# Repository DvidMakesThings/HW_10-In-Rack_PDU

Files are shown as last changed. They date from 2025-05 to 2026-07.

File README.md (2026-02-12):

# ENERGIS - The Managed PDU Project for 10-Inch Rack

## Overview


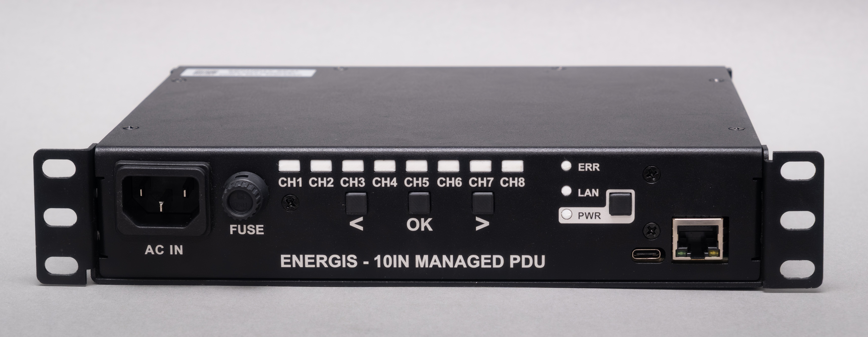
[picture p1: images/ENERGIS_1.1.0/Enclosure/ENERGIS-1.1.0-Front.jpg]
PDU 3D View


The **10-Inch Rack PDU (Power Distribution Unit)** is a modular power management system designed for efficient control and monitoring of power in a
rack-mounted environment. The project includes a Main Board and a display board to handle switching and power management.

Update 05.2025: Since lot of people said, it would be nice to have a Non-230V-Version, I started to develop
the USB-C version of ENERGIS with USB PD Source functionality: [PDNode-600 Pro](https://github.com/DvidMakesThings/HW_PDNode-600-Pro)

## ENERGIS Video Series

A new ENERGIS video series is rolling out. Part 1 is live below; Parts 2–4 will follow soon.

| Part | Title | Video |
| --- | --- | :---: |
| 1 | Overview | <a href="https://youtu.be/2Wui68LSHR0">Watch Part 1</a> |
| 2 | Hardware deep dive - The Schematics | <a href="https://youtu.be/pdoe9AGhswE">Watch Part 1</a> |
| 3 | Hardware deep dive - PCB design and Assembly | Coming soon |
| 4 | Embedded development - firmware and interfaces | Coming soon |
| 5 | Testing and validation | Coming soon |

## Progress and news

### Latest Features

| Feature | Description | Status | Note |
| --- | --- | --- | --- |
| Renamebable Channels | Channels are marked as 1–8; add label functionality |  | See: [Control page](#control-page) |
| Preset features | ENERGIS now offers 5 programmable presets to apply on output |  | See: [Settings page](#settings-page) |
| Apply-On-Startup feature  | A saved preset can be set to be auto-applied on device startup |  | See: [Settings page](#settings-page) |
| Offset Calibration | Implement off-state auto-zero for 0.75–0.77V and 0.02–0.05A offsets |  | - |
| Safety features | Software based current limit and restricion policy implemented |  | - |
| Sheet metal enclosure | Manufacturing and assembly ready. No future revision for enclosure |  | - |

### Currently working on

| Improvement | Description | Status |
| --- | --- | --- |
| Production optimization | Finalize assembly workflow and cost reduction |  |
| Extended testing | Expand automated test coverage (I²C, SPI, long-term soak tests) |  |
| Community feedback | Incorporate suggestions and adapt design for wider use cases |  |
| And even more debugging | It survived the 24h test, but you can never test enough |  |

### Development Phases (Hardware + Firmware)

| Hardware Phase | Status | Firmware Phase | Status |
| --- | --- | --- | --- |
| PCB Design for Rev1.0 | ✅ Completed | CONFIG file for HW description | ✅ Completed |
| Enclosure Design | ✅ Completed | ILI4988 TFT LCD Driver | ✅ Completed |
| Order PCB | ✅ Completed | MCP23017 Display-Board Driver | ✅ Completed |
| Prototyping and Hardware Testing | ✅ Completed | MCP23017 Relay-Board Driver | ✅ Completed |
| Implementing Rev2.0 | ✅ Completed | W5500 Ethernet Driver | ✅ Completed |
| Implementing Relay Board Rev2.1 | ✅ Completed | CAT24C512 512K EEPROM Driver | ✅ Completed |
| Initial Firmware Development | ✅ Completed | Version Control and EEPROM Data | ✅ Completed |
| Final PCB Revision | ✅ Completed | Display Functions | ✅ Completed |
| Enclosure Testing & Ventilation | ✅ Completed | System Startup Script | ✅ Completed |
| Power Monitoring | ✅ Completed | Multicore processing and RTOS | ✅ Completed |
| Production Optimization | 🔵 Planned | Pushbutton control | ✅ Completed |
| - | - | HLW8032 Power Monitor Dirver | ✅ Completed |
| - | - | Make Everything work together | ✅ Completed |
| - | - | HTML Server Implementation | ✅ Completed |
| - | - | Software debugging | ✅ Completed |
| - | - | Ethernet based firmware update | ❌ Not Possible |

---

## Specifications (EU, IEC/ENEC)

### Electrical Characteristics

* **Input:** 230 V AC, **10 A max**
* **Output Voltage:** 230 V AC
* **Total Output Current (all channels combined):** **10 A max**
* **Per-Channel Output Current:** **10 A max per active channel**, with **total combined output limited to 10 A**
* **Internal Power Supply:** 12 V, 1.5 A SMPS
* **Derived Internal Voltages:** 5 V and 3.3 V regulated from 12 V

### Relay Output Ratings

* **Common AC Trace Handling:** 16A max
* **Per-Relay Trace Rating:** 16A max
* **Relay Contact Rating:** 16A max

### Control and Driving Circuit

* **Relay Driver:** ULN2803 Darlington Array
* **Driving Current:** 33 mA per relay

## Specifications (US/Canada, UL/CSA)

### Electrical Characteristics

* **Input:** 250 V AC, **15 A max**
* **Output Voltage:** 250 V AC
* **Total Output Current (all channels combined):** **15 A max**
* **Per-Channel Output Current:** **15 A max per active channel**, with **total combined output limited to 15 A**
* **Internal Power Supply:** 12 V, 1.5 A SMPS
* **Derived Internal Voltages:** 5 V and 3.3 V regulated from 12 V

### Relay Output Ratings

* **Common AC Trace Handling:** 16 A max
* **Per-Relay Trace Rating:** 16 A max
* **Relay Contact Rating:** 16 A max

### Control and Driving Circuit

* **Relay Driver:** ULN2803 Darlington Array
* **Driving Current:** 33 mA per relay

---

## Features

- **Main Board:** Handles Ethernet communication, power conversion, and system logic. Manages AC switching with 8x 230V relays and safety
  isolation.
- **Display Board:** Headless mode, possible manual control with push buttons and real-time LED feedback
- **Ethernet Connectivity:** Uses the W5500 SPI-based Ethernet chip for remote
  control and monitoring via SNMPv1 and/or Web-UI
- **Power Measurement:** AC voltage and current sensing for monitoring.
- **Sheetmetal Enclosure:** Designed for 10-inch rack mounting with front and rear access.

--- 

## Schematics

The full schematics for each board are available:

- **[Main Board Schematics](src/PDF/ENERGIS-1.1.0_mainBoard_schematics.pdf)**
- **[Display Board Schematics](src/PDF/ENERGIS-1.1.0_displayBoard_schematics.pdf)**

---

## Hardware Stackup

<table>
  <tr>
    <td align="center">
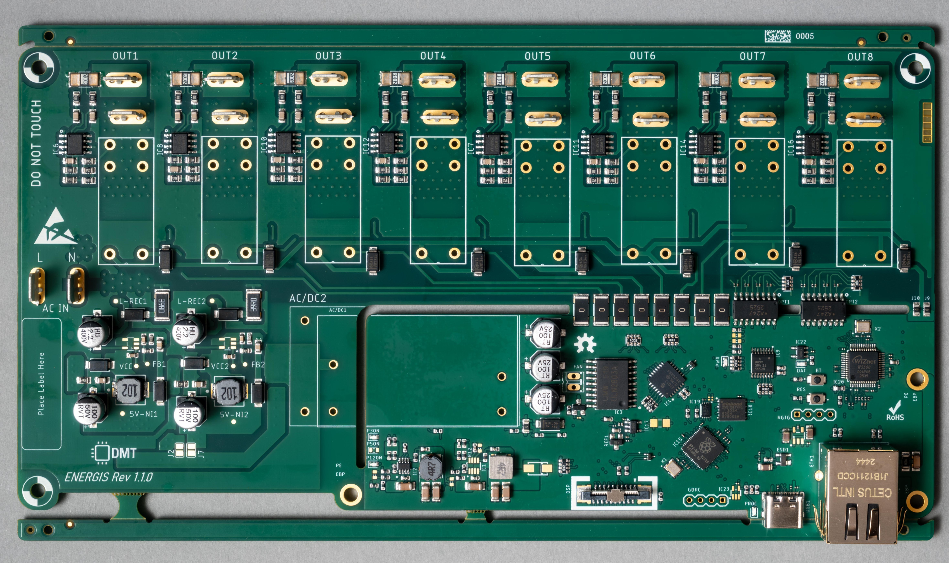
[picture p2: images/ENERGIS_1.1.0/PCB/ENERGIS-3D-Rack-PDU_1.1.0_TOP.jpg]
Main Board 3D Top View
      
      <br><b>Main Board Top</b>
    </td>
    <td align="center">
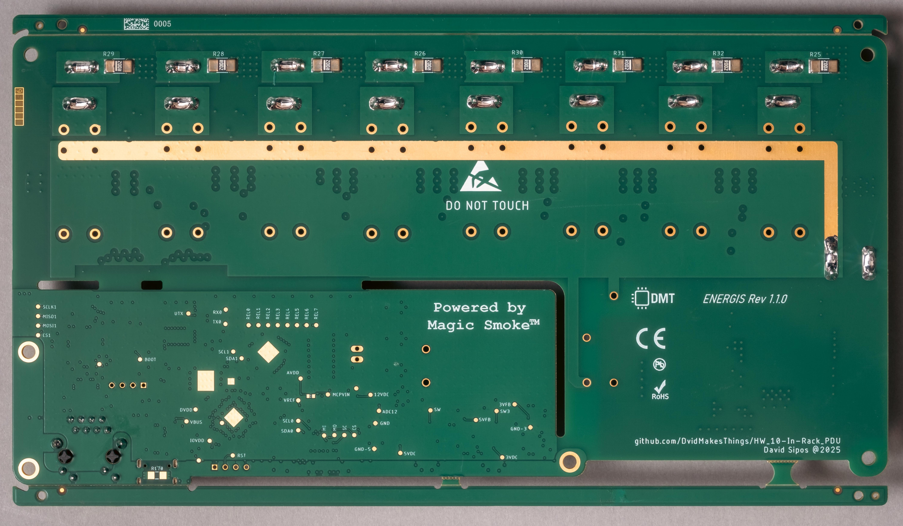
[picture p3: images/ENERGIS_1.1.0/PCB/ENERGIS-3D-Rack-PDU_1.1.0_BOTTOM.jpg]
Main Board 3D Bottom View
      
      <br><b>Main Board Bottom</b>
    </td>
  </tr>
  <tr>
    <td align="center">
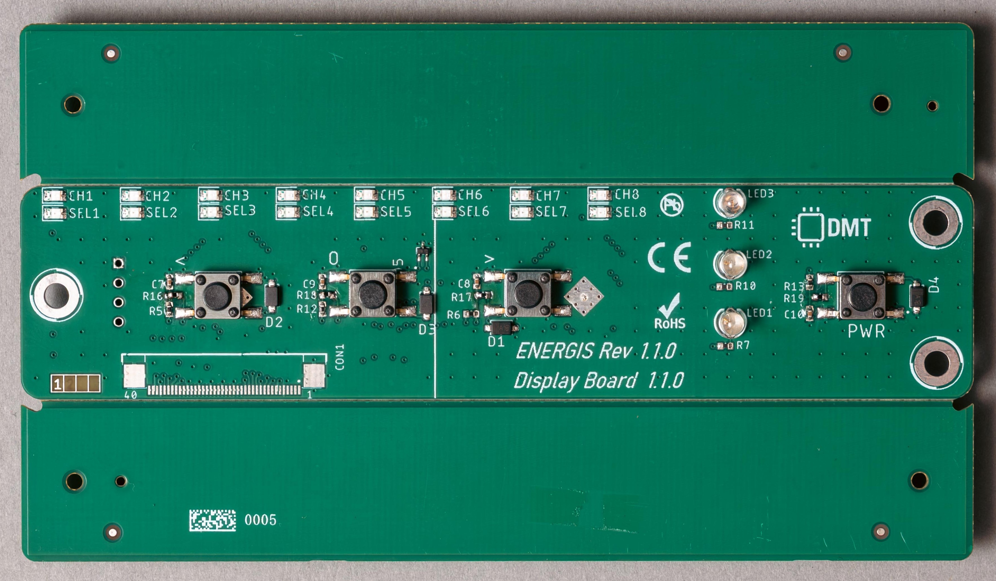
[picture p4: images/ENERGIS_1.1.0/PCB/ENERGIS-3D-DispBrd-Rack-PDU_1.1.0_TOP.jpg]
Display Board 3D Top View
      
      <br><b>Display Board Top</b>
    </td>
    <td align="center">
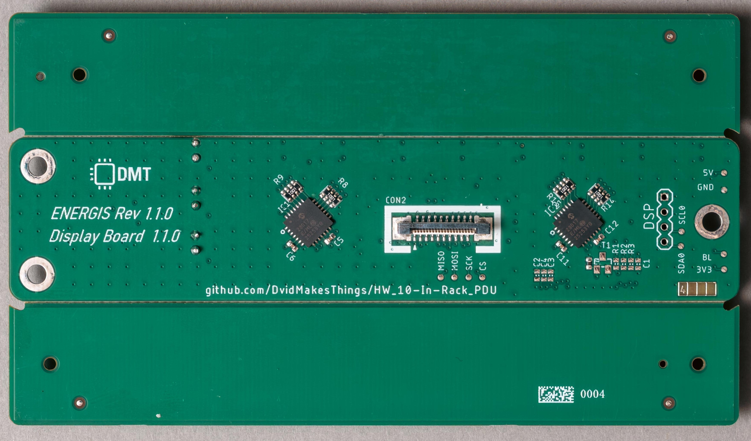
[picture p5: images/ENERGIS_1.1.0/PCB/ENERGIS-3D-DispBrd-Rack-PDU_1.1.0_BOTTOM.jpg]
Display Board 3D Bottom View
      
      <br><b>Display Board Bottom</b>
    </td>
  </tr>
  <tr>
    <td align="center">
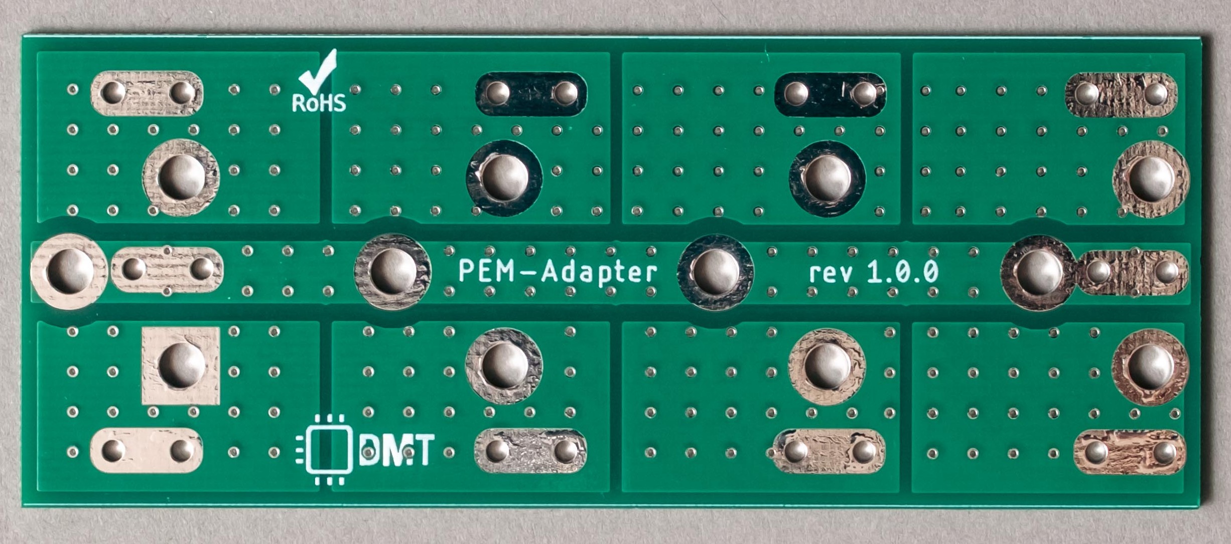
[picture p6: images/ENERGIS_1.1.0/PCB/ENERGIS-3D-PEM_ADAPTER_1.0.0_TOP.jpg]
PEM-Adapter 3D Top View
      
      <br><b>PEM Adapter</b>
    </td>
    <td align="center">
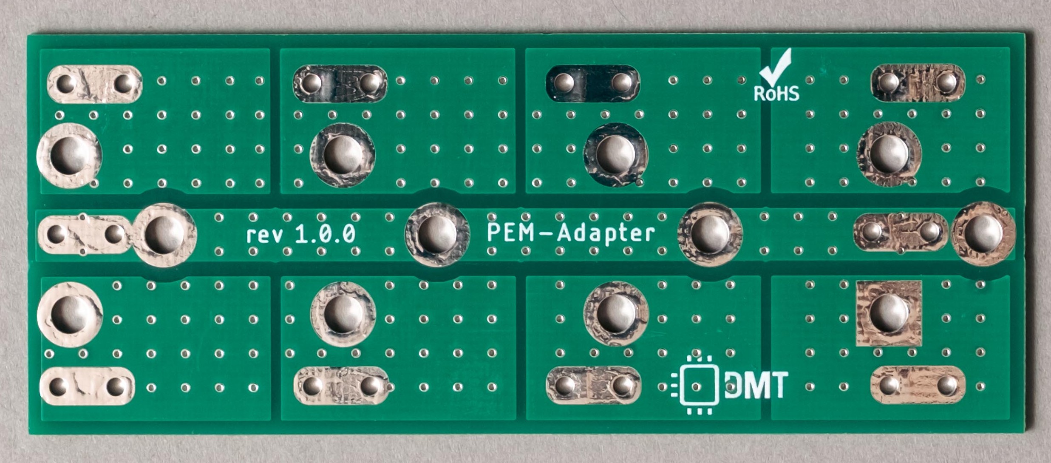
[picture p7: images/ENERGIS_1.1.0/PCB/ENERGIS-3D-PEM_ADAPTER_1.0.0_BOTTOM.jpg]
PEM-Adapter 3D Bottom View
      
      <br><b>PEM Adapter</b>
    </td>
  </tr>
</table>

## Enclosure

The **Energis** PDU enclosure is built from **Aluminum 5052 sheet metal** with a thickness of **1.5 mm**, ensuring both durability and lightweight construction. It follows a **10-inch rack form factor (1U height)** with custom mounting brackets and integrated cutouts for AC input, Ethernet, USB-C, status LEDs, and IEC outlets.

Key specifications:
* **Material:** Aluminum 5052, 1.5 mm
* **Finish:** Powder coat (matte black, process black)
* **Threads & tapped holes:** Yes (no inserts, no welding)
* **Marking:** Laser engraved front and back panel labeling
* **Design:** Precision CNC cut and bent sheet metal, matte black powder-coated for protection and aesthetics

<br></br>
<div style="display: flex; gap: 24px; justify-content: center; align-items: flex-start; margin-bottom: 24px;">
  PDU 3D View 1
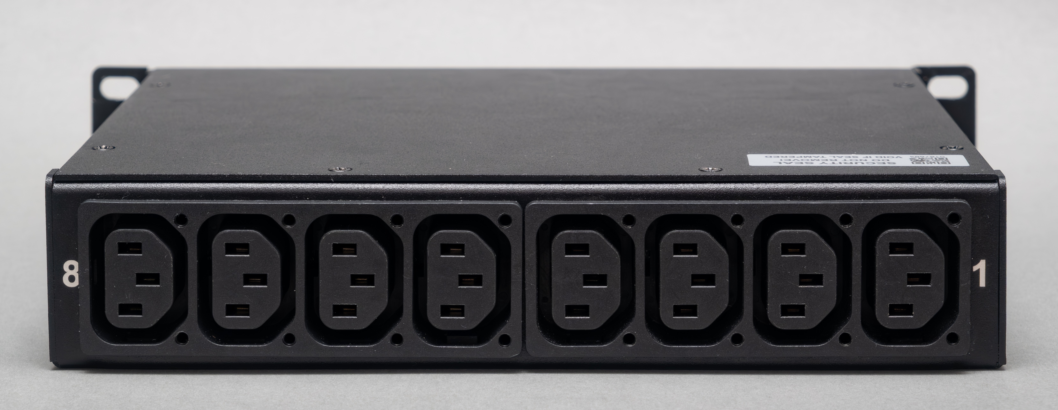
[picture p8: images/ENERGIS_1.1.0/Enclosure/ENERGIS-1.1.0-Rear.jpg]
PDU 3D View 2
  
</div>

<br></br>
Mounting options:
* **Desktop use** without brackets  
* **10-inch rack mounting** 

---

## Web UI

The ENERGIS now includes a lightweight embedded Web-UI for configuration and control.

## Control page
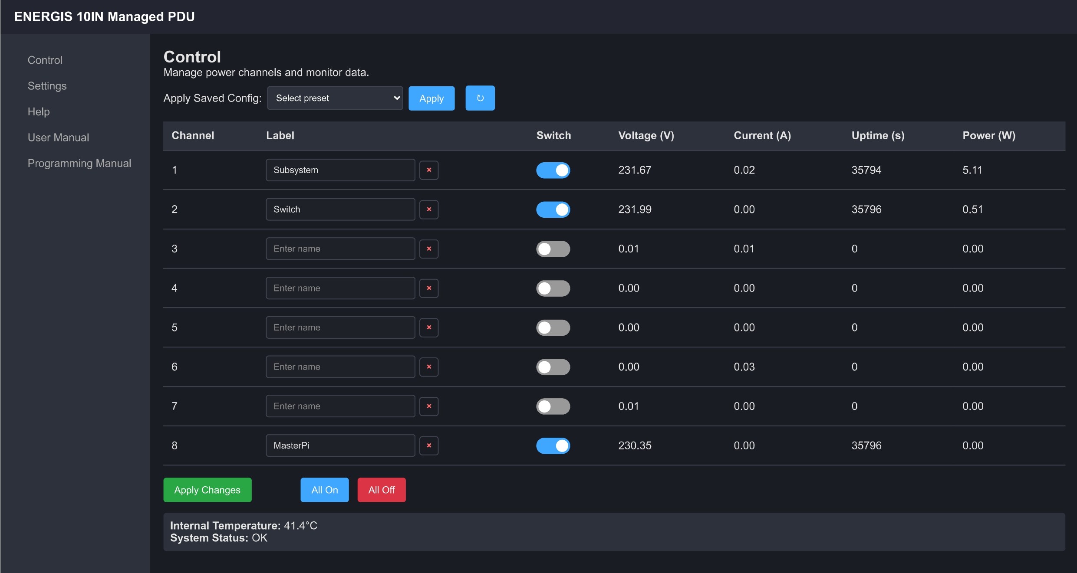
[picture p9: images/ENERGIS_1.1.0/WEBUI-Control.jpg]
Web-UI


## Settings page
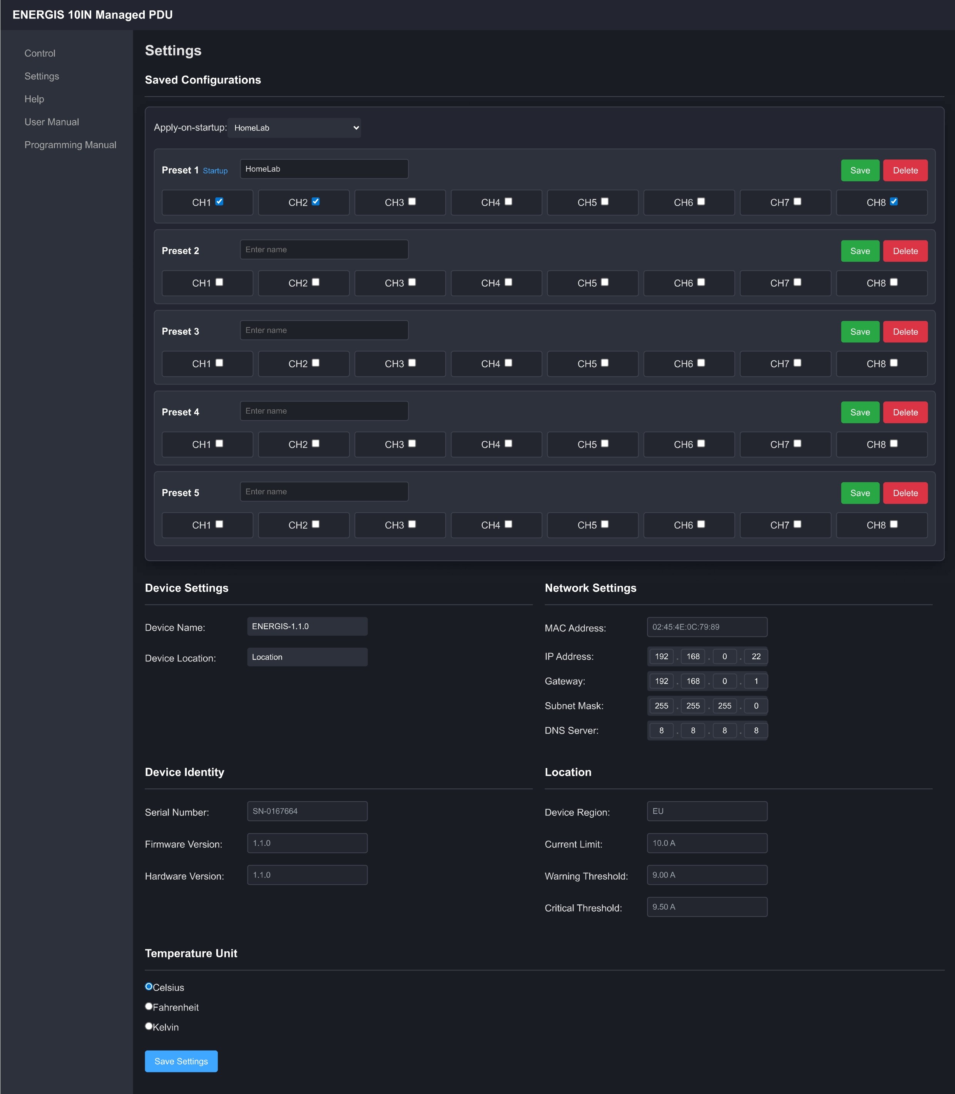
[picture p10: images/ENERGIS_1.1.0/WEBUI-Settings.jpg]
Web-UI Settings


---

## Tests

Automated hardware and firmware validation is now integrated into **ENERGIS**.  
Test reports are published through **GitHub Pages** for transparent, reproducible verification.

All tests are executed using my **Universal Test Framework (UTFW)**, a custom Python-based automation framework, developed for hardware and firmware validation.  
UTFW provides deterministic test sequencing, automated setup and teardown, structured logging, analysis, and unified HTML/XML reporting.  
The nightly regression runs every individual test together to verify overall system stability and catch integration issues early.

---

### Nightly Regression Suite
Comprehensive end-to-end system test covering:
- UART communication  
- SNMP protocol  
- Web interface (PCAP)  
- EEPROM persistence  
- Power monitoring (HLW8032)  
- ADC/thermal sanity checks  
- Relay stress switching  

**[Latest Regression Report](https://dvidmakesthings.github.io/HW_10-In-Rack_PDU/Tests/Nightly_regression/test_suite_Nightly_Tests_20251005_232014.html)**

---

### Individual Test Reports
- [Serial Communication Test Report (HTML)](https://dvidmakesthings.github.io/HW_10-In-Rack_PDU/Tests/report_tc_serial_utfw/tc_serial_utfw_report.html)
- [Network SNMP Test Report (HTML)](https://dvidmakesthings.github.io/HW_10-In-Rack_PDU/Tests/report_tc_network_snmp/tc_network_snmp_report.html)
- [Network PCAP Analysis Report (HTML)](https://dvidmakesthings.github.io/HW_10-In-Rack_PDU/Tests/report_tc_network_pcap/tc_network_pcap_report.html)
- [PCAP Capture Test Report (HTML)](https://dvidmakesthings.github.io/HW_10-In-Rack_PDU/Tests/report_tc_pcap_capture/tc_pcap_capture_report.html)
- [Power Monitoring Test Report (HLW8032) (HTML)](https://dvidmakesthings.github.io/HW_10-In-Rack_PDU/Tests/report_tc_power_hlw8032/tc_power_hlw8032_report.html)
- [EEPROM Persistence Test Report (HTML)](https://dvidmakesthings.github.io/HW_10-In-Rack_PDU/Tests/report_tc_eeprom_persistence/tc_eeprom_persistence_report.html)
- [Sanity Check Test Report (HTML)](https://dvidmakesthings.github.io/HW_10-In-Rack_PDU/Tests/report_tc_sanity_check/tc_sanity_check_report.html)
- [Relay Stress Switching Test Report (HTML)](https://dvidmakesthings.github.io/HW_10-In-Rack_PDU/Tests/report_tc_stress_switching/tc_stress_switching_report.html)

---

### Changelog:
#### Rev0.1.0:
- Initial desing

#### Rev0.2.0:
- Correct all hardware related bugs
- Display-Board Rev0.2.0: 
    - Buttons too close to each-other. Manual control is uncomfortable 
    - MCP23S17 seems like unreachable, invertory shortage everywhere. Change to MCP23017
- Controller-Board Rev0.2.0: 
    - W5500 crystal wiring bug. 
    - v1.0 connectors replaced to smaller FFC ones
- Relay-Board Rev0.2.0: 
    - Add HLW8032 for power monitoring
    - Replace Flyback converter to a cheaper - ready made AC-DC converter unit

#### Rev0.2.1:
- Relay-Board Rev0.2.1: 
    - Capacitive dropper does not have enough power to supply 8xHLW8032 - Non-Isolated  buck converter implemented
- Display-Board Rev0.2.1:
    - Planned revision without the LCD. This is the main size issue, going to do a version where the setup fits in 1U size. 
    Currently for debug purposes 1.5U is perfectly fine

#### ENERGIS 1.0.0 
- Relay-Board and Controller Board is now combined: Main Board
- Added enable functionality to the PSU
- Added high precision LDO to supply the MCU
- Additional fan is possible, but the temperature doesn't go above 36°C

#### ENERGIS 1.1.0
- Cleaned up routing both for Display- and Main board
- NEW: PEM-Adapter: Unfortunately the commercially available Power Entry Modules are using bussed topology, seems like it's
impossible to buy snap-in modules with individual L/N control. The only possibility I've found is the 3-104-370 from Schurter, but
it's a PCB-mountable version. Using a small adapter board to hook the solder joints to faston connectors seems to be the only possibility

## License
### Software Components
This project's software is licensed under the **GNU Affero General Public License v3.0 (AGPL-3.0)**.
See the [Software License](LICENSE-AGPL) file for details.

#### What AGPL-3.0 means:

- ✅ **You can** freely use, modify, and distribute this software
- ✅ **You can** use this project for personal, educational, or internal purposes
- ✅ **You can** contribute improvements back to this project

- ⚠️ **You must** share any modifications you make if you distribute the software
- ⚠️ **You must** release the source code if you run a modified version on a server that others interact with
- ⚠️ **You must** keep all copyright notices intact

- ❌ **You cannot** incorporate this code into proprietary software without sharing your source code
- ❌ **You cannot** use this project in a commercial product without either complying with AGPL or obtaining a different license

### Hardware Components
Hardware designs, schematics, and related documentation are licensed under the **Creative Commons Attribution-NonCommercial-ShareAlike 4.0 International License (CC BY-NC-SA 4.0)**. See the [Hardware License](LICENSE-CC-BY-NC-SA) file for details.

#### What CC BY-NC-SA 4.0 means:

- ✅ **You can** study, modify, and distribute the hardware designs
- ✅ **You can** create derivative works for personal, educational, or non-commercial use
- ✅ **You can** build this project for your own personal use

- ⚠️ **You must** give appropriate credit and indicate if changes were made
- ⚠️ **You must** share any modifications under the same license terms
- ⚠️ **You must** include the original license and copyright notices

- ❌ **You cannot** use the designs for commercial purposes without explicit permission
- ❌ **You cannot** manufacture and sell products based on these designs without a commercial license
- ❌ **You cannot** create closed-source derivatives for commercial purposes
- ❌ **You cannot** use the designer's trademarks without permission

### Commercial & Enterprise Use

Commercial use of this project is prohibited without obtaining a separate commercial license. If you are interested in:

- Manufacturing and selling products based on these designs
- Incorporating these designs into commercial products
- Any other commercial applications

Please contact me through any of the channels listed in the [Contact](#contact) section to discuss commercial licensing arrangements. Commercial licenses are available with reasonable terms to support ongoing development.

## Contact

For questions or feedback:
- **Email:** [dvidmakesthings@gmail.com](mailto:dvidmakesthings@gmail.com)
- **GitHub:** [DvidMakesThings](https://github.com/DvidMakesThings)

## Contributing

Contributions are welcome! As this is an early-stage project, please reach out before 
making substantial changes:

1. Fork the repository
2. Create a feature branch (`git checkout -b feature/concept`)
3. Commit your changes (`git commit -m 'Add concept'`)
4. Push to the branch (`git push origin feature/concept`)
5. Open a Pull Request with a detailed description

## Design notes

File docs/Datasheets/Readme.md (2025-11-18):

# ENERGIS - The Managed PDU Project for 10-Inch Rack - Datasheets

## Contents
This folder contains datasheets for components used in the **ENERGIS PDU** project.
Each subfolder is named after the corresponding board (Controller, Display, Relay) to maintain organization.
Datasheets are useful for verifying component specifications and understanding performance parameters.

## License
This project is licensed under the GPL-3.0 License. See the [LICENSE](LICENSE) file for details.

## Contact
For questions or feedback:
- Email: [dvidmakesthings@gmail.com](mailto:dvidmakesthings@gmail.com)
- GitHub: [DvidMakesThings](https://github.com/DvidMakesThings)

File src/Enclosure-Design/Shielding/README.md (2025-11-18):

# Shielding Design – ENERGIS

This folder contains the **mechanical shielding parts** for the ENERGIS system.  
The shields are designed in Fusion 360 (sheet-metal workflow) and exported as **DXF flat patterns** for cutting from 0.5 mm brass sheet.  

Brass was chosen over aluminum because it can be **soldered directly to PCB GND pads**, ensuring reliable low-impedance bonding.

---

## Purpose

During early testing, two main issues appeared:

1. **EMI coupling** from the 230 V relay/AC section into the digital side.  
   - Without shielding, the FPC cable and control logic were acting as antennas.  
   - Noise could be observed on I2C and button reads.

2. **ESD vulnerability** on the display board.  
   - Button presses and connector touches occasionally caused resets.  

To mitigate these issues, I've implemented **mechanical brass shields** tied to PCB GND at multiple points.
Brass is easy to solder and bending a 0.5mm thick sheet doesn't require that much force

---

## Main Board Shield

- Covers the entire digital interface, leaving only the connectors exposed
- L-shaped fence along the isolation slot between HV and digital domains.  
- Tabs solder into test pads + screw hole for both mechanical strength and ground bonding.  
- The FPC cable runs **under the shield**; only a few cm exposed.  

Main Board Shield

DXF: [MainBoard_Shielding.dxf](MainBoard_Shielding.dxf)  
PDF: [MainBoard_Shielding.pdf](MainBoard_Shielding.pdf)

---

## Display Board Shield

- Full brass cap covering the back side of the display board.  
- Exposed only where connectors and buttons are located.  

Front view:  
Display Board Shield – Front

Back view:  
Display Board Shield

DXF: [DisplayBoard_Shielding.dxf](DisplayBoard_Shielding.dxf)  
PDF: [DisplayBoard_Shielding.pdf](DisplayBoard_Shielding.pdf)

---

## Notes

- Shields are designed for **0.5 mm brass**.  
- After cutting, edges must be deburred and tabs cleaned before soldering.  
- Painting is optional for corrosion resistance — but **mask the solder tabs** to keep them conductive.  

---

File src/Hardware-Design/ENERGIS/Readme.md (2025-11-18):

# HLW8032 Upper-Bank Routing Issue — Fixed in HW 1.0.1

## Summary
On **hardware rev 1.0.0**, the measurement path for channels **5–8** is cross-routed at the optocouplers, mirroring the upper nibble. Relays/buttons are unaffected; only measurement presentation would be wrong without compensation.

## Symptom (on HW 1.0.0)
- Turning **CH5–CH8** on shows their voltage/current under the wrong rows in the UI.

| Logical Channel | Routed To (HW 1.0.0) |
|---:|:---|
| 5 | 8 |
| 6 | 7 |
| 7 | 6 |
| 8 | 5 |

## Root Cause
- PCB routing in the optocoupler stage crosses TX lines for channels 5–8.

## Software Handling
- The firmware checks board revision **at compile time** (`SW_REV == 100`) and applies a **MUX-select compensation** only for HW 1.0.0 (invert A/B when the C bit is set).
- Cache indices and UI mapping remain **identity**.
- **Result:** No user-visible issue on any build.

## Hardware Status
- **HW 1.0.1:** Routing corrected (1:1). The firmware automatically **disables** compensation on ≥1.0.1.
- **HW 1.0.0:** Fully functional due to firmware compensation.

## Verification
1. Switch on CH5…CH8 individually.  
2. Confirm the UI shows the correct channel voltage/current on both HW 1.0.0 (with compensation) and HW 1.0.1 (native).

---
**Status:** Fixed in hardware (rev 1.0.1). Software safeguard ensures no impact on users.

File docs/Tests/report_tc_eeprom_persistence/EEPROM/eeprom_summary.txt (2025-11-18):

EEPROM Parse Summary – Analyze EEPROM dump after all tests
Source lines parsed: 4096
Address span: 0x0000 – 0xFFFF (65536 bytes)
Dump (raw)   : eeprom_dump_raw.log
Dump (ascii) : eeprom_dump_ascii.log
Checks file  : eeprom_checks.json

-- Findings --
[OK] Device Serial @ 0x0000 len=15
    ASCII: SN-369366060325
[OK] FW Version @ 0x0010 len=5
    ASCII: 1.0.0
[OK] Relay Defaults (8x bytes) @ 0x0200 len=8
    HEX  : 00 00 00 00 00 00 00 00
[OK] Network Info (first 4 bytes) @ 0x0300 len=4
    HEX  : C0 A8 00 0B
[OK] Device Name @ 0x2000 len=13
    ASCII: ENERGIS-1.0.0
[OK] Device Location @ 0x2020 len=8
    ASCII: Location
[OK] Magic A55A Present @ 0xFFF0 len=16
    HEX  : FF FF FF FF FF FF FF FF FF FF FF FF FF FF 5A A5

-- Extracted --
Serial  : SN-369366060325
Firmware: 1.0.0
Name    : ENERGIS-1.0.0
Location: Location

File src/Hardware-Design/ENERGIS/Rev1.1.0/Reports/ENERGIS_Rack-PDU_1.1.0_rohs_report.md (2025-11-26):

# ROHS Compliance Certificate

## Evaluated design

**Design File**: `ENERGIS_Rack-PDU_1.1.0.brd`

**Evaluation Date**: 2025-11-26 8:04 PM

**Total Components (placed)**: 455

**Evaluated (excluding Not mounted)**: 370

**Compliant Components**: 370

---

## Evaluation Criteria

<p align="justify">
Each populated component is checked for the <code>ROHS</code> attribute. Accepted value is <code>YES</code>. Any component with a missing <code>ROHS</code> attribute or a value other than <code>YES</code> is considered non-compliant for this report. Components marked as <code>DNI</code> are excluded and listed as Not mounted.
</p>

---

## Final Statement

Based on the attributes present in the EAGLE board file at the time of export, this design is considered:

<div align="center"><h1>RoHS COMPLIANT</h1></div>

This certificate reflects only metadata embedded in the project and does not replace manufacturer documentation.
| Ref | MPN | Manufacturer | ROHS Compliant | Result |
|-----|-----|---|---|---|
| 3V3A | - | - | - | Not mounted |
| 3VDC | - | - | - | Not mounted |
| 3VFB | - | - | - | Not mounted |
| 5V-NI1 | - | - | - | Not mounted |
| 5V-NI2 | - | - | - | Not mounted |
| 5VDC | - | - | - | Not mounted |
| 5VFB | - | - | - | Not mounted |
| 12VDC | - | - | - | Not mounted |
| AC/DC1 | IRM-10-12  | MW | YES | PASS |
| AC/DC2 | - | - | YES | PASS |
| AC_L | 1217861-1 | TE CONNECTIVITY | YES | PASS |
| AC_N | 1217861-1 | TE CONNECTIVITY | YES | PASS |
| ADC12 | - | - | - | Not mounted |
| ADCUSB | - | - | - | Not mounted |
| ADC_TEMP | - | - | - | Not mounted |
| AVDD | - | - | - | Not mounted |
| BOOT | - | - | - | Not mounted |
| BT | B3U-1000P | Omron | YES | PASS |
| C1 | 1206X226K250NT | FH | YES | PASS |
| C2 | 1206X226K250NT | FH | YES | PASS |
| C3 | 0402X104K250CT | Walsin | YES | PASS |
| C4 | 0402X104K250CT | Walsin | YES | PASS |
| C5 | CEU3E2X7R2A102KT0Y0S | TDK | YES | PASS |
| C6 | 0402X104K250CT | Walsin | YES | PASS |
| C7 | 0402X104K250CT | Walsin | YES | PASS |
| C8 | 0402X104K250CT | Walsin | YES | PASS |
| C9 | 0402X104K250CT | Walsin | YES | PASS |
| C10 | RVT1E101M0607 | HONOR | YES | PASS |
| C11 | FN15N330J500PNG | PSA | YES | PASS |
| C12 | FN15N330J500PNG | PSA | YES | PASS |
| C13 | RVT1E101M0607 | HONOR | YES | PASS |
| C14 | 1206X226K250NT | FH | YES | PASS |
| C15 | 1206X226K250NT | FH | YES | PASS |
| C16 | RVT1E101M0607 | HONOR | YES | PASS |
| C17 | 1206X226K250NT | FH | YES | PASS |
| C18 | 1206X226K250NT | FH | YES | PASS |
| C19 | 0402X104K250CT | Walsin | YES | PASS |
| C20 | 0402X104K250CT | Walsin | YES | PASS |
| C21 | 0603X225K160NT | FH | YES | PASS |
| C22 | 0805B224K500NT | FH | YES | PASS |
| C23 | RVT1H101M0607 | ROQANG | YES | PASS |
| C24 | 0805B333K500NT | FH | YES | PASS |
| C25 | 0805B333K500NT | FH | YES | PASS |
| C26 | 0805B333K500NT | FH | YES | PASS |
| C27 | 0805B333K500NT | FH | YES | PASS |
| C28 | 0805B333K500NT | FH | YES | PASS |
| C29 | 0805B333K500NT | FH | YES | PASS |
| C30 | 0805B333K500NT | FH | YES | PASS |
| C31 | 0805B333K500NT | FH | YES | PASS |
| C32 | 0805B333K500NT | FH | YES | PASS |
| C33 | 0402X104K250CT | Walsin | YES | PASS |
| C34 | 0402X104K250CT | Walsin | YES | PASS |
| C35 | - | - | YES | PASS |
| C36 | 0805B333K500NT | FH | YES | PASS |
| C37 | 0805B333K500NT | FH | YES | PASS |
| C38 | 0805B333K500NT | FH | YES | PASS |
| C39 | 0805B333K500NT | FH | YES | PASS |
| C40 | 0805B333K500NT | FH | YES | PASS |
| C41 | 0805B333K500NT | FH | YES | PASS |
| C42 | 0805B333K500NT | FH | YES | PASS |
| C43 | 0805B333K500NT | FH | YES | PASS |
| C44 | 0805B333K500NT | FH | YES | PASS |
| C45 | C2012X7R1H105KT000N | TDK | YES | PASS |
| C46 | 0603X225K160NT | FH | YES | PASS |
| C47 | - | - | YES | PASS |
| C48 | 0805B333K500NT | FH | YES | PASS |
| C49 | 0805B333K500NT | FH | YES | PASS |
| C50 | 0805B333K500NT | FH | YES | PASS |
| C51 | CEU3E2X7R2A102KT0Y0S | TDK | YES | PASS |
| C52 | 0805B224K500NT | FH | YES | PASS |
| C53 | RVT1H101M0607 | ROQANG | YES | PASS |
| C54 | 0805B333K500NT | FH | YES | PASS |
| C55 | 0805B333K500NT | FH | YES | PASS |
| C56 | 0805B333K500NT | FH | YES | PASS |
| C57 | C2012X7R1H105KT000N | TDK | YES | PASS |
| C58 | CC0201JRNPO9BN150 | Yageo | YES | PASS |
| C59 | CC0201JRNPO9BN150 | Yageo | YES | PASS |
| C60 | C1005X5R1E105KT000E | TDK | YES | PASS |
| C61 | CL03A104MP3NNNC | Samsung | YES | PASS |
| C62 | CL03A104MP3NNNC | Samsung | YES | PASS |
| C63 | CL03A104MP3NNNC | Samsung | YES | PASS |
| C64 | CL03A104MP3NNNC | Samsung | YES | PASS |
| C65 | - | - | YES | PASS |
| C66 | 0402X104K250CT | Walsin | YES | PASS |
| C67 | CL03A104MP3NNNC | Samsung | YES | PASS |
| C68 | CL03A104MP3NNNC | Samsung | YES | PASS |
| C69 | CL03A104MP3NNNC | Samsung | YES | PASS |
| C70 | CL03A104MP3NNNC | Samsung | YES | PASS |
| C71 | CL03A104MP3NNNC | Samsung | YES | PASS |
| C72 | CL03A104MP3NNNC | Samsung | YES | PASS |
| C73 | CL03A104MP3NNNC | Samsung | YES | PASS |
| C74 | CL03A104MP3NNNC | Samsung | YES | PASS |
| C75 | CL03A104MP3NNNC | Samsung | YES | PASS |
| C76 | CL03A104MP3NNNC | Samsung | YES | PASS |
| C77 | CL03A104MP3NNNC | Samsung | YES | PASS |
| C78 | 0402B472K500CT | Walsin | YES | PASS |
| C79 | 0402X104K250CT | Walsin | YES | PASS |
| C80 | CL05B223KB5NNNC | Samsung | YES | PASS |
| C81 | 0201B682K500NT | FH | YES | PASS |
| C82 | 0201B682K500NT | FH | YES | PASS |
| C83 | C1206C102KGRACTU | KEMET | YES | PASS |
| C84 | CL03A104MP3NNNC | Samsung | YES | PASS |
| C85 | GRM155R61E475ME15D | Murata | YES | PASS |
| C86 | CC0201GRNPO9BN180  | Yageo | YES | PASS |
| C87 | CC0201GRNPO9BN180  | Yageo | YES | PASS |
| C88 | CL03A104MP3NNNC | Samsung | YES | PASS |
| C89 | CL03A104MP3NNNC | Samsung | YES | PASS |
| C90 | CL03A104MP3NNNC | Samsung | YES | PASS |
| C91 | CL03A104MP3NNNC | Samsung | YES | PASS |
| C92 | CL03A104MP3NNNC | Samsung | YES | PASS |
| C93 | CL03A104MP3NNNC | Samsung | YES | PASS |
| C94 | CL03A104MP3NNNC | Samsung | YES | PASS |
| C95 | CL03A104MP3NNNC | Samsung | YES | PASS |
| C96 | CL03A104MP3NNNC | Samsung | YES | PASS |
| C97 | - | - | YES | PASS |
| C98 | CL03A104MP3NNNC | Samsung | YES | PASS |
| C99 | - | - | YES | PASS |
| C100 | CL03A104MP3NNNC | Samsung | YES | PASS |
| C101 | CL03A104MP3NNNC | Samsung | YES | PASS |
| C102 | 0402X105K160CT | WALSIN | YES | PASS |
| C103 | CL03A104MP3NNNC | Samsung | YES | PASS |
| C104 | C1005X5R1E105KT000E | TDK | YES | PASS |
| C105 | CL03A104MP3NNNC | Samsung | YES | PASS |
| C106 | CL03B102KA3NNNC | Samsung | YES | PASS |
| C107 | CL03B102KA3NNNC | Samsung | YES | PASS |
| C108 | CL03B102KA3NNNC | Samsung | YES | PASS |
| C109 | CL03B102KA3NNNC | Samsung | YES | PASS |
| C110 | CL03B102KA3NNNC | Samsung | YES | PASS |
| C111 | CL03B102KA3NNNC | Samsung | YES | PASS |
| C112 | CL03B102KA3NNNC | Samsung | YES | PASS |
| C113 | CL03B102KA3NNNC | Samsung | YES | PASS |
| CS | - | - | - | Not mounted |
| CS1 | - | - | - | Not mounted |
| D1 | MBRA340T3G | ON | YES | PASS |
| D2 | MBRA340T3G | ON | YES | PASS |
| D3 | MBRA340T3G | ON | YES | PASS |
| D4 | MBRA340T3G | ON | YES | PASS |
| D5 | MBRA340T3G | ON | YES | PASS |
| D6 | MBRA340T3G | ON | YES | PASS |
| D7 | MBRA340T3G | ON | YES | PASS |
| D8 | MBRA340T3G | ON | YES | PASS |
| D9 | 1N4007G | SK | YES | PASS |
| D10 | 1N4007G | SK | YES | PASS |
| D11 | US1J-E3/61T | Vishay | YES | PASS |
| D12 | 1N4007G | SK | YES | PASS |
| D13 | 1N4007G | SK | YES | PASS |
| D14 | US1J-E3/61T | Vishay | YES | PASS |
| D15 | SS12 | MDD | - | Not mounted |
| D16 | SMAJ15A | TWGMC | YES | PASS |
| D17 | RCLAMP0582BQTCT | SEMTECH | YES | PASS |
| D18 | RCLAMP0582BQTCT | SEMTECH | YES | PASS |
| DAT | FC-1608BK-465G5  | NATIONSTAR | YES | PASS |
| DNI | RC0402JR-130RL | YAGEO | YES | PASS |
| DSP | AFC11-S20ICA-00 | JS | YES | PASS |
| DVDD | - | - | - | Not mounted |
| ESD1 | SP0503BAHTG | Littelfuse | YES | PASS |
| ETH1 | J1B1211CCD | WIZnet | YES | PASS |
| FAN | - | - | - | Not mounted |
| FB1 | - | - | - | Not mounted |
| FB2 | - | - | - | Not mounted |
| FCTL | - | - | - | Not mounted |
| GDRC | - | - | - | Not mounted |
| GND | - | - | - | Not mounted |
| GND-3 | - | - | - | Not mounted |
| GND-5 | - | - | - | Not mounted |
| IC1 | MP2315GJ-Z | MPS | YES | PASS |
| IC2 | MP2315GJ-Z | MPS | YES | PASS |
| IC3 | ULN2803A | UMW | YES | PASS |
| IC4 | MCP23017-E/ML | MICROCHIP | YES | PASS |
| IC5 | MP150GJ-Z | MONOLITHIC POWER SYSTEMS  | YES | PASS |
| IC6 | HLW8032 | Hiliwei Tech | YES | PASS |
| IC7 | HLW8032 | Hiliwei Tech | YES | PASS |
| IC8 | HLW8032 | Hiliwei Tech | YES | PASS |
| IC9 | 74HC151PW-Q100,118  | Nexperia | YES | PASS |
| IC10 | HLW8032 | Hiliwei Tech | YES | PASS |
| IC11 | HLW8032 | Hiliwei Tech | YES | PASS |
| IC12 | HLW8032 | Hiliwei Tech | YES | PASS |
| IC13 | MP150GJ-Z | MONOLITHIC POWER SYSTEMS  | YES | PASS |
| IC14 | HLW8032 | Hiliwei Tech | YES | PASS |
| IC15 | RP2040 | Raspberry Pi  | YES | PASS |
| IC16 | HLW8032 | Hiliwei Tech | YES | PASS |
| IC17 | MCP6001RT-I/OT  | MICROCHIP | YES | PASS |
| IC18 | W25Q128JVPIQ | Winbond | YES | PASS |
| IC19 | CAT24C256HU4IGT3 | ON | YES | PASS |
| IC20 | W5500 | WIZNET | YES | PASS |
| IC21 | MIC5504-3.3YM5-TR  | Microchip | - | Not mounted |
| IC22 | MCP6001RT-I/OT  | MICROCHIP | YES | PASS |
| IC23 | - | Microchip  | - | Not mounted |
| IOVDD | - | - | - | Not mounted |
| J2 | - | - | - | Not mounted |
| J7 | - | - | - | Not mounted |
| J8 | CRCW08050000Z0EA | Vishay | YES | PASS |
| J9 | CRCW08050000Z0EA | Vishay | YES | PASS |
| J10 | CRCW08050000Z0EA | Vishay | YES | PASS |
| K1 | G2RL-1A-E DC12 | Omron | YES | PASS |
| K2 | G2RL-1A-E DC12 | Omron | YES | PASS |
| K3 | G2RL-1A-E DC12 | Omron | YES | PASS |
| K4 | G2RL-1A-E DC12 | Omron | YES | PASS |
| K5 | G2RL-1A-E DC12 | Omron | YES | PASS |
| K6 | G2RL-1A-E DC12 | Omron | YES | PASS |
| K7 | G2RL-1A-E DC12 | Omron | YES | PASS |
| K8 | G2RL-1A-E DC12 | Omron | YES | PASS |
| L-REC1 | - | - | - | Not mounted |
| L-REC2 | - | - | - | Not mounted |
| L1 | YP0503-4R7M | YJYCOIN | - | Not mounted |
| L2 | YP0503-4R7M | YJYCOIN | YES | PASS |
| L3 | SMNR6045-102MT | SXN | YES | PASS |
| L4 | BLM18EG221TN1D | Murata | YES | PASS |
| L5 | SMNR6045-102MT | SXN | YES | PASS |
| L_OUT1 | 1217861-1 | TE CONNECTIVITY | YES | PASS |
| L_OUT2 | 1217861-1 | TE CONNECTIVITY | YES | PASS |
| L_OUT3 | 1217861-1 | TE CONNECTIVITY | YES | PASS |
| L_OUT4 | 1217861-1 | TE CONNECTIVITY | YES | PASS |
| L_OUT5 | 1217861-1 | TE CONNECTIVITY | YES | PASS |
| L_OUT6 | 1217861-1 | TE CONNECTIVITY | YES | PASS |
| L_OUT7 | 1217861-1 | TE CONNECTIVITY | YES | PASS |
| L_OUT8 | 1217861-1 | TE CONNECTIVITY | YES | PASS |
| MCPVIN | - | - | - | Not mounted |
| MI | - | - | - | Not mounted |
| MISO1 | - | - | - | Not mounted |
| MO | - | - | - | Not mounted |
| MOSI1 | - | - | - | Not mounted |
| N_OUT1 | 1217861-1 | TE CONNECTIVITY | YES | PASS |
| N_OUT2 | 1217861-1 | TE CONNECTIVITY | YES | PASS |
| N_OUT3 | 1217861-1 | TE CONNECTIVITY | YES | PASS |
| N_OUT4 | 1217861-1 | TE CONNECTIVITY | YES | PASS |
| N_OUT5 | 1217861-1 | TE CONNECTIVITY | YES | PASS |
| N_OUT6 | 1217861-1 | TE CONNECTIVITY | YES | PASS |
| N_OUT7 | 1217861-1 | TE CONNECTIVITY | YES | PASS |
| N_OUT8 | 1217861-1 | TE CONNECTIVITY | YES | PASS |
| OPT1 | ACPL-247-500E | Broadcom | YES | PASS |
| OPT2 | ACPL-247-500E | Broadcom | YES | PASS |
| P3ON | 150060GS75000 | Wurth | YES | PASS |
| P5ON | 150060GS75000 | Wurth | - | Not mounted |
| P12ON | 150060GS75000 | Wurth | YES | PASS |
| PROC | 150060GS75000 | Wurth | YES | PASS |
| PWR | 150060GS75000 | Wurth | YES | PASS |
| R1 | - | - | - | Not mounted |
| R2 | MCR01MZPF1002 | ROHM | YES | PASS |
| R3 | RC-02W1003FT | FH | YES | PASS |
| R4 | AC0402FR-079K09L | Yageo | YES | PASS |
| R5 | RC-02W1003FT | FH | YES | PASS |
| R6 | 0402WGF7501TCE | Uniohm | YES | PASS |
| R7 | 0402WGF100JTCE | Uniohm | YES | PASS |
| R8 | RC-02W2002FT | FH | YES | PASS |
| R9 | 0402WGF100JTCE | Uniohm | YES | PASS |
| R10 | RTT023302FTH | RALEC | YES | PASS |
| R11 | AC0402FR-0740K2L  | Yageo | YES | PASS |
| R12 | 0402WGF7501TCE | Uniohm | YES | PASS |
| R13 | AC0402FR-0740K2L  | Yageo | YES | PASS |
| R14 | AC0402FR-0712K7L | Yageo | YES | PASS |
| R15 | RC-01W27R0FT  | FH | YES | PASS |
| R16 | RC0201FR-071KL  | Yageo | YES | PASS |
| R17 | RK73ZW3ATTE | KOA | YES | PASS |
| R18 | RK73ZW3ATTE | KOA | YES | PASS |
| R19 | RK73ZW3ATTE | KOA | YES | PASS |
| R20 | RK73ZW3ATTE | KOA | YES | PASS |
| R21 | RK73ZW3ATTE | KOA | YES | PASS |
| R22 | RK73ZW3ATTE | KOA | YES | PASS |
| R23 | RK73ZW3ATTE | KOA | YES | PASS |
| R24 | RK73ZW3ATTE | KOA | YES | PASS |
| R25 | LR12FTDSR002 | Viking | YES | PASS |
| R26 | LR12FTDSR002 | Viking | YES | PASS |
| R27 | LR12FTDSR002 | Viking | YES | PASS |
| R28 | LR12FTDSR002 | Viking | YES | PASS |
| R29 | LR12FTDSR002 | Viking | YES | PASS |
| R30 | LR12FTDSR002 | Viking | YES | PASS |
| R31 | LR12FTDSR002 | Viking | YES | PASS |
| R32 | LR12FTDSR002 | Viking | YES | PASS |
| R33 | RS-05K1001FT | FH | YES | PASS |
| R34 | RS-05K1001FT | FH | YES | PASS |
| R35 | LR12FTDSR002 | Viking | YES | PASS |
| R36 | ERJ6ENF4703V | Panasonic | YES | PASS |
| R37 | ERJ6ENF4703V | Panasonic | YES | PASS |
| R38 | ERJ6ENF4703V | Panasonic | YES | PASS |
| R39 | ERJ6ENF4703V | Panasonic | YES | PASS |
| R40 | RS-05K1001FT | FH | YES | PASS |
| R41 | RS-05K1001FT | FH | YES | PASS |
| R42 | RS-05K1001FT | FH | YES | PASS |
| R43 | LR12FTDSR002 | Viking | YES | PASS |
| R44 | ERJ6ENF4703V | Panasonic | YES | PASS |
| R45 | ERJ6ENF4703V | Panasonic | YES | PASS |
| R46 | ERJ6ENF4703V | Panasonic | YES | PASS |
| R47 | ERJ6ENF4703V | Panasonic | YES | PASS |
| R48 | RS-05K1001FT | FH | YES | PASS |
| R49 | RS-05K1001FT | FH | YES | PASS |
| R50 | RS-05K1001FT | FH | YES | PASS |
| R51 | LR12FTDSR002 | Viking | YES | PASS |
| R52 | ERJ6ENF4703V | Panasonic | YES | PASS |
| R53 | ERJ6ENF4703V | Panasonic | YES | PASS |
| R54 | ERJ6ENF4703V | Panasonic | YES | PASS |
| R55 | ERJ6ENF4703V | Panasonic | YES | PASS |
| R56 | RS-05K1001FT | FH | YES | PASS |
| R57 | RC0402JR-130RL | YAGEO | YES | PASS |
| R58 | - | - | - | Not mounted |
| R59 | RC0201FR-071KL  | Yageo | YES | PASS |
| R60 | AC0603FR-074K99L | Yageo | YES | PASS |
| R61 | AC0603FR-074K99L | Yageo | YES | PASS |
| R62 | RC2512FK-0739RL | Yageo | YES | PASS |
| R63 | YC164-JR-071KL  | Yageo | YES | PASS |
| R64 | YC164-JR-071KL  | Yageo | YES | PASS |
| R65 | RS-05K1001FT | FH | YES | PASS |
| R66 | RS-05K1001FT | FH | YES | PASS |
| R67 | LR12FTDSR002 | Viking | YES | PASS |
| R68 | ERJ6ENF4703V | Panasonic | YES | PASS |
| R69 | ERJ6ENF4703V | Panasonic | YES | PASS |
| R70 | ERJ6ENF4703V | Panasonic | YES | PASS |
| R71 | ERJ6ENF4703V | Panasonic | YES | PASS |
| R72 | RS-05K1001FT | FH | YES | PASS |
| R73 | RS-05K1001FT | FH | YES | PASS |
| R74 | RS-05K1001FT | FH | YES | PASS |
| R75 | LR12FTDSR002 | Viking | YES | PASS |
| R76 | ERJ6ENF4703V | Panasonic | YES | PASS |
| R77 | ERJ6ENF4703V | Panasonic | YES | PASS |
| R78 | ERJ6ENF4703V | Panasonic | YES | PASS |
| R79 | ERJ6ENF4703V | Panasonic | YES | PASS |
| R80 | RS-05K1001FT | FH | YES | PASS |
| R81 | RS-05K1001FT | FH | YES | PASS |
| R82 | RS-05K1001FT | FH | YES | PASS |
| R83 | LR12FTDSR002 | Viking | YES | PASS |
| R84 | ERJ6ENF4703V | Panasonic | YES | PASS |
| R85 | ERJ6ENF4703V | Panasonic | YES | PASS |
| R86 | ERJ6ENF4703V | Panasonic | YES | PASS |
| R87 | ERJ6ENF4703V | Panasonic | YES | PASS |
| R88 | RS-05K1001FT | FH | YES | PASS |
| R89 | YC164-FR-0710KL  | Yageo | YES | PASS |
| R90 | YC164-FR-0710KL  | Yageo | YES | PASS |
| R91 | RC0402JR-130RL | YAGEO | YES | PASS |
| R92 | - | - | - | Not mounted |
| R93 | YC164-FR-0710KL  | Yageo | YES | PASS |
| R94 | RC-02W1003FT | FH | YES | PASS |
| R95 | MCR01MZPF1002 | ROHM | YES | PASS |
| R96 | RTT051002FTP | RALEC | YES | PASS |
| R97 | RS-05K1001FT | FH | YES | PASS |
| R98 | RS-05K1001FT | FH | YES | PASS |
| R99 | LR12FTDSR002 | Viking | YES | PASS |
| R100 | ERJ6ENF4703V | Panasonic | YES | PASS |
| R101 | ERJ6ENF4703V | Panasonic | YES | PASS |
| R102 | ERJ6ENF4703V | Panasonic | YES | PASS |
| R103 | ERJ6ENF4703V | Panasonic | YES | PASS |
| R104 | RS-05K1001FT | FH | YES | PASS |
| R105 | AC0603FR-074K99L | Yageo | YES | PASS |
| R106 | RC2512FK-0739RL | Yageo | YES | PASS |
| R107 | AC0603FR-074K99L | Yageo | YES | PASS |
| R108 | RTT051002FTP | RALEC | YES | PASS |
| R109 | RTT014701FTH | RALEC | YES | PASS |
| R110 | 1206W4F1004T5E | Uniohm | YES | PASS |
| R111 | - | - | - | Not mounted |
| R112 | RC-02K1001FT | FH | YES | PASS |
| R113 | RS-05K1001FT | FH | YES | PASS |
| R114 | RS-05K1001FT | FH | YES | PASS |
| R115 | LR12FTDSR002 | Viking | YES | PASS |
| R116 | ERJ6ENF4703V | Panasonic | YES | PASS |
| R117 | ERJ6ENF4703V | Panasonic | YES | PASS |
| R118 | ERJ6ENF4703V | Panasonic | YES | PASS |
| R119 | ERJ6ENF4703V | Panasonic | YES | PASS |
| R120 | RS-05K1001FT | FH | YES | PASS |
| R121 | RC-01W2201FT | FH | YES | PASS |
| R122 | RC-02K1001FT | FH | YES | PASS |
| R123 | RC-02K1001FT | FH | YES | PASS |
| R124 | RC0201FR-075K1L | Yageo | YES | PASS |
| R125 | RC0201FR-075K1L | Yageo | YES | PASS |
| R126 | RC-01W1002FT | FH | YES | PASS |
| R127 | RC-01W1002FT | FH | YES | PASS |
| R128 | - | - | - | Not mounted |
| R129 | RTT014701FTH | RALEC | YES | PASS |
| R130 | 0402WGF3301TCE | Uniohm | YES | PASS |
| R131 | MCS04020C1004FE000 | Vishay | YES | PASS |
| R132 | MCR01MZPF1002 | ROHM | YES | PASS |
| R133 | 0201WMF330KTEE | Uniohm | YES | PASS |
| R134 | 0201WMF330KTEE | Uniohm | YES | PASS |
| R135 | 0201WMF330KTEE | Uniohm | YES | PASS |
| R136 | 0201WMF330KTEE | Uniohm | YES | PASS |
| R137 | RC-01W49R9FTE | FH | YES | PASS |
| R138 | RC-01W49R9FTE | FH | YES | PASS |
| R139 | RC-01W49R9FTE | FH | YES | PASS |
| R140 | RC-01W49R9FTE | FH | YES | PASS |
| R141 | ERJ2RKF4700X | Panasonic | YES | PASS |
| R142 | ERJ2RKF4700X | Panasonic | YES | PASS |
| R143 | RC0201FR-0712K4L | Yageo | YES | PASS |
| R144 | AC0201FR-071ML  | Yageo | YES | PASS |
| R145 | RTT014701FTH | RALEC | YES | PASS |
| R146 | ERJ2RKF4700X | Panasonic | YES | PASS |
| R147 | MCR01MZPF1002 | ROHM | YES | PASS |
| R148 | CR0402FF2401G | LIZ | YES | PASS |
| R149 | TC164-FR-073K3L | Yageo | YES | PASS |
| R150 | RC-02W8201FT | FH | YES | PASS |
| R151 | RC-02K1001FT | FH | YES | PASS |
| R152 | AF0201FR-0710RL  | Yageo | YES | PASS |
| R153 | RC0201FR-071KL  | Yageo | YES | PASS |
| R154 | RC0201FR-071KL  | Yageo | YES | PASS |
| R155 | RC0201FR-071KL  | Yageo | YES | PASS |
| R156 | RC0201FR-071KL  | Yageo | YES | PASS |
| R157 | RC0201FR-071KL  | Yageo | YES | PASS |
| R158 | RC0201FR-071KL  | Yageo | YES | PASS |
| R159 | RC0201FR-071KL  | Yageo | YES | PASS |
| R160 | RC-01W27R0FT  | FH | YES | PASS |
| R161 | - | - | - | Not mounted |
| R162 | MCR01MZPF1002 | ROHM | YES | PASS |
| R163 | RC-02K1001FT | FH | YES | PASS |
| R164 | MCR01MZPF1002 | ROHM | YES | PASS |
| R165 | - | - | - | Not mounted |
| R166 | 0402WGF3301TCE | Uniohm | YES | PASS |
| R167 | 0402WGF3301TCE | Uniohm | YES | PASS |
| R168 | 0402WGF3301TCE | Uniohm | YES | PASS |
| R169 | RTT06000JTP | RALEC | YES | PASS |
| R170 | RTT06000JTP | RALEC | YES | PASS |
| R171 | MCR01MZPF1002 | ROHM | YES | PASS |
| R172 | - | - | - | Not mounted |
| REF1 | LM4040C30FTA  | DIODES | YES | PASS |
| REL0 | - | - | - | Not mounted |
| REL1 | - | - | - | Not mounted |
| REL2 | - | - | - | Not mounted |
| REL3 | - | - | - | Not mounted |
| REL4 | - | - | - | Not mounted |
| REL5 | - | - | - | Not mounted |
| REL6 | - | - | - | Not mounted |
| REL7 | - | - | - | Not mounted |
| RES | B3U-1000P | Omron | YES | PASS |
| RGTG | - | - | - | Not mounted |
| RN1 | YC164-FR-07100KL  | Yageo | YES | PASS |
| RN2 | YC164-FR-07100KL  | Yageo | YES | PASS |
| RST | - | - | - | Not mounted |
| RX0 | - | - | - | Not mounted |
| SC | - | - | - | Not mounted |
| SCL0 | - | - | - | Not mounted |
| SCL1 | - | - | - | Not mounted |
| SCLK1 | - | - | - | Not mounted |
| SDA0 | - | - | - | Not mounted |
| SDA1 | - | - | - | Not mounted |
| SW | - | - | - | Not mounted |
| SW3 | - | - | - | Not mounted |
| T1 | BSS138 | HUASHUO | YES | PASS |
| TX0 | - | - | - | Not mounted |
| U$1 | - | - | - | Not mounted |
| U$2 | - | - | - | Not mounted |
| U$3 | - | - | - | Not mounted |
| U$4 | - | - | - | Not mounted |
| U$5 | - | - | - | Not mounted |
| U$6 | - | - | - | Not mounted |
| U$7 | - | - | - | Not mounted |
| U$10 | - | - | - | Not mounted |
| U$11 | - | - | - | Not mounted |
| U$12 | - | - | - | Not mounted |
| U$13 | - | - | - | Not mounted |
| U$14 | - | - | - | Not mounted |
| U$15 | - | - | - | Not mounted |
| USB1 | USB-TYPE-C-018  | DEALON | YES | PASS |
| UTX | - | - | - | Not mounted |
| VBUS | - | - | - | Not mounted |
| VCC | - | - | - | Not mounted |
| VCC2 | - | - | - | Not mounted |
| VREF | - | - | - | Not mounted |
| X1 | SX32Y012000B91T | TKD | YES | PASS |
| X2 | X1E000021013900 | Epson | YES | PASS |

---

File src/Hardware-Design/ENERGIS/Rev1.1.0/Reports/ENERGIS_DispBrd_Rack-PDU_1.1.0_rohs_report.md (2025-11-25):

# ROHS Compliance Certificate

## Evaluated design

**Design File**: `ENERGIS_DispBrd_Rack-PDU_1.1.0.brd`

**Evaluation Date**: 2025-11-25 9:02 PM

**Total Components (placed)**: 83

**Evaluated (excluding Not mounted)**: 55

**Compliant Components**: 55

---

## Evaluation Criteria

<p align="justify">
Each populated component is checked for the <code>ROHS</code> attribute. Accepted value is <code>YES</code>. Any component with a missing <code>ROHS</code> attribute or a value other than <code>YES</code> is considered non-compliant for this report. Components marked as <code>DNI</code> are excluded and listed as Not mounted.
</p>

---

## Final Statement

Based on the attributes present in the EAGLE board file at the time of export, this design is considered:

<div align="center"><h1>RoHS COMPLIANT</h1></div>

This certificate reflects only metadata embedded in the project and does not replace manufacturer documentation.
| Ref | MPN | Manufacturer | ROHS Compliant | Result |
|-----|-----|---|---|---|
| 3V3 | - | - | - | Not mounted |
| 5V | - | - | - | Not mounted |
| < | UK-B0228G43-SP25  | USAKRO | YES | PASS |
| > | UK-B0228G43-SP25  | USAKRO | YES | PASS |
| BL | - | - | - | Not mounted |
| C1 | - | - | - | Not mounted |
| C2 | - | - | - | Not mounted |
| C3 | - | - | - | Not mounted |
| C4 | - | - | - | Not mounted |
| C5 | 0402X104K250CT | Walsin | YES | PASS |
| C6 | 0402X104K250CT | Walsin | YES | PASS |
| C7 | 0402X104K250CT | Walsin | YES | PASS |
| C8 | 0402X104K250CT | Walsin | YES | PASS |
| C9 | 0402X104K250CT | Walsin | YES | PASS |
| C10 | 0402X104K250CT | Walsin | YES | PASS |
| C11 | 0402X104K250CT | Walsin | YES | PASS |
| C12 | 0402X104K250CT | Walsin | YES | PASS |
| CH1 | MHT170UGCT | MEIHUA | YES | PASS |
| CH2 | MHT170UGCT | MEIHUA | YES | PASS |
| CH3 | MHT170UGCT | MEIHUA | YES | PASS |
| CH4 | MHT170UGCT | MEIHUA | YES | PASS |
| CH5 | MHT170UGCT | MEIHUA | YES | PASS |
| CH6 | MHT170UGCT | MEIHUA | YES | PASS |
| CH7 | MHT170UGCT | MEIHUA | YES | PASS |
| CH8 | MHT170UGCT | MEIHUA | YES | PASS |
| CON1 | - | - | - | Not mounted |
| CON2 | AFC11-S20ICA-00 | JS | YES | PASS |
| CS | - | - | - | Not mounted |
| D1 | PTVS3V3S1UR,115  | Nexperia | YES | PASS |
| D2 | PTVS3V3S1UR,115  | Nexperia | YES | PASS |
| D3 | PTVS3V3S1UR,115  | Nexperia | YES | PASS |
| D4 | PTVS3V3S1UR,115  | Nexperia | YES | PASS |
| D5 | RCLAMP0582BQTCT | SEMTECH | YES | PASS |
| DSP | - | - | - | Not mounted |
| GND | - | - | - | Not mounted |
| H1 | - | - | - | Not mounted |
| H2 | - | - | - | Not mounted |
| H3 | - | - | - | Not mounted |
| IC1 | MCP23017-E/ML | MICROCHIP | YES | PASS |
| IC2 | MCP23017-E/ML | MICROCHIP | YES | PASS |
| LED1 | MHL3014UGTD | MEIHUA | YES | PASS |
| LED2 | MHL3014UBTD | MEIHUA | YES | PASS |
| LED3 | MHL3014SRTS | MEIHUA | YES | PASS |
| MISO | - | - | - | Not mounted |
| MOSI | - | - | - | Not mounted |
| O | UK-B0228G43-SP25  | USAKRO | YES | PASS |
| PWR | UK-B0228G43-SP25  | USAKRO | YES | PASS |
| R1 | - | - | - | Not mounted |
| R2 | - | - | - | Not mounted |
| R3 | - | - | - | Not mounted |
| R4 | MCR01MZPF1002 | ROHM | YES | PASS |
| R5 | MCR01MZPF1002 | ROHM | YES | PASS |
| R6 | MCR01MZPF1002 | ROHM | YES | PASS |
| R7 | RC-02K1001FT | FH | YES | PASS |
| R8 | YC164-JR-071KL  | Yageo | YES | PASS |
| R9 | YC164-JR-071KL  | Yageo | YES | PASS |
| R10 | RC-02K1001FT | FH | YES | PASS |
| R11 | RC-02K1001FT | FH | YES | PASS |
| R12 | MCR01MZPF1002 | ROHM | YES | PASS |
| R13 | MCR01MZPF1002 | ROHM | YES | PASS |
| R14 | YC164-JR-071KL  | Yageo | YES | PASS |
| R15 | YC164-JR-071KL  | Yageo | YES | PASS |
| R16 | RC0402JR-130RL | YAGEO | YES | PASS |
| R17 | RC0402JR-130RL | YAGEO | YES | PASS |
| R18 | RC0402JR-130RL | YAGEO | YES | PASS |
| R19 | RC0402JR-130RL | YAGEO | YES | PASS |
| SCK | - | - | - | Not mounted |
| SCL0 | - | - | - | Not mounted |
| SDA0 | - | - | - | Not mounted |
| SEL1 | FC-2012YOXK(5)-600H08 | NATIONSTAR | YES | PASS |
| SEL2 | FC-2012YOXK(5)-600H08 | NATIONSTAR | YES | PASS |
| SEL3 | FC-2012YOXK(5)-600H08 | NATIONSTAR | YES | PASS |
| SEL4 | FC-2012YOXK(5)-600H08 | NATIONSTAR | YES | PASS |
| SEL5 | FC-2012YOXK(5)-600H08 | NATIONSTAR | YES | PASS |
| SEL6 | FC-2012YOXK(5)-600H08 | NATIONSTAR | YES | PASS |
| SEL7 | FC-2012YOXK(5)-600H08 | NATIONSTAR | YES | PASS |
| SEL8 | FC-2012YOXK(5)-600H08 | NATIONSTAR | YES | PASS |
| T1 | BSS138 | HUASHUO | - | Not mounted |
| U$1 | - | - | - | Not mounted |
| U$5 | - | - | - | Not mounted |
| U$8 | - | - | - | Not mounted |
| U$9 | - | - | - | Not mounted |
| U$10 | - | - | - | Not mounted |

---

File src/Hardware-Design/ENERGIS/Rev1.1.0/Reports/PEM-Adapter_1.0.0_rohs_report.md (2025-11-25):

# ROHS Compliance Certificate

## Evaluated design

**Design File**: `PEM-Adapter_1.0.0.brd`

**Evaluation Date**: 2025-11-25 9:20 PM

**Total Components (placed)**: 15

**Evaluated (excluding Not mounted)**: 11

**Compliant Components**: 11

---

## Evaluation Criteria

<p align="justify">
Each populated component is checked for the <code>ROHS</code> attribute. Accepted value is <code>YES</code>. Any component with a missing <code>ROHS</code> attribute or a value other than <code>YES</code> is considered non-compliant for this report. Components marked as <code>DNI</code> are excluded and listed as Not mounted.
</p>

---

## Final Statement

Based on the attributes present in the EAGLE board file at the time of export, this design is considered:

<div align="center"><h1>RoHS COMPLIANT</h1></div>

This certificate reflects only metadata embedded in the project and does not replace manufacturer documentation.
| Ref | MPN | Manufacturer | ROHS Compliant | Result |
|-----|-----|---|---|---|
| L1 | 1217861-1 | TE CONNECTIVITY | YES | PASS |
| L2 | 1217861-1 | TE CONNECTIVITY | YES | PASS |
| L3 | 1217861-1 | TE CONNECTIVITY | YES | PASS |
| L4 | 1217861-1 | TE CONNECTIVITY | YES | PASS |
| N1 | 1217861-1 | TE CONNECTIVITY | YES | PASS |
| N2 | 1217861-1 | TE CONNECTIVITY | YES | PASS |
| N3 | 1217861-1 | TE CONNECTIVITY | YES | PASS |
| N4 | 1217861-1 | TE CONNECTIVITY | YES | PASS |
| PE1 | 1217861-1 | TE CONNECTIVITY | YES | PASS |
| PE2 | 1217861-1 | TE CONNECTIVITY | YES | PASS |
| PEM1 | 3-104-370 | SCHURTER Inc. | YES | PASS |
| U$1 | - | - | - | Not mounted |
| U$2 | - | - | - | Not mounted |
| U$3 | - | - | - | Not mounted |
| U$4 | - | - | - | Not mounted |

---

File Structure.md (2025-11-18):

# ENERGIS Project - Folder Structure Documentation

This repository contains all relevant files and documentation for the **ENERGIS 10-Inch Rack PDU** project. Below is an overview of the structure and associated README files in different folders.

---

## 📂 `docs/`
### 📁 **Datasheets**
- Contains datasheets for components, organized in folders corresponding to the board they are used on.

### 📁 **Manuals**
- Contains reference designs for relevant components.

---

## 📂 `images/`
### 📁 **Controller Board, Display Board, Relay Board**
- Contains **3D renders and blank PCB images** for each respective board.

### 📁 **Assembly**
- Contains **assembled 3D renders** showing the PDU in its enclosure.

---

## 📂 `misc/`
- Contains **BOM (Bill of Materials) files** for ordering missing components, which are not available at the PCB factory.

---

## 📂 `src/`
### 📁 **HardwareDesign**
- Contains **schematic and gerber files** for PCB manufacturing.

### 📁 **Libraries**
- Contains all **custom libraries** used in the hardware design.

### 📁 **PDF**
- Contains **PDF exports** of the schematics.

### 📁 **Software**
- Currently **empty** (to be populated with firmware/software later).

---

## 📂 `tests/`
- Currently **empty**, intended for hardware and firmware testing.

---

### ✅ **Next Steps:**
- Populate the **Software** and **Tests** folders when development progresses.
- Maintain **updated BOMs** in the `misc/` folder for easy component sourcing.

For further details, refer to the **main project README**.

---

**Maintained by:** [DvidMakesThings](https://github.com/DvidMakesThings)

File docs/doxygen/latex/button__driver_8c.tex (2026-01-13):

\doxysection{src/\+Software/\+ENERGIS\+\_\+\+RTOS/src/drivers/button\+\_\+driver.c File Reference}
\hypertarget{button__driver_8c}{}\label{button__driver_8c}\index{src/Software/ENERGIS\_RTOS/src/drivers/button\_driver.c@{src/Software/ENERGIS\_RTOS/src/drivers/button\_driver.c}}
{\ttfamily \#include "{}../\+CONFIG.\+h"{}}\newline
Include dependency graph for button\+\_\+driver.\+c\+:\nopagebreak
\begin{figure}[H]
\begin{center}
\leavevmode
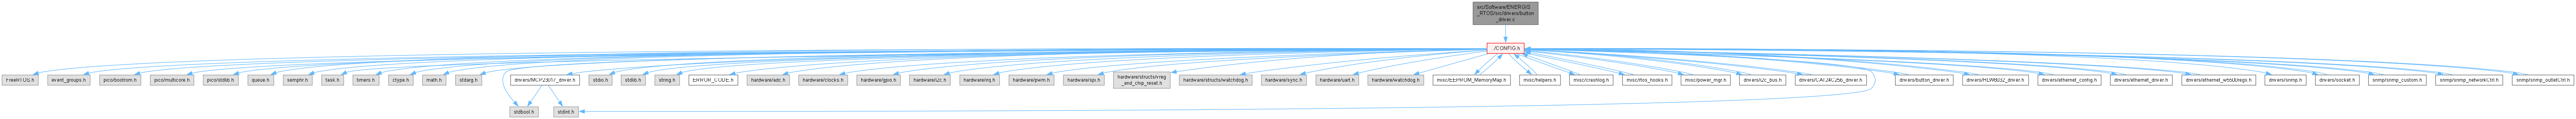
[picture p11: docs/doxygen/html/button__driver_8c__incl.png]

\end{center}
\end{figure}
\doxysubsubsection*{Macros}
\begin{DoxyCompactItemize}
\item 
\#define \mbox{\hyperlink{button__driver_8c_a1b5c45676754dcb9e6d3c2e59c301486}{BTNDRV\+\_\+\+TAG}}~"{}\mbox{[}BTNDRV\mbox{]}"{}
\end{DoxyCompactItemize}
\doxysubsubsection*{Functions}
\begin{DoxyCompactItemize}
\item 
static void \mbox{\hyperlink{button__driver_8c_a1e1377700e59631bf0d33be94ab08f5b}{drv\+\_\+sel\+\_\+all\+\_\+off}} (void)
\begin{DoxyCompactList}\small\item\em Turn off all selection LEDs via Switch\+Task. \end{DoxyCompactList}\item 
void \mbox{\hyperlink{group__driver01_gac22126e540828f671a4440c6649bdf55}{Button\+Drv\+\_\+\+Init\+GPIO}} (void)
\begin{DoxyCompactList}\small\item\em Initialize button GPIO pins and selection LED hardware. \end{DoxyCompactList}\item 
bool \mbox{\hyperlink{group__driver01_ga15286889045dee940269b565c973b98a}{Button\+Drv\+\_\+\+Read\+Plus}} (void)
\begin{DoxyCompactList}\small\item\em Read current state of PLUS button. \end{DoxyCompactList}\item 
bool \mbox{\hyperlink{group__driver01_ga731ea4ee98db605d8215ab3eb88d4633}{Button\+Drv\+\_\+\+Read\+Minus}} (void)
\begin{DoxyCompactList}\small\item\em Read current state of MINUS button. \end{DoxyCompactList}\item 
bool \mbox{\hyperlink{group__driver01_gaa50982e8ab931b8383da90535715fbb2}{Button\+Drv\+\_\+\+Read\+Set}} (void)
\begin{DoxyCompactList}\small\item\em Read current state of SET button. \end{DoxyCompactList}\item 
void \mbox{\hyperlink{group__driver01_gac5901ff1bb130ab17484230d894cc54e}{Button\+Drv\+\_\+\+Select\+All\+Off}} (void)
\begin{DoxyCompactList}\small\item\em Turn off all eight channel selection LEDs. \end{DoxyCompactList}\item 
void \mbox{\hyperlink{group__driver01_gabe577d3f3ce0d1daffbfc739aaaba34a}{Button\+Drv\+\_\+\+Select\+Show}} (uint8\+\_\+t index, bool on)
\begin{DoxyCompactList}\small\item\em Control visibility of a single channel selection LED. \end{DoxyCompactList}\item 
void \mbox{\hyperlink{group__driver01_gaabe879a90d89fae52e5a45c07ce6134a}{Button\+Drv\+\_\+\+Select\+Left}} (uint8\+\_\+t \texorpdfstring{$\ast$}{*}io\+\_\+index, bool led\+\_\+on)
\begin{DoxyCompactList}\small\item\em Move selection indicator one position left with wraparound. \end{DoxyCompactList}\item 
void \mbox{\hyperlink{group__driver01_ga900a33314d24546a18ef5db5a3db8a40}{Button\+Drv\+\_\+\+Select\+Right}} (uint8\+\_\+t \texorpdfstring{$\ast$}{*}io\+\_\+index, bool led\+\_\+on)
\begin{DoxyCompactList}\small\item\em Move selection indicator one position right with wraparound. \end{DoxyCompactList}\item 
void \mbox{\hyperlink{group__driver01_gafe1594ae8ba586d579964b90a2ddd5ff}{Button\+Drv\+\_\+\+Do\+Set\+Short}} (uint8\+\_\+t index)
\begin{DoxyCompactList}\small\item\em Execute short-\/press action for SET button on specified channel. \end{DoxyCompactList}\item 
void \mbox{\hyperlink{group__driver01_ga487df05238dab6da8ad4ab2d1d8e3a4d}{Button\+Drv\+\_\+\+Do\+Set\+Long}} (void)
\begin{DoxyCompactList}\small\item\em Execute long-\/press action for SET button. \end{DoxyCompactList}\item 
uint32\+\_\+t \mbox{\hyperlink{group__driver01_ga038e6418532b3e07206ada073cf02f22}{Button\+Drv\+\_\+\+Now\+Ms}} (void)
\begin{DoxyCompactList}\small\item\em Get monotonic millisecond timestamp since boot. \end{DoxyCompactList}\end{DoxyCompactItemize}

\doxysubsection{Detailed Description}
\begin{DoxyAuthor}{Author}
Dvid\+Makes\+Things -\/ David Sipos
\end{DoxyAuthor}
\begin{DoxyVersion}{Version}
1.\+1.\+1 
\end{DoxyVersion}
\begin{DoxyDate}{Date}
2025-\/12-\/10
\end{DoxyDate}
Implements hardware abstraction for front-\/panel buttons and selection LEDs. Delegates all I2C operations to Switch\+Task to prevent bus contention and ensure thread-\/safe access to MCP23017 GPIO expanders.

Key Design Principles\+:
\begin{DoxyItemize}
\item Direct GPIO reads for buttons (no I2C, very fast)
\item All LED operations queued to Switch\+Task (non-\/blocking)
\item No local state except channel index modifications
\item Error logging for invalid parameters and queue failures
\end{DoxyItemize}

@project ENERGIS -\/ The Managed PDU Project for 10-\/Inch Rack @github \href{https://github.com/DvidMakesThings/HW_10-In-Rack_PDU}{\texttt{https\+://github.\+com/\+Dvid\+Makes\+Things/\+HW\+\_\+10-\/\+In-\/\+Rack\+\_\+\+PDU}} 

\label{doc-define-members}
\Hypertarget{button__driver_8c_doc-define-members}
\doxysubsection{Macro Definition Documentation}
\Hypertarget{button__driver_8c_a1b5c45676754dcb9e6d3c2e59c301486}\index{button\_driver.c@{button\_driver.c}!BTNDRV\_TAG@{BTNDRV\_TAG}}
\index{BTNDRV\_TAG@{BTNDRV\_TAG}!button\_driver.c@{button\_driver.c}}
\doxysubsubsection{\texorpdfstring{BTNDRV\_TAG}{BTNDRV\_TAG}}
{\footnotesize\ttfamily \label{button__driver_8c_a1b5c45676754dcb9e6d3c2e59c301486} 
\#define BTNDRV\+\_\+\+TAG~"{}\mbox{[}BTNDRV\mbox{]}"{}}

\label{doc-func-members}
\Hypertarget{button__driver_8c_doc-func-members}
\doxysubsection{Function Documentation}
\Hypertarget{button__driver_8c_a1e1377700e59631bf0d33be94ab08f5b}\index{button\_driver.c@{button\_driver.c}!drv\_sel\_all\_off@{drv\_sel\_all\_off}}
\index{drv\_sel\_all\_off@{drv\_sel\_all\_off}!button\_driver.c@{button\_driver.c}}
\doxysubsubsection{\texorpdfstring{drv\_sel\_all\_off()}{drv\_sel\_all\_off()}}
{\footnotesize\ttfamily \label{button__driver_8c_a1e1377700e59631bf0d33be94ab08f5b} 
void drv\+\_\+sel\+\_\+all\+\_\+off (\begin{DoxyParamCaption}\item[{void}]{}{}\end{DoxyParamCaption})\hspace{0.3cm}{\ttfamily [inline]}, {\ttfamily [static]}}

Turn off all selection LEDs via Switch\+Task. 

Internal helper that delegates to Switch\+Task. If Switch\+Task is not ready (early boot), LEDs are left unchanged to prevent I2C access before bus initialization.

\begin{DoxyParams}{Parameters}
{\em None} & \\
\hline
\end{DoxyParams}
\begin{DoxyReturn}{Returns}
None 
\end{DoxyReturn}
Here is the call graph for this function\+:\nopagebreak
\begin{figure}[H]
\begin{center}
\leavevmode

\end{center}
\end{figure}
Here is the caller graph for this function\+:\nopagebreak
\begin{figure}[H]
\begin{center}
\leavevmode

\end{center}
\end{figure}

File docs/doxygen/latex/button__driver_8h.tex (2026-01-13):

\doxysection{src/\+Software/\+ENERGIS\+\_\+\+RTOS/src/drivers/button\+\_\+driver.h File Reference}
\hypertarget{button__driver_8h}{}\label{button__driver_8h}\index{src/Software/ENERGIS\_RTOS/src/drivers/button\_driver.h@{src/Software/ENERGIS\_RTOS/src/drivers/button\_driver.h}}
{\ttfamily \#include "{}../\+CONFIG.\+h"{}}\newline
Include dependency graph for button\+\_\+driver.\+h\+:\nopagebreak
\begin{figure}[H]
\begin{center}
\leavevmode
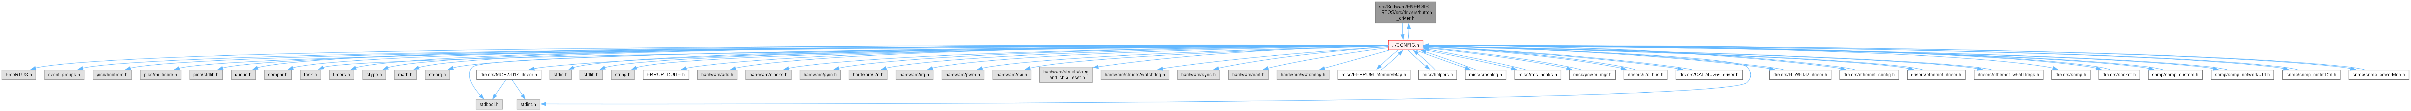
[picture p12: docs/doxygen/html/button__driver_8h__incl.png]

\end{center}
\end{figure}
This graph shows which files directly or indirectly include this file\+:\nopagebreak
\begin{figure}[H]
\begin{center}
\leavevmode
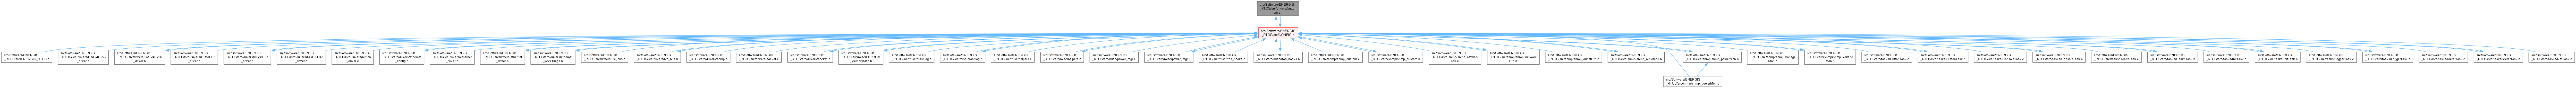
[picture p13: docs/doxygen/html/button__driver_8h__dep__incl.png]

\end{center}
\end{figure}
\doxysubsubsection*{Functions}
\begin{Indent}\textbf{ Public API}\par
\begin{DoxyCompactItemize}
\item 
void \mbox{\hyperlink{group__driver01_gac22126e540828f671a4440c6649bdf55}{Button\+Drv\+\_\+\+Init\+GPIO}} (void)
\begin{DoxyCompactList}\small\item\em Initialize button GPIO pins and selection LED hardware. \end{DoxyCompactList}\item 
bool \mbox{\hyperlink{group__driver01_ga15286889045dee940269b565c973b98a}{Button\+Drv\+\_\+\+Read\+Plus}} (void)
\begin{DoxyCompactList}\small\item\em Read current state of PLUS button. \end{DoxyCompactList}\item 
bool \mbox{\hyperlink{group__driver01_ga731ea4ee98db605d8215ab3eb88d4633}{Button\+Drv\+\_\+\+Read\+Minus}} (void)
\begin{DoxyCompactList}\small\item\em Read current state of MINUS button. \end{DoxyCompactList}\item 
bool \mbox{\hyperlink{group__driver01_gaa50982e8ab931b8383da90535715fbb2}{Button\+Drv\+\_\+\+Read\+Set}} (void)
\begin{DoxyCompactList}\small\item\em Read current state of SET button. \end{DoxyCompactList}\item 
void \mbox{\hyperlink{group__driver01_gac5901ff1bb130ab17484230d894cc54e}{Button\+Drv\+\_\+\+Select\+All\+Off}} (void)
\begin{DoxyCompactList}\small\item\em Turn off all eight channel selection LEDs. \end{DoxyCompactList}\item 
void \mbox{\hyperlink{group__driver01_gabe577d3f3ce0d1daffbfc739aaaba34a}{Button\+Drv\+\_\+\+Select\+Show}} (uint8\+\_\+t index, bool on)
\begin{DoxyCompactList}\small\item\em Control visibility of a single channel selection LED. \end{DoxyCompactList}\item 
void \mbox{\hyperlink{group__driver01_gaabe879a90d89fae52e5a45c07ce6134a}{Button\+Drv\+\_\+\+Select\+Left}} (uint8\+\_\+t \texorpdfstring{$\ast$}{*}io\+\_\+index, bool led\+\_\+on)
\begin{DoxyCompactList}\small\item\em Move selection indicator one position left with wraparound. \end{DoxyCompactList}\item 
void \mbox{\hyperlink{group__driver01_ga900a33314d24546a18ef5db5a3db8a40}{Button\+Drv\+\_\+\+Select\+Right}} (uint8\+\_\+t \texorpdfstring{$\ast$}{*}io\+\_\+index, bool led\+\_\+on)
\begin{DoxyCompactList}\small\item\em Move selection indicator one position right with wraparound. \end{DoxyCompactList}\item 
void \mbox{\hyperlink{group__driver01_gafe1594ae8ba586d579964b90a2ddd5ff}{Button\+Drv\+\_\+\+Do\+Set\+Short}} (uint8\+\_\+t index)
\begin{DoxyCompactList}\small\item\em Execute short-\/press action for SET button on specified channel. \end{DoxyCompactList}\item 
void \mbox{\hyperlink{group__driver01_ga487df05238dab6da8ad4ab2d1d8e3a4d}{Button\+Drv\+\_\+\+Do\+Set\+Long}} (void)
\begin{DoxyCompactList}\small\item\em Execute long-\/press action for SET button. \end{DoxyCompactList}\item 
uint32\+\_\+t \mbox{\hyperlink{group__driver01_ga038e6418532b3e07206ada073cf02f22}{Button\+Drv\+\_\+\+Now\+Ms}} (void)
\begin{DoxyCompactList}\small\item\em Get monotonic millisecond timestamp since boot. \end{DoxyCompactList}\end{DoxyCompactItemize}
\end{Indent}

\doxysubsection{Detailed Description}
\begin{DoxyAuthor}{Author}
Dvid\+Makes\+Things -\/ David Sipos 
\end{DoxyAuthor}

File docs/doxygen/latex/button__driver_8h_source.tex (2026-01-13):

\doxysection{button\+\_\+driver.\+h}
\hypertarget{button__driver_8h_source}{}\label{button__driver_8h_source}\index{src/Software/ENERGIS\_RTOS/src/drivers/button\_driver.h@{src/Software/ENERGIS\_RTOS/src/drivers/button\_driver.h}}
\mbox{\hyperlink{button__driver_8h}{Go to the documentation of this file.}}
\begin{DoxyCode}{0}
\DoxyCodeLine{00001\ }
\DoxyCodeLine{00034\ }
\DoxyCodeLine{00035\ \textcolor{preprocessor}{\#ifndef\ ENERGIS\_BUTTON\_DRIVER\_H}}
\DoxyCodeLine{00036\ \textcolor{preprocessor}{\#define\ ENERGIS\_BUTTON\_DRIVER\_H}}
\DoxyCodeLine{00037\ }
\DoxyCodeLine{00038\ \textcolor{preprocessor}{\#include\ "{}\mbox{\hyperlink{_c_o_n_f_i_g_8h}{../CONFIG.h}}"{}}}
\DoxyCodeLine{00039\ }
\DoxyCodeLine{00061\ \textcolor{keywordtype}{void}\ \mbox{\hyperlink{group__driver01_gac22126e540828f671a4440c6649bdf55}{ButtonDrv\_InitGPIO}}(\textcolor{keywordtype}{void});}
\DoxyCodeLine{00062\ }
\DoxyCodeLine{00073\ \textcolor{keywordtype}{bool}\ \mbox{\hyperlink{group__driver01_ga15286889045dee940269b565c973b98a}{ButtonDrv\_ReadPlus}}(\textcolor{keywordtype}{void});}
\DoxyCodeLine{00074\ }
\DoxyCodeLine{00085\ \textcolor{keywordtype}{bool}\ \mbox{\hyperlink{group__driver01_ga731ea4ee98db605d8215ab3eb88d4633}{ButtonDrv\_ReadMinus}}(\textcolor{keywordtype}{void});}
\DoxyCodeLine{00086\ }
\DoxyCodeLine{00097\ \textcolor{keywordtype}{bool}\ \mbox{\hyperlink{group__driver01_gaa50982e8ab931b8383da90535715fbb2}{ButtonDrv\_ReadSet}}(\textcolor{keywordtype}{void});}
\DoxyCodeLine{00098\ }
\DoxyCodeLine{00111\ \textcolor{keywordtype}{void}\ \mbox{\hyperlink{group__driver01_gac5901ff1bb130ab17484230d894cc54e}{ButtonDrv\_SelectAllOff}}(\textcolor{keywordtype}{void});}
\DoxyCodeLine{00112\ }
\DoxyCodeLine{00129\ \textcolor{keywordtype}{void}\ \mbox{\hyperlink{group__driver01_gabe577d3f3ce0d1daffbfc739aaaba34a}{ButtonDrv\_SelectShow}}(uint8\_t\ index,\ \textcolor{keywordtype}{bool}\ on);}
\DoxyCodeLine{00130\ }
\DoxyCodeLine{00146\ \textcolor{keywordtype}{void}\ \mbox{\hyperlink{group__driver01_gaabe879a90d89fae52e5a45c07ce6134a}{ButtonDrv\_SelectLeft}}(uint8\_t\ *io\_index,\ \textcolor{keywordtype}{bool}\ led\_on);}
\DoxyCodeLine{00147\ }
\DoxyCodeLine{00163\ \textcolor{keywordtype}{void}\ \mbox{\hyperlink{group__driver01_ga900a33314d24546a18ef5db5a3db8a40}{ButtonDrv\_SelectRight}}(uint8\_t\ *io\_index,\ \textcolor{keywordtype}{bool}\ led\_on);}
\DoxyCodeLine{00164\ }
\DoxyCodeLine{00179\ \textcolor{keywordtype}{void}\ \mbox{\hyperlink{group__driver01_gafe1594ae8ba586d579964b90a2ddd5ff}{ButtonDrv\_DoSetShort}}(uint8\_t\ index);}
\DoxyCodeLine{00180\ }
\DoxyCodeLine{00194\ \textcolor{keywordtype}{void}\ \mbox{\hyperlink{group__driver01_ga487df05238dab6da8ad4ab2d1d8e3a4d}{ButtonDrv\_DoSetLong}}(\textcolor{keywordtype}{void});}
\DoxyCodeLine{00195\ }
\DoxyCodeLine{00209\ uint32\_t\ \mbox{\hyperlink{group__driver01_ga038e6418532b3e07206ada073cf02f22}{ButtonDrv\_NowMs}}(\textcolor{keywordtype}{void});}
\DoxyCodeLine{00211\ }
\DoxyCodeLine{00212\ \textcolor{preprocessor}{\#endif\ }\textcolor{comment}{/*\ ENERGIS\_BUTTON\_DRIVER\_H\ */}\textcolor{preprocessor}{}}
\DoxyCodeLine{00213\ }

\end{DoxyCode}

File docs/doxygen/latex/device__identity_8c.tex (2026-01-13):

\doxysection{src/\+Software/\+ENERGIS\+\_\+\+RTOS/src/tasks/storage\+\_\+submodule/device\+\_\+identity.c File Reference}
\hypertarget{device__identity_8c}{}\label{device__identity_8c}\index{src/Software/ENERGIS\_RTOS/src/tasks/storage\_submodule/device\_identity.c@{src/Software/ENERGIS\_RTOS/src/tasks/storage\_submodule/device\_identity.c}}
{\ttfamily \#include "{}../../\+CONFIG.\+h"{}}\newline
Include dependency graph for device\+\_\+identity.\+c\+:\nopagebreak
\begin{figure}[H]
\begin{center}
\leavevmode
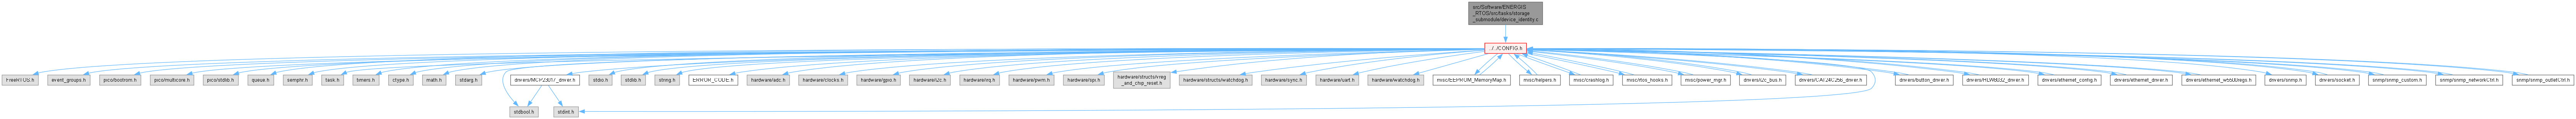
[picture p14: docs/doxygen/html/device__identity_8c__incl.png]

\end{center}
\end{figure}
\doxysubsubsection*{Macros}
\begin{DoxyCompactItemize}
\item 
\#define \mbox{\hyperlink{device__identity_8c_a693d7c6a2e50da7b41c0b3ce4a15a34c}{DEVICE\+\_\+\+IDENTITY\+\_\+\+TAG}}~"{}\mbox{[}DEV-\/ID\mbox{]}"{}
\item 
\#define \mbox{\hyperlink{device__identity_8c_abbaae20f896b1491508dc17ab1e3b6c4}{EEPROM\+\_\+\+DEVICE\+\_\+\+IDENTITY\+\_\+\+ADDR}}~\mbox{\hyperlink{group__config06_ga0b0b03d61ed2b7c416e0e8665598eb3f}{EEPROM\+\_\+\+DEVICE\+\_\+\+IDENTITY\+\_\+\+START}}
\begin{DoxyCompactList}\small\item\em EEPROM address for device identity record. \end{DoxyCompactList}\item 
\#define \mbox{\hyperlink{device__identity_8c_a66bed1308b249cda5e4afd5fc5852c21}{EEPROM\+\_\+\+DEVICE\+\_\+\+IDENTITY\+\_\+\+TOTAL\+\_\+\+SIZE}}~\mbox{\hyperlink{group__config06_ga226676d435b8ea7dc26213a892abc464}{EEPROM\+\_\+\+DEVICE\+\_\+\+IDENTITY\+\_\+\+SIZE}}
\begin{DoxyCompactList}\small\item\em Total size of device identity EEPROM block. \end{DoxyCompactList}\item 
\#define \mbox{\hyperlink{device__identity_8c_a48f56dfea37a13b773d43067947bf70d}{EEPROM\+\_\+\+DEVICE\+\_\+\+IDENTITY\+\_\+\+REGION\+\_\+\+OFFSET}}~0x10u
\begin{DoxyCompactList}\small\item\em Offset of region within identity EEPROM block. \end{DoxyCompactList}\item 
\#define \mbox{\hyperlink{device__identity_8c_a1618e0e52c6c528ccfe2fae354844f88}{EEPROM\+\_\+\+DEVICE\+\_\+\+IDENTITY\+\_\+\+CRC\+\_\+\+OFFSET}}~0x11u
\begin{DoxyCompactList}\small\item\em Offset of CRC within identity EEPROM block. \end{DoxyCompactList}\item 
\#define \mbox{\hyperlink{device__identity_8c_af08ec717a68641f395791d8b7f41474b}{EEPROM\+\_\+\+DEVICE\+\_\+\+IDENTITY\+\_\+\+PAD\+\_\+\+OFFSET}}~0x12u
\begin{DoxyCompactList}\small\item\em Offset of reserved pad within identity EEPROM block. \end{DoxyCompactList}\item 
\#define \mbox{\hyperlink{device__identity_8c_a0acf2e274a352da43a527642ce8562fd}{EEPROM\+\_\+\+DEVICE\+\_\+\+IDENTITY\+\_\+\+CRC\+\_\+\+LEN}}~0x11u /\texorpdfstring{$\ast$}{*} 0x00..\+0x10 inclusive =$>$ 17 bytes \texorpdfstring{$\ast$}{*}/
\begin{DoxyCompactList}\small\item\em Number of bytes covered by CRC calculation (serial + region). \end{DoxyCompactList}\item 
\#define \mbox{\hyperlink{device__identity_8c_a16e574655217d65f33296fd5c9d6cb3f}{CURRENT\+\_\+\+LIMIT\+\_\+\+EU\+\_\+A}}~10.\+0f
\begin{DoxyCompactList}\small\item\em EU region current limit in amperes. \end{DoxyCompactList}\item 
\#define \mbox{\hyperlink{device__identity_8c_a5469cfad3f338029a3a1c9be8e5b1c32}{CURRENT\+\_\+\+LIMIT\+\_\+\+US\+\_\+A}}~15.\+0f
\begin{DoxyCompactList}\small\item\em US region current limit in amperes. \end{DoxyCompactList}\item 
\#define \mbox{\hyperlink{device__identity_8c_ac9c2918346c8c3193e85d3c54c72e073}{CURRENT\+\_\+\+LIMIT\+\_\+\+DEFAULT\+\_\+A}}~10.\+0f
\begin{DoxyCompactList}\small\item\em Default (safe) current limit for unknown region. \end{DoxyCompactList}\end{DoxyCompactItemize}
\doxysubsubsection*{Functions}
\begin{DoxyCompactItemize}
\item 
uint8\+\_\+t \mbox{\hyperlink{device__identity_8c_aae57a92db26b8a63b7584fd2f3407077}{calculate\+\_\+crc8}} (const uint8\+\_\+t \texorpdfstring{$\ast$}{*}data, size\+\_\+t len)
\begin{DoxyCompactList}\small\item\em Calculate CRC-\/8 checksum for data integrity verification. \end{DoxyCompactList}\item 
static uint8\+\_\+t \mbox{\hyperlink{device__identity_8c_a4306a3b02b924b2b64398df823662801}{calc\+\_\+identity\+\_\+crc\+\_\+raw}} (const uint8\+\_\+t \texorpdfstring{$\ast$}{*}raw)
\begin{DoxyCompactList}\small\item\em Calculate CRC-\/8 for device identity EEPROM block image. \end{DoxyCompactList}\item 
static bool \mbox{\hyperlink{device__identity_8c_a3739393f286b8d8676728762e42d9209}{is\+\_\+unlock\+\_\+window\+\_\+open}} (void)
\begin{DoxyCompactList}\small\item\em Check if the provisioning window is still open. \end{DoxyCompactList}\item 
static int \mbox{\hyperlink{device__identity_8c_a2d5fd96a7f281483c7a5623cf99d12a4}{read\+\_\+identity\+\_\+from\+\_\+eeprom}} (\mbox{\hyperlink{group__storage03_ga3d4f201eb84e7a480bb2455f5181bca0}{device\+\_\+identity\+\_\+eeprom\+\_\+t}} \texorpdfstring{$\ast$}{*}rec)
\begin{DoxyCompactList}\small\item\em Read device identity from EEPROM and validate CRC. \end{DoxyCompactList}\item 
static int \mbox{\hyperlink{device__identity_8c_aa849e09774fe6a45bb4479d2ee49c402}{write\+\_\+identity\+\_\+to\+\_\+eeprom}} (\mbox{\hyperlink{group__storage03_ga3d4f201eb84e7a480bb2455f5181bca0}{device\+\_\+identity\+\_\+eeprom\+\_\+t}} \texorpdfstring{$\ast$}{*}rec)
\begin{DoxyCompactList}\small\item\em Write device identity to EEPROM using the defined block image. \end{DoxyCompactList}\item 
static void \mbox{\hyperlink{device__identity_8c_a5b9e55cb62f389b33b1ba95030158cea}{update\+\_\+cache\+\_\+from\+\_\+record}} (const \mbox{\hyperlink{group__storage03_ga3d4f201eb84e7a480bb2455f5181bca0}{device\+\_\+identity\+\_\+eeprom\+\_\+t}} \texorpdfstring{$\ast$}{*}rec)
\begin{DoxyCompactList}\small\item\em Update RAM cache from EEPROM record. \end{DoxyCompactList}\item 
static bool \mbox{\hyperlink{device__identity_8c_a875fc468168b0fba722b907febc90ab1}{validate\+\_\+serial\+\_\+number}} (const char \texorpdfstring{$\ast$}{*}sn)
\begin{DoxyCompactList}\small\item\em Validate serial number string. \end{DoxyCompactList}\item 
static bool \mbox{\hyperlink{device__identity_8c_a9ae2b99dfda6e002ea479fac618edccf}{validate\+\_\+region}} (\mbox{\hyperlink{group__storage03_ga509a8b0630b9c754a52a817ba37e032b}{device\+\_\+region\+\_\+t}} region)
\begin{DoxyCompactList}\small\item\em Validate region code. \end{DoxyCompactList}\item 
void \mbox{\hyperlink{group__storage03_ga8a44399536e0b86e0b543df9f1962c17}{Device\+Identity\+\_\+\+Init}} (void)
\begin{DoxyCompactList}\small\item\em Initialize the device identity module. \end{DoxyCompactList}\item 
const \mbox{\hyperlink{structdevice__identity__t}{device\+\_\+identity\+\_\+t}} \texorpdfstring{$\ast$}{*} \mbox{\hyperlink{group__storage03_gad79ee3ecce363eec976ed7616906c27d}{Device\+Identity\+\_\+\+Get}} (void)
\begin{DoxyCompactList}\small\item\em Get pointer to the device identity RAM cache. \end{DoxyCompactList}\item 
const char \texorpdfstring{$\ast$}{*} \mbox{\hyperlink{group__storage03_gab09c3d3cce44235c32034cb03d64fbe4}{Device\+Identity\+\_\+\+Get\+Serial\+Number}} (void)
\begin{DoxyCompactList}\small\item\em Get the cached serial number string. \end{DoxyCompactList}\item 
\mbox{\hyperlink{group__storage03_ga509a8b0630b9c754a52a817ba37e032b}{device\+\_\+region\+\_\+t}} \mbox{\hyperlink{group__storage03_ga8159c9128e13ce5870ad6d282094ed83}{Device\+Identity\+\_\+\+Get\+Region}} (void)
\begin{DoxyCompactList}\small\item\em Get the cached device region. \end{DoxyCompactList}\item 
float \mbox{\hyperlink{group__storage03_ga5b4f82b48868c1a68c60a9fc9a7f3e37}{Device\+Identity\+\_\+\+Get\+Current\+LimitA}} (void)
\begin{DoxyCompactList}\small\item\em Get the current limit in amperes based on cached region. \end{DoxyCompactList}\item 
bool \mbox{\hyperlink{group__storage03_ga6a8334a56f37167d1e857260bb262902}{Device\+Identity\+\_\+\+Is\+Valid}} (void)
\begin{DoxyCompactList}\small\item\em Check if device identity is valid (provisioned). \end{DoxyCompactList}\item 
bool \mbox{\hyperlink{group__storage03_ga41878c484b104d5237c63deef71f450b}{Device\+Identity\+\_\+\+Unlock}} (const char \texorpdfstring{$\ast$}{*}token)
\begin{DoxyCompactList}\small\item\em Attempt to unlock provisioning with the given token. \end{DoxyCompactList}\item 
void \mbox{\hyperlink{group__storage03_ga2bf21d733d9d7a0292429bb3f6f144c3}{Device\+Identity\+\_\+\+Lock}} (void)
\begin{DoxyCompactList}\small\item\em Lock provisioning (close write window). \end{DoxyCompactList}\item 
bool \mbox{\hyperlink{group__storage03_ga11fd0a0d9d1c447246dc161cfa77f5aa}{Device\+Identity\+\_\+\+Is\+Unlocked}} (void)
\begin{DoxyCompactList}\small\item\em Check if provisioning is currently unlocked. \end{DoxyCompactList}\item 
int \mbox{\hyperlink{group__storage03_ga3ac2980af26af34986f7360246deefa5}{Device\+Identity\+\_\+\+Set\+Serial\+Number}} (const char \texorpdfstring{$\ast$}{*}serial\+\_\+number)
\begin{DoxyCompactList}\small\item\em Set the device serial number (requires unlock). \end{DoxyCompactList}\item 
int \mbox{\hyperlink{group__storage03_ga9f2f68ea0ff2c13d4fe5d52dc3a99e4f}{Device\+Identity\+\_\+\+Set\+Region}} (\mbox{\hyperlink{group__storage03_ga509a8b0630b9c754a52a817ba37e032b}{device\+\_\+region\+\_\+t}} region)
\begin{DoxyCompactList}\small\item\em Set the device region (requires unlock). \end{DoxyCompactList}\item 
void \mbox{\hyperlink{group__storage03_ga461c49efb137c6fcc9871867b974c326}{Device\+Identity\+\_\+\+Fill\+Mac}} (uint8\+\_\+t mac\mbox{[}6\mbox{]})
\begin{DoxyCompactList}\small\item\em Derive MAC address from the cached serial number. \end{DoxyCompactList}\end{DoxyCompactItemize}
\doxysubsubsection*{Variables}
\begin{DoxyCompactItemize}
\item 
static \mbox{\hyperlink{structdevice__identity__t}{device\+\_\+identity\+\_\+t}} \mbox{\hyperlink{device__identity_8c_a26fdc5b14d534266eedadfd06d55efe2}{s\+\_\+cache}}
\begin{DoxyCompactList}\small\item\em RAM cache for device identity. \end{DoxyCompactList}\item 
static volatile uint32\+\_\+t \mbox{\hyperlink{device__identity_8c_a3c1500b139d0b2aab909471e4090838c}{s\+\_\+unlock\+\_\+timestamp\+\_\+ms}} = 0
\begin{DoxyCompactList}\small\item\em Provisioning unlock timestamp (ms since boot). \end{DoxyCompactList}\item 
static volatile bool \mbox{\hyperlink{device__identity_8c_a12b03d71705ed949d1afdec2dcbf04b8}{s\+\_\+initialized}} = false
\begin{DoxyCompactList}\small\item\em Module initialized flag. \end{DoxyCompactList}\item 
Semaphore\+Handle\+\_\+t \mbox{\hyperlink{group__tasks10_gaf015228821869529545d62856625c224}{eeprom\+Mtx}}
\end{DoxyCompactItemize}

\doxysubsection{Detailed Description}
\begin{DoxyAuthor}{Author}
Dvid\+Makes\+Things -\/ David Sipos
\end{DoxyAuthor}
\begin{DoxyVersion}{Version}
1.\+0.\+1 
\end{DoxyVersion}
\begin{DoxyDate}{Date}
2025-\/12-\/14
\end{DoxyDate}
Implementation of device identity management module. Provides centralized storage and access for serial number and region settings with EEPROM persistence and RAM caching.

Thread Safety\+:
\begin{DoxyItemize}
\item Read operations are lock-\/free (atomic cache access)
\item Write operations acquire eeprom\+Mtx for EEPROM access
\item Unlock state uses atomic timestamp comparison
\end{DoxyItemize}

EEPROM Block Contract\+:
\begin{DoxyItemize}
\item EEPROM\+\_\+\+DEVICE\+\_\+\+IDENTITY\+\_\+\+START / EEPROM\+\_\+\+DEVICE\+\_\+\+IDENTITY\+\_\+\+SIZE define the stored block
\item Region is stored at offset 0x10, CRC at 0x11, pad at 0x12
\item CRC is calculated over bytes 0x00..0x10 (serial + region)
\item Pad byte is written deterministically as 0x00 for a stable block image
\end{DoxyItemize}

@project ENERGIS -\/ The Managed PDU Project for 10-\/Inch Rack @github \href{https://github.com/DvidMakesThings/HW_10-In-Rack_PDU}{\texttt{https\+://github.\+com/\+Dvid\+Makes\+Things/\+HW\+\_\+10-\/\+In-\/\+Rack\+\_\+\+PDU}} 

\label{doc-define-members}
\Hypertarget{device__identity_8c_doc-define-members}
\doxysubsection{Macro Definition Documentation}
\Hypertarget{device__identity_8c_ac9c2918346c8c3193e85d3c54c72e073}\index{device\_identity.c@{device\_identity.c}!CURRENT\_LIMIT\_DEFAULT\_A@{CURRENT\_LIMIT\_DEFAULT\_A}}
\index{CURRENT\_LIMIT\_DEFAULT\_A@{CURRENT\_LIMIT\_DEFAULT\_A}!device\_identity.c@{device\_identity.c}}
\doxysubsubsection{\texorpdfstring{CURRENT\_LIMIT\_DEFAULT\_A}{CURRENT\_LIMIT\_DEFAULT\_A}}
{\footnotesize\ttfamily \label{device__identity_8c_ac9c2918346c8c3193e85d3c54c72e073} 
\#define CURRENT\+\_\+\+LIMIT\+\_\+\+DEFAULT\+\_\+A~10.\+0f}

Default (safe) current limit for unknown region. 

\Hypertarget{device__identity_8c_a16e574655217d65f33296fd5c9d6cb3f}\index{device\_identity.c@{device\_identity.c}!CURRENT\_LIMIT\_EU\_A@{CURRENT\_LIMIT\_EU\_A}}
\index{CURRENT\_LIMIT\_EU\_A@{CURRENT\_LIMIT\_EU\_A}!device\_identity.c@{device\_identity.c}}
\doxysubsubsection{\texorpdfstring{CURRENT\_LIMIT\_EU\_A}{CURRENT\_LIMIT\_EU\_A}}
{\footnotesize\ttfamily \label{device__identity_8c_a16e574655217d65f33296fd5c9d6cb3f} 
\#define CURRENT\+\_\+\+LIMIT\+\_\+\+EU\+\_\+A~10.\+0f}

EU region current limit in amperes. 

\Hypertarget{device__identity_8c_a5469cfad3f338029a3a1c9be8e5b1c32}\index{device\_identity.c@{device\_identity.c}!CURRENT\_LIMIT\_US\_A@{CURRENT\_LIMIT\_US\_A}}
\index{CURRENT\_LIMIT\_US\_A@{CURRENT\_LIMIT\_US\_A}!device\_identity.c@{device\_identity.c}}
\doxysubsubsection{\texorpdfstring{CURRENT\_LIMIT\_US\_A}{CURRENT\_LIMIT\_US\_A}}
{\footnotesize\ttfamily \label{device__identity_8c_a5469cfad3f338029a3a1c9be8e5b1c32} 
\#define CURRENT\+\_\+\+LIMIT\+\_\+\+US\+\_\+A~15.\+0f}

US region current limit in amperes. 

\Hypertarget{device__identity_8c_a693d7c6a2e50da7b41c0b3ce4a15a34c}\index{device\_identity.c@{device\_identity.c}!DEVICE\_IDENTITY\_TAG@{DEVICE\_IDENTITY\_TAG}}
\index{DEVICE\_IDENTITY\_TAG@{DEVICE\_IDENTITY\_TAG}!device\_identity.c@{device\_identity.c}}
\doxysubsubsection{\texorpdfstring{DEVICE\_IDENTITY\_TAG}{DEVICE\_IDENTITY\_TAG}}
{\footnotesize\ttfamily \label{device__identity_8c_a693d7c6a2e50da7b41c0b3ce4a15a34c} 
\#define DEVICE\+\_\+\+IDENTITY\+\_\+\+TAG~"{}\mbox{[}DEV-\/ID\mbox{]}"{}}

\Hypertarget{device__identity_8c_abbaae20f896b1491508dc17ab1e3b6c4}\index{device\_identity.c@{device\_identity.c}!EEPROM\_DEVICE\_IDENTITY\_ADDR@{EEPROM\_DEVICE\_IDENTITY\_ADDR}}
\index{EEPROM\_DEVICE\_IDENTITY\_ADDR@{EEPROM\_DEVICE\_IDENTITY\_ADDR}!device\_identity.c@{device\_identity.c}}
\doxysubsubsection{\texorpdfstring{EEPROM\_DEVICE\_IDENTITY\_ADDR}{EEPROM\_DEVICE\_IDENTITY\_ADDR}}
{\footnotesize\ttfamily \label{device__identity_8c_abbaae20f896b1491508dc17ab1e3b6c4} 
\#define EEPROM\+\_\+\+DEVICE\+\_\+\+IDENTITY\+\_\+\+ADDR~\mbox{\hyperlink{group__config06_ga0b0b03d61ed2b7c416e0e8665598eb3f}{EEPROM\+\_\+\+DEVICE\+\_\+\+IDENTITY\+\_\+\+START}}}

EEPROM address for device identity record. 

Uses EEPROM layout defined in \doxylink{_e_e_p_r_o_m___memory_map_8h}{EEPROM\+\_\+\+Memory\+Map.\+h}. \Hypertarget{device__identity_8c_a0acf2e274a352da43a527642ce8562fd}\index{device\_identity.c@{device\_identity.c}!EEPROM\_DEVICE\_IDENTITY\_CRC\_LEN@{EEPROM\_DEVICE\_IDENTITY\_CRC\_LEN}}
\index{EEPROM\_DEVICE\_IDENTITY\_CRC\_LEN@{EEPROM\_DEVICE\_IDENTITY\_CRC\_LEN}!device\_identity.c@{device\_identity.c}}
\doxysubsubsection{\texorpdfstring{EEPROM\_DEVICE\_IDENTITY\_CRC\_LEN}{EEPROM\_DEVICE\_IDENTITY\_CRC\_LEN}}
{\footnotesize\ttfamily \label{device__identity_8c_a0acf2e274a352da43a527642ce8562fd} 
\#define EEPROM\+\_\+\+DEVICE\+\_\+\+IDENTITY\+\_\+\+CRC\+\_\+\+LEN~0x11u /\texorpdfstring{$\ast$}{*} 0x00..\+0x10 inclusive =$>$ 17 bytes \texorpdfstring{$\ast$}{*}/}

Number of bytes covered by CRC calculation (serial + region). 

\Hypertarget{device__identity_8c_a1618e0e52c6c528ccfe2fae354844f88}\index{device\_identity.c@{device\_identity.c}!EEPROM\_DEVICE\_IDENTITY\_CRC\_OFFSET@{EEPROM\_DEVICE\_IDENTITY\_CRC\_OFFSET}}
\index{EEPROM\_DEVICE\_IDENTITY\_CRC\_OFFSET@{EEPROM\_DEVICE\_IDENTITY\_CRC\_OFFSET}!device\_identity.c@{device\_identity.c}}
\doxysubsubsection{\texorpdfstring{EEPROM\_DEVICE\_IDENTITY\_CRC\_OFFSET}{EEPROM\_DEVICE\_IDENTITY\_CRC\_OFFSET}}
{\footnotesize\ttfamily \label{device__identity_8c_a1618e0e52c6c528ccfe2fae354844f88} 
\#define EEPROM\+\_\+\+DEVICE\+\_\+\+IDENTITY\+\_\+\+CRC\+\_\+\+OFFSET~0x11u}

Offset of CRC within identity EEPROM block. 

\Hypertarget{device__identity_8c_af08ec717a68641f395791d8b7f41474b}\index{device\_identity.c@{device\_identity.c}!EEPROM\_DEVICE\_IDENTITY\_PAD\_OFFSET@{EEPROM\_DEVICE\_IDENTITY\_PAD\_OFFSET}}
\index{EEPROM\_DEVICE\_IDENTITY\_PAD\_OFFSET@{EEPROM\_DEVICE\_IDENTITY\_PAD\_OFFSET}!device\_identity.c@{device\_identity.c}}
\doxysubsubsection{\texorpdfstring{EEPROM\_DEVICE\_IDENTITY\_PAD\_OFFSET}{EEPROM\_DEVICE\_IDENTITY\_PAD\_OFFSET}}
{\footnotesize\ttfamily \label{device__identity_8c_af08ec717a68641f395791d8b7f41474b} 
\#define EEPROM\+\_\+\+DEVICE\+\_\+\+IDENTITY\+\_\+\+PAD\+\_\+\+OFFSET~0x12u}

Offset of reserved pad within identity EEPROM block. 

\Hypertarget{device__identity_8c_a48f56dfea37a13b773d43067947bf70d}\index{device\_identity.c@{device\_identity.c}!EEPROM\_DEVICE\_IDENTITY\_REGION\_OFFSET@{EEPROM\_DEVICE\_IDENTITY\_REGION\_OFFSET}}
\index{EEPROM\_DEVICE\_IDENTITY\_REGION\_OFFSET@{EEPROM\_DEVICE\_IDENTITY\_REGION\_OFFSET}!device\_identity.c@{device\_identity.c}}
\doxysubsubsection{\texorpdfstring{EEPROM\_DEVICE\_IDENTITY\_REGION\_OFFSET}{EEPROM\_DEVICE\_IDENTITY\_REGION\_OFFSET}}
{\footnotesize\ttfamily \label{device__identity_8c_a48f56dfea37a13b773d43067947bf70d} 
\#define EEPROM\+\_\+\+DEVICE\+\_\+\+IDENTITY\+\_\+\+REGION\+\_\+\+OFFSET~0x10u}

Offset of region within identity EEPROM block. 

\Hypertarget{device__identity_8c_a66bed1308b249cda5e4afd5fc5852c21}\index{device\_identity.c@{device\_identity.c}!EEPROM\_DEVICE\_IDENTITY\_TOTAL\_SIZE@{EEPROM\_DEVICE\_IDENTITY\_TOTAL\_SIZE}}
\index{EEPROM\_DEVICE\_IDENTITY\_TOTAL\_SIZE@{EEPROM\_DEVICE\_IDENTITY\_TOTAL\_SIZE}!device\_identity.c@{device\_identity.c}}
\doxysubsubsection{\texorpdfstring{EEPROM\_DEVICE\_IDENTITY\_TOTAL\_SIZE}{EEPROM\_DEVICE\_IDENTITY\_TOTAL\_SIZE}}
{\footnotesize\ttfamily \label{device__identity_8c_a66bed1308b249cda5e4afd5fc5852c21} 
\#define EEPROM\+\_\+\+DEVICE\+\_\+\+IDENTITY\+\_\+\+TOTAL\+\_\+\+SIZE~\mbox{\hyperlink{group__config06_ga226676d435b8ea7dc26213a892abc464}{EEPROM\+\_\+\+DEVICE\+\_\+\+IDENTITY\+\_\+\+SIZE}}}

Total size of device identity EEPROM block. 

Uses EEPROM layout defined in \doxylink{_e_e_p_r_o_m___memory_map_8h}{EEPROM\+\_\+\+Memory\+Map.\+h} (includes pad byte). 

\label{doc-func-members}
\Hypertarget{device__identity_8c_doc-func-members}
\doxysubsection{Function Documentation}
\Hypertarget{device__identity_8c_a4306a3b02b924b2b64398df823662801}\index{device\_identity.c@{device\_identity.c}!calc\_identity\_crc\_raw@{calc\_identity\_crc\_raw}}
\index{calc\_identity\_crc\_raw@{calc\_identity\_crc\_raw}!device\_identity.c@{device\_identity.c}}
\doxysubsubsection{\texorpdfstring{calc\_identity\_crc\_raw()}{calc\_identity\_crc\_raw()}}
{\footnotesize\ttfamily \label{device__identity_8c_a4306a3b02b924b2b64398df823662801} 
uint8\+\_\+t calc\+\_\+identity\+\_\+crc\+\_\+raw (\begin{DoxyParamCaption}\item[{const uint8\+\_\+t \texorpdfstring{$\ast$}{*}}]{raw}{}\end{DoxyParamCaption})\hspace{0.3cm}{\ttfamily [static]}}

Calculate CRC-\/8 for device identity EEPROM block image. 

CRC is calculated over bytes 0x00..0x10 (serial + region), and stored at offset 0x11.

\begin{DoxyParams}{Parameters}
{\em raw} & Pointer to raw EEPROM block image. \\
\hline
\end{DoxyParams}
\begin{DoxyReturn}{Returns}
Calculated CRC-\/8 value. 
\end{DoxyReturn}
Here is the call graph for this function\+:\nopagebreak
\begin{figure}[H]
\begin{center}
\leavevmode

\end{center}
\end{figure}
Here is the caller graph for this function\+:\nopagebreak
\begin{figure}[H]
\begin{center}
\leavevmode

\end{center}
\end{figure}
\Hypertarget{device__identity_8c_aae57a92db26b8a63b7584fd2f3407077}\index{device\_identity.c@{device\_identity.c}!calculate\_crc8@{calculate\_crc8}}
\index{calculate\_crc8@{calculate\_crc8}!device\_identity.c@{device\_identity.c}}
\doxysubsubsection{\texorpdfstring{calculate\_crc8()}{calculate\_crc8()}}
{\footnotesize\ttfamily \label{device__identity_8c_aae57a92db26b8a63b7584fd2f3407077} 
uint8\+\_\+t calculate\+\_\+crc8 (\begin{DoxyParamCaption}\item[{const uint8\+\_\+t \texorpdfstring{$\ast$}{*}}]{data}{, }\item[{size\+\_\+t}]{len}{}\end{DoxyParamCaption})\hspace{0.3cm}{\ttfamily [extern]}}

Calculate CRC-\/8 checksum for data integrity verification. 

See \doxylink{storage__common_8h}{storage\+\_\+common.\+h} for full API documentation. Here is the caller graph for this function\+:\nopagebreak
\begin{figure}[H]
\begin{center}
\leavevmode
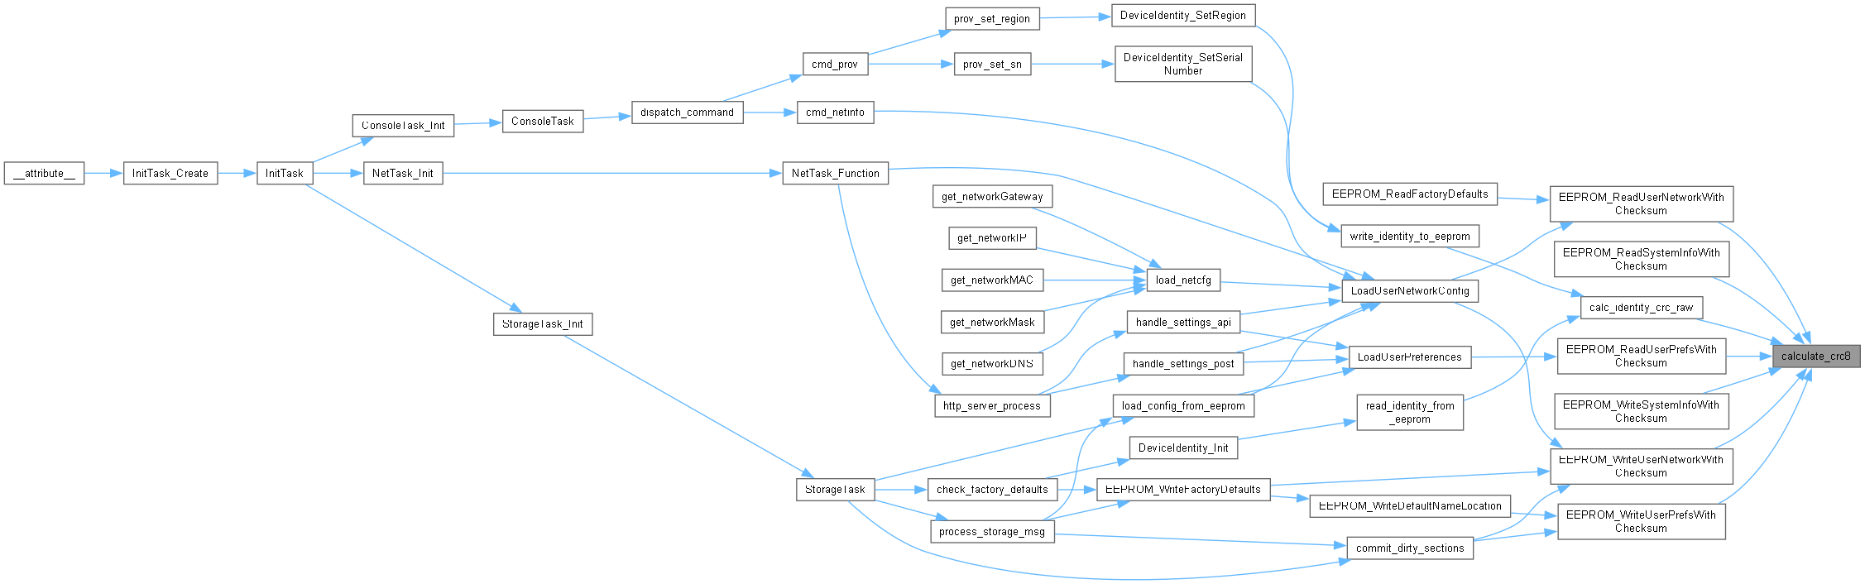
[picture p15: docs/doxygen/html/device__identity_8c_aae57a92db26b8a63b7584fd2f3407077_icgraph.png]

\end{center}
\end{figure}
\Hypertarget{device__identity_8c_a3739393f286b8d8676728762e42d9209}\index{device\_identity.c@{device\_identity.c}!is\_unlock\_window\_open@{is\_unlock\_window\_open}}
\index{is\_unlock\_window\_open@{is\_unlock\_window\_open}!device\_identity.c@{device\_identity.c}}
\doxysubsubsection{\texorpdfstring{is\_unlock\_window\_open()}{is\_unlock\_window\_open()}}
{\footnotesize\ttfamily \label{device__identity_8c_a3739393f286b8d8676728762e42d9209} 
bool is\+\_\+unlock\+\_\+window\+\_\+open (\begin{DoxyParamCaption}\item[{void}]{}{}\end{DoxyParamCaption})\hspace{0.3cm}{\ttfamily [static]}}

Check if the provisioning window is still open. 

\begin{DoxyReturn}{Returns}
true if unlocked and within timeout window. 
\end{DoxyReturn}
Here is the call graph for this function\+:\nopagebreak
\begin{figure}[H]
\begin{center}
\leavevmode

\end{center}
\end{figure}
Here is the caller graph for this function\+:\nopagebreak
\begin{figure}[H]
\begin{center}
\leavevmode

\end{center}
\end{figure}
\Hypertarget{device__identity_8c_a2d5fd96a7f281483c7a5623cf99d12a4}\index{device\_identity.c@{device\_identity.c}!read\_identity\_from\_eeprom@{read\_identity\_from\_eeprom}}
\index{read\_identity\_from\_eeprom@{read\_identity\_from\_eeprom}!device\_identity.c@{device\_identity.c}}
\doxysubsubsection{\texorpdfstring{read\_identity\_from\_eeprom()}{read\_identity\_from\_eeprom()}}
{\footnotesize\ttfamily \label{device__identity_8c_a2d5fd96a7f281483c7a5623cf99d12a4} 
int read\+\_\+identity\+\_\+from\+\_\+eeprom (\begin{DoxyParamCaption}\item[{\mbox{\hyperlink{group__storage03_ga3d4f201eb84e7a480bb2455f5181bca0}{device\+\_\+identity\+\_\+eeprom\+\_\+t}} \texorpdfstring{$\ast$}{*}}]{rec}{}\end{DoxyParamCaption})\hspace{0.3cm}{\ttfamily [static]}}

Read device identity from EEPROM and validate CRC. 

\begin{DoxyParams}{Parameters}
{\em rec} & Destination buffer for parsed EEPROM fields. \\
\hline
\end{DoxyParams}
\begin{DoxyReturn}{Returns}
0 on success with valid CRC, -\/1 on CRC mismatch or read error.
\end{DoxyReturn}
\begin{DoxyNote}{Note}
Must be called with eeprom\+Mtx held. 
\end{DoxyNote}
Here is the call graph for this function\+:\nopagebreak
\begin{figure}[H]
\begin{center}
\leavevmode

\end{center}
\end{figure}
Here is the caller graph for this function\+:\nopagebreak
\begin{figure}[H]
\begin{center}
\leavevmode

\end{center}
\end{figure}
\Hypertarget{device__identity_8c_a5b9e55cb62f389b33b1ba95030158cea}\index{device\_identity.c@{device\_identity.c}!update\_cache\_from\_record@{update\_cache\_from\_record}}
\index{update\_cache\_from\_record@{update\_cache\_from\_record}!device\_identity.c@{device\_identity.c}}
\doxysubsubsection{\texorpdfstring{update\_cache\_from\_record()}{update\_cache\_from\_record()}}
{\footnotesize\ttfamily \label{device__identity_8c_a5b9e55cb62f389b33b1ba95030158cea} 
void update\+\_\+cache\+\_\+from\+\_\+record (\begin{DoxyParamCaption}\item[{const \mbox{\hyperlink{group__storage03_ga3d4f201eb84e7a480bb2455f5181bca0}{device\+\_\+identity\+\_\+eeprom\+\_\+t}} \texorpdfstring{$\ast$}{*}}]{rec}{}\end{DoxyParamCaption})\hspace{0.3cm}{\ttfamily [static]}}

Update RAM cache from EEPROM record. 

\begin{DoxyParams}{Parameters}
{\em rec} & Validated EEPROM record. \\
\hline
\end{DoxyParams}
Here is the caller graph for this function\+:\nopagebreak
\begin{figure}[H]
\begin{center}
\leavevmode

\end{center}
\end{figure}
\Hypertarget{device__identity_8c_a9ae2b99dfda6e002ea479fac618edccf}\index{device\_identity.c@{device\_identity.c}!validate\_region@{validate\_region}}
\index{validate\_region@{validate\_region}!device\_identity.c@{device\_identity.c}}
\doxysubsubsection{\texorpdfstring{validate\_region()}{validate\_region()}}
{\footnotesize\ttfamily \label{device__identity_8c_a9ae2b99dfda6e002ea479fac618edccf} 
bool validate\+\_\+region (\begin{DoxyParamCaption}\item[{\mbox{\hyperlink{group__storage03_ga509a8b0630b9c754a52a817ba37e032b}{device\+\_\+region\+\_\+t}}}]{region}{}\end{DoxyParamCaption})\hspace{0.3cm}{\ttfamily [static]}}

Validate region code. 

\begin{DoxyParams}{Parameters}
{\em region} & Region code to validate. \\
\hline
\end{DoxyParams}
\begin{DoxyReturn}{Returns}
true if valid, false otherwise. 
\end{DoxyReturn}
Here is the caller graph for this function\+:\nopagebreak
\begin{figure}[H]
\begin{center}
\leavevmode

\end{center}
\end{figure}
\Hypertarget{device__identity_8c_a875fc468168b0fba722b907febc90ab1}\index{device\_identity.c@{device\_identity.c}!validate\_serial\_number@{validate\_serial\_number}}
\index{validate\_serial\_number@{validate\_serial\_number}!device\_identity.c@{device\_identity.c}}
\doxysubsubsection{\texorpdfstring{validate\_serial\_number()}{validate\_serial\_number()}}
{\footnotesize\ttfamily \label{device__identity_8c_a875fc468168b0fba722b907febc90ab1} 
bool validate\+\_\+serial\+\_\+number (\begin{DoxyParamCaption}\item[{const char \texorpdfstring{$\ast$}{*}}]{sn}{}\end{DoxyParamCaption})\hspace{0.3cm}{\ttfamily [static]}}

Validate serial number string. 

\begin{DoxyParams}{Parameters}
{\em sn} & Serial number string to validate. \\
\hline
\end{DoxyParams}
\begin{DoxyReturn}{Returns}
true if valid, false otherwise. 
\end{DoxyReturn}
Here is the caller graph for this function\+:\nopagebreak
\begin{figure}[H]
\begin{center}
\leavevmode

\end{center}
\end{figure}
\Hypertarget{device__identity_8c_aa849e09774fe6a45bb4479d2ee49c402}\index{device\_identity.c@{device\_identity.c}!write\_identity\_to\_eeprom@{write\_identity\_to\_eeprom}}
\index{write\_identity\_to\_eeprom@{write\_identity\_to\_eeprom}!device\_identity.c@{device\_identity.c}}
\doxysubsubsection{\texorpdfstring{write\_identity\_to\_eeprom()}{write\_identity\_to\_eeprom()}}
{\footnotesize\ttfamily \label{device__identity_8c_aa849e09774fe6a45bb4479d2ee49c402} 
int write\+\_\+identity\+\_\+to\+\_\+eeprom (\begin{DoxyParamCaption}\item[{\mbox{\hyperlink{group__storage03_ga3d4f201eb84e7a480bb2455f5181bca0}{device\+\_\+identity\+\_\+eeprom\+\_\+t}} \texorpdfstring{$\ast$}{*}}]{rec}{}\end{DoxyParamCaption})\hspace{0.3cm}{\ttfamily [static]}}

Write device identity to EEPROM using the defined block image. 

\begin{DoxyParams}{Parameters}
{\em rec} & Source record to write (CRC will be calculated and set). \\
\hline
\end{DoxyParams}
\begin{DoxyReturn}{Returns}
0 on success, -\/1 on write error.
\end{DoxyReturn}
\begin{DoxyNote}{Note}
Must be called with eeprom\+Mtx held. 
\end{DoxyNote}
Here is the call graph for this function\+:\nopagebreak
\begin{figure}[H]
\begin{center}
\leavevmode

\end{center}
\end{figure}
Here is the caller graph for this function\+:\nopagebreak
\begin{figure}[H]
\begin{center}
\leavevmode

\end{center}
\end{figure}

\label{doc-var-members}
\Hypertarget{device__identity_8c_doc-var-members}
\doxysubsection{Variable Documentation}
\Hypertarget{device__identity_8c_a26fdc5b14d534266eedadfd06d55efe2}\index{device\_identity.c@{device\_identity.c}!s\_cache@{s\_cache}}
\index{s\_cache@{s\_cache}!device\_identity.c@{device\_identity.c}}
\doxysubsubsection{\texorpdfstring{s\_cache}{s\_cache}}
{\footnotesize\ttfamily \label{device__identity_8c_a26fdc5b14d534266eedadfd06d55efe2} 
\mbox{\hyperlink{structdevice__identity__t}{device\+\_\+identity\+\_\+t}} s\+\_\+cache\hspace{0.3cm}{\ttfamily [static]}}

{\bfseries Initial value\+:}
\begin{DoxyCode}{0}
\DoxyCodeLine{=\ \{}
\DoxyCodeLine{\ \ \ \ .serial\_number\ =\ \textcolor{stringliteral}{"{}UNPROVISIONED"{}},\ .region\ =\ \mbox{\hyperlink{group__storage03_gga509a8b0630b9c754a52a817ba37e032ba07eea1ebaa36d551f30f56c30b308d57}{DEVICE\_REGION\_UNKNOWN}},\ .valid\ =\ \textcolor{keyword}{false}\}}

\end{DoxyCode}

RAM cache for device identity. 

Populated at init, updated by provisioning writes. \Hypertarget{device__identity_8c_a12b03d71705ed949d1afdec2dcbf04b8}\index{device\_identity.c@{device\_identity.c}!s\_initialized@{s\_initialized}}
\index{s\_initialized@{s\_initialized}!device\_identity.c@{device\_identity.c}}
\doxysubsubsection{\texorpdfstring{s\_initialized}{s\_initialized}}
{\footnotesize\ttfamily \label{device__identity_8c_a12b03d71705ed949d1afdec2dcbf04b8} 
volatile bool s\+\_\+initialized = false\hspace{0.3cm}{\ttfamily [static]}}

Module initialized flag. 

\Hypertarget{device__identity_8c_a3c1500b139d0b2aab909471e4090838c}\index{device\_identity.c@{device\_identity.c}!s\_unlock\_timestamp\_ms@{s\_unlock\_timestamp\_ms}}
\index{s\_unlock\_timestamp\_ms@{s\_unlock\_timestamp\_ms}!device\_identity.c@{device\_identity.c}}
\doxysubsubsection{\texorpdfstring{s\_unlock\_timestamp\_ms}{s\_unlock\_timestamp\_ms}}
{\footnotesize\ttfamily \label{device__identity_8c_a3c1500b139d0b2aab909471e4090838c} 
volatile uint32\+\_\+t s\+\_\+unlock\+\_\+timestamp\+\_\+ms = 0\hspace{0.3cm}{\ttfamily [static]}}

Provisioning unlock timestamp (ms since boot). 

Set when unlock succeeds. 0 means locked.

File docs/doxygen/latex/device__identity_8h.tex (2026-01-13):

\doxysection{src/\+Software/\+ENERGIS\+\_\+\+RTOS/src/tasks/storage\+\_\+submodule/device\+\_\+identity.h File Reference}
\hypertarget{device__identity_8h}{}\label{device__identity_8h}\index{src/Software/ENERGIS\_RTOS/src/tasks/storage\_submodule/device\_identity.h@{src/Software/ENERGIS\_RTOS/src/tasks/storage\_submodule/device\_identity.h}}
{\ttfamily \#include $<$stdbool.\+h$>$}\newline
{\ttfamily \#include $<$stdint.\+h$>$}\newline
Include dependency graph for device\+\_\+identity.\+h\+:\nopagebreak
\begin{figure}[H]
\begin{center}
\leavevmode
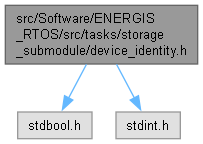
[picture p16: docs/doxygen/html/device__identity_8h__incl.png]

\end{center}
\end{figure}
This graph shows which files directly or indirectly include this file\+:\nopagebreak
\begin{figure}[H]
\begin{center}
\leavevmode
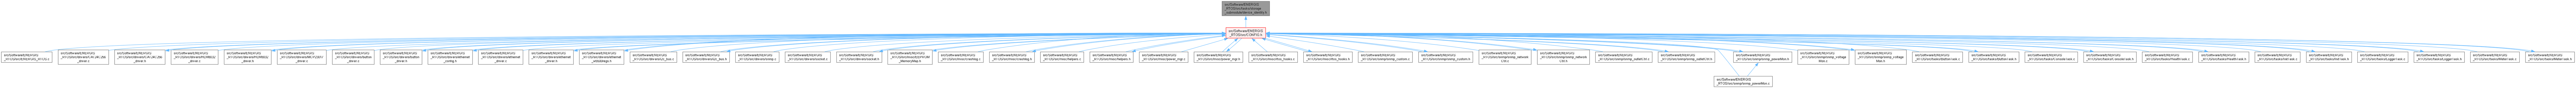
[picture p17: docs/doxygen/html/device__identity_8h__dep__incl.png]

\end{center}
\end{figure}
\doxysubsubsection*{Classes}
\begin{DoxyCompactItemize}
\item 
struct \mbox{\hyperlink{structdevice__identity__t}{device\+\_\+identity\+\_\+t}}
\begin{DoxyCompactList}\small\item\em Device identity RAM cache structure. \end{DoxyCompactList}\end{DoxyCompactItemize}
\doxysubsubsection*{Macros}
\begin{DoxyCompactItemize}
\item 
\#define \mbox{\hyperlink{group__storage03_ga873a1b4db5414ab4ac986547e952f2fe}{DEVICE\+\_\+\+SN\+\_\+\+MAX\+\_\+\+LEN}}~15
\begin{DoxyCompactList}\small\item\em Maximum length of serial number string (excluding null terminator). \end{DoxyCompactList}\item 
\#define \mbox{\hyperlink{group__storage03_gae4d74f9ef4f807b438ff2aee66b55350}{PROV\+\_\+\+UNLOCK\+\_\+\+TOKEN}}~"{}6D61676963"{}
\begin{DoxyCompactList}\small\item\em Provisioning unlock token (hex string). \end{DoxyCompactList}\item 
\#define \mbox{\hyperlink{group__storage03_gaf11aaae114cd0c1c20eb730929d2fbc8}{PROV\+\_\+\+UNLOCK\+\_\+\+TIMEOUT\+\_\+\+MS}}~60000
\begin{DoxyCompactList}\small\item\em Provisioning unlock timeout in milliseconds. \end{DoxyCompactList}\end{DoxyCompactItemize}
\doxysubsubsection*{Enumerations}
\begin{DoxyCompactItemize}
\item 
enum \mbox{\hyperlink{group__storage03_ga509a8b0630b9c754a52a817ba37e032b}{device\+\_\+region\+\_\+t}} \{ \mbox{\hyperlink{group__storage03_gga509a8b0630b9c754a52a817ba37e032ba07eea1ebaa36d551f30f56c30b308d57}{DEVICE\+\_\+\+REGION\+\_\+\+UNKNOWN}} = 0x00
, \mbox{\hyperlink{group__storage03_gga509a8b0630b9c754a52a817ba37e032ba0b78a74641c8e6c2b2754eef80ab4aeb}{DEVICE\+\_\+\+REGION\+\_\+\+EU}} = 0x45
, \mbox{\hyperlink{group__storage03_gga509a8b0630b9c754a52a817ba37e032bac833b1f9e2f5832aef5b89fe71fa8abe}{DEVICE\+\_\+\+REGION\+\_\+\+US}} = 0x55
 \}
\begin{DoxyCompactList}\small\item\em Device region enumeration. \end{DoxyCompactList}\end{DoxyCompactItemize}
\doxysubsubsection*{Functions}
\begin{DoxyCompactItemize}
\item 
struct \mbox{\hyperlink{group__storage03_gab898071398b359603a35c202e9c65f3b}{\+\_\+\+\_\+attribute\+\_\+\+\_\+}} ((packed))
\begin{DoxyCompactList}\small\item\em Device identity EEPROM payload fields (without reserved pad). \end{DoxyCompactList}\item 
void \mbox{\hyperlink{group__storage03_ga8a44399536e0b86e0b543df9f1962c17}{Device\+Identity\+\_\+\+Init}} (void)
\begin{DoxyCompactList}\small\item\em Initialize the device identity module. \end{DoxyCompactList}\item 
const \mbox{\hyperlink{structdevice__identity__t}{device\+\_\+identity\+\_\+t}} \texorpdfstring{$\ast$}{*} \mbox{\hyperlink{group__storage03_gad79ee3ecce363eec976ed7616906c27d}{Device\+Identity\+\_\+\+Get}} (void)
\begin{DoxyCompactList}\small\item\em Get pointer to the device identity RAM cache. \end{DoxyCompactList}\item 
const char \texorpdfstring{$\ast$}{*} \mbox{\hyperlink{group__storage03_gab09c3d3cce44235c32034cb03d64fbe4}{Device\+Identity\+\_\+\+Get\+Serial\+Number}} (void)
\begin{DoxyCompactList}\small\item\em Get the cached serial number string. \end{DoxyCompactList}\item 
\mbox{\hyperlink{group__storage03_ga509a8b0630b9c754a52a817ba37e032b}{device\+\_\+region\+\_\+t}} \mbox{\hyperlink{group__storage03_ga8159c9128e13ce5870ad6d282094ed83}{Device\+Identity\+\_\+\+Get\+Region}} (void)
\begin{DoxyCompactList}\small\item\em Get the cached device region. \end{DoxyCompactList}\item 
float \mbox{\hyperlink{group__storage03_ga5b4f82b48868c1a68c60a9fc9a7f3e37}{Device\+Identity\+\_\+\+Get\+Current\+LimitA}} (void)
\begin{DoxyCompactList}\small\item\em Get the current limit in amperes based on cached region. \end{DoxyCompactList}\item 
bool \mbox{\hyperlink{group__storage03_ga6a8334a56f37167d1e857260bb262902}{Device\+Identity\+\_\+\+Is\+Valid}} (void)
\begin{DoxyCompactList}\small\item\em Check if device identity is valid (provisioned). \end{DoxyCompactList}\item 
bool \mbox{\hyperlink{group__storage03_ga41878c484b104d5237c63deef71f450b}{Device\+Identity\+\_\+\+Unlock}} (const char \texorpdfstring{$\ast$}{*}token)
\begin{DoxyCompactList}\small\item\em Attempt to unlock provisioning with the given token. \end{DoxyCompactList}\item 
void \mbox{\hyperlink{group__storage03_ga2bf21d733d9d7a0292429bb3f6f144c3}{Device\+Identity\+\_\+\+Lock}} (void)
\begin{DoxyCompactList}\small\item\em Lock provisioning (close write window). \end{DoxyCompactList}\item 
bool \mbox{\hyperlink{group__storage03_ga11fd0a0d9d1c447246dc161cfa77f5aa}{Device\+Identity\+\_\+\+Is\+Unlocked}} (void)
\begin{DoxyCompactList}\small\item\em Check if provisioning is currently unlocked. \end{DoxyCompactList}\item 
int \mbox{\hyperlink{group__storage03_ga3ac2980af26af34986f7360246deefa5}{Device\+Identity\+\_\+\+Set\+Serial\+Number}} (const char \texorpdfstring{$\ast$}{*}serial\+\_\+number)
\begin{DoxyCompactList}\small\item\em Set the device serial number (requires unlock). \end{DoxyCompactList}\item 
int \mbox{\hyperlink{group__storage03_ga9f2f68ea0ff2c13d4fe5d52dc3a99e4f}{Device\+Identity\+\_\+\+Set\+Region}} (\mbox{\hyperlink{group__storage03_ga509a8b0630b9c754a52a817ba37e032b}{device\+\_\+region\+\_\+t}} region)
\begin{DoxyCompactList}\small\item\em Set the device region (requires unlock). \end{DoxyCompactList}\item 
void \mbox{\hyperlink{group__storage03_ga461c49efb137c6fcc9871867b974c326}{Device\+Identity\+\_\+\+Fill\+Mac}} (uint8\+\_\+t mac\mbox{[}6\mbox{]})
\begin{DoxyCompactList}\small\item\em Derive MAC address from the cached serial number. \end{DoxyCompactList}\end{DoxyCompactItemize}
\doxysubsubsection*{Variables}
\begin{DoxyCompactItemize}
\item 
\mbox{\hyperlink{group__storage03_ga3d4f201eb84e7a480bb2455f5181bca0}{device\+\_\+identity\+\_\+eeprom\+\_\+t}}
\end{DoxyCompactItemize}

\doxysubsection{Detailed Description}
\begin{DoxyAuthor}{Author}
Dvid\+Makes\+Things -\/ David Sipos 
\end{DoxyAuthor}

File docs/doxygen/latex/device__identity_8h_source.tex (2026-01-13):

\doxysection{device\+\_\+identity.\+h}
\hypertarget{device__identity_8h_source}{}\label{device__identity_8h_source}\index{src/Software/ENERGIS\_RTOS/src/tasks/storage\_submodule/device\_identity.h@{src/Software/ENERGIS\_RTOS/src/tasks/storage\_submodule/device\_identity.h}}
\mbox{\hyperlink{device__identity_8h}{Go to the documentation of this file.}}
\begin{DoxyCode}{0}
\DoxyCodeLine{00001\ }
\DoxyCodeLine{00036\ }
\DoxyCodeLine{00037\ \textcolor{preprocessor}{\#ifndef\ DEVICE\_IDENTITY\_H}}
\DoxyCodeLine{00038\ \textcolor{preprocessor}{\#define\ DEVICE\_IDENTITY\_H}}
\DoxyCodeLine{00039\ }
\DoxyCodeLine{00040\ \textcolor{preprocessor}{\#include\ <stdbool.h>}}
\DoxyCodeLine{00041\ \textcolor{preprocessor}{\#include\ <stdint.h>}}
\DoxyCodeLine{00042\ }
\DoxyCodeLine{00043\ \textcolor{comment}{/*\ ====================\ Configuration\ Constants\ ====================\ */}}
\DoxyCodeLine{00044\ }
\DoxyCodeLine{00048\ \textcolor{preprocessor}{\#define\ DEVICE\_SN\_MAX\_LEN\ 15}}
\DoxyCodeLine{00049\ }
\DoxyCodeLine{00054\ \textcolor{preprocessor}{\#define\ PROV\_UNLOCK\_TOKEN\ "{}6D61676963"{}}}
\DoxyCodeLine{00055\ }
\DoxyCodeLine{00060\ \textcolor{preprocessor}{\#define\ PROV\_UNLOCK\_TIMEOUT\_MS\ 60000}}
\DoxyCodeLine{00061\ }
\DoxyCodeLine{00062\ \textcolor{comment}{/*\ ====================\ Type\ Definitions\ ====================\ */}}
\DoxyCodeLine{00063\ }
\DoxyCodeLine{00070\ \textcolor{keyword}{typedef}\ \textcolor{keyword}{enum}\ \{}
\DoxyCodeLine{00071\ \ \ \ \ \mbox{\hyperlink{group__storage03_gga509a8b0630b9c754a52a817ba37e032ba07eea1ebaa36d551f30f56c30b308d57}{DEVICE\_REGION\_UNKNOWN}}\ =\ 0x00,\ }
\DoxyCodeLine{00072\ \ \ \ \ \mbox{\hyperlink{group__storage03_gga509a8b0630b9c754a52a817ba37e032ba0b78a74641c8e6c2b2754eef80ab4aeb}{DEVICE\_REGION\_EU}}\ =\ 0x45,\ \ \ \ \ \ }
\DoxyCodeLine{00073\ \ \ \ \ \mbox{\hyperlink{group__storage03_gga509a8b0630b9c754a52a817ba37e032bac833b1f9e2f5832aef5b89fe71fa8abe}{DEVICE\_REGION\_US}}\ =\ 0x55\ \ \ \ \ \ \ }
\DoxyCodeLine{00074\ \}\ \mbox{\hyperlink{group__storage03_ga509a8b0630b9c754a52a817ba37e032b}{device\_region\_t}};}
\DoxyCodeLine{00075\ }
\DoxyCodeLine{00081\ \textcolor{keyword}{typedef}\ \textcolor{keyword}{struct\ }\{}
\DoxyCodeLine{00082\ \ \ \ \ \textcolor{keywordtype}{char}\ \mbox{\hyperlink{structdevice__identity__t_a445c8cbdfe1742a5b1bb7f140b461e44}{serial\_number}}[\mbox{\hyperlink{group__storage03_ga873a1b4db5414ab4ac986547e952f2fe}{DEVICE\_SN\_MAX\_LEN}}\ +\ 1];\ }
\DoxyCodeLine{00083\ \ \ \ \ \mbox{\hyperlink{group__storage03_ga509a8b0630b9c754a52a817ba37e032b}{device\_region\_t}}\ \mbox{\hyperlink{structdevice__identity__t_a4cbac26f3bb492b953eab3a01d9153de}{region}};\ \ \ \ \ \ \ \ \ \ \ \ \ \ \ \ \ \ \ \ }
\DoxyCodeLine{00084\ \ \ \ \ \textcolor{keywordtype}{bool}\ \mbox{\hyperlink{structdevice__identity__t_aaaf972ee283f2cf88a6f57a20bec03d8}{valid}};\ \ \ \ \ \ \ \ \ \ \ \ \ \ \ \ \ \ \ \ \ \ \ \ \ \ \ \ \ \ \ \ }
\DoxyCodeLine{00085\ \}\ \mbox{\hyperlink{structdevice__identity__t}{device\_identity\_t}};}
\DoxyCodeLine{00086\ }
\DoxyCodeLine{00097\ \textcolor{keyword}{typedef}\ \textcolor{keyword}{struct\ }\mbox{\hyperlink{group__main01_gae3fa85d0ce445e937670de85f9af490a}{\_\_attribute\_\_}}((packed))\ \{}
\DoxyCodeLine{00098\ \ \ \ \ \textcolor{keywordtype}{char}\ serial\_number[\mbox{\hyperlink{group__storage03_ga873a1b4db5414ab4ac986547e952f2fe}{DEVICE\_SN\_MAX\_LEN}}\ +\ 1];\ }
\DoxyCodeLine{00099\ \ \ \ \ uint8\_t\ region;\ \ \ \ \ \ \ \ \ \ \ \ \ \ \ \ \ \ \ \ \ \ \ \ \ \ \ \ }
\DoxyCodeLine{00100\ \ \ \ \ uint8\_t\ crc;\ \ \ \ \ \ \ \ \ \ \ \ \ \ \ \ \ \ \ \ \ \ \ \ \ \ \ \ \ \ \ }
\DoxyCodeLine{00101\ \}\ \mbox{\hyperlink{group__storage03_ga3d4f201eb84e7a480bb2455f5181bca0}{device\_identity\_eeprom\_t}};}
\DoxyCodeLine{00102\ }
\DoxyCodeLine{00103\ \textcolor{comment}{/*\ ====================\ Public\ API\ -\/\ Initialization\ ====================\ */}}
\DoxyCodeLine{00104\ }
\DoxyCodeLine{00118\ \textcolor{keywordtype}{void}\ \mbox{\hyperlink{group__storage03_ga8a44399536e0b86e0b543df9f1962c17}{DeviceIdentity\_Init}}(\textcolor{keywordtype}{void});}
\DoxyCodeLine{00119\ }
\DoxyCodeLine{00120\ \textcolor{comment}{/*\ ====================\ Public\ API\ -\/\ Read\ Access\ ====================\ */}}
\DoxyCodeLine{00121\ }
\DoxyCodeLine{00127\ \textcolor{keyword}{const}\ \mbox{\hyperlink{structdevice__identity__t}{device\_identity\_t}}\ *\mbox{\hyperlink{group__storage03_gad79ee3ecce363eec976ed7616906c27d}{DeviceIdentity\_Get}}(\textcolor{keywordtype}{void});}
\DoxyCodeLine{00128\ }
\DoxyCodeLine{00134\ \textcolor{keyword}{const}\ \textcolor{keywordtype}{char}\ *\mbox{\hyperlink{group__storage03_gab09c3d3cce44235c32034cb03d64fbe4}{DeviceIdentity\_GetSerialNumber}}(\textcolor{keywordtype}{void});}
\DoxyCodeLine{00135\ }
\DoxyCodeLine{00141\ \mbox{\hyperlink{group__storage03_ga509a8b0630b9c754a52a817ba37e032b}{device\_region\_t}}\ \mbox{\hyperlink{group__storage03_ga8159c9128e13ce5870ad6d282094ed83}{DeviceIdentity\_GetRegion}}(\textcolor{keywordtype}{void});}
\DoxyCodeLine{00142\ }
\DoxyCodeLine{00148\ \textcolor{keywordtype}{float}\ \mbox{\hyperlink{group__storage03_ga5b4f82b48868c1a68c60a9fc9a7f3e37}{DeviceIdentity\_GetCurrentLimitA}}(\textcolor{keywordtype}{void});}
\DoxyCodeLine{00149\ }
\DoxyCodeLine{00155\ \textcolor{keywordtype}{bool}\ \mbox{\hyperlink{group__storage03_ga6a8334a56f37167d1e857260bb262902}{DeviceIdentity\_IsValid}}(\textcolor{keywordtype}{void});}
\DoxyCodeLine{00156\ }
\DoxyCodeLine{00157\ \textcolor{comment}{/*\ ====================\ Public\ API\ -\/\ Provisioning\ ====================\ */}}
\DoxyCodeLine{00158\ }
\DoxyCodeLine{00165\ \textcolor{keywordtype}{bool}\ \mbox{\hyperlink{group__storage03_ga41878c484b104d5237c63deef71f450b}{DeviceIdentity\_Unlock}}(\textcolor{keyword}{const}\ \textcolor{keywordtype}{char}\ *token);}
\DoxyCodeLine{00166\ }
\DoxyCodeLine{00170\ \textcolor{keywordtype}{void}\ \mbox{\hyperlink{group__storage03_ga2bf21d733d9d7a0292429bb3f6f144c3}{DeviceIdentity\_Lock}}(\textcolor{keywordtype}{void});}
\DoxyCodeLine{00171\ }
\DoxyCodeLine{00177\ \textcolor{keywordtype}{bool}\ \mbox{\hyperlink{group__storage03_ga11fd0a0d9d1c447246dc161cfa77f5aa}{DeviceIdentity\_IsUnlocked}}(\textcolor{keywordtype}{void});}
\DoxyCodeLine{00178\ }
\DoxyCodeLine{00185\ \textcolor{keywordtype}{int}\ \mbox{\hyperlink{group__storage03_ga3ac2980af26af34986f7360246deefa5}{DeviceIdentity\_SetSerialNumber}}(\textcolor{keyword}{const}\ \textcolor{keywordtype}{char}\ *serial\_number);}
\DoxyCodeLine{00186\ }
\DoxyCodeLine{00193\ \textcolor{keywordtype}{int}\ \mbox{\hyperlink{group__storage03_ga9f2f68ea0ff2c13d4fe5d52dc3a99e4f}{DeviceIdentity\_SetRegion}}(\mbox{\hyperlink{group__storage03_ga509a8b0630b9c754a52a817ba37e032b}{device\_region\_t}}\ region);}
\DoxyCodeLine{00194\ }
\DoxyCodeLine{00195\ \textcolor{comment}{/*\ ====================\ Public\ API\ -\/\ MAC\ Address\ ====================\ */}}
\DoxyCodeLine{00196\ }
\DoxyCodeLine{00202\ \textcolor{keywordtype}{void}\ \mbox{\hyperlink{group__storage03_ga461c49efb137c6fcc9871867b974c326}{DeviceIdentity\_FillMac}}(uint8\_t\ mac[6]);}
\DoxyCodeLine{00203\ }
\DoxyCodeLine{00204\ \textcolor{preprocessor}{\#endif\ }\textcolor{comment}{/*\ DEVICE\_IDENTITY\_H\ */}\textcolor{preprocessor}{}}
\DoxyCodeLine{00205\ }

\end{DoxyCode}

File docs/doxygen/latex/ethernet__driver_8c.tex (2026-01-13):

\doxysection{src/\+Software/\+ENERGIS\+\_\+\+RTOS/src/drivers/ethernet\+\_\+driver.c File Reference}
\hypertarget{ethernet__driver_8c}{}\label{ethernet__driver_8c}\index{src/Software/ENERGIS\_RTOS/src/drivers/ethernet\_driver.c@{src/Software/ENERGIS\_RTOS/src/drivers/ethernet\_driver.c}}
{\ttfamily \#include "{}../\+CONFIG.\+h"{}}\newline
Include dependency graph for ethernet\+\_\+driver.\+c\+:\nopagebreak
\begin{figure}[H]
\begin{center}
\leavevmode
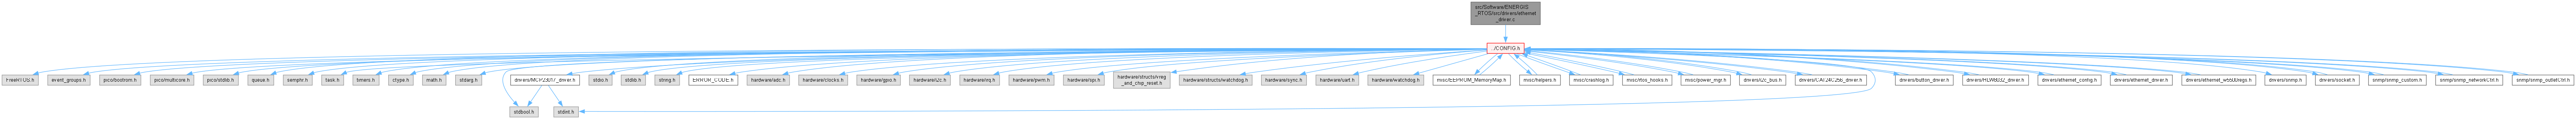
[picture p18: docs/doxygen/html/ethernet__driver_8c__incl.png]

\end{center}
\end{figure}
\doxysubsubsection*{Macros}
\begin{DoxyCompactItemize}
\item 
\#define \mbox{\hyperlink{ethernet__driver_8c_a275e389067225f4321af3e6e79432dea}{ETH\+\_\+\+TASK\+\_\+\+TAG}}~"{}\mbox{[}W5500\mbox{]}"{}
\item 
\#define \mbox{\hyperlink{ethernet__driver_8c_a940a414666b61a6c292ad7f107ca28e3}{W5500\+\_\+\+SPI\+\_\+\+READ}}~0x00
\item 
\#define \mbox{\hyperlink{ethernet__driver_8c_ad295df72ce1f30ef81594797e7bbc37f}{W5500\+\_\+\+SPI\+\_\+\+WRITE}}~0x04
\item 
\#define \mbox{\hyperlink{ethernet__driver_8c_a5605f9f977d34c80cb4283433fc6101b}{W5500\+\_\+\+SPI\+\_\+\+VDM\+\_\+\+OP}}~0x00
\item 
\#define \mbox{\hyperlink{ethernet__driver_8c_a3e33ce815a2540d38288a5aebbd5d6ba}{MAX\+\_\+\+FSR\+\_\+\+RSR\+\_\+\+RETRIES}}~10
\end{DoxyCompactItemize}
\doxysubsubsection*{Functions}
\begin{DoxyCompactItemize}
\item 
static void \mbox{\hyperlink{ethernet__driver_8c_ab42948f652d714f130eebcb5e05a832b}{\+\_\+w5500\+\_\+cs\+\_\+select}} (void)
\begin{DoxyCompactList}\small\item\em CS select (pull CS low) \end{DoxyCompactList}\item 
static void \mbox{\hyperlink{ethernet__driver_8c_aae72fb2b203b11e6ea9270c6330328b4}{\+\_\+w5500\+\_\+cs\+\_\+deselect}} (void)
\begin{DoxyCompactList}\small\item\em CS deselect (pull CS high) \end{DoxyCompactList}\item 
static uint8\+\_\+t \mbox{\hyperlink{ethernet__driver_8c_a40b7eeef5902a429763d4c7f03730854}{\+\_\+w5500\+\_\+spi\+\_\+read}} (void)
\begin{DoxyCompactList}\small\item\em SPI read single byte. \end{DoxyCompactList}\item 
static void \mbox{\hyperlink{ethernet__driver_8c_a91d8245b26a8e36d6635f72d4115d17f}{\+\_\+w5500\+\_\+spi\+\_\+write}} (uint8\+\_\+t tx\+\_\+data)
\begin{DoxyCompactList}\small\item\em SPI write single byte. \end{DoxyCompactList}\item 
static void \mbox{\hyperlink{ethernet__driver_8c_a4b86c813b7a496740ce778899eab89f8}{\+\_\+w5500\+\_\+cris\+\_\+enter}} (void)
\begin{DoxyCompactList}\small\item\em Critical section enter (acquire mutex) \end{DoxyCompactList}\item 
static void \mbox{\hyperlink{ethernet__driver_8c_a55dd06c3dcd66f4304561203faf465bb}{\+\_\+w5500\+\_\+cris\+\_\+exit}} (void)
\begin{DoxyCompactList}\small\item\em Critical section exit (release mutex) \end{DoxyCompactList}\item 
uint8\+\_\+t \mbox{\hyperlink{group__drivers03_ga0cfc16a607bf2406462a16e0b098badb}{w5500\+\_\+read\+\_\+reg}} (uint32\+\_\+t addr\+\_\+sel)
\begin{DoxyCompactList}\small\item\em Read single byte from W5500 register (optimized bulk SPI) \end{DoxyCompactList}\item 
static uint16\+\_\+t \mbox{\hyperlink{ethernet__driver_8c_a4b0b3b259cf8981cc3fe59199ffd8f70}{w5500\+\_\+read\+\_\+reg16}} (uint32\+\_\+t addr\+\_\+sel)
\begin{DoxyCompactList}\small\item\em Read 16-\/bit value from W5500 register (optimized for FSR/\+RSR) \end{DoxyCompactList}\item 
void \mbox{\hyperlink{group__drivers03_ga9bd16b5a58852d08dd22d052bfaf1d05}{w5500\+\_\+write\+\_\+reg}} (uint32\+\_\+t addr\+\_\+sel, uint8\+\_\+t wb)
\begin{DoxyCompactList}\small\item\em Write single byte to W5500 register (optimized bulk SPI) \end{DoxyCompactList}\item 
void \mbox{\hyperlink{group__drivers03_ga720712f243385daced1e173642f23f3f}{w5500\+\_\+read\+\_\+buf}} (uint32\+\_\+t addr\+\_\+sel, uint8\+\_\+t \texorpdfstring{$\ast$}{*}p\+Buf, uint16\+\_\+t len)
\begin{DoxyCompactList}\small\item\em Read multiple bytes from W5500 (optimized bulk transfer) \end{DoxyCompactList}\item 
void \mbox{\hyperlink{group__drivers03_ga8e525d27915365abbe8086dc3363055f}{w5500\+\_\+write\+\_\+buf}} (uint32\+\_\+t addr\+\_\+sel, uint8\+\_\+t \texorpdfstring{$\ast$}{*}p\+Buf, uint16\+\_\+t len)
\begin{DoxyCompactList}\small\item\em Write multiple bytes to W5500 (optimized bulk transfer) \end{DoxyCompactList}\item 
void \mbox{\hyperlink{group__drivers03_ga35f04740974b2f6a16c4744f1641fd47}{set\+Sn\+\_\+\+TX\+\_\+\+WR}} (uint8\+\_\+t sn, uint16\+\_\+t ptr)
\begin{DoxyCompactList}\small\item\em Set socket TX write pointer (Sn\+\_\+\+TX\+\_\+\+WR) in big-\/endian. \end{DoxyCompactList}\item 
void \mbox{\hyperlink{group__drivers03_ga63c2ca3d8006105cbac360261ec27404}{set\+Sn\+\_\+\+RX\+\_\+\+RD}} (uint8\+\_\+t sn, uint16\+\_\+t ptr)
\begin{DoxyCompactList}\small\item\em Set socket RX read pointer (Sn\+\_\+\+RX\+\_\+\+RD) in big-\/endian. \end{DoxyCompactList}\item 
void \mbox{\hyperlink{group__drivers03_gab5067ea57282ddde48ecb150943ece32}{set\+Sn\+\_\+\+PORT}} (uint8\+\_\+t sn, uint16\+\_\+t port)
\begin{DoxyCompactList}\small\item\em Set the local TCP/\+UDP port (big-\/endian) \end{DoxyCompactList}\item 
uint16\+\_\+t \mbox{\hyperlink{group__drivers03_ga27629270cacc8f11b4931aeb9c779ca2}{get\+Sn\+\_\+\+PORT}} (uint8\+\_\+t sn)
\begin{DoxyCompactList}\small\item\em Get the local TCP/\+UDP port (big-\/endian) \end{DoxyCompactList}\item 
void \mbox{\hyperlink{group__drivers03_ga2266fd45d5dc208a9ac11f084d476188}{set\+Sn\+\_\+\+DPORT}} (uint8\+\_\+t sn, uint16\+\_\+t dport)
\begin{DoxyCompactList}\small\item\em Set the destination TCP/\+UDP port (big-\/endian) \end{DoxyCompactList}\item 
uint16\+\_\+t \mbox{\hyperlink{group__drivers03_ga63cf3a1380ecdfc60d1a0e2ac5478bb7}{get\+Sn\+\_\+\+DPORT}} (uint8\+\_\+t sn)
\begin{DoxyCompactList}\small\item\em Get the destination TCP/\+UDP port (big-\/endian) \end{DoxyCompactList}\item 
uint16\+\_\+t \mbox{\hyperlink{group__drivers03_gaddeb179a48abf7a94ba651742d77c24d}{w5500\+\_\+get\+\_\+tx\+\_\+fsr}} (uint8\+\_\+t sn)
\begin{DoxyCompactList}\small\item\em Get socket TX free size register (with timeout protection) \end{DoxyCompactList}\item 
uint16\+\_\+t \mbox{\hyperlink{group__drivers03_gad4b8fcc33da68070ad8208da41838d4c}{w5500\+\_\+get\+\_\+rx\+\_\+rsr}} (uint8\+\_\+t sn)
\begin{DoxyCompactList}\small\item\em Get socket RX received size register (with timeout protection) \end{DoxyCompactList}\item 
void \mbox{\hyperlink{group__drivers03_gaeaef8ee772ea9b4a5c6ba7702a1c9b52}{eth\+\_\+send\+\_\+data}} (uint8\+\_\+t sn, uint8\+\_\+t \texorpdfstring{$\ast$}{*}wizdata, uint16\+\_\+t len)
\begin{DoxyCompactList}\small\item\em Send data to socket TX buffer. \end{DoxyCompactList}\item 
void \mbox{\hyperlink{group__drivers03_ga4a5d2efe0640661e215b4e1f3d918dbd}{eth\+\_\+recv\+\_\+data}} (uint8\+\_\+t sn, uint8\+\_\+t \texorpdfstring{$\ast$}{*}wizdata, uint16\+\_\+t len)
\begin{DoxyCompactList}\small\item\em Receive data from socket RX buffer. \end{DoxyCompactList}\item 
void \mbox{\hyperlink{group__drivers03_ga5944e5f356542e598f515b7f0196d1a3}{eth\+\_\+recv\+\_\+ignore}} (uint8\+\_\+t sn, uint16\+\_\+t len)
\begin{DoxyCompactList}\small\item\em Ignore (discard) received data. \end{DoxyCompactList}\item 
bool \mbox{\hyperlink{group__drivers03_ga1528dc514cbd1c3cc346f1593554a042}{w5500\+\_\+hw\+\_\+init}} (void)
\begin{DoxyCompactList}\small\item\em Initialize W5500 hardware (SPI, GPIOs, chip reset) \end{DoxyCompactList}\item 
bool \mbox{\hyperlink{group__drivers03_ga4c79e652fe1be0ffee1445f8411cce51}{w5500\+\_\+chip\+\_\+init}} (\mbox{\hyperlink{structw5500___net_config}{w5500\+\_\+\+Net\+Config}} \texorpdfstring{$\ast$}{*}net\+\_\+info)
\begin{DoxyCompactList}\small\item\em Initialize the W5500 chip and bring link up. \end{DoxyCompactList}\item 
bool \mbox{\hyperlink{group__drivers03_ga90f24fc38c9785dbc5ebe18417733a7b}{w5500\+\_\+check\+\_\+version}} (void)
\begin{DoxyCompactList}\small\item\em Check W5500 version register (diagnostic) \end{DoxyCompactList}\item 
void \mbox{\hyperlink{group__drivers03_ga8aef3e5f959b806f9890722dee066782}{w5500\+\_\+set\+\_\+network}} (\mbox{\hyperlink{structw5500___net_config}{w5500\+\_\+\+Net\+Config}} \texorpdfstring{$\ast$}{*}net\+\_\+info)
\begin{DoxyCompactList}\small\item\em Set network configuration (MAC, IP, subnet, gateway) \end{DoxyCompactList}\item 
void \mbox{\hyperlink{group__drivers03_ga51cb463647ad0291c4b7a69d2c4c9a04}{w5500\+\_\+get\+\_\+network}} (\mbox{\hyperlink{structw5500___net_config}{w5500\+\_\+\+Net\+Config}} \texorpdfstring{$\ast$}{*}net\+\_\+info)
\begin{DoxyCompactList}\small\item\em Get current network configuration. \end{DoxyCompactList}\item 
void \mbox{\hyperlink{group__drivers03_gabe918beda4e8c4b4a42c7e96f471ff1c}{w5500\+\_\+print\+\_\+network}} (\mbox{\hyperlink{structw5500___net_config}{w5500\+\_\+\+Net\+Config}} \texorpdfstring{$\ast$}{*}net\+\_\+info)
\begin{DoxyCompactList}\small\item\em Print network configuration to logger. \end{DoxyCompactList}\item 
\mbox{\hyperlink{group__drivers03_gacef8050f9ef67107f3847653577da34f}{w5500\+\_\+\+Phy\+Link}} \mbox{\hyperlink{group__drivers03_gafc4a24de4907644bb37647d9afa7f69d}{w5500\+\_\+get\+\_\+link\+\_\+status}} (void)
\begin{DoxyCompactList}\small\item\em Get PHY link status. \end{DoxyCompactList}\item 
int8\+\_\+t \mbox{\hyperlink{group__drivers03_ga9ed1fde0b5018519ab23e299d9a2fc13}{w5500\+\_\+set\+\_\+phy\+\_\+conf}} (\mbox{\hyperlink{structw5500___phy_config}{w5500\+\_\+\+Phy\+Config}} \texorpdfstring{$\ast$}{*}phyconf)
\begin{DoxyCompactList}\small\item\em Configure PHY mode (auto-\/negotiation, speed, duplex) \end{DoxyCompactList}\item 
void \mbox{\hyperlink{group__drivers03_ga581d6d6cf877331ce49b5bcf11fe13bc}{w5500\+\_\+get\+\_\+phy\+\_\+conf}} (\mbox{\hyperlink{structw5500___phy_config}{w5500\+\_\+\+Phy\+Config}} \texorpdfstring{$\ast$}{*}phyconf)
\begin{DoxyCompactList}\small\item\em Get current PHY configuration. \end{DoxyCompactList}\item 
void \mbox{\hyperlink{group__drivers03_ga4d82ae9c8c6c8da0c1d25b1c8e9755d8}{w5500\+\_\+set\+\_\+phy\+\_\+power}} (\mbox{\hyperlink{group__drivers03_ga7ad32e7472dce94b87b4e5bf53a9d5c0}{w5500\+\_\+\+Phy\+Power}} mode)
\begin{DoxyCompactList}\small\item\em Set PHY power mode. \end{DoxyCompactList}\item 
void \mbox{\hyperlink{group__drivers03_gac147c27b83f9f642f636d5e67254d7e8}{w5500\+\_\+sw\+\_\+reset}} (void)
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

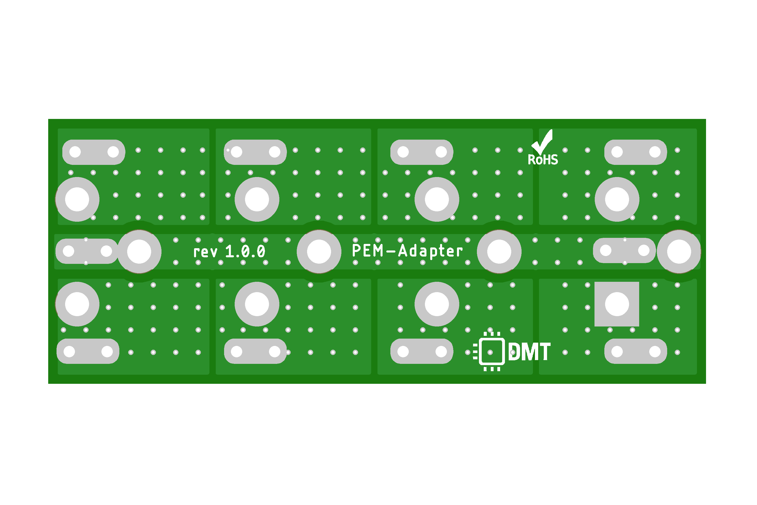
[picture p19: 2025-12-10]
src/Hardware-Design/ENERGIS/Rev1.1.0/Images/BOTTOM-PEM-Adapter_1.0.0.png

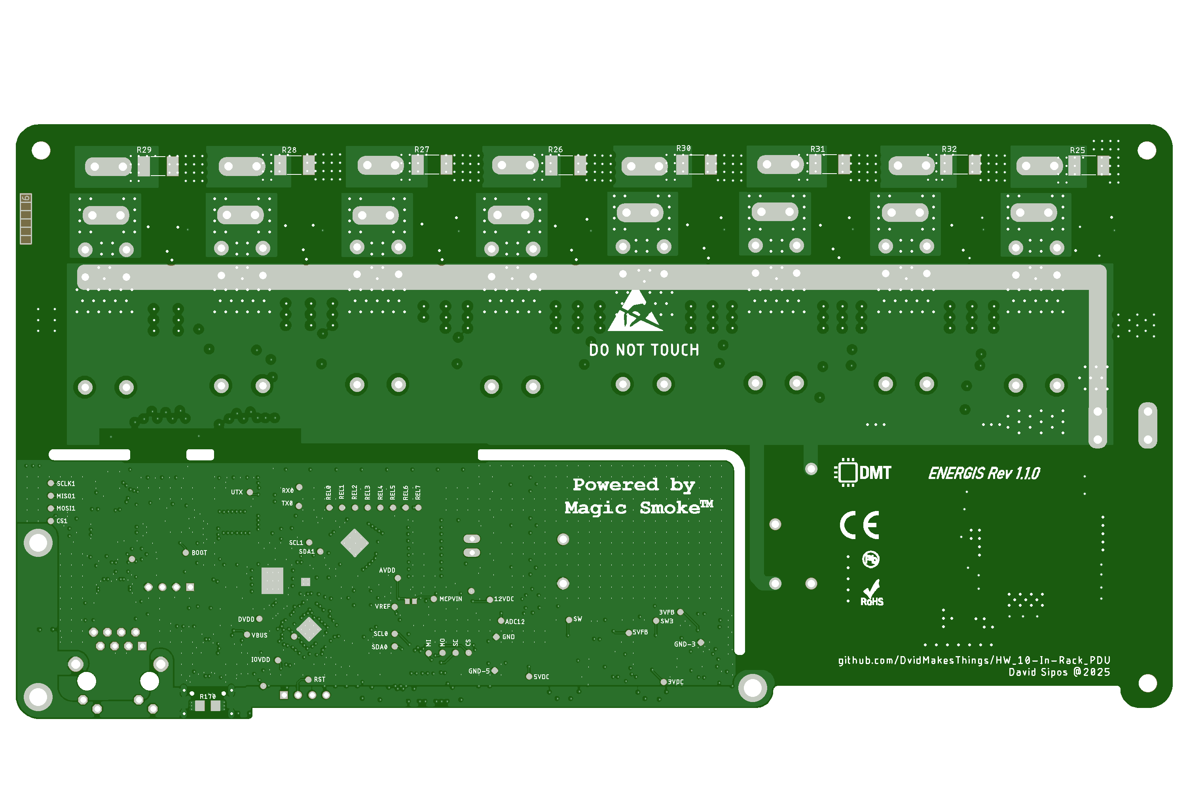
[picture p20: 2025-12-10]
src/Hardware-Design/ENERGIS/Rev1.1.0/Images/BOTTOM-ENERGIS_Rack-PDU_1.1.0.png

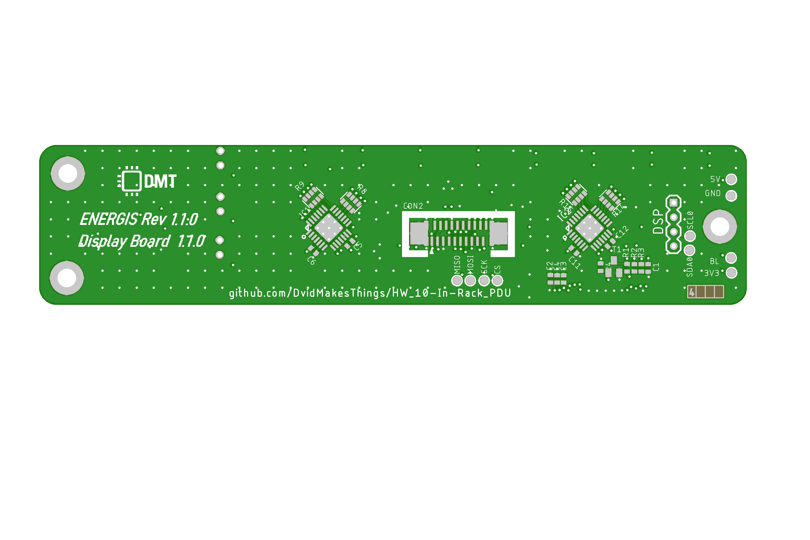
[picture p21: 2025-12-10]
src/Hardware-Design/ENERGIS/Rev1.1.0/Images/BOTTOM-ENERGIS_DispBrd_Rack-PDU_1.1.0.png

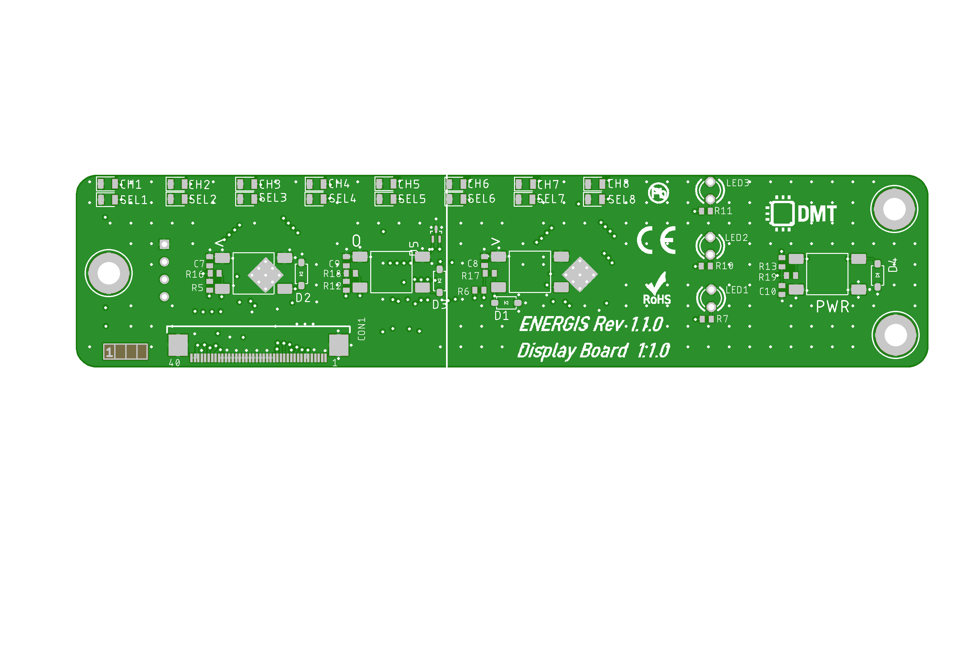
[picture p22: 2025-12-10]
src/Hardware-Design/ENERGIS/Rev1.1.0/Images/TOP-ENERGIS_DispBrd_Rack-PDU_1.1.0.png

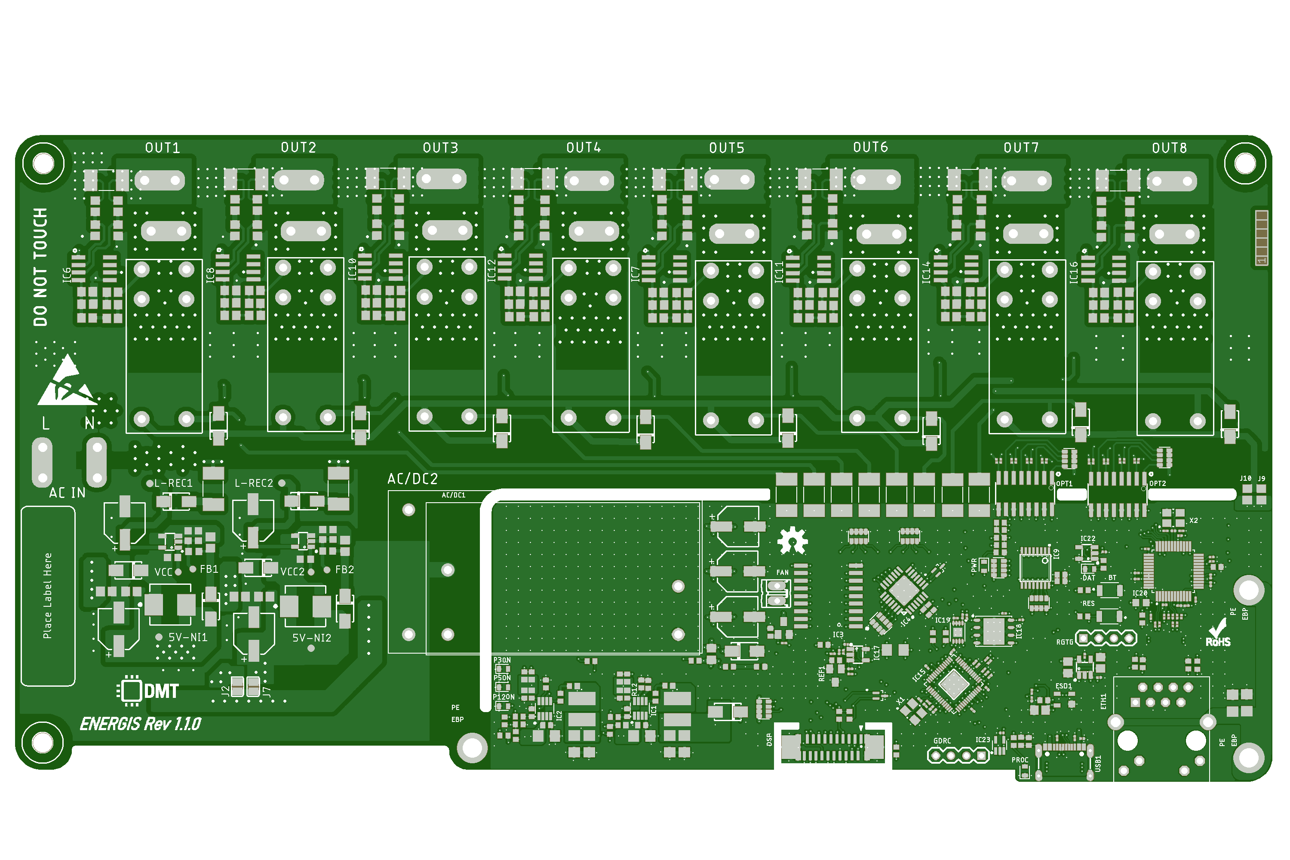
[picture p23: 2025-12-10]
src/Hardware-Design/ENERGIS/Rev1.1.0/Images/TOP-ENERGIS_Rack-PDU_1.1.0.png

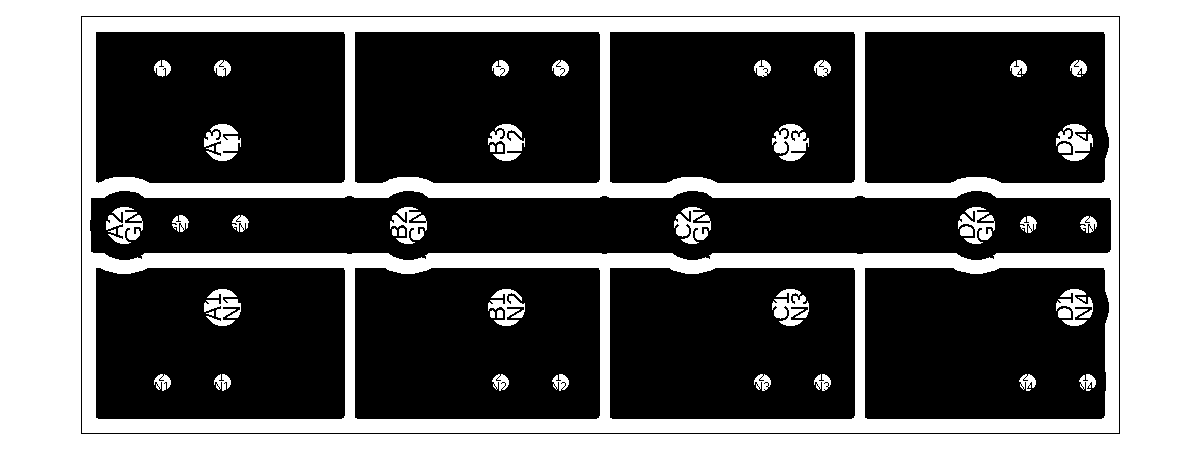
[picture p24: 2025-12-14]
src/Hardware-Design/ENERGIS/Rev1.1.0/Gerber/PEM-Adapter/GERBER-PEM-Adapter_1.0.0/L2.png

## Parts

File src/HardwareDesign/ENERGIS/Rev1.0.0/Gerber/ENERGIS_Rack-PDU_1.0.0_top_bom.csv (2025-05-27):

Comment | Designator | Footprint | LCSC Part #
0.002R 1% | R35 R43 R51 R67 R75 R83 R99 R115 | 2512
0R | J8 J9 J10 | 0805
0R | R57 R91 | 0402
1K | R16 R59 | R0201
1K | R112 R122 R123 R151 | 0402
1K | R153 R154 R155 R156 R157 R158 R159 | R0201
1K 1% | R33 R34 R40 R41 R42 R48 R49 R50 R56 R65 R66 R72 R73 R74 R80 R81 R82 R88 R97 R98 R104 R113 R114 R120 | 0805
1M | R131 | 0402
1M | R144 | R0201
1N4007 | D9 D10 D12 D13 | SMA
1nF | C106 C107 C108 C109 C110 C111 C112 C113 | 0201
1nF 50V | C5 C51 | C0603
1uF | C60 | C0402
1uF 50V | C45 C57 | C0805
2.2K 1% | R121 | R0201
2.2uF 10V | C21 C46 | C0603
2.2uF 400V | C35 C47 | WCAP-HSAH_D6.3H7.7P2.2
2.4 K | R148 | 0402
3.3R | R133 R134 R135 R136 | R0201
4.2uH | L2 | SRR5228A
4.7K | R109 R129 R145 | R0201
4.7nF | C78 | 0402
4.7uF | C85 | C0402
4.9uH | L1 | SRR5228A
4.99K | R60 R61 R105 R107 | 0603
4.99M | R110 | 1206
4D03WGJ0332T5E | R130 R149 | 742C083103JP
4x1K 1206 | R63 R64 R89 R90 | 742C083103JP
4x10K 1206 | R93 | 742C083103JP
5.1K | R124 R125 | R0201
6.8nF | C81 C82 | 0201
7.5K | R6 R12 | 0402
8.2K | R150 | 0402
9.09K | R4 | 0402
10K | R1 R2 R95 | 0402
10K | R96 R108 | 0805
10K | R126 R127 | R0201
10K | R132 R147 | 0402
10R | R7 R9 | 0402
10uF | C65 C97 C99 | 0805
12.4K 1% | R143 | R0201
12.7K | R14 | 0402
12MHz | X1 | WE-XTAL_CFPX-180
15pF | C58 C59 | 0201
18pF | C86 C87 | 0201
20K | R8 | 0402
22nF | C80 | C0402
22uF - 10V | C14 C15 C17 C18 | C1206
22uF 25V | C1 C2 | C1206
25MHz | X2 | WE-XTAL_CFPX-180
27R | R15 R160 | R0201
33K | R10 | 0402
33nF | C24 C25 C26 C27 C28 C29 C30 C31 C32 C36 C37 C38 C39 C40 C41 C42 C43 C44 C48 C49 C50 C54 C55 C56 | C0805
33pF | C11 C12 | 0402
39R 2W | R62 R106 | 2512
40.2K | R11 R13 | 0402
49.9R | R137 R138 R139 R140 | R0201
100K | R3 R5 R94 | 0402
100nF | C3 C4 C6 C7 C8 C9 | 0402
100nF | C19 C20 C33 C34 | C0402
100nF | C61 C62 C63 C64 | 0201
100nF | C66 | 0402
100nF | C67 C68 C69 C70 C71 C72 C73 C74 C75 C76 C77 | 0201
100nF | C79 | C0402
100nF | C84 C88 C89 C90 C91 C92 C93 C94 C95 C96 C98 C100 C101 C103 | 0201
100uF | C10 C13 C16 | 100UF-16V
100uF 16V | C23 C53 | WCAP-PSHP_6.3X5.8(DXL)
220nF 16V | C22 C52 | C0805
330R 1W | R17 R18 R19 R20 R21 R22 R23 R24 | 2512
470K | R36 R37 R38 R39 R44 R45 R46 R47 R52 R53 R54 R55 R68 R69 R70 R71 R76 R77 R78 R79 R84 R85 R86 R87 R100 R101 R102 R103 R116 R117 R118 R119 | 0805
470R | R141 R142 R146 | 0402
ACPL-247 | OPT1 OPT2 | SO16
AFC11-S20ICC-00 | DSP | FPC20
BLM18EG221TN1D | L4 | 0603
C1206C102KGRACTM | C83 | C1206
CAT24C512HU5IGT3 | IC19 | SON50P300X200X50-9T130X140N
DNI | R58 R92 | 0402
DNI | R111 | R0201
FNR6028S102MT 1mH | L3 L5 | WE-HEPA_6030
HLW8032 | IC6 IC7 IC8 IC10 IC11 IC12 IC14 IC16 | SO8
JP | J2 J7 | SJ
LEDC1608X35N_FLAT-B | DAT | LEDC1608X35N_FLAT-B
LEDC1608X35N_FLAT-G | P3ON P5ON P12ON PWR | LEDC1608X35N_FLAT-G
LM4040BXX | REF1 | SOT23
MBRA340T3 | D2 D3 D4 D5 D6 D7 D8 | SMA
MBRA340T3G | D1 | SMA
MCP6001R | IC17 IC22 | SOT23-5
MCP23017-E/ML | IC4 | QFN28[6X6]ML
MIC5504-3.3YM5-TR | IC21 | SOT23-5
MP150GJ | IC5 IC13 | SOT23-5
MP2315GJ-Z | IC1 | SOT65P280X110-8N
MP2315S | IC2 | SOT65P280X110-8N
NC | R128 | R0201
RP2040 | IC15 | QFN40P700X700X100-57T510
RS032G05A3SM | BOOT RESET | TACTILE-SWITCH-1101NE
SMAJ15A | Z1 | SUPRESSOR_SMAJ
SN74HC151PWR | IC9 | TSSOP16
SP0503BAHTG-ES | ESD1 | SOT143
SS12 | D15 | SMA
TP | 3VDC 3VFB 5V-NI1 5V-NI2 5VDC 5VFB 12VDC AVDD DVDD FB-NI1 FB-NI2 GND GND-3 GND-5 IOVDD L-REC1 L-REC2 SW SW3 VBUS VNI1 VNI2 VREF | TP
ULN2803A | IC3 | SO18
US1J | D11 D14 | SMA
USB-TYPE-C-018 | USBC | 629722000214
W25Q128JVPIQ | IC18 | SON127P600X500X75-8N
W5500 | IC20 | LQFP48

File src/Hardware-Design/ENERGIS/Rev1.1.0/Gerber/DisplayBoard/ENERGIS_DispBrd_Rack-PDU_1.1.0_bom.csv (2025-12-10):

Comment | Designator | Footprint | LCSC Part #
0R 1% | R16 R17 R18 R19 | 0402 | C17168
1K 1% | R7 | 0402 | C11702
1K 1% | R8 R9 | _0603X4-1206 | C110021
1K 1% | R10 R11 | 0402 | C11702
1K 1% | R14 R15 | _0603X4-1206 | C110021
10K 1% | R5 R6 R12 R13 | 0402 | C25744
100nF 25V | C5 C6 C7 C8 C9 C10 C11 C12 | 0402 | C56392
AFC11-S20ICC-00 | CON2 | FPC20 | C11073
BLUE | LED2 | LED3MM | C86881
DNI | 3V3 5V BL | TP-ROUND
DNI | C1 C2 C3 C4 | C0402
DNI | CON1 | FPC40_3.5TFT
DNI | CS | TP-ROUND
DNI | DSP | 1X4
DNI | GND | TP-ROUND
DNI | H1 | 3 2-PAD
DNI | H2 | 3 2-PAD
DNI | H3 | 3 2-PAD
DNI | MISO MOSI | TP-ROUND
DNI | R1 R2 R3 | 0402
DNI | R4 | 0402 | C25744
DNI | SCK SCL0 SDA0 | TP-ROUND
DNI | T1 | SOT23
DNI | U$1 U$5 | DMT
DNI | U$8 | CE-4MM
DNI | U$9 | ROHS_LOGO_0.18_IN
DNI | U$10 | NO_PB_LOGO_0.120
GREEN | LED1 | LED3MM | C414645
Green | CH1 CH2 CH3 CH4 CH5 CH6 CH7 CH8 | LED-0805 | C2297
MCP23017T-E/ML | IC1 IC2 | QFN28[6X6]ML | C629439
Orange | SEL1 SEL2 SEL3 SEL4 SEL5 SEL6 SEL7 SEL8 | LED-0805 | C434437
PTVS3V3S1UR 115 | D1 | SOD-123 | C183521
PTVS3V3S1UR 115 | D2 | SOD-123 | C183521
PTVS3V3S1UR 115 | D3 | SOD-123 | C183521
PTVS3V3S1UR 115 | D4 | SOD-123 | C183521
RCLAMP0582BQTCT | D5 | SC75 | C841193
RED | LED3 | LED3MM | C330752
TS-1002S-04326C | < > O PWR | PUSHBUTTON-6X6 | C455108

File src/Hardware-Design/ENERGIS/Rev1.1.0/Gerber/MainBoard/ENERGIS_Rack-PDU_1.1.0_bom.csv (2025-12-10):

Comment | Designator | Footprint | LCSC Part #
0.002R 1% | R25 R26 R27 R28 R29 R30 R31 R32 R35 R43 R51 R67 R75 R83 R99 R115 | 2512 | C728320
0R 1% | DNI | 0402 | C17168
0R 1% | J8 J9 J10 | 0805 | C17477
0R 1% | R17 R18 R19 R20 R21 R22 R23 R24 | 2512 | C25469
0R 1% | R57 R91 | 0402 | C17168
0R 1% | R169 | 1206 | C205296
1K 1% | R16 | 0201 | C270365
1K 1% | R33 R34 R40 R41 R42 R48 R49 R50 R56 | 0805 | C17513
1K 1% | R59 | 0201 | C270365
1K 1% | R63 R64 | _0603X4-1206 | C110021
1K 1% | R65 R66 R72 R73 R74 R80 R81 R82 R88 R97 R98 R104 | 0805 | C17513
1K 1% | R112 | 0402 | C11702
1K 1% | R113 R114 R120 | 0805 | C17513
1K 1% | R122 R123 R151 | 0402 | C11702
1K 1% | R153 R154 R155 R156 R157 R158 R159 | 0201 | C270365
1K 1% | R163 | 0402 | C11702
1M 1% | R110 | 1206 | C17927
1M 1% | R131 | 0402 | C26083
1M 1% | R144 | 0201 | C295786
1N4007 | D9 D10 D12 D13 | SMA/DO-214AC | C727081
1mH | L3 L5 | L-6.6X6.6 | C168049
1nF 2kV | C83 | 1206 | C173242
1nF 25V | C106 C107 C108 C109 C110 C111 C112 C113 | 0201 | C7694325V
1nF 50V | C5 C51 | 0603 | C1588
1uF 16V | C102 | 0201 | C307385
1uF 25V | C60 C104 | 0402 | C52923
1uF 50V | C45 C57 | 0805 | C28323
2.2K 1% | R121 | 0201 | C473508
2.2uF 50V | C21 C46 | 0603 | C913904
2.2uF 400V | C35 C47 | 6.3X7.7(DXL) | C3345109
2.4K 1% | R148 | 0402 | C25882
3.3K 1% | R130 | 0402 | C25890
3.3K 1% | R149 | _0603X4-1206 | C1734380
3.3K 1% | R166 R167 R168 | 0402 | C25890
3.3R 1% | R133 R134 R135 R136 | 0201 | C158547
4.7K 1% | R109 R129 R145 | 0201 | C270346
4.7nF 50V | C78 | 0402 | C1538
4.7uF 25V | C85 | 0402 | C22367824
4.7uH 3.5A | L2 | SRR5228A | C14258
4.99K 1% | R60 R61 R105 R107 | 0603 | C23046
5.1K 1% | R124 R125 | 0201 | C274341
6.8nF 50V | C81 C82 | 0201 | C285015
7.5K 1% | R6 R12 | 0402 | C25918
8.2K 1% | R150 | 0402 | C25924
9.09K 1% | R4 | 0402 | C11549
10K 1% | R2 | 0402 | C25744
10K 1% | R89 R90 R93 | _0603X4-1206 | C110924
10K 1% | R95 | 0402 | C25744
10K 1% | R96 R108 | 0805 | C17414
10K 1% | R126 R127 | 0201 | C473048
10K 1% | R132 R147 R162 R164 R171 | 0402 | C25744
10R 1% | R7 R9 | 0402 | C25077
10R 1% | R152 | 0201 | C270817
10uF 50V | C65 C97 C99 | 0805 | C440198
12.4K 1% | R143 | 0201 | C423760
12.7K 1% | R14 | 0402 | C25853
12MHz | X1 | WE-XTAL_CFPX-180 | C20625731
15pF 50V | C58 C59 | 0201 | C22374851
18pF 50V | C86 C87 | 0201 | C62164
20K 1% | R8 | 0402 | C25765
22nF 50V | C80 | 0402 | C1532
22uF 25V | C1 C2 C14 C15 C17 C18 | 1206 | C12891
25MHz | X2 | WE-XTAL_CFPX-180 | C13740
27R 1% | R15 R160 | 0201 | C473051
33K 1% | R10 | 0402 | C25779
33nF 50V | C24 C25 C26 C27 C28 C29 C30 C31 C32 C36 C37 C38 C39 C40 C41 C42 C43 C44 C48 C49 C50 C54 C55 C56 | 0805 | C107150
33pF 50V | C11 C12 | 0402 | C107005
39R 1% 2W | R62 R106 | 2512 | C175263
40.2K 1% | R11 R13 | 0402 | C25893
49.9R 1% | R137 R138 R139 R140 | 0201 | C155744
100K 1% | R3 R5 R94 | 0402 | C25741
100K 1% | RN1 RN2 | _0603X4-1206 | C110374
100nF 25V | C3 C4 C6 C7 C8 C9 C19 C20 C33 C34 | 0402 | C56392
100nF 25V | C61 C62 C63 C64 | 0201 | C76939
100nF 25V | C66 | 0402 | C56392
100nF 25V | C67 C68 C69 C70 C71 C72 C73 C74 C75 C76 C77 | 0201 | C76939
100nF 25V | C79 | 0402 | C56392
100nF 25V | C84 C88 C89 C90 C91 C92 C93 C94 C95 C96 C98 C100 C101 C103 C105 | 0201 | C76939
100uF 25V | C10 C13 C16 | 6.3X7.7(DXL) | C267469
100uF 50V | C23 C53 | 6.3X7.7(DXL) | C3151829
220nF 50V | C22 C52 | 0805 | C5378
470K 1% | R36 R37 R38 R39 R44 R45 R46 R47 R52 R53 R54 R55 R68 R69 R70 R71 R76 R77 R78 R79 R84 R85 R86 R87 R100 R101 R102 R103 R116 R117 R118 R119 | 0805 | C17709
470R 1% | R141 R142 R146 | 0402 | C25117
ACPL-247-500E | OPT1 OPT2 | SO16 | C188681
AFC11-S20ICC-00 | DSP | FPC20 | C466537
B3U-1000P | BT RES | B3U-1000P | C231329
BLM18EG221TN1D | L4 | 0603 | C113025
BSS138 | T1 | SOT23
Blue | DAT | LED-0603 | C965807
CAT24C256HU4IGT3 | IC19 | SON50P300X200X50-9T130X140N | C233771
DNI | 3V3A 3VDC 3VFB 5V-NI1 5V-NI2 5VDC 5VFB 12VDC ADC12 ADCUSB ADC_TEMP AVDD BOOT CS CS1 | TP-ROUND
DNI | D15 | SMA/DO-214AC | C727049
DNI | DVDD | TP-ROUND
DNI | FAN | 02P
DNI | FB1 FB2 FCTL | TP-ROUND
DNI | GDRC | 1X4
DNI | GND GND-3 GND-5 | TP-ROUND
DNI | IC1 | SOT65P280X110-8N | C45889
DNI | IOVDD | TP-ROUND
DNI | J2 J7 | SJ
DNI | L-REC1 L-REC2 | TP-ROUND
DNI | L1 | SRR5228A | C325964
DNI | MCPVIN MI MISO1 MO MOSI1 | TP-ROUND
DNI | P5ON | LED-0603 | C965804
DNI | R1 R58 R92 | 0402
DNI | R111 R128 | R0201
DNI | R161 | 0402
DNI | R165 | R0201
DNI | R170 | 1206 | C205296
DNI | R172 | 0402
DNI | REL0 REL1 REL2 REL3 REL4 REL5 REL6 REL7 | TP-ROUND
DNI | RGTG | 1X4
DNI | RST RX0 SC SCL0 SCL1 SCLK1 SDA0 SDA1 SW SW3 TX0 | TP-ROUND
DNI | U$1 U$2 | ESD_10.00
DNI | U$3 | 3 2
DNI | U$4 | 3 2
DNI | U$5 | DMT
DNI | U$6 | 3 2
DNI | U$7 | DMT
DNI | U$10 | OSHW-LOGO-M
DNI | U$11 | ROHS_LOGO_0.18_IN
DNI | U$12 | CE_5MM
DNI | U$13 | NO_PB_LOGO_0.120
DNI | U$14 | ROHS_LOGO_0.18_IN
DNI | U$15 | SMOKE
DNI | UTX VBUS VCC VCC2 VREF | TP-ROUND
FASTON-1217861-1 | AC_L AC_N L_OUT1 L_OUT2 L_OUT3 L_OUT4 L_OUT5 L_OUT6 L_OUT7 L_OUT8 N_OUT1 N_OUT2 N_OUT3 N_OUT4 N_OUT5 N_OUT6 N_OUT7 N_OUT8 | 1217861-1 | C428480
G2RL-1A-E DC12 | K1 K2 K3 K4 K5 K6 K7 K8 | RELAY_G2RL-1A-E_DC5_OMR | C1564126
Green | P3ON P12ON PROC PWR | LED-0603 | C965804
HLW8032 | IC6 IC7 IC8 IC10 IC11 IC12 IC14 IC16 | SO8 | C128023
IRM-10-15 | AC/DC2 | IRM_15_12 | C5439799
IRM_10_12 | AC/DC1 | IRM_10_12 | C42418573
J1B1211CCD | ETH1 | J1B1211CCD | C910371
LM4040x30 | REF1 | SOT23 | C460604
MBRA340T3G | D1 D2 D3 D4 D5 D6 D7 D8 | SMA/DO-214AC | C26178
MCP6001RT-I/OT | IC17 IC22 | SOT23-5 | C154973
MCP9700AT-E/LT | IC23 | SC70-5 | C97546
MCP23017T-E/ML | IC4 | QFN28[6X6]ML | C629439
MIC5504-3.3YM5 | IC21 | SOT23-5 | C41348078
MP150GJ | IC5 IC13 | SOT23-5
MP2315GJ-Z | IC2 | SOT65P280X110-8N | C45889
RCLAMP0582BQTCT | D17 D18 | SC75 | C841193
RP2040 | IC15 | QFN56 | C2040
SMAJ15A | D16 | SMA/DO-214AC | C23424
SN74HC151PWR | IC9 | TSSOP16 | C2653837
SP0503BAHTG | ESD1 | SOT143 | C3040626
ULN2803AFWG | IC3 | SO18 | C845537
US1J-E3/61T | D11 D14 | SMA/DO-214AC | C44763
USB-TYPE-C-018 | USB1 | USB-C | C2927038
W25Q128JVPIQ | IC18 | SON127P600X500X75-8N | C190862
W5500 | IC20 | LQFP48 | C32843

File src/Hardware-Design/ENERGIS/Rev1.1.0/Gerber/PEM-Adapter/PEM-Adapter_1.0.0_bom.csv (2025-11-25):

Comment | Designator | Footprint | LCSC Part #
3-104-370 | PEM1 | 3-104-370
FASTON-1217861-1 | L1 L2 L3 L4 N1 N2 N3 N4 PE1 PE2 | 1217861-1 | C428480

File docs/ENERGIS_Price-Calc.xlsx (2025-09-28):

QTY | Manufacturer | Item | Price | Price/pc | Manufacturing Time (days) | Shipping Time (days) | Total Time (days) | ETA (days)
5 | NextPCB | PCB: MainBoard | 112.76 | 22.552 | 11 | 5 | 16 | 33
5 | NextPCB | Components: MainBoard | 296.82 | 59.364 | 28 | 5 | 33
5 | NextPCB | Assebly: MainBoard | 444.15 | 88.83 | 5 | 5 | 10
5 | NextPCB | PCB: DisplayBoard | 48.04 | 9.608 | 3 | 5 | 8
5 | NextPCB | Components: DisplayBoard | 43.65 | 8.73 | 10 | 5 | 15
5 | NextPCB | Assebly: DisplayBoard | 78.96 | 15.792 | 5 | 5 | 10
1 | NextPCB | PCB Shipping | 30.71 | 30.71 | 0 | 0 | 0
5 | PCBWay | Sheetmetal Enclosure Top | 295.95 | 59.19 | 16 | 14 | 30 | 30
5 | PCBWay | Sheetmetal Enclosure Bottom | 320.95 | 64.19 | 16 | 14 | 30
5 | PCBWay | Sheetmetal Enclosure Shipping | 114.3 | 22.86 | 16 | 14 | 30
10 | Farnell | PX0714/4/15/28 IEC C13 Outlet (https://at.farnell.com/en-AT/bulgin/px0714-4-15-28/outlet-iec-quad/dp/865310?MER=BR-MER-PDP-RECO-STM72194) | 176.904 | 17.6904 | 0 | 2 | 2 | 2
5 | Farnell | B84771A3015A000 Filtered IEC Power Entry Module (https://at.farnell.com/en-AT/epcos/b84771a3015a000/iec-inlet-filter-1-phase-250v/dp/3381588) | 53.703 | 10.7406 | 0 | 2 | 2
5 | Farnell | PP001207 Wire, Tri Rated, Brown, 16 AWG (https://at.farnell.com/en-AT/multicomp-pro/pp001207/tri-rated-wire-1-5mm2-brown-1m/dp/2528105) | 5.9085 | 1.1817 | 0 | 2 | 2
5 | Farnell | PP001207 Wire, Tri Rated, Blue, 16 AWG (https://at.farnell.com/en-AT/multicomp-pro/pp001198/tri-rated-wire-1-5mm2-blue-1m/dp/2528095) | 5.9085 | 1.1817 | 0 | 2 | 2
5 | Farnell | PP001207 Wire, Tri Rated, Green, Yellow, 16 AWG (https://at.farnell.com/en-AT/multicomp-pro/pp001241/tri-rated-wire-1-5mm2-grn-yellow/dp/2528143) | 5.9085 | 1.1817 | 0 | 2 | 2
5 | Farnell | Screws, glue, wire crimp terminals, PCB terminals | 23.4 | 4.68 | 0 | 2 | 2
5 | 3D Print | Buttons | 1 | 0.2 |  |  | 0
5 | 3D Print | LED Diffusor | 1 | 0.2 |  |  | 0
1 |  |  | 0 | 0 |  |  | 0
1 |  |  | 0 | 0 |  |  | 0
 |  |  | $2060.02 |  | Total for 5 pcs
 |  |  |  | $418.88 | Total per piece
 |  |  |  | EUR 356.05

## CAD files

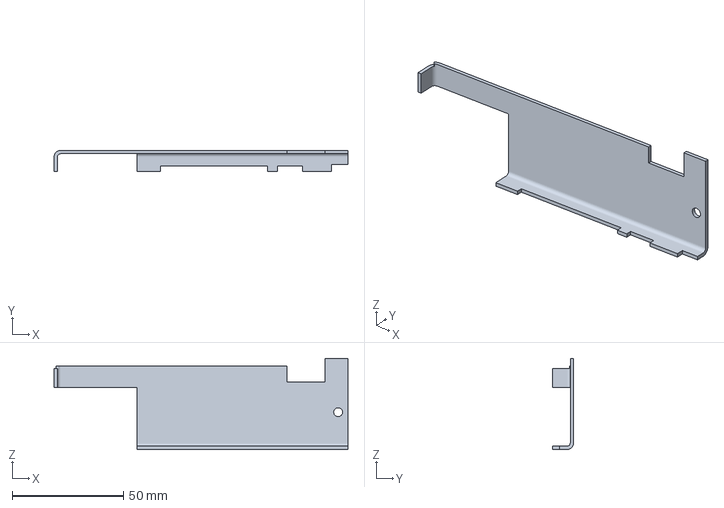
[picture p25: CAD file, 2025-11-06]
src/Enclosure-Design/Shielding/MainBoard_Shielding.3mf
132.3 x 9.56 x 41.0 mm

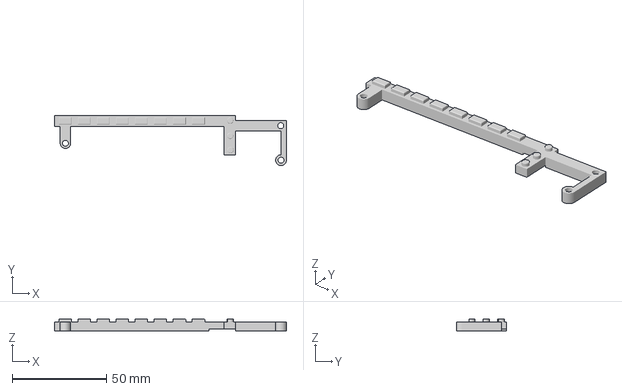
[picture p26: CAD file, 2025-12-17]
src/Enclosure-Design/3D Print/LED-Diffusor.3mf
123.1 x 26.7 x 6.54 mm

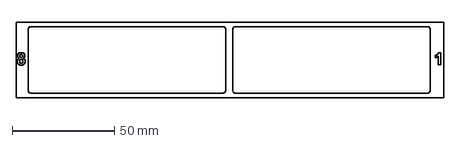
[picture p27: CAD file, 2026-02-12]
src/Enclosure-Design/SheetMetal/Bottom_Enclosure/Bottom_Engrave.dxf
209.2 x 36.8 mm

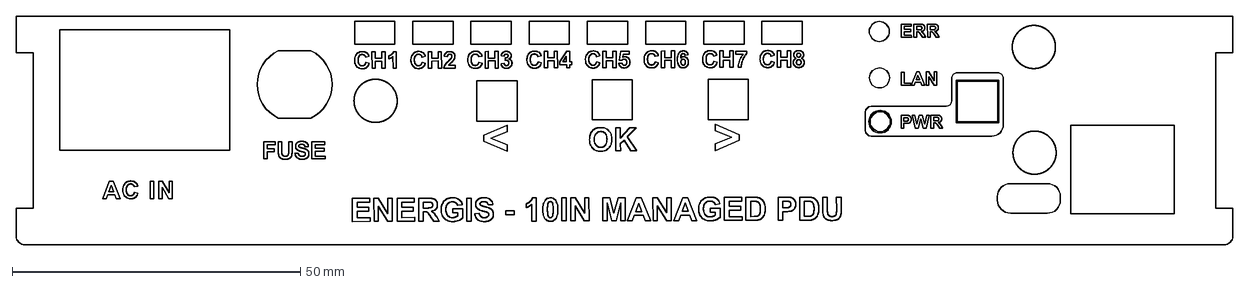
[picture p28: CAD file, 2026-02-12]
src/Enclosure-Design/SheetMetal/Top_Enclosure/Top_Engrave.dxf
211.2 x 39.7 mm

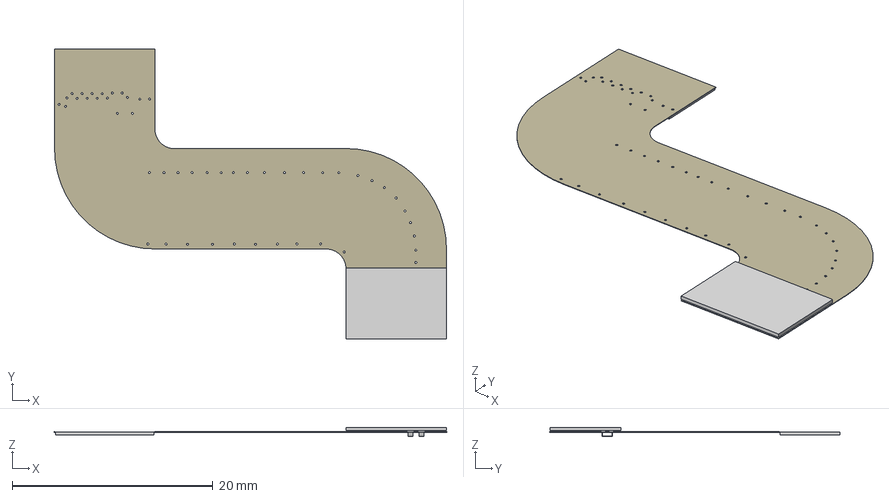
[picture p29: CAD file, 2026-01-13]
src/Hardware-Design/ENERGIS/Rev1.1.0/ENERGIS_FPC-1.0.0.step
39.0 x 28.9 x 0.849 mm
Board
05-20-D-0076-A-4-06-4-T x 2
solidBody x 2
solidLead x 2
solidTop x 2

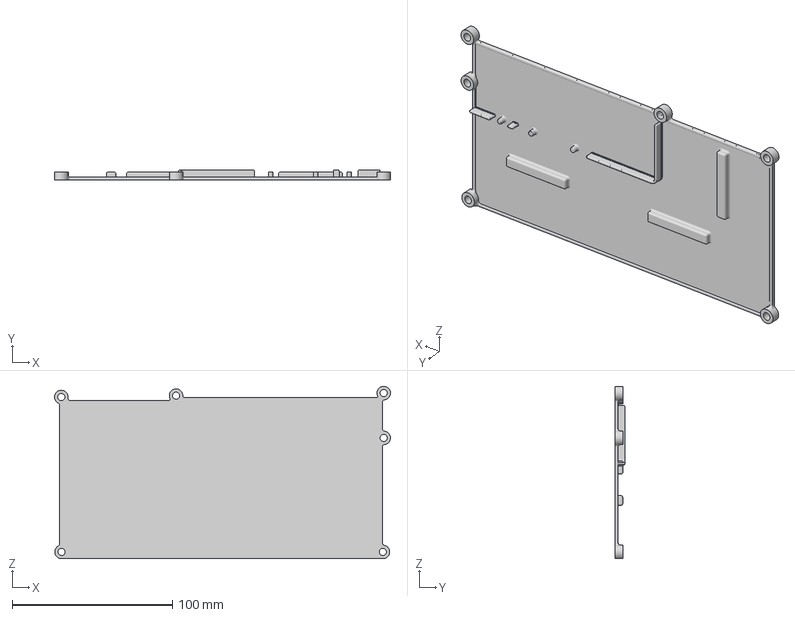
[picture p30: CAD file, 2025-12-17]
src/Enclosure-Design/3D Print/Insulator.3mf
209.9 x 6.25 x 107.7 mm

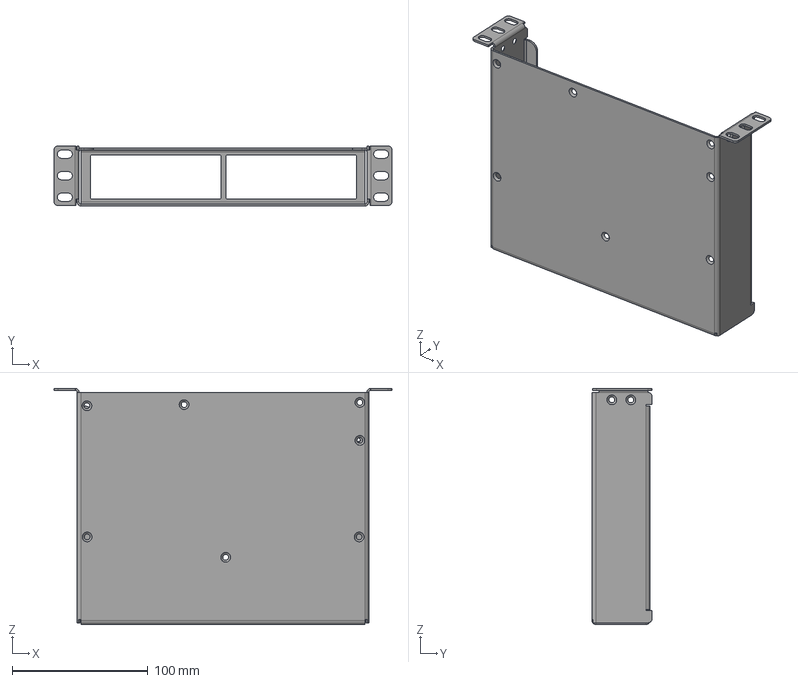
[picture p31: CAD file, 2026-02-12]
src/Enclosure-Design/SheetMetal/Bottom_Enclosure/ENERGIS - Bottom Sheetmetal Enclosure.step
249.4 x 44.4 x 174.3 mm

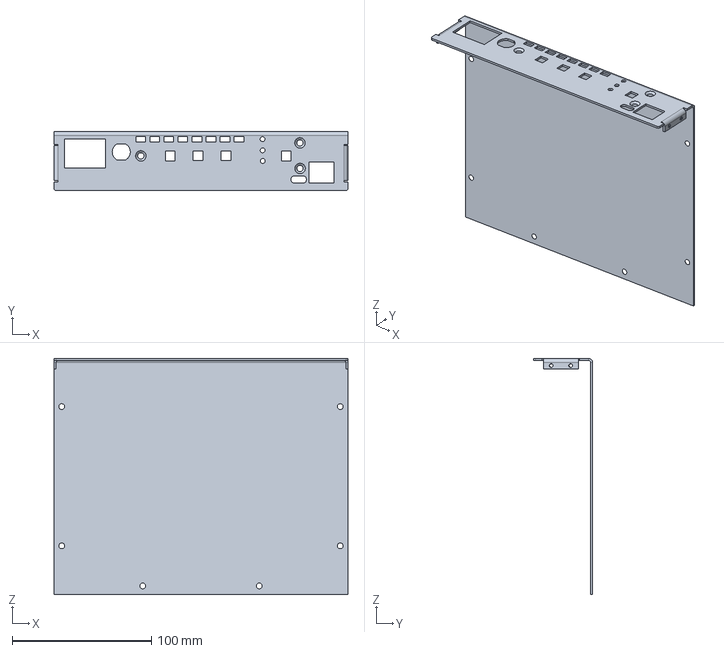
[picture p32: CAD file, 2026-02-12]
src/Enclosure-Design/SheetMetal/Top_Enclosure/ENERGIS - Top Sheetmetal Enclosure.step
211.2 x 42.7 x 169.6 mm

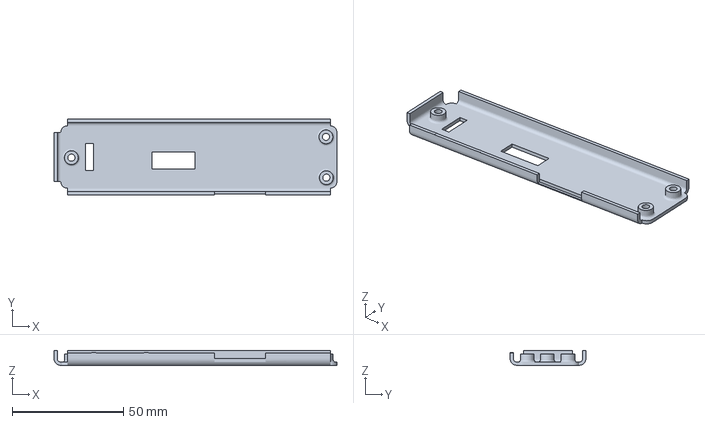
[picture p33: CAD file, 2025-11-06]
src/Enclosure-Design/Shielding/DisplayBoard_Shielding.3mf
127.0 x 34.0 x 6.61 mm

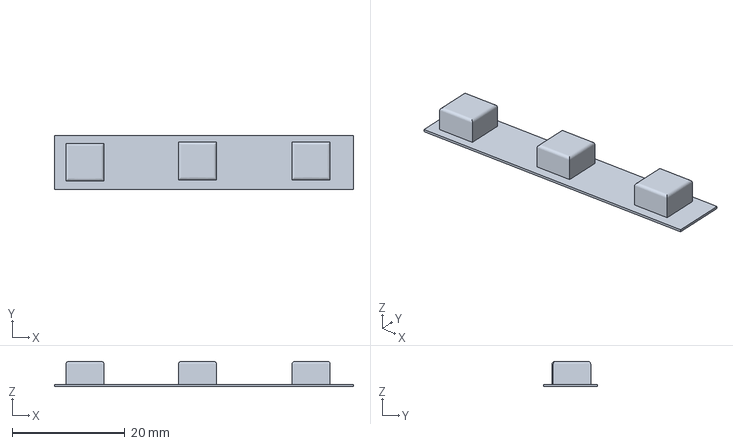
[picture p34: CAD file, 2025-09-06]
src/Enclosure-Design/3D Print/Buttons.3mf
53.1 x 9.65 x 4.50 mm

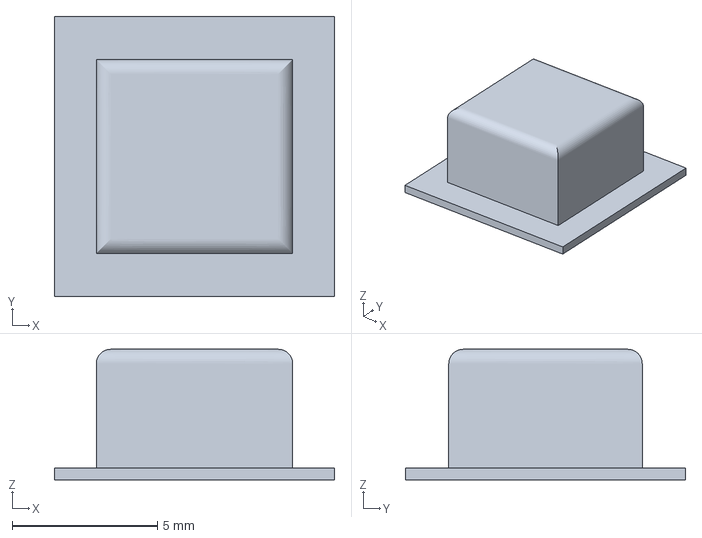
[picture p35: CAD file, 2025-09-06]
src/Enclosure-Design/3D Print/Button_small.3mf
9.65 x 9.65 x 4.50 mm

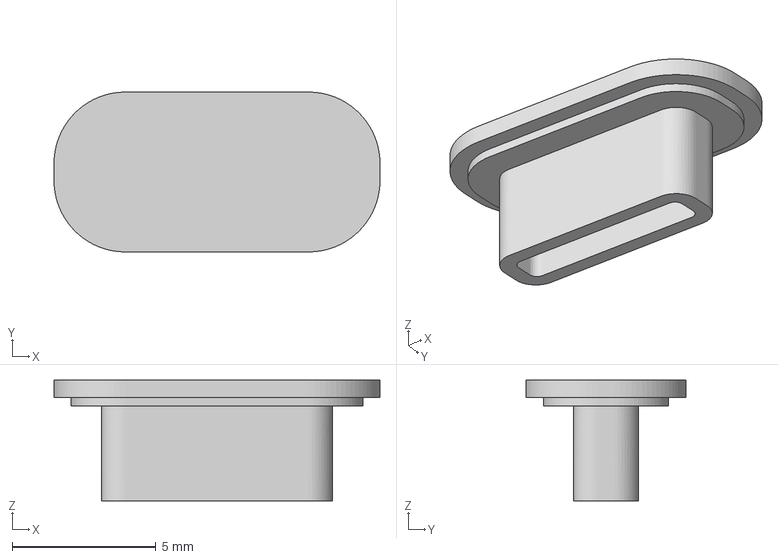
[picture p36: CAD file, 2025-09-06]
src/Enclosure-Design/3D Print/USB-C Cover.3mf
11.3 x 5.56 x 4.21 mm

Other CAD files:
src/Enclosure-Design/Shielding/DisplayBoard_Shielding.dxf
src/Enclosure-Design/Shielding/MainBoard_Shielding.dxf

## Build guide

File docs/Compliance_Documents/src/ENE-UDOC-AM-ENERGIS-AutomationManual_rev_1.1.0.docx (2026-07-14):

Automation Manual

ENERGIS

19IN Managed PDU

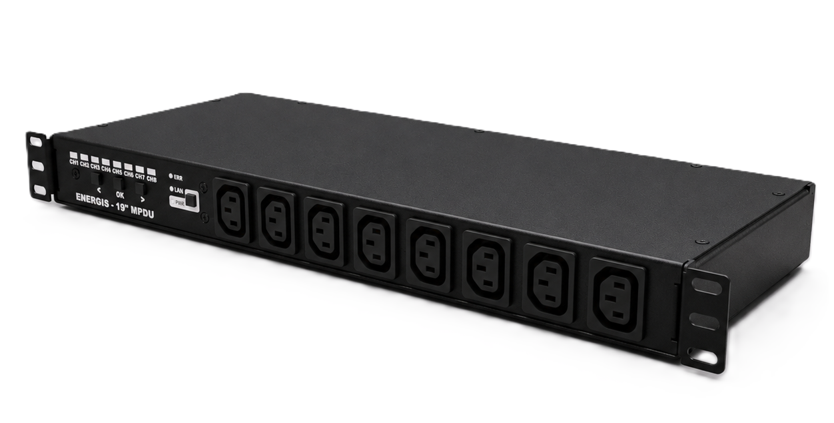
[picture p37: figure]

Revision: 1.1.0

Revision History

A revision is a new edition of the document and affects all sections of this document.

Version | Date | Responsible | Modification
1.0.0 | 12.12.2025 | David Sipos | Initial creation of the document
1.1.0 | 13.01.2026 | David Sipos | Added Software version 1.1.0 changes

Content

# 1. Overview

The ENERGIS managed PDU is a rack‑mount power distribution unit that allows you to switch eight AC outlets individually and monitor voltage, current, power and uptime for each channel. The unit is built around a RP2040 microcontroller running FreeRTOS and communicates over Ethernet and serial. All relays are electromechanical and each channel is designed to handle 16A. HLW8032 power‑metering chips measure the AC lines, individually per channel.

The PDU can be controlled locally via the front panel, remotely via a built‑in HTTP server and SNMP agent, or through a USB serial console. This manual explains how to connect the unit, configure it and use these interfaces to integrate the PDU into any automation system.

## 1.1 Installation and Setup

### 1.1.1 Electrical and Network Connections

1. Mounting and power – Install the PDU into a 19‑inch equipment rack. Connect the supplied AC power cord to the mains and attach your load devices to the eight IEC outlets. Each relay is rated 16A. The PDU inlet is 16A max, so the sum of all channels must not exceed 16A
2. Networking – Plug an Ethernet cable into the RJ‑45 jack. By default, the PDU is programmed to use static IP Address, which can be found on the bottom of the device. The network settings can be read and changed via the web interface or the serial console (see below).
3. USB/serial – The PDU exposes its console over USB‑CDC on the USB‑C port. The serial interface operates at 115 200 baud, 8‑N‑1. Connect the USB‑C port to a host computer and open a terminal program (PuTTY, screen, minicom, etc.); the PDU enumerates as a CDC device without drivers. Note: The internal HLW8032 power meter uses UART0 at 4 800 baud and it is NOT exposed externally.

### 1.1.2 First Boot

On first boot the PDU performs a self‑test, initializes the display and relays and loads configuration from its internal EEPROM. The internal power monitor performs a self-check; this makes the Power LED turns on. The eight outlet LEDs will play a pattern and the network LED will come on once a link is detected.

# 2. Local Operation

## 2.1 Front Panel Buttons and LEDs

When the device is powered, any interaction with any buttons (Left, Set, Right) will start a 10s selection window, in which the currently selected channel is shown by a blinking orange light. After 10 seconds of inactivity the selection times out and no channel is highlighted.

Each channel has two indicators: a green LED showing whether the channel is on or off. An orange LED showing which channel is currently selected. Within the selection window, the user is able to turn on and off any channel.

Status LEDs:

- PWR LED indicates that the PDU is energized, and the internal power is within the expected range.
- ETH LED lights when a link is established on the Ethernet port.
- ERR LED lights if an internal error is detected; clear it with a long press of the Set button.

## 2.2 Button functions:

- Left / Right: Within the selection window, use these buttons to move the selection highlight across the eight channel status LEDs. The highlight wraps around after channel 8.
- Set:
  - Outside the selection window, a short press on any button only opens the 10 s window (no step, no toggle).
  - Inside the selection window, a short‑press toggles the currently selected channel on/off.
  - Anytime, a long press (>1 s) clears the fault LED.
- PWR:
  - Long press (>2s) when the device is powered initiates the low power sleep mode. The PWR LED blinks every second. Short press in active mode has no effect.
  - Short press, when the device is in sleep mode wakes up the device and puts it back in active mode. Long press in sleep mode has no effect.

# 3. Command‑Line Interface - Serial

A comprehensive serial console is available over the USB‑C port (USB‑CDC). After connecting with a terminal program at 115200 baud basic system health information can be seen, emitted every 60 seconds. Type help to list commands.

## 3.1 Command list

Command | Description | Example

GENERAL COMMANDS
HELP | Show available commands and syntax
SYSINFO | Show system information
GET_TEMP | Show MCU temperature
REBOOT | Reboot the PDU. Changes to network settings take effect after reboot.
BOOTSEL | Put the MCU into boot mode
CLR_ERR | Clears all errors
RFS | Restore Factory Settings

OUTPUT CONTROL AND MEASUREMENT
SET_CH <ch> <STATE> | Set channel (1–8) to (0|1|ON| OFF|ALL) | SET_CH 1 1
GET_CH <ch> | Read current state of channel <ch> (1-8|ALL) | GET_CH 3
OC_STATUS | Show overcurrent protection status
OC_RESET | Manually clear overcurrent lockout
READ_HLW8032 | Read power data for all channels
READ_HLW8032 <ch> | Read power data for (1-8) | READ_HLW8032 2
CALIBRATE <ch> <V> <I> | Start single (1-8) calibration on given voltage and current | CALIBRATE 2 0 0
AUTO_CAL_ZERO | Zero-calibrate all channels.
AUTO_CAL_V <voltage> | Voltage-calibrate all channels. | AUTO_CAL_V 230
AUTO_CAL_I <current> <ch> | Current-calibrate single channel (1–8). Requires known load | AUTO_CAL_I 0.5 2
SHOW_CALIB <ch> | Show calibration data (1-8|ALL) | SHOW_CALIB 5

NETWORK SETTINGS
NETINFO | Display the current IP, subnet mask, gateway and DNS addresses.
SET_IP <ip> | Set a static IP address. Requires reboot. | SET_IP 10.10.0.67
SET_SN <mask> | Set the subnet mask. | SET_SN 255.255.255.0
SET_GW <gw> | Set the default gateway. | SET_GW 192.168.1.1
SET_DNS <dns> | Set the DNS server. | SET_DNS 8.8.8.8
CONFIG_NETWORK <ip$sn$gw$dns> | Configure all network settings. | CONFIG_NETWORK 254.176.0.2$255.255.255.0$254.176.0.1$1.1.1.1

# 4. HTTP API

The embedded HTTP/1.1 server listens on port 80 and serves both JSON endpoints under /api/... and a few HTML pages for browsers. All responses include:

- Connection: close
- Cache-Control: no-cache
- Access-Control-Allow-Origin: * (CORS enabled for any origin)

Status codes (summary)

- GET /api/status → 200 OK (JSON)
- GET /api/settings → 200 OK (JSON)
- POST /api/control → 200 OK with text body OK\n; 400 Bad Request if body missing; 503 Service Unavailable when overcurrent lockout blocks switching
- POST /api/settings → 204 No Content (changes are applied immediately; see notes)
- Preset & automation endpoints:
  - GET /api/config-presets → 200 OK (JSON; may include Retry-After: 1 while presets initialize)
  - POST /api/config-presets → 200 OK on success; 400 on malformed/missing fields; 500 on save error
  - POST /api/apply-config → 200 OK on success; 400 invalid/missing id; 503 overcurrent lockout; 500 apply failure
  - POST /api/startup-config → 200 OK on success; 400 invalid/missing parameters; 500 failure

Notes

- JSON responses use Content-Type: application/json. The success body for POST /api/control is text/plain (OK\n).
- Static HTML pages may be served gzipped with Content-Encoding: gzip

## 4.1 GET /api/status

Returns live telemetry and system state.

Response JSON shape:

- channels: array (8) of per-channel objects: {

"voltage": float,

"current": float,

"uptime": uint,

"power": float,

"state": bool,

"label": string

}

- internalTemperature: float - device die temperature converted to the user’s unit (https://tttech365-my.sharepoint.com/personal/david_sipos_tttech_com/Documents/Microsoft%20Copilot%20Chat%20Files/status_handler.c)
- temperatureUnit: "°C" | "°F" | "K"
- systemStatus: "OK" | "WARNING" | "LOCKOUT" (derived from overcurrent state)
- overcurrent: object:

{

"state": "NORMAL"|"WARNING"|"CRITICAL"|"LOCKOUT"|"UNKNOWN",

"total_current_a": float,

"limit_a": float,

"warning_threshold_a": float,

"critical_threshold_a": float,

"recovery_threshold_a": float,

"switching_allowed": true|false,

"trip_count": integer,

"region": "EU"|"US"

}

Example:

curl.exe -s http://<pdu-ip>/api/status

Response:

{

"channels": [

{ "voltage": 229.987, "current": 0.120, "uptime": 12, "power": 27.598,

"state": true, "label": "CH1" },

{ "voltage": 229.954, "current": 0.000, "uptime": 0, "power": 0.000,

"state": false, "label": "" }

/* ... 6 more ... */

],

"internalTemperature": 26.970,

"temperatureUnit": "°C",

"systemStatus": "OK",

"overcurrent": {

"state":"NORMAL",

"total_current_a":0.12,

"limit_a":10.0,

"warning_threshold_a":9.00,

"critical_threshold_a":9.50,

"recovery_threshold_a":8.50,

"switching_allowed":true,

"trip_count":0,

"region":"EU"

}

}

## 4.2 POST /api/control

Controls relay states and channel labels via form-urlencoded data.

Form fields

- channelN (N = 1..8):
  - "on" → turn channel ON
  - anything else or omitted → OFF (Omitting a channel means it is forced OFF.)
- labelN (N = 1..8): optional; set channel label (max 25 chars); empty value clears it.

Overcurrent guard

If any channel would transition from OFF→ON while overcurrent lockout is active, the request is rejected with 503 Service Unavailable and a JSON error body.

Examples

Turn channels 1 and 3 ON (others forced OFF)

curl.exe -s -o $null -w "%{http_code}`n" -X POST "http://<pdu-ip>/api/control" --data "channel1=on&channel3=on"

Turn channel 3 OFF (others remain OFF by omission):

curl.exe -s -o /dev/null -w "%{http_code}\n" -X POST "http://<pdu-ip>/api/
control” --data "channel3="

Set label for channel 1 and turn it ON:

curl.exe -s -o /dev/null -w "%{http_code}\n" -X POST "http://<pdu-ip>/api/
control" --data "channel1=on&label1=Router PSU"

Responses

- Success: 200 OK with body OK\n (text/plain)
- Missing body: 400 Bad Request with JSON error
- Overcurrent lockout: 503 Service Unavailable with JSON error

## 4.3 GET /api/settings

Returns the stored network configuration and user preferences plus device identity and limits).

Response JSON fields

{

"ip": "a.b.c.d",

"gateway": "a.b.c.d",

"subnet": "a.b.c.d",

"dns": "a.b.c.d",

"mac": "AA:BB:CC:DD:EE:FF",

"device_name": "ENERGIS-<ver>",

"location": "Location",

"temp_unit": "celsius" | "fahrenheit" | "kelvin",

"temperature": <number in selected unit>,

"serial_number": "<string>",

"firmware_version": "<string>",

"hardware_version": "<string>",

"device_region": "EU" | "US" | "UNKNOWN",

"current_limit": "<n.n A>",

"warning_limit": "<n.nn A>",

"critical_limit": "<n.nn A>"

}

curl.exe -s "http://<pdu-ip>/api/settings"

Example response:

{

"ip":"192.168.0.12",

"gateway":"192.168.0.1",

"subnet":"255.255.255.0",

"dns":"8.8.8.8",

"mac":"AA:BB:CC:DD:EE:FF",

"device_name":"ENERGIS-1.1.0",

"location":"Location",

"temp_unit":"celsius",

"temperature":33.35,

"serial_number":"<serial>",

"firmware_version":"<fw>",

"hardware_version":"<hw>",

"device_region":"EU",

"current_limit":"10.0 A",

"warning_limit":"9.00 A",

"critical_limit":"9.50 A"

}

## 4.4 POST /api/settings

Updates network parameters and user preferences. Fields include:

- ip, subnet, gateway, dns
- device_name, location
- temp_unit (celsius, fahrenheit, or kelvin)

Changes are saved to EEPROM; the device responds 204 No Content and then reboots.

curl.exe -s -o $null -w "%{http_code}`n" -X POST "http://<pdu-ip>/api/settings" ^
--data "ip=192.168.0.12&gateway=192.168.0.1&subnet=255.255.255.0&dns=8.8.8.8&device_name=ENERGIS&location=Rack1&temp_unit=celsius"

## 4.5 Preset Management

The firmware supports saving, loading, and managing up to 5 relay
configuration presets. These presets allow you to quickly recall and
apply specific ON/OFF states to all 8 channels and optionally set one
preset to be automatically applied at startup.

### 4.5.1 GET /api/config-presets

Purpose:
Retrieve the list of all saved relay presets and the currently selected startup preset (if any).

Response JSON:

{

"presets": [

{ "id": 0, "name": "All Off", "mask": 0 },

{ "id": 1, "name": "Servers On", "mask": 3 }

// ... up to 5 total

],

"startup": null // or 0..4 if a startup preset is set

}

Each preset object contains:

- id: Preset slot number (0–4)
- name: User-defined name (max 25 characters)
- mask: 8-bit value, each bit representing ON/OFF for channels 1–8 (bit 0 = channel 1, bit 7 = channel 8)

During initial boot or if presets are not yet loaded, the response ma be:

{

"presets": [],

"startup": null,

"pending": true

}

In this case, the HTTP response may also include a Retry-After: 1 header, indicating the client should retry after 1 second.

### 4.5.2 POST /api/config-presets

Purpose:
Create (save) a new preset or delete an existing one.

To save a preset:

- Send a form-encoded POST body with:
  - action=save
  - id=N (0–4)
  - name=<your name> (max 25 chars)
  - mask=<0..255> (bitmask for ON/OFF states)
- The field relay_mask is also accepted as an alias for mask.

Example (save a preset):

curl.exe -s -X POST "http://<pdu-ip>/api/config-presets" --data "action=save&id=2&name=Night Mode&mask=1"

To delete a preset:

- Send:
  - action=delete
  - id=N (0–4)

Example (delete a preset):

curl.exe -s -X POST "http://<pdu-ip>/api/config-presets" --data "action=delete&id=2"

Notes:

- If the name is longer than 25 characters, the request is rejected.
- If required fields are missing or invalid, the server returns 400 Bad Request.
- On EEPROM write failure, the server returns 500 Internal Server Error.
- On success, the response is 200 OK with {"success":true}.

### 4.5.3 POST /api/apply-config

Purpose:
Immediately apply a saved preset to the relay outputs.

How to use:

- Send a form-encoded POST body with:
  - id=N (0–4)

Example:

curl.exe -s -X POST "http://<pdu-ip>/api/apply-config" --data "id=1"

Behaviour:

- The relay states are set according to the preset’s mask.
- If overcurrent lockout is active, the request is rejected with 503 Service Unavailable and a JSON error.
- If the id is missing or invalid, the server returns 400 Bad Request.
- On success, the response is 200 OK with {"success":true}.

### 4.5.4 POST /api/startup-config

Purpose:
Set or clear which preset (if any) should be automatically applied at device startup.

To set a startup preset:

- Send:
  - id=N (0–4)

Example:

curl.exe -s -X POST "http://<pdu-ip>/api/startup-config" --data "id=1"

To clear the startup preset:

- Send:
  - action=clear

Example:

curl.exe -s -X POST "http://<pdu-ip>/api/startup-config" --data "action=clear"

Behaviour:

- Only one startup preset can be set at a time.
- If the request is successful, the response is 200 OK with {"success":true}.
- If parameters are missing or invalid, the server returns 400 Bad Request.
- On EEPROM write failure, the server returns 500 Internal Server Error.

Summary Table

Endpoint | Purpose | Required Fields | Success Response | Error Codes
GET /api/config-presets | List all presets & startup | – | 200 OK (JSON) | –
POST /api/config-presets | Save or delete a preset | action, id, (name, mask) | 200 OK (JSON) | 400, 500
POST /api/apply-config | Apply a preset immediately | id | 200 OK (JSON) | 400, 503, 500
POST /api/startup-config | Set/clear startup preset | id or action=clear | 200 OK (JSON) | 400, 500

# 5. HTML pages

## 5.1 GET /control.html

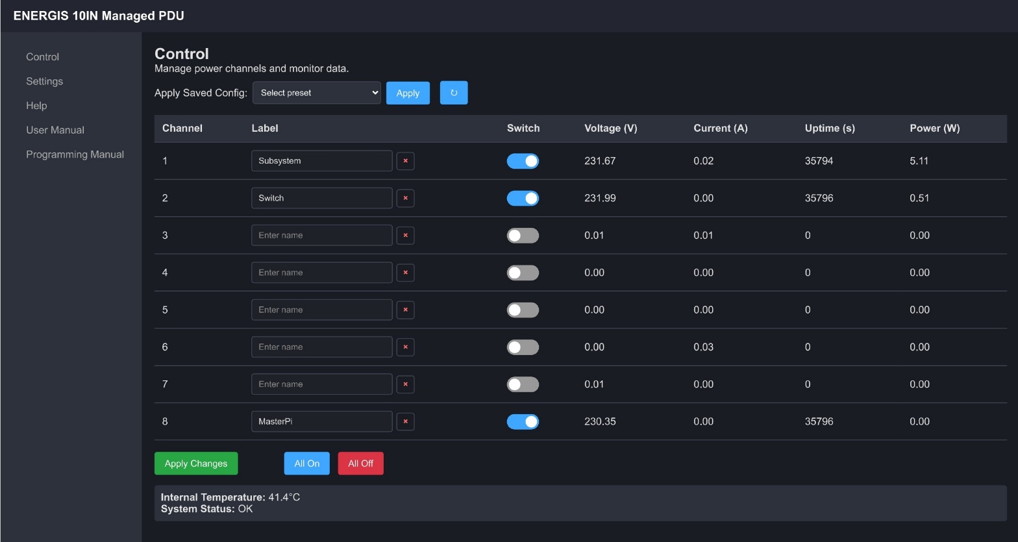
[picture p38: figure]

This is the main control UI.

- It loads in a browser,
- displays the 8 channels,
- and uses /api/status (for live data) and /api/control (for switching/ labels) in the background via JavaScript.

The page is served as HTML (gzipped), with Content-Type: text/html, Cache-
Control: no-cache, and the connection is closed after the response.

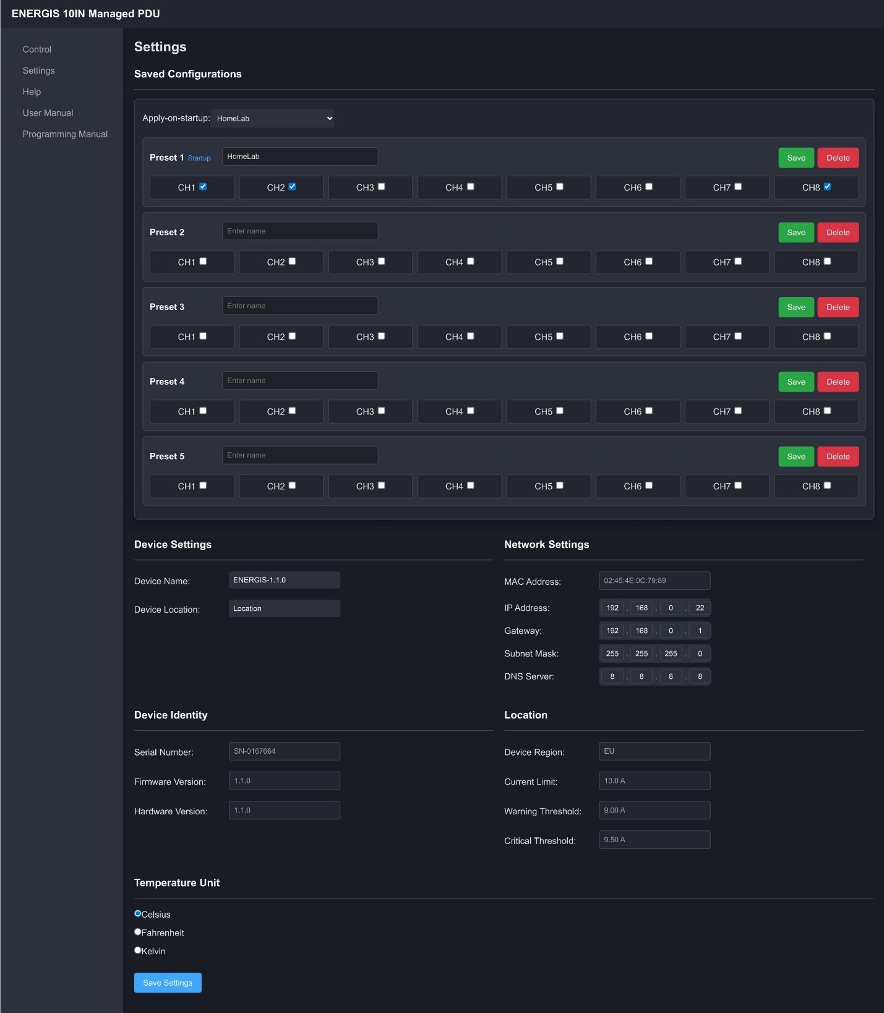
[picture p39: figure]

## 5.2 GET /settings.html

Serves an HTML settings page for use in a browser. It displays current network values and allows updating them via a form. Posts to /api/settings. Served as gzipped HTML.

## 5.3 GET /help.html, /user_manual.html, /automation_manual.html

These endpoints serve small HTML pages.

- /user_manual.html and /automation_manual.html: simple stubs that link to the PDFs hosted on GitHub Pages:
  - User Manual

https://dvidmakesthings.github.io/HW_10-In-Rack_PDU/Manuals/User_Manual.pdf

  - Programming & Interfacing Manual

https://dvidmakesthings.github.io/HW_10-In-Rack_PDU/Manuals/Automation_Manual.pdf

Internet access is required to load those PDFs.

- /help.html: a fast help page that is served fully from the device. It does not depend on internet access and is meant for quick reference and basic troubleshooting when you’re offline.

HTTP behavior: All three return 200 OK, Content-Type: text/html, Cache-Control: no-cache, and the server closes the connection after sending the body.

What’s on /help.html? (fast help, offline-safe)

- Front panel cheatsheet
- Network quick checks
- Web API short guide
- SNMP sanity
- Offline troubleshooting

Why keep Help?

- It gives operators something usable when the site has no internet.
- It points to the full PDFs when WAN is available.
- It reduces support by solving the common “why doesn’t it switch / where’s my IP / why are values zero” cases directly on the box.

# 6. OpenMetrics / Prometheus endpoint

## 6.1 Overview

The ENERGIS PDU exposes a `/metrics` HTTP endpoint that provides runtime telemetry in OpenMetrics/Prometheus text format (version 0.0.4). This plugs directly into Prometheus, Grafana, and similar tools.

## 6.2 Configuration - Accessing the Endpoint

curl.exe http://<pdu-ip-address>/metrics

Example response

# HELP energis_up 1 if the metrics handler is healthy.

# TYPE energis_up gauge energis_up 1

# HELP energis_build_info Build and device identifiers.

# TYPE energis_build_info gauge energis_build_info{version="1.1.0",serial="SN-0167663"} 1

# HELP energis_uptime_seconds_total System uptime in seconds.

# TYPE energis_uptime_seconds_total counter energis_uptime_seconds_total 27 ...

# HELP energis_channel_state Relay state (1=ON, 0=OFF).

# TYPE energis_channel_state gauge energis_channel_state{ch="1"} 1

# HELP energis_channel_telemetry_valid 1 if cached telemetry for channel is fresh.

# TYPE energis_channel_telemetry_valid gauge energis_channel_telemetry_valid{ch="1"} 1

# HELP energis_channel_voltage_volts Channel voltage.

# TYPE energis_channel_voltage_volts gauge energis_channel_voltage_volts{ch="1"} 0.000

# HELP energis_channel_current_amps Channel current.

# TYPE energis_channel_current_amps gauge energis_channel_current_amps{ch="1"} 0.000

# HELP energis_channel_power_watts Active power per channel.

# TYPE energis_channel_power_watts gauge energis_channel_power_watts{ch="1"} 0.000

# HELP energis_channel_energy_watt_hours_total Accumulated energy per channel.

# TYPE energis_channel_energy_watt_hours_total counter energis_channel_energy_watt_hours_total{ch="1"} 0.000

HTTP Response:

- 200 OK on success, with Content-Type: text/plain; version=0.0.4; charset=utf-8
- 503 Service Unavailable if the output would overflow the static buffer (encourages retry)
- 404 Not Found if the metrics feature is disabled at compile time

## 6.3 Available Metrics

### 6.3.1 System

energis_up

Health indicator (gauge; 1 if handler responds)

energis_build_info{version,serial}

Build and device info (gauge; always 1)

energis_uptime_seconds_total

Uptime since boot in seconds (counter)

energis_internal_temperature_celsius

Internal MCU temperature, calibrated (gauge)

energis_temp_calibrated

1 if temperature calibration is applied (gauge)

energis_temp_calibration_mode

Calibration mode (0=none, 1=1pt, 2=2pt) (gauge)

energis_vusb_volts

USB rail voltage (gauge)

energis_vsupply_volts

12 V rail voltage (gauge)

energis_http_requests_total

Total HTTP requests served (counter)

### 6.3.2 Per-Channel

energis_channel_state{ch}

Relay state: 1=ON, 0=OFF (gauge)

energis_channel_telemetry_valid{ch}

1 if cached telemetry for channel is fresh (gauge)

energis_channel_voltage_volts{ch}

Channel voltage [V] (gauge)

energis_channel_current_amps{ch}

Channel current [A] (gauge)

energis_channel_power_watts{ch}

Active power [W] (gauge)

energis_channel_energy_watt_hours_total{ch}

Accumulated energy in watt-hours (counter)

Values are served from cached snapshots owned by MeterTask. No direct sensor I/O in the handler. Temperature uses the active calibration. If no calibration is stored, defaults are used.

### 6.3.3 Overcurrent protection

energis_ocp_state {state}

Overcurrent protection state (0=NORMAL,1=WARNING,2=CRITICAL,3=LOCKOUT)

energis_ocp_switching_allowed {state}

Switching allowed (1=yes,0=no)

energis_ocp_total_current_amps {value}

Total measured current value in Amps (A)

energis_ocp_limit_amps {value}

Configured current limit

- EU Version (IEC/ENEC): 15.0A maximum
- US Version (UL/CSA): 20.0A maximum

energis_ocp_warning_threshold_amps {value}

Warning threshold, Limit - 1A

energis_ocp_critical_threshold_amps {value}

Critical threshold Limit - 0.5A

energis_ocp_recovery_threshold_amps {value}

Recovery threshold Limit – 1.5A

energis_ocp_trip_count_total {cnt}

Overcurrent trips since boot

energis_ocp_last_trip_ms {t}

Timestamp of last trip (ms since boot)

## 6.4 Prometheus Integration

Add to `prometheus.yml`:

scrape_configs:

- job_name: 'energis-pdu'

scrape_interval: 15s

scrape_timeout: 10s

metrics_path: /metrics

static_configs:

- targets: ['192.168.0.22:80']

labels:

location: 'rack-1'

device: 'pdu-main'

Example Alerts

groups:

- name: energis

rules:

- alert: EnergisHighTemp

expr: energis_internal_temperature_celsius > 70

for: 2m

labels: {severity: warning}

annotations:

summary: "ENERGIS MCU hot >70C"

- alert: EnergisVsupplyLow

expr: energis_vsupply_volts < 10.8

for: 1m

labels: {severity: critical}

annotations:

summary: "ENERGIS 12V rail low"

- alert: EnergisNoTelemetry

expr: sum(energis_channel_telemetry_valid) < 8

for: 2m

labels: {severity: warning}

annotations:

summary: "ENERGIS channel telemetry not fully valid"

## 6.5 Performance

- Static buffer ~8 KB. No heap allocations.
- Non-blocking, minimal CPU load.
- Typical response time < 50 ms
- If the output would overflow the buffer, the handler returns **503** to encourage a retry instead of serving a partial payload.

## 6.6 Implementation Notes

- Reads from MeterTask_GetTelemetry() and MeterTask_GetSystemTelemetry()
- Uses atomic counters for request accounting.
- OpenMetrics text format compatible with Prometheus 0.0.4.

# 7. SNMP interface

This firmware exposes a compact SNMPv1 agent (community public). A static table binds each OID to a getter (and sometimes a setter). The table itself carries the SNMP type and the maximum response length; the getters in the submodules return the bytes to match that declaration. Identity (MIB-II system) lives alongside a private enterprise subtree at 1.3.6.1.4.1.19865 for

- outlets,
- power telemetry,
- rails/temperature, and
- a read-only mirror of network settings.

No request performs heavy work: outlet writes toggle state immediately; reads return cached or computed values with fixed, short encodings.

Two encoding patterns matter:

- Outlet states are INTEGER (4 bytes):
  - GET returns a 32-bit 0 or 1,
  - SET treats any non-zero as “on”.

Group controls are also typed as INTEGER.

- Measurements (power, rails, temperature, etc.) and network values are OCTET STRINGs containing ASCII like "230.12" or "192.168.0.50". Parse as text. Buffers are small (≤16 bytes).

## 7.1 Submodules

System & table layer

Owns the SNMP community (public), publishes the MIB-II system group (sysDescr, sysObjectID=enterprise 1.3.6.1.4.1.19865, sysUpTime, sysContact, sysSN, sysLocation, sysServices), and wires all private OIDs to domain getters/setters. It also defines an initial warmStart trap helper under the same enterprise. The table is “dumb”: it declares type/length and calls into the right function; logic lives in the domain modules.

Key OIDs (system):

- 1.3.6.1.2.1.1.1.0 sysDescr (string)
- 1.3.6.1.2.1.1.2.0 sysObjectID = 1.3.6.1.4.1.19865
- 1.3.6.1.2.1.1.3.0 sysUpTime (TimeTicks)
- 1.3.6.1.2.1.1.4.0 sysContact (string)
- 1.3.6.1.2.1.1.5.0 sysSN (string)
- 1.3.6.1.2.1.1.6.0 sysLocation (string)
- 1.3.6.1.2.1.1.7.0 sysServices (INTEGER)

## 7.2 Outlet control (read/write)

Eight independent channels and two group triggers. Per-channel GET returns a 4-byte INTEGER (0/1). Per-channel SET: 0 → off, any non-zero → on. Group triggers apply the action when you write any non-zero, and their GET encodes whether all channels currently match that state. Internally, OID channels are 1..8; drivers use 0..7.

### 7.2.1 Per-channel state (INTEGER):

- Format:

.1.3.6.1.4.1.19865.2.<ch>.0 where <ch>=1..8

  GET: int32 0 or 1
  SET: i 0 or i 1 (non-zero treated as 1) Example (CH3):

snmpget -v1 -c public -Oqv <pdu-ip> 1.3.6.1.4.1.19865.2.3.0

### 7.2.2 Group controls (INTEGER):

- All OFF (trigger):

.1.3.6.1.4.1.19865.2.9.0

GET: '1' only if every channel is off;
SET: non-zero → force all off.

- All ON (trigger):

.1.3.6.1.4.1.19865.2.10.0

GET: '1' only if every channel is on;

SET: non-zero → force all on.

Implementation detail: per-channel GET always returns exactly 4 bytes to match the table’s INTEGER declaration. Group GET encodes '0'/'1' via a one-byte helper but the table still declares INTEGER. Managers will still treat these as INTEGER because the table declares INTEGER, the single-byte helper is an internal optimization.

## 7.3 Power and energy telemetry

Six metrics per channel, all as ASCII strings in OCTET STRINGs, pulled from the cached metering snapshot (no blocking I/O on the SNMP path). If the cache isn’t valid yet, you’ll see zeros by design.

### 7.3.1 Per-channel telemetry:

- Voltage [V]: .1.3.6.1.4.1.19865.5.<ch>.1.0 → "%.2f"
- Current [A]: .1.3.6.1.4.1.19865.5.<ch>.2.0 → "%.3f"
- Power [W]: .1.3.6.1.4.1.19865.5.<ch>.3.0 → "%.1f"
- Power factor: .1.3.6.1.4.1.19865.5.<ch>.4.0 → "%.3f"
- Energy [kWh]: .1.3.6.1.4.1.19865.5.<ch>.5.0 → "%.3f"
- Uptime [s]: .1.3.6.1.4.1.19865.5.<ch>.6.0 → "12345" (decimal ASCII)

Quick sense of outputs for channel 1:

snmpget -v1 -c public -Oqv <pdu-ip> 1.3.6.1.4.1.19865.5.1.1.0 # "230.12"
snmpget -v1 -c public -Oqv <pdu-ip> 1.3.6.1.4.1.19865.5.1.2.0 # "0.534"
snmpget -v1 -c public -Oqv <pdu-ip> 1.3.6.1.4.1.19865.5.1.3.0 # "85.3"

Formatting is centralized (ftoa, u32toa) and capped at 16 bytes per response. Precision is uniform across channels and metrics.

## 7.4 Rails and temperature

On-die temperature and board rails, formatted as short ASCII. The module samples Pico ADC for the die sensor (with a tiny low-pass/settle step) and uses HAL helpers for external rails. Everything fits in 16 bytes.

OIDs:

- Die sensor (voltage): .1.3.6.1.4.1.19865.3.1.0 → "%.5f"
- Die temperature [°C]: .1.3.6.1.4.1.19865.3.2.0 → "%.3f"
- V_SUPPLY [V]: .1.3.6.1.4.1.19865.3.3.0 → "%.3f"
- V_USB [V]: .1.3.6.1.4.1.19865.3.4.0 → "%.3f"
- V_SUPPLY divider tap: .1.3.6.1.4.1.19865.3.5.0
- V_USB divider tap: .1.3.6.1.4.1.19865.3.6.0
- Core VREG [V]: .1.3.6.1.4.1.19865.3.7.0 → "%.2f"
- Core VREG status: .1.3.6.1.4.1.19865.3.8.0 → "OK" | "Overload" | "Hi-Z" | "Unknown"
- Bandgap ref: .1.3.6.1.4.1.19865.3.9.0
- USB PHY rail: .1.3.6.1.4.1.19865.3.10.0
- IO rail: .1.3.6.1.4.1.19865.3.11.0

## 7.5 Network configuration mirror

Reflects the persisted network config (EEPROM) as dotted-decimal strings. These are not writable via SNMP in this build.

OIDs:

- IP address: .1.3.6.1.4.1.19865.4.1.0 → "A.B.C.D"
- Subnet mask: .1.3.6.1.4.1.19865.4.2.0 → "A.B.C.D"
- Gateway: .1.3.6.1.4.1.19865.4.3.0 → "A.B.C.D"
- DNS server: .1.3.6.1.4.1.19865.4.4.0 → "A.B.C.D"

## 7.6 Overcurrent

Overcurrent protection status is exposed under the enterprise subtree .1.3.6.1.4.1.19865.6.*.0. It reports the live OCP status snapshot (no blocking I/O on the SNMP path). Integer values use SNMP INTEGER (4 bytes). Floating values are returned as ASCII strings in OCTET STRINGs (fits in 16 bytes). If OCP is not initialized yet, values fall back to safe defaults (typically zeros / NORMAL).

### 7.6.1 OCP status OIDs

- OCP state: .1.3.6.1.4.1.19865.6.1.0 → INTEGER Values:
  - 0 = NORMAL
  - 1 = WARNING
  - 2 = CRITICAL
  - 3 = LOCKOUT
- Total current [A]: .1.3.6.1.4.1.19865.6.2.0 → "%.3f" (ASCII)
- Current limit [A]: .1.3.6.1.4.1.19865.6.3.0 → "%.2f" (ASCII)
- Warning threshold [A]: .1.3.6.1.4.1.19865.6.4.0 → "%.2f" (ASCII)
- Critical threshold [A]: .1.3.6.1.4.1.19865.6.5.0 → "%.2f" (ASCII)
- Recovery threshold [A]: .1.3.6.1.4.1.19865.6.6.0 → "%.2f" (ASCII)
- Last tripped channel: .1.3.6.1.4.1.19865.6.7.0 → INTEGER Values:
  - 1..8 = outlet index that was switched OFF by OCP
  - 0 = not available / fallback action used
- Trip count: .1.3.6.1.4.1.19865.6.8.0 → INTEGER Monotonic counter since boot.
- Last trip time [ms since boot]: .1.3.6.1.4.1.19865.6.9.0 → INTEGER
- Switching allowed: .1.3.6.1.4.1.19865.6.10.0 → INTEGER Values:
  - 0 = switching ON blocked (lockout)
  - 1 = switching allowed

### 7.6.2 Manual OCP reset (SNMP SET)

A write-only control is provided to clear OCP lockout:

- Reset/clear lockout: .1.3.6.1.4.1.19865.6.11.0 → INTEGER (SET) Any non-zero value triggers a lockout clear. Use only after reducing load, otherwise the device may immediately trip again.

## 7.7 Failure modes and things worth knowing

- Type discipline: outlet nodes are 4-byte INTEGERs; telemetry and network are ASCII strings. If your NMS expects numbers everywhere, it will complain on the string nodes. Parse them.
- “All on/off” asymmetry: those two reports aggregate state and execute batch writes on any non-zero input; 0 is ignored. Verify final state with per-channel GETs if you need certainty.
- Small buffers, fixed precision: string responses are capped at 16 bytes, with formats like "%.2f", "%.3f". If you widen precision in firmware, update the table lengths or you’ll truncate.
- Cached telemetry: power data is a snapshot from the MeterTask cache. Immediately after enabling a channel, it may read "0.000" until the next update. This path never blocks waiting for the meter.
- Network fallback: if EEPROM is blank or inaccessible, the network mirror returns compiled defaults. If your reads show defaults, the storage flow didn’t load.
- Table is authoritative: per-channel outlet GET always returns exactly 4 bytes to match the table’s INTEGER definition, even if the internal code path could compute a one-byte value. Keep your client side tolerant.

## 7.8 Summary

One static table, four domains. Outlets are writable INTEGER scalars at .1.3.6.1.4.1.19865.2.<ch>.0, with two INTEGER triggers for “all off/on.”

Power telemetry is six ASCII string metrics per channel at .1.3.6.1.4.1.19865.5.<ch>.<metric>.0, pulled from a non-blocking cache.

Rails/temperature live under .1.3.6.1.4.1.19865.3.*.0 as short strings.

Network settings are read-only, dotted-decimal strings under .1.3.6.1.4.1.19865.4.*.0, with EEPROM-to-default fallback.

Respect types and 16-byte limits, assume cached updates for measurements, and rely on per-channel reads to verify group actions.

# 8. Support

For firmware updates and source code, visit the project’s GitHub repository. For technical support or to report bugs, contact the maintainer listed in the SNMP sysContact field (dvidmakesthings@gmail.com).

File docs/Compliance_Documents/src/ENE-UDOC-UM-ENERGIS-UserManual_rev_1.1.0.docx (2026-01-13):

USER MANUAL

ENERGIS

10IN Managed PDU

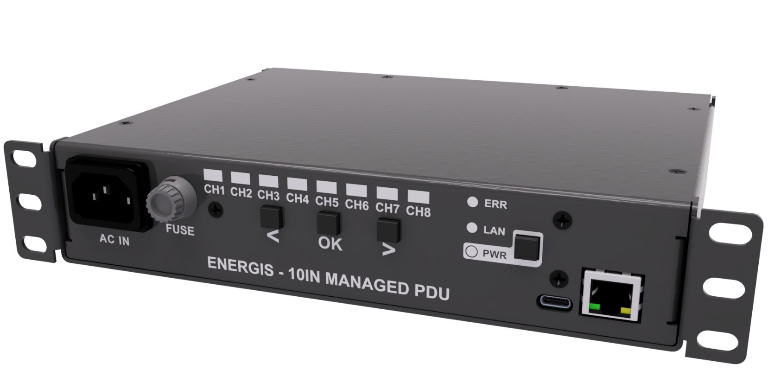
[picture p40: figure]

Revision: 1.1.0

Revision History

A revision is a new edition of the document and affects all sections of this document.

Version | Date | Responsible | Modification
1.0.0 | 12.12.2025 | David Sipos | Initial creation of the document
1.1.0 | 13.01.2026 | David Sipos | Added Software version 1.1.0 changes

# Contents

# 1. Introduction

ENERGIS is an 8-channel managed power distribution unit (PDU) designed for small racks, lab environments and test benches where individual control of outlets and basic power monitoring are required. The device provides eight IEC C13 outlets in a compact 10-inch form factor and is intended to sit close to the equipment it supplies.

Each outlet can be switched independently, and the unit measures voltage, current, power and accumulated uptime per channel. This allows the user to power cycle devices remotely, check that loads are within expected limits and verify that equipment is actually drawing power. Status indicators on the front panel show the state of each outlet and the overall health of the device, giving a quick visual overview without the need for additional tools.

ENERGIS can be operated locally from the front panel or remotely over the network. A built-in web interface provides a simple control and monitoring view in any modern browser, without the need to install software on the host computer. Network settings and basic preferences can also be adjusted through the web interface so that the unit can be integrated into existing infrastructure with fixed addressing or custom naming.

For users who need deeper integration with monitoring and automation systems, ENERGIS also exposes a command line interface over USB, a structured HTTP API, an SNMP interface and an OpenMetrics endpoint suitable for Prometheus and similar tools. These programmable interfaces and their exact behavior are documented in detail in the separate Automation Manual (https://dvidmakesthings.github.io/HW_10-In-Rack_PDU/Manuals/AUTOMATION_MANUAL.pdf).

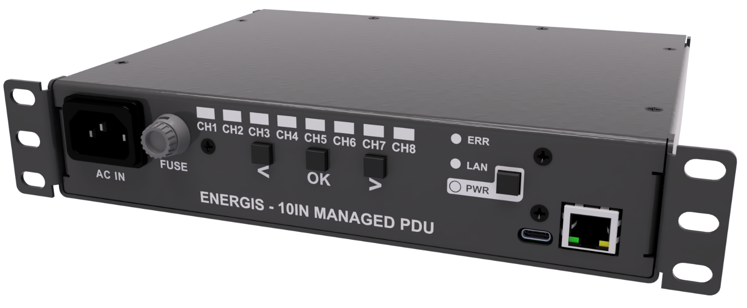
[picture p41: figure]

# 2. Safety and Warnings

This product switches and distributes mains voltage. Incorrect installation or use can lead to electric shock, fire, or damage to connected equipment. Read and follow all instructions in this section before putting ENERGIS into service.

2.1 Intended use

ENERGIS is a rack-mount power distribution unit for indoor IT, lab and similar equipment that is compatible with the local mains voltage and IEC C13 outlets. It is not a household extension cord, not a surge protector, and not a safety device. The unit is not designed or approved for life-support, medical, or any application where loss of power could result in injury or significant damage.

## 2.2 Personnel and access

Installation, wiring and servicing must be carried out only by qualified personnel familiar with mains electrical systems and local regulations.

- Do not open the enclosure. There are no user-serviceable parts inside.
- Servicing with the cover removed must only be performed with the unit fully disconnected from the AC supply.
- Do not modify the enclosure, wiring, connectors or protective earth.

## 2.3 Electrical ratings and loading

- AC input: 85-305 VAC
- Maximum input current: IEC/ENEC: 10A (EU), UL/CSA: 15A (US/CA).
- Maximum per-channel current: IEC/ENEC: 10A (EU), UL/CSA: 15A (US/CA).
- The sum of all active outlet currents must not exceed 10A (IEC/ENEC) or 15A (UL/CSA).

Do not daisy-chain multiple PDUs from a single outlet or feed another distribution strip from ENERGIS. Only connect equipment that is rated for the local mains voltage and fitted with suitable IEC C14 inlets or adapters approved for the load current. Exceeding these limits can overheat wiring and relay contacts and may cause fire or permanent damage to the unit.

## 2.4 Grounding and connection

The AC inlet must be connected to a properly grounded (earthed) mains outlet. Do not defeat the protective earth connection. Use only power cords with an approved plug for your region and with a current rating of at least the device rated input current (10 A for EU, 15 A for US/CA). Ensure that the rack and any metalwork are bonded to protective earth in accordance with applicable local electrical codes.

## 2.5 Environment and mounting

Intended for indoor use in dry locations only. Protect the unit from moisture, condensation, corrosive atmospheres and conductive dust. Operate within a range of 0 °C to 50 °C. At higher temperatures, reduce the total load to avoid overheating.

Mount the unit securely in a 10-inch rack or use it on a stable surface so that it cannot tip or fall. Do not cover the enclosure. Ensure adequate airflow around the unit and any other heat-generating equipment in the rack.

## 2.6 Operation and handling

Treat all outlets as live whenever the PWR indicator is on. Outlets may be switched remotely; equipment can become energized without local interaction at the rack. Before connecting, disconnecting or relocating loads, switch the affected outlet off and, if possible, disconnect the main supply.

Do not operate the unit if the enclosure, AC inlet, outlets or front-panel connectors show signs of damage, discoloration or overheating. Disconnect from mains and have the unit inspected by qualified service personnel.

## 2.7 Symbols

Where the following symbols are used on the product or in this manual, they have the meanings:

WARNING | - Risk of electric shock, fire or personal injury if instructions are ignored.
CAUTION | - Risk of equipment damage or data loss.

Following these safety instructions is a condition of proper use of the ENERGIS PDU.

# 3. Product Overview

ENERGIS is a compact 10-inch rack-mount PDU with individually switchable outlets and basic power monitoring per channel. It is intended to sit close to the equipment it supplies and to be operated either from the front panel or over the network.

## 3.1 Key features

- 8 individually switchable IEC C13 outlets.
- Per-channel indication of voltage, current, power and accumulated uptime.
- Front-panel status LEDs for outlet state, power status, network link and device health.
- Built-in web and SNMP interface for remote control and basic monitoring.
- Static IP configuration by default, changeable via the web interface or console.
- USB-C serial console for local configuration and diagnostics.

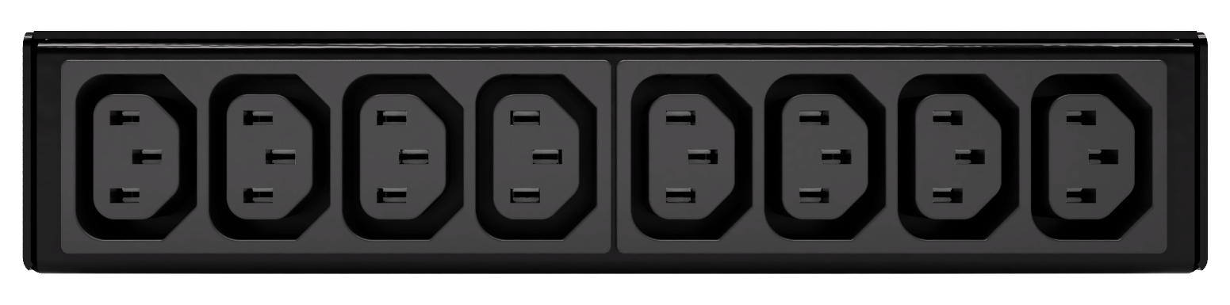
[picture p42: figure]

## 3.2 Rear panel

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
The rear panel carries the eight load outlets.

- Outlet block (CH1-CH8):
  - Eight IEC C13 outlets for powering connected equipment.
  - Outlets are numbered from 1 to 8 on the rear panel to match the channel indicators on the front panel.

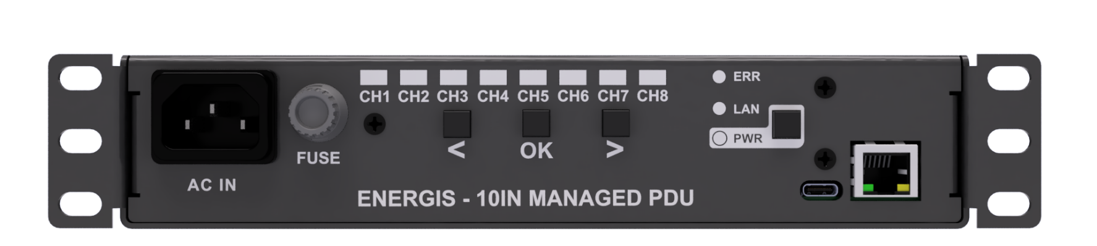
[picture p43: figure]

## 3.3 Front panel

1

2

3

4

5

6

The front panel provides local control and a quick visual overview of the device state.

1. AC inlet: IEC appliance inlet for connection to the mains supply. Use a suitable mains lead rated for the specified input current (see Safety and Specifications).
2. Channel indicators (CH1-CH8): One LED pair per outlet.
- Green LED: shows whether the corresponding outlet is switched on or off.
- Orange LED: used as a selection indicator during the 10 s selection window.
3. Navigation buttons
- < and >: move the active selection between channels during the selection window.
- OK: toggles the currently selected outlet on or off with a short press; used for local control as described in the Operation section.
4. Status LEDs
- ERR: lights when the unit has detected an internal fault condition.
- LAN: indicates that an Ethernet link is present.
- PWR: indicates that the internal power supply is within its expected operating range.
5. Power button
- Long press (>2s) when the device is powered initiates the low power sleep mode. The PWR LED blinks every second. Short press in active mode has no effect
- Short press, when the device is in sleep mode wakes up the device and puts it back in active mode.
6. Connectors
- USB-C: exposes the serial console as a USB-CDC device for configuration and diagnostics.
- RJ-45 Ethernet: network interface for the web interface and remote control.

s

# 4. Installation

This section describes how to put ENERGIS into service: mounting it in the rack, connecting the mains supply, attaching loads and bringing the network and optional USB console online. Read the Safety and Warnings chapter first and follow all local electrical regulations during installation.

## 4.1 Mounting

ENERGIS is intended for use in 10-inch racks and small cabinets. The unit should be mechanically secured before any electrical connections are made, and the mounting position should allow cables to be routed without strain and the front panel to remain visible.

Recommended procedure:

- Install ENERGIS in a suitable 10-inch rack or cabinet using the integrated mounting ears and appropriate screws or cage nuts.
- Support the unit during installation so that no mechanical stress is applied to the front panel, connectors or enclosure.
- Provide adequate clearance above, below and behind the unit for cable routing and basic airflow inside the rack.
- Avoid placing the unit directly above equipment that exhausts hot air upwards, unless the rack cooling is planned for this arrangement.
- Position the unit so that the front panel LEDs and buttons are clearly visible and accessible during normal operation and service.

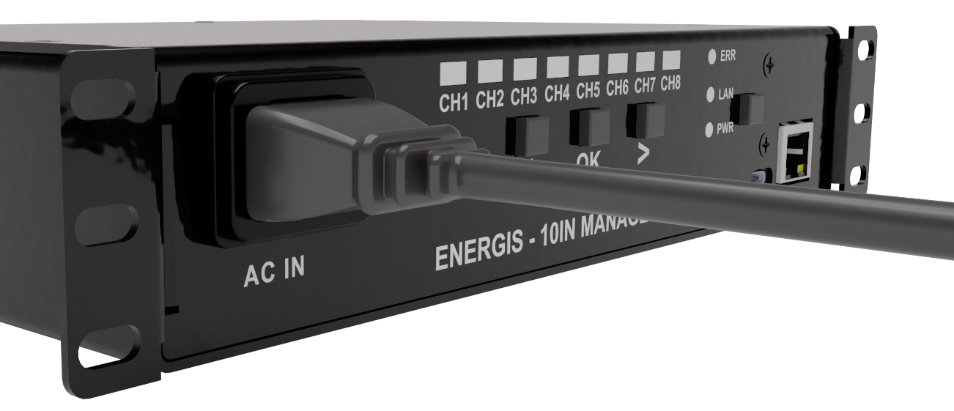
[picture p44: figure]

## 4.2 Power connection

WARNING - Risk of electric shock, fire or personal injury if instructions are ignored. All work on the mains supply must be carried out by qualified personnel.

Before energizing the unit, verify that the local mains voltage matches the rating on the product label. All power connections must be made with the unit mechanically secured in the rack and using cables that are correctly rated for the expected current.

Recommended procedure:

- Verify that the local mains supply matches the voltage indicated on the ENERGIS rating label.
- Connect the AC inlet to a properly grounded mains outlet using a mains lead approved for your region and rated for at least the device rated input current (10A EU, 15A US/CA).
- Ensure that the upstream circuit protection (fuse or breaker) and wiring are suitable for the device rated input current (10A EU, 15A US/CA).
- Observe the overall loading limit: the sum of all active outlet currents must not exceed the device rated input current (10A EU, 15A US/CA).
- After switching on the upstream supply, check that the PWR LED on the front panel lights, indicating that the internal power supply is within its operating range.

## 4.3 Connecting loads

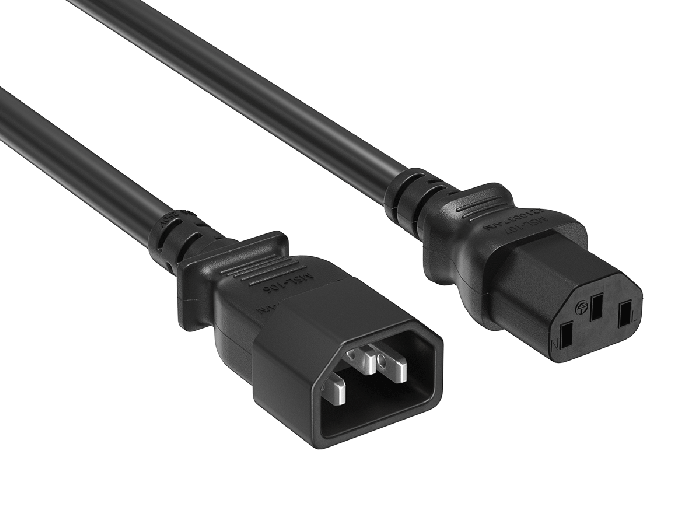
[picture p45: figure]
3ft 14 AWG Computer Power Extension Cord (IEC320 C13 to IEC320 C14) |

The rear panel provides eight IEC C13 outlets for the connected equipment. Loads should be distributed so that the total current remains within the specified limit and the rack wiring is not overstressed. It is good practice to document which device is connected to which channel to avoid confusion during remote operation.

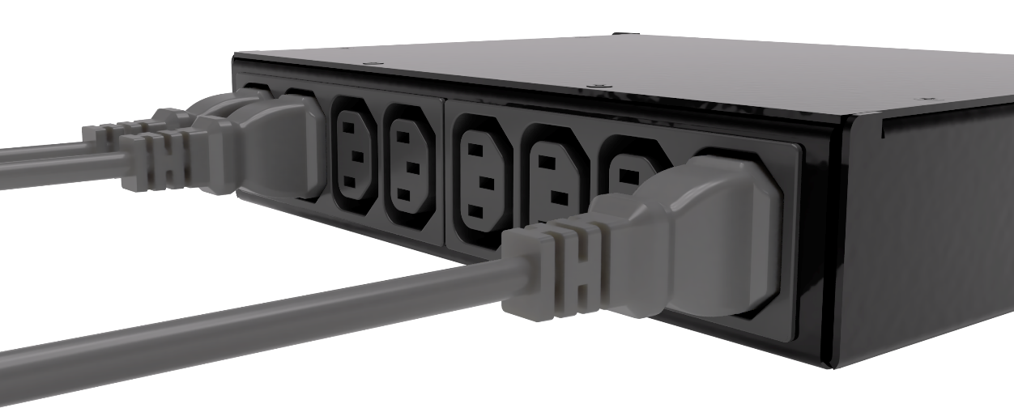
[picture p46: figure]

Recommended procedure:

- Connect equipment to the IEC C13 outlets using IEC C14 cord sets or suitable adapters that are correctly wired and rated for the required current.
- Match the outlet numbering (CH1 to CH8) on the rear panel with your installation documentation so that remote switching commands map to the intended devices.
- Where possible, switch the relevant channel off before plugging in or unplugging a device, to minimize arcing at the connector and avoid unplanned restarts.
- Distribute high-power devices across the outlets in a way that keeps the total current within the inlet rating (10A EU, 15A US/CA) and maintains a reasonable thermal load in the rack.
- Do not daisy chain other PDUs or multi-way extensions from ENERGIS outlets.

WARNING - Risk of electric shock, fire or personal injury if instructions are ignored. All work on the mains supply must be carried out by qualified personnel.

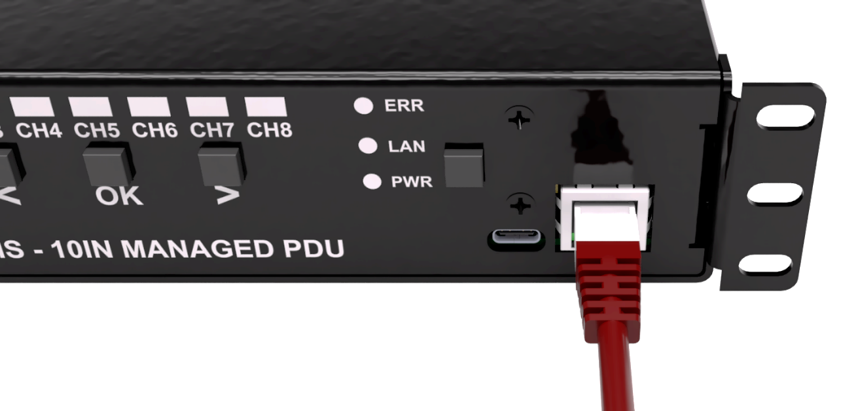
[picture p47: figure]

## 4.4 Network connection

A network connection is required for access to the web interface and for remote monitoring or integration. ENERGIS ships with a static IP configuration that is printed on the product label so that the unit can be reached on a small dedicated segment immediately after installation.

Recommended procedure:

- Connect the RJ-45 Ethernet port on the front panel to a switch or router using a standard twisted-pair Ethernet patch cable (CAT5/CAT5E).
- Confirm that the LAN LED lights, indicating that a physical link is present.
- Read the default static IP address from the label on the underside of the unit and verify that it is valid and non-conflicting on the intended network segment.
- From a host in the same subnet, open a web browser and enter the device IP to access the web interface.
- If your network requires a different static address or DHCP operation, plan the change and apply it later via the Settings page of the web interface, described in section 6.3.

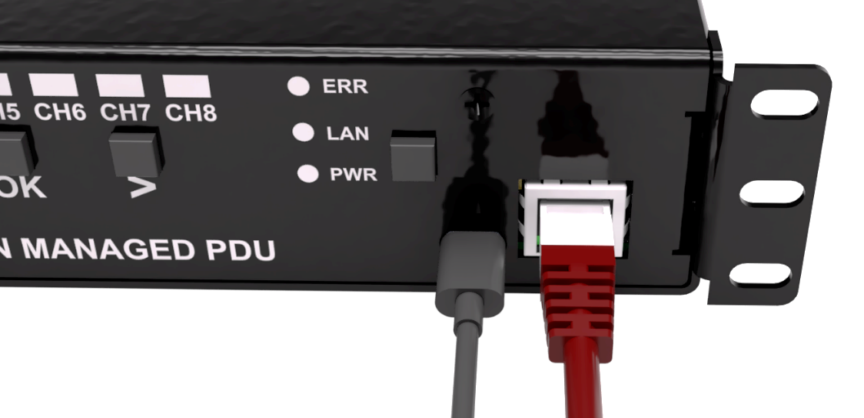
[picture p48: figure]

## 4.5 USB connection

The USB-C connector provides an optional local management path that does not depend on the network. It is intended for commissioning, diagnostics and advanced configuration rather than day-to-day operation.

Recommended procedure:

- If a local console is required, connect the USB-C port on the front panel to a computer using a suitable USB cable.
- Allow the operating system to detect ENERGIS as a USB-CDC (virtual COM) device.
- Open a serial terminal on the host and select the appropriate port with the configured parameters if you need direct console access.
- Use this interface only when necessary; normal operation and basic configuration are normally carried out via the front panel and web interface.
- For the list of available console commands and their detailed syntax, refer to the Automation Manual (https://dvidmakesthings.github.io/HW_10-In-Rack_PDU/Manuals/AUTOMATION_MANUAL.pdf).

# 5. Front Panel Operation

The front panel provides basic local control of all eight outlets and a quick indication of the overall device status. All functions described in this chapter can be used without any network or USB connection.

## 5.1 Channel indicators

Each outlet has a pair of LEDs on the front panel, labelled CH1 to CH8. These LEDs indicate both the switching state of the outlet and, during configuration, which channel is currently selected.

- Green LED (per channel)
  - On: the corresponding outlet is switched on and supplying mains voltage to the rear C13 connector.
  - Off: the outlet is switched off.
- Orange LED (per channel)
  - Off: no selection window is active.
  - Blinking: the channel is currently selected during the 10 s selection window and can be controlled with the buttons.
  - Only one channel is highlighted at a time during normal operation.

The orange “selection” indication is only active while the selection window is open. Outside this window, the orange LEDs remain off and the front panel shows only the on/off state via the green LEDs.

## 5.2 Status indicators

In addition to the per-channel LEDs, three status LEDs show the overall health and connectivity of the unit:

- PWR: Indicates that the internal power supply is present and within its expected operating range. This LED must be lit for the device to function.
- LAN: Indicates that an Ethernet link is detected on the RJ-45 connector. It does not indicate that higher-level protocols (such as IP) are correctly configured, only that a physical link is present.
- ERR: Lights when the unit has detected an internal error condition. The error can be cleared locally with a long press of the Set button (see below). If the LED lights again after clearing, further investigation may be required.

These status indicators allow a quick check of basic conditions (power, network link, fault state) without using the web interface or console.

## 5.3 Selection window and button behavior

The front panel buttons control a time-limited “selection window” during which channels can be chosen and switched. This avoids accidental switching from incidental button presses.

Opening the selection window

- A short press on any button (Left, Right or Set) when no window is active opens a 10 second selection window.
- When the window opens, one channel becomes active and its orange LED starts blinking. No outlets are switched at this point; the first press only enables selection.

If there is no further button activity for 10 seconds, the selection window closes automatically and all orange LEDs turn off. The green on/off indication remains unchanged.

Operation within the selection window: While the selection window is open (orange LED blinking on one channel):

- Left / Right buttons
  - Step the active selection to the previous or next channel.
  - The orange LED moves across the channels to show which outlet is currently selected.
  - The selection wraps around between channel 1 and channel 8.
- Set button (short press)
  - Toggles the currently selected outlet on or off.
  - The corresponding green LED changes state to reflect the new outlet status.
- Set button (long press)
  - A long press (approximately one second) clears the ERR LED if an error condition has been latched.
  - This action does not change the state of any outlet.

Each button press within the window restarts the 10 second timeout. If there is no activity for 10 seconds, the window closes and the orange selection indication turns off.

Power button

Device state | Press type | Behavior
Active | Long press (> 2 s) | Enters low-power sleep mode: all outputs are turned off, and the PWR LED blinks at 0.5 Hz (1 s ON / 1 s OFF). All device functions become unavailable
Active | Short press | No effect.
Sleep | Short press | Wakes the device from sleep and returns to active mode. Normal functionality becomes available again
Sleep | Long press (> 2 s) | No effect.

## 5.4 Examples

The following examples illustrate typical front panel operations.

- Turn outlet 3 on
  1. Press any button to open the selection window. One channel will start blinking orange.
  2. Use the Left/Right buttons until channel 3’s orange LED is blinking.
  3. Press the Set button briefly. The green LED for channel 3 turns on, indicating that the outlet is now supplying power.
- Turn outlet 5 off
  4. Press any button to open the selection window.
  5. Use the Left/Right buttons until channel 5’s orange LED is blinking.
  6. Press the Set button briefly. The green LED for channel 5 turns off, indicating that the outlet is now switched off.
- Clear an error condition
  7. Ensure the front panel ERR LED is lit.
  8. Press and hold the Set button for about one second.
  9. Release the button. The ERR LED turns off to indicate that the error has been cleared.

If the ERR LED lights again after clearing, refer to the troubleshooting and diagnostics sections of this manual or the Automation Manual for further investigation.

# 6. Web Interface (Basic Use)

The web interface provides a convenient way to switch outlets and view basic measurements from any computer on the same network, without installing additional software. This chapter describes only the user-facing pages; protocol-level details are covered in the Automation Manual (https://dvidmakesthings.github.io/HW_10-In-Rack_PDU/Manuals/ENERGIS_AutomationManual_rev_1.0.0.pdf). This chapter covers only the user-facing pages. Protocol-level details and integration options are documented separately.

## 6.1 Accessing the web interface

To use the web interface, you need the IP address of the device.

- The factory-default IP address is printed on the label on the underside of the unit.
- If the address has been changed, it can be checked via the serial console using the NETINFO command (see Automation Manual).

Once you know the IP address:

- Open a web browser on a computer in the same network segment.
- Enter the address in the address bar in the form:

http://<device-ip>/

- The browser loads the main control page. If the page does not load, check the network cabling, verify that the ETH LED is lit and confirm that the PC is in the same subnet.

## 6.2 Control page (/control.html)

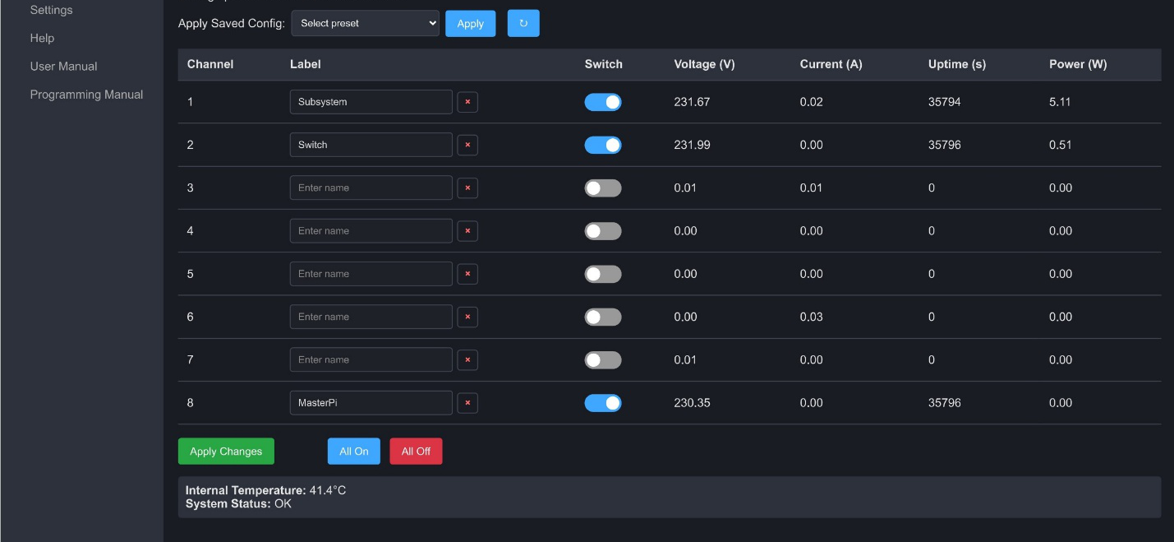
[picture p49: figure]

The control page is the main view for daily operation. It shows the state of all outlets and the basic measurements per channel.

Typical elements of the page include:

- Apply saved config
  - Allows the user to select any of the 5 user-configurable presets and apply them to the output
- Per-channel controls
  - One row per outlet (CH1-CH8).
  - A clear indicator showing whether the outlet is currently ON or OFF.
  - A control element (toggle switch or button) to change the state of the outlet.
  - Label field for individual channel name
  - The outlet state on the page follows the actual relay state in the device.
- Live measurements
  - For each channel, the page displays:
    - Voltage [V]
    - Current [A]
    - Power [W]
    - Uptime or run-time indication for the channel
  - Values update periodically so that the user can confirm that connected equipment is powered and drawing current as expected.
- Overall status / header area
  - Device name and basic system information (for example firmware version).
  - A summary indication if all outlets are off or if one or more errors are present.

The control page is intended for routine tasks such as turning outlets on and off, verifying loads and checking that equipment is running without having to access the front panel.

## 6.3 Settings page (/settings.html)

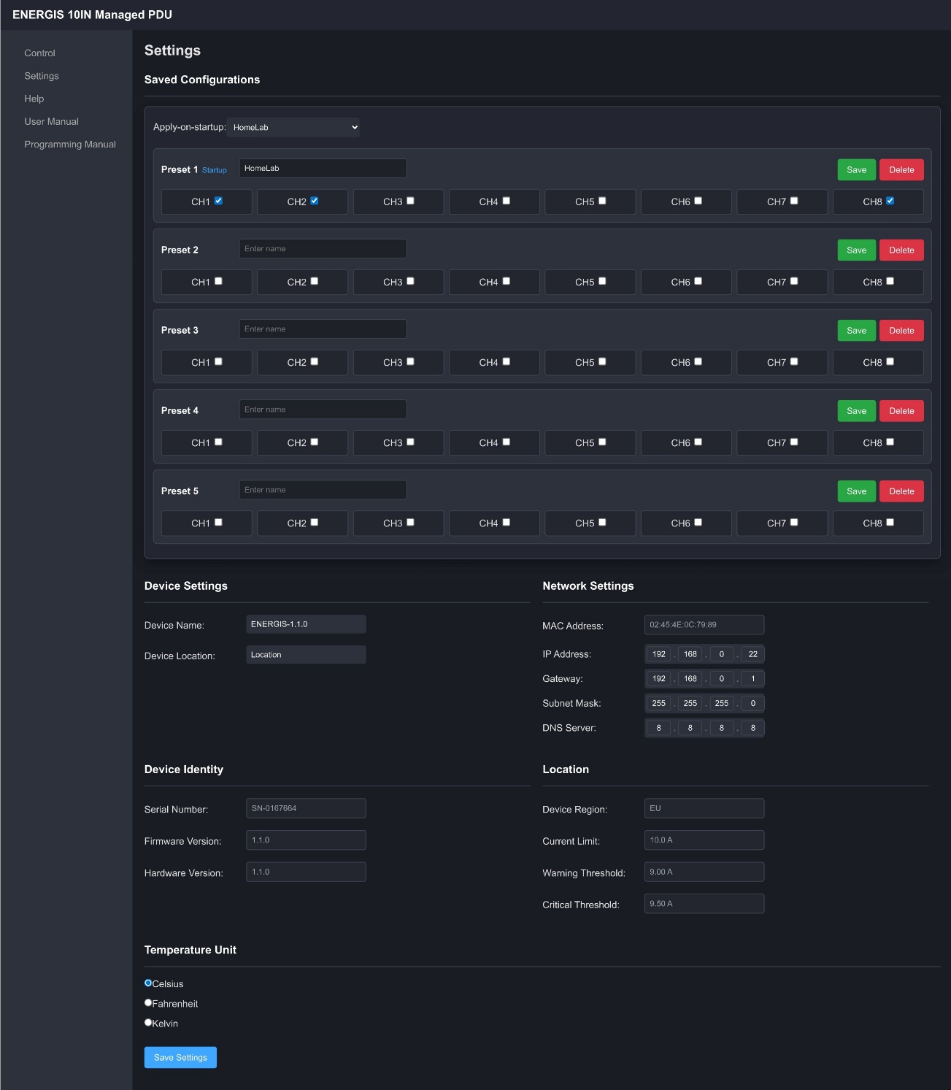
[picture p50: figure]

The settings page is used to change basic device properties and network configuration. It is intended for initial setup and occasional adjustments rather than frequent use.

On this page you can typically adjust:

- Presets and apply-on-startup
  - Apply-on-Startup allows you to select one preset to auto-apply during system start.
  - 5 user-configurable presets, with individual names let you save often used configurations. These presets can be applied on the control screen or can be set to be auto applied during startup.
- Device information
  - Device name: label used in the web interface and, depending on configuration, in monitoring systems.
  - Location: free-text field to identify where the unit is installed (rack, room or site).
  - Temperature unit: selection between Celsius, Kelvin and Fahrenheit.
- Network settings
  - IP address
  - Subnet mask
  - Default gateway
  - DNS server

These values define how ENERGIS appears on the network and how it communicates with other systems.

After making changes:

- Submit the form using the button provided on the page.
- The device stores the new settings and, if network parameters were changed, performs a reboot for them to take effect.

CAUTION - Changing the IP address, subnet mask or gateway can make the device temporarily unreachable if the new settings are incorrect or outside the current subnet. Always record the new values before applying them and plan access to the new address after the reboot.

## 6.4 Help and documentation pages

In addition to the control and settings views, the web interface provides simple documentation entry points.

- Quick help (/help.html)
  - A small page served directly from the device.
  - Summarizes front panel behavior, basic network checks, and common issues.
  - Does not require internet access and is intended for on-site troubleshooting.
- Manual links (/user_manual.html, /programming_manual.html)
  - Small pages that link to the User Manual and Automation Manual PDFs hosted online.
  - When the device has access to the internet and the browser can reach the hosting site, selecting these links opens the full documentation.

The help page provides a minimal reference when the network is local-only or offline, while the manual links offer direct access to the complete documentation set when external connectivity is available.

## 6.5 Advanced monitoring and integration

The web interface intentionally presents a simplified view of the device: it focuses on per-channel switching, basic measurements and essential settings. Internal telemetry and configuration are richer than what is shown on these pages.

For environments that require detailed monitoring, trending and integration with existing management systems, ENERGIS also provides:

- An SNMPv1 interface for polling outlet states, power and energy telemetry and selected system parameters.
- An OpenMetrics-compatible /metrics endpoint suitable for scraping by Prometheus and similar monitoring tools.

Both interfaces expose more metrics and control points than the basic web pages and are intended for use by automation and monitoring software rather than by end users. Their structure, available fields and configuration examples are described in detail in the ENERGIS Automation Manual (https://dvidmakesthings.github.io/HW_10-In-Rack_PDU/Manuals/ENERGIS_AutomationManual_rev_1.0.0.pdf).

# 7. Basic Troubleshooting

This section covers common issues that can be diagnosed and resolved on site without specialized tools. It focuses on visible indicators and simple checks. No protocol knowledge is required.

## 7.1 Cannot reach the web interface

Symptoms: entering http://<device-ip>/ in the browser does not load the control page.

1. Check device status
  - Verify that the PWR LED on the front panel is lit.
  - Verify that the LAN LED is lit or blinking, indicating that an Ethernet link is present.
2. Check cabling and network
  - Confirm that the Ethernet cable is firmly plugged into both the ENERGIS front-panel RJ-45 port and the switch or router.
  - Check that the switch port is enabled and not administratively shut down.
  - Ensure that the PC and ENERGIS are connected to the same IP subnet or that routing is configured appropriately.
3. Verify basic connectivity
  - From a PC in the same network segment, open a command prompt and send a ping to the device IP address.
  - If ping fails, re-check IP configuration and cable connections.
4. Clear error and restart if necessary
  - If the ERR LED is lit, press and hold the Set button on the front panel for about one second to clear the error.
  - If communication is still not possible, disconnect the mains supply, wait a few seconds, and reconnect it to perform a clean restart.

If the problem persists after these checks, refer to the Automation Manual or contact support with details of the LED states and network configuration.

## 7.2 Outlets do not switch

Symptoms: pressing Set on the front panel or toggling an outlet in the web interface does not change the outlet state; the green channel LED does not update as expected.

1. Check error status
  - Look at the ERR LED. If it is lit, clear the error with a long press of the Set button on the front panel.
  - After clearing, try switching the outlet again.
2. Check total load and supply
  - Confirm that the total load connected to the unit does not exceed the 10A EU, 15A US/CA inlet rating.
  - Verify that the upstream circuit breaker or fuse has not tripped and that the mains supply is present.
3. Check outlet assignment
  - Confirm that you are operating the correct channel (front-panel channel number and wiring on the rear panel match your documentation).

If the outlets still do not respond, disconnect the mains supply and connected loads and have the installation inspected by qualified personnel.

## 7.3 Measurements show zero

Symptoms: the web interface or other monitoring shows voltage, current or power as zero for a channel that is expected to be active.

1. Check outlet state and load
  - Verify that the green LED for the channel is on, indicating that the outlet is switched on.
  - Confirm that a load is actually connected to the corresponding rear-panel C13 outlet.
2. Allow time for measurement update
  - After switching a channel on, allow a few seconds for the internal power meter to update. Measurements are not instantaneous.
3. Check for very light loads
  - Very small loads may be below the minimum current threshold and can appear close to zero in the measurements.

If a channel continues to report zero values while driving a known load, note the channel number and conditions and refer to the Automation Manual or support for further diagnosis.

## 7.4 Forgotten or unknown IP address

Symptoms: the device is powered, the LAN LED is on, but the current IP address is not known.

1. Check the product label
  - The factory-default IP address and network settings are printed on the label on the underside of the unit.
  - If your installation uses the defaults, or has been reset to defaults, the device should respond on this address.
2. Check installation documentation
  - The installer or system administrator may have recorded the configured IP address and name in project documentation or in the network inventory.
3. Restore network settings (if permitted)
  - If the device has been configured with unknown settings and cannot be reached, network parameters can be restored to their factory defaults via the service console using the factory reset procedure.
  - This operation resets network configuration and user preferences to their original values but does not change the firmware.
  - For the exact reset sequence and precautions, refer to the Automation Manual or contact support.

CAUTION - A factory reset clears custom network settings. After the reset, the device will use the default IP configuration printed on the label, and any integrations that rely on the previous address must be updated.

# 8. Overcurrent Protection

The ENERGIS PDU is protected against overload by an automatic overcurrent protection system. This system continuously monitors the total current drawn by all connected outputs together and prevents unsafe operation:

- Prevents the PDU from operating above its rated current
- Automatically turns off loads if a dangerous overload occurs
- Blocks turning channels ON until the overload is resolved
- Allows channels to be turned OFF at all times for safety

This protection works automatically and does not require user interaction under normal operation.

## 8.1 Maximum Current Limits

The maximum allowed current depends on the product version:

- EU version: 10 A maximum total current
- US version: 15 A maximum total current

All protection actions are based on this total current limit.

## 8.2 The protection workflow

As the total current increases, the system reacts in stages:

- Approaching the limit: When the total current gets close to the maximum, the device records a warning. Operation continues normally.
- Overcurrent detected: If the total current becomes dangerously high, the device:
  - Automatically turns OFF the most recently switched-on channel
  - Blocks turning ON any channels
  - Records the event for diagnostics
- Recovery: When the total current drops to a clearly safe level, normal operation is restored automatically.

## 8.3 Channel Behavior During Overload

The last channel that was turned ON is switched OFF first. This helps disconnect the load that most likely caused the overload.

If the device cannot determine which channel caused the overload, all channels are turned OFF as a safety measure.

Turning channels **OFF is always allowed, even during an overload condition.

## 8.4 Manual Reset

If required, the overcurrent lockout can be cleared manually using the control interface or console. This should only be done after reducing the connected load, otherwise the protection may trigger again.

### Important Notes

- The protection monitors total current, not individual channels.
- Short, harmless current spikes are ignored.
- The system uses automatic recovery to avoid repeated on/off cycling.
- Overcurrent events are logged and can be reviewed for troubleshooting.

This protection system ensures safe and reliable operation of the ENERGIS PDU, even in the event of accidental overload.

# 9. Firmware Updates

Firmware updates may introduce new features, performance improvements or fixes. This section outlines the standard update method for ENERGIS using the RP2040 USB mass-storage bootloader. If your installation is managed by an integrator or IT department, follow their procedures. If in doubt, do not perform updates yourself.

## 9.1 General notes

- Only install firmware images obtained from the official project repository or your system supplier.
- Do not interrupt power or disconnect the USB cable during the update process.
- An incorrect or interrupted update may render the device temporarily unusable until it is recovered.

## 9.2 Update procedure (UF2 via USB)

1. Obtain the firmware file
  - Download the appropriate .uf2 firmware file for your hardware revision from the official source specified by the maintainer.
2. Prepare the connection
  - Connect the ENERGIS USB-C port to a computer using a suitable USB cable.
  - If the device is already powered from the mains, you may leave the AC connection in place during the update.
3. Enter bootloader mode
  - Put the device into USB mass-storage boot by sending the command “BOOTSEL” via serial terminal
  - When successful, the computer will detect a new removable drive representing the device bootloader.
4. Copy the firmware
  - Drag and drop the .uf2 file onto the newly appeared drive.
  - Wait until the file copy has completed. The drive will disconnect automatically when the update is finished.
  - After the update, ENERGIS restarts into the new firmware.
5. Verification
  - Verify that the PWR LED is on and that the device responds as expected (front panel and web interface).
  - Sending the command “SYSINFO” via Serial terminal will display general system information. Look for the section:

=== Device Firmware Info ===

[ECHO] Device Serial: SN-xxxxxxx

[ECHO] Firmware Ver: x.x.x

  - The firmware version shall match with the displayed version

CAUTION - Do not remove power or the USB cable while the .uf2 file is being copied. Interrupting the update process may corrupt the firmware image and require a recovery procedure.

CAUTION - If an update fails or the device does not restart correctly, disconnect power, wait a few seconds and reconnect it. If the issue persists, repeat the update procedure or contact support with the firmware version and a description of the behavior.

# 10. Technical Data (Summary)

This section summarizes the main electrical, environmental and mechanical characteristics of ENERGIS, together with its external interfaces. For definitive values and tolerances, refer to the product label and mechanical drawing for the specific hardware revision.

## 10.1 Electrical characteristics

Parameter | Value / Range | Note
Input voltage | 85-305 VAC | See rating label for permissible tolerance
Input frequency | 50 / 60 Hz | Mains supply
Maximum input current | - 10A EU - 15A US/CA | Do not exceed 10A EU, 15A US/CA at the inlet!
Number of outlets | 8 × IEC C13 | Rear panel, channels CH1–CH8
Maximum outlet current | - 10A EU per outlet - 15A US/CA per outlet | Do not exceed 10A EU, 15A US/CA total (all outlets combined) at the outlet
Internal overcurrent limit | Fuse: - T10A 250VAC (EU) - T15A 250VAC (US/CA) | Upstream protection must be sized appropriately
Internal power consumption | 3.6W (230V 16mA) | PDU electronics only, no load
Protective earth | Mandatory | Via AC inlet; must be connected

The values above define the permissible operating envelope for the unit when used as specified in this manual.

## 10.2 Environmental conditions

Parameter | Value / Range | Note
Operating temperature | 0 °C to 50 °C | Derate load at higher ambient temperatures
Storage temperature | –20 °C to 60 °C | Device not energized
Relative humidity | 20 % to 80 % RH | Non-condensing
Installation location | Indoor, dry | No direct exposure to moisture or dust

Operation outside these ranges may affect accuracy, lifetime or safety and is not recommended.

## 10.3 Mechanical data

Parameter | Value / Description | Note
Form factor | 10-inch rack unit | Front mounting ears integrated
Height | 1U, 44.4mm | See mechanical drawing
Width | 10-inch standard - Bracket-bracket: - 246mm - Enclosure body: - 215mm | See mechanical drawing
Depth | 175.6mm | Measured from front panel to rear. See mechanical drawing
Approximate weight | [to be specified] | Without packaging
Enclosure material | Aluminum 5052

For exact dimensions and mounting hole positions, refer to the mechanical drawing provided with the hardware files.

## 10.4 Interfaces

Interface | Type / Standard | Description
Mains inlet | IEC appliance inlet | AC input, 85-305 VAC, up to 10A EU, 15A US/CA
Load outlets | 8 × IEC C13 | Switched outlets, channels CH1–CH8
Ethernet | RJ-45, 10/100 Mbit/s | Network access for web UI and automation services
USB | USB-C, USB device (CDC) | Serial console for configuration and diagnostics
Internal power meter | HLW8032 (per channel) | Internal metering only, not directly accessible

The internal metering interface is used exclusively by the firmware and has no user-accessible connector.

## 10.5 Regional Variants and Ratings

ENERGIS is supplied in two regional variants. The ratings printed on the ENERGIS rating label are authoritative. Electrical limits are also stated throughout this manual for clarity.

- EU variant: IEC (International Electrotechnical Commission) ENEC (European Norms Electrical Certification)
  - Maximum input current: 10 A
  - Maximum outlet current (per outlet): 10 A
  - Maximum total load (all outlets combined): 10 A
  - Internal overcurrent protection: T10A 250 VAC time-delay fuse
- US/Canada variant: UL (Underwriters Laboratories) CSA (Canadian Standards Association)
  - Maximum input current: 15 A
  - Maximum outlet current (per outlet): 15 A
  - Maximum total load (all outlets combined): 15 A
  - Internal overcurrent protection: T15A 250 VAC time-delay fuse

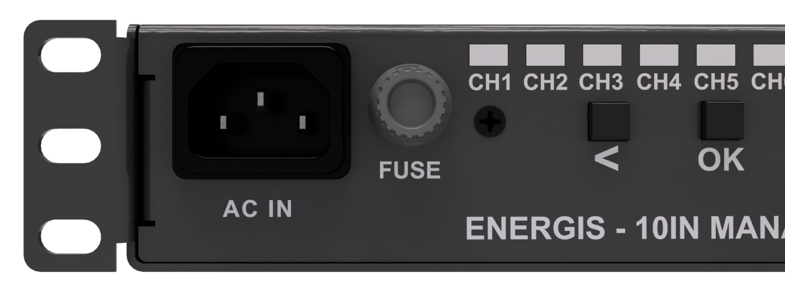
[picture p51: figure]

Fuse location:

# 11. Support and Warranty

## 11.1 Firmware, documentation and issue tracking

Firmware, schematics, mechanical files and the latest versions of the manuals are maintained in the project’s public repository. Users are encouraged to consult the repository for release notes, known issues and updates.

- Project repository: https://github.com/DvidMakesThings/HW_10-In-Rack_PDU
- Online manuals and additional documentation:
  - User manual (this document): https://dvidmakesthings.github.io/HW_10-In-Rack_PDU/Manuals/User_Manual.pdf
  - Automation manual: https://dvidmakesthings.github.io/HW_10-In-Rack_PDU/Manuals/AUTOMATION_MANUAL.pdf

Bug reports and feature requests can be submitted via the issue tracker in the repository. When reporting a problem, include the firmware version, a description of the setup and any relevant log or console output.

## 11.2 Warranty and limitations

The ENERGIS hardware and firmware are provided as part of an open design. Warranty terms, if any, depend on how the unit was obtained (self-built from sources, supplied as a kit, or delivered as an assembled device by a third party). Refer to the terms supplied by your vendor or integrator.

When ENERGIS is supplied as a fully assembled device by the designer, each unit is functionally tested before shipment to verify that it operates correctly at the time of delivery. This ensures that the device leaves production in a working state, but it does not replace any incoming inspection, burn-in or acceptance tests required by the end user.

In general:

- The manufacturer or designer cannot be held liable for damage resulting from incorrect installation, operation outside the specified ratings, unauthorized modifications, or use in applications for which the device was not intended (including but not limited to safety critical, medical or life support systems).
- It is the responsibility of the installer and operator to ensure that the device is used in accordance with local regulations and the guidance given in this manual.
- Any opening of the enclosure, bypassing of safety features or modification of the internal wiring is strictly at the user’s own risk and falls outside any warranty or support obligation.

For assembled devices, a tamper evident security seal is applied to the enclosure. This seal is intended to show whether the device has been opened or mechanically altered after shipment. If the seal is broken, removed or damaged, it is taken as evidence that the unit has been opened or modified and any warranty or goodwill support related to manufacturing defects may be refused.

If the device is part of a larger system, any additional warranties, certifications or compliance requirements are the responsibility of the system integrator.

TTTECH - Internal

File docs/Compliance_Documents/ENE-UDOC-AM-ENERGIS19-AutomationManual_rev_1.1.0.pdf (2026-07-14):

# Automation Manual

# ENERGIS

# 19IN Managed PDU

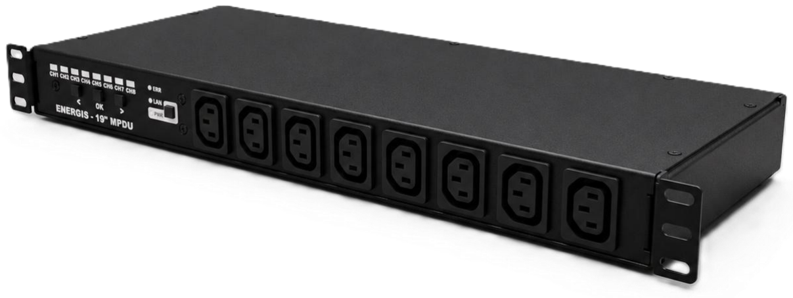
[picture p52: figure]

Revision: 1.1.0

Revision History
A revision is a new edition of the document and affects all sections of this document.
Version | Date | Responsible | Modification
1.0.0 | 12.12.2025 | David Sipos | Initial creation of the document
1.1.0 | 13.01.2026 | David Sipos | Added Software version 1.1.0 changes

## Content

# 1. Overview

The ENERGIS managed PDU is a rack‑mount power distribution unit that allows you to switch eight AC outlets individually and monitor voltage, current, power and uptime for each channel. The unit is built around a RP2040 microcontroller running FreeRTOS and communicates over Ethernet and serial. All relays are electromechanical and each channel is designed to handle 16A. HLW8032 power‑metering chips measure the AC lines, individually per channel.

The PDU can be controlled locally via the front panel, remotely via a built‑in HTTP server and SNMP agent, or through a USB serial console. This manual explains how to connect the unit, configure it and use these interfaces to integrate the PDU into any automation system.

## 1.1 Installation and Setup

### 1.1.1 Electrical and Network Connections

1. Mounting and power – Install the PDU into a 19‑inch equipment rack. Connect the supplied AC power cord to the mains and attach your load devices to the eight IEC outlets. Each relay is rated 16A. The PDU inlet is 16A max, so the sum of all channels must not exceed 16A
2. Networking – Plug an Ethernet cable into the RJ‑45 jack. By default, the PDU is programmed to use static IP Address, which can be found on the bottom of the device. The network settings can be read and changed via the web interface or the serial console (see below).
3. USB/serial – The PDU exposes its console over USB‑CDC on the USB‑C port. The serial interface operates at 115 200 baud, 8‑N‑1. Connect the USB‑C port to a host computer and open a terminal program (PuTTY, screen, minicom, etc.); the PDU enumerates as a CDC device without drivers. Note: The internal HLW8032 power meter uses UART0 at 4 800 baud and it is NOT exposed externally.

### 1.1.2 First Boot

On first boot the PDU performs a self‑test, initializes the display and relays and loads configuration from its internal EEPROM. The internal power monitor performs a self-check; this makes the Power LED turns on. The eight outlet LEDs will play a pattern and the network LED will come on once a link is detected.

# 2. Local Operation

## 2.1 Front Panel Buttons and LEDs

When the device is powered, any interaction with any buttons (Left, Set, Right) will start a 10s selection window, in which the currently selected channel is shown by a blinking orange light. After 10 seconds of inactivity the selection times out and no channel is highlighted.

Each channel has two indicators: a green LED showing whether the channel is on or off. An orange LED showing which channel is currently selected. Within the selection window, the user is able to turn on and off any channel.

Status LEDs:

- PWR LED indicates that the PDU is energized, and the internal power is within the expected range.
- ETH LED lights when a link is established on the Ethernet port.
- ERR LED lights if an internal error is detected; clear it with a long press of the Set button.

## 2.2 Button functions:

- Left / Right: Within the selection window, use these buttons to move the selection highlight across the eight channel status LEDs. The highlight wraps around after channel 8.
- Set:
- Outside the selection window, a short press on any button only opens the 10 s window (no step, no toggle).
- Inside the selection window, a short‑press toggles the currently selected channel on/off.
- Anytime, a long press (>1 s) clears the fault LED.
- PWR:
- Long press (>2s) when the device is powered initiates the low power sleep mode. The PWR LED blinks every second. Short press in active mode has no effect.
- Short press, when the device is in sleep mode wakes up the device and puts it back in active mode. Long press in sleep mode has no effect.

# 3. Command‑Line Interface - Serial

A comprehensive serial console is available over the USB‑C port (USB‑CDC). After connecting with a terminal program at 115200 baud basic system health information can be seen, emitted every 60 seconds. Type help to list commands.

## 3.1 Command list

Command | Description | Example
GENERAL COMMANDS
HELP | Show available commands and syntax
SYSINFO | Show system information
GET_TEMP | Show MCU temperature
REBOOT | Reboot the PDU. Changes to network settings take effect after reboot.
BOOTSEL | Put the MCU into boot mode
CLR_ERR | Clears all errors
RFS | Restore Factory Settings
OUTPUT CONTROL AND MEASUREMENT
SET_CH <ch> <STATE> | Set channel (1–8) to (0|1|ON| OFF|ALL) | SET_CH 1 1
GET_CH <ch> | Read current state of channel <ch> (1-8|ALL) | GET_CH 3
OC_STATUS | Show overcurrent protection status
OC_RESET | Manually clear overcurrent lockout
READ_HLW8032 | Read power data for all channels
READ_HLW8032 <ch> | Read power data for (1-8) | READ_HLW8032 2
CALIBRATE <ch> <V> <I> | Start single (1-8) calibration on given voltage and current | CALIBRATE 2 0 0
AUTO_CAL_ZERO | Zero-calibrate all channels.
AUTO_CAL_V <voltage> | Voltage-calibrate all channels. | AUTO_CAL_V 230
AUTO_CAL_I <current> <ch> | C u r r e n t - c a l i b r a t e s i n g l e channel (1–8). Requires known load | AUTO_CAL_I 0.5 2
SHOW_CALIB <ch> | Show calibration data (1-8|ALL) | SHOW_CALIB 5

NETWORK SETTINGS
NETINFO | Display the current IP, subnet m a s k , g a t e w a y a n d D N S addresses.
SET_IP <ip> | S e t a s t a t i c I P a d d r e s s . Requires reboot. | SET_IP 10.10.0.67
SET_SN <mask> | Set the subnet mask. | SET_SN 255.255.255.0
SET_GW <gw> | Set the default gateway. | SET_GW 192.168.1.1
SET_DNS <dns> | Set the DNS server. | SET_DNS 8.8.8.8
CONFIG_NETWORK <ip$sn$gw$dns> | Configure all network settings. | CONFIG_NETWORK 254.176.0.2 $255.255.255.0$254.176.0.1 $1.1.1.1

# 4. HTTP API

The embedded HTTP/1.1 server listens on port 80 and serves both JSON endpoints under /api/... and a few HTML pages for browsers. All responses include:

- Connection: close
- Cache-Control: no-cache
- Access-Control-Allow-Origin: * (CORS enabled for any origin)

Status codes (summary)
- GET /api/status → 200 OK (JSON)
- GET /api/settings → 200 OK (JSON)
- POST /api/control → 200 OK with text body OK\n; 400 Bad Request if body missing; 503 Service Unavailable when overcurrent lockout blocks switching
- POST /api/settings → 204 No Content (changes are applied immediately; see notes)
- Preset & automation endpoints:
- GET /api/config-presets → 200 OK (JSON; may include Retry-After: 1 while presets initialize)
- POST /api/config-presets → 200 OK on success; 400 on malformed/missing fields; 500 on save error
- POST /api/apply-config → 200 OK on success; 400 invalid/missing id; 503 overcurrent lockout; 500 apply failure
- POST /api/startup-config → 200 OK on success; 400 invalid/missing parameters; 500 failure

Notes
- JSON responses use Content-Type: application/json. The success body for POST /api/control is text/plain (OK\n).
- Static HTML pages may be served gzipped with Content-Encoding: gzip

## 4.1 GET /api/status

Returns live telemetry and system state.

Response JSON shape:
- channels: array (8) of per-channel objects: {
"voltage": float,
"current": float,
"uptime": uint,
"power": float,
"state": bool,
"label": string
}
- internalTemperature: float - device die temperature converted to the user’s unit
- temperatureUnit: "°C" | "°F" | "K"
- systemStatus: "OK" | "WARNING" | "LOCKOUT" (derived from overcurrent sta
te)
- overcurrent: object:
{
"state": "NORMAL"|"WARNING"|"CRITICAL"|"LOCKOUT"|"UNKNOWN", "total_current_a": float,
"limit_a": float,
"warning_threshold_a": float,
"critical_threshold_a": float, "recovery_threshold_a": float, "switching_allowed": true|false, "trip_count": integer,
"region": "EU"|"US"
}

Example:

curl.exe -s http://<pdu-ip>/api/status

Response:

{
"channels": [
{ "voltage": 229.987, "current": 0.120, "uptime": 12, "power": 27.598, "state": true, "label": "CH1" },
{ "voltage": 229.954, "current": 0.000, "uptime": 0, "power": 0.000, "state": false, "label": "" }
/* ... 6 more ... */
],
"internalTemperature": 26.970, "temperatureUnit": "°C",
"systemStatus": "OK",
"overcurrent": {
"state":"NORMAL",
"total_current_a":0.12,
"limit_a":10.0,
"warning_threshold_a":9.00, "critical_threshold_a":9.50, "recovery_threshold_a":8.50, "switching_allowed":true,
"trip_count":0,
"region":"EU"
}
}

## 4.2 POST /api/control

Controls relay states and channel labels via form-urlencoded data.

Form fields

- channelN (N = 1..8):
- "on" → turn channel ON
- anything else or omitted → OFF
(Omitting a channel means it is forced OFF.)
- labelN (N = 1..8): optional; set channel label (max 25 chars); empty value clears it.

Overcurrent guard

If any channel would transition from OFF→ON while overcurrent lockout is active, the request is rejected with 503 Service Unavailable and a JSON error body.

Examples

Turn channels 1 and 3 ON (others forced OFF)

curl.exe -s -o $null -w "%{http_code}`n" -X POST "http://<pdu-ip>/api/control" --data "channel1=on&channel3=on"

Turn channel 3 OFF (others remain OFF by omission):

curl.exe -s -o /dev/null -w "%{http_code}\n" -X POST "http://<pdu-ip>/api/control” --data "channel3="

Set label for channel 1 and turn it ON:

curl.exe -s -o /dev/null -w "%{http_code}\n" -X POST "http://<pdu-ip>/api/control" --data "channel1=on&label1=Router PSU"

Responses

- Success: 200 OK with body OK\n (text/plain)
- Missing body: 400 Bad Request with JSON error
- Overcurrent lockout: 503 Service Unavailable with JSON error

## 4.3 GET /api/settings

Returns the stored network configuration and user preferences plus device identity and limits).

Response JSON fields

{
"ip": "a.b.c.d",
"gateway": "a.b.c.d",
"subnet": "a.b.c.d",
"dns": "a.b.c.d",
"mac": "AA:BB:CC:DD:EE:FF",
"device_name": "ENERGIS-<ver>",
"location": "Location",
"temp_unit": "celsius" | "fahrenheit" | "kelvin",
"temperature": <number in selected unit>, "serial_number": "<string>", "firmware_version": "<string>", "hardware_version": "<string>",
"device_region": "EU" | "US" | "UNKNOWN",
"current_limit": "<n.n A>", "warning_limit": "<n.nn A>", "critical_limit": "<n.nn A>"
}

curl.exe -s "http://<pdu-ip>/api/settings"

Example response:

{
"ip":"192.168.0.12",
"gateway":"192.168.0.1",
"subnet":"255.255.255.0",
"dns":"8.8.8.8",
"mac":"AA:BB:CC:DD:EE:FF", "device_name":"ENERGIS-1.1.0", "location":"Location",
"temp_unit":"celsius",
"temperature":33.35,
"serial_number":"<serial>", "firmware_version":"<fw>", "hardware_version":"<hw>", "device_region":"EU",
"current_limit":"10.0 A",
"warning_limit":"9.00 A",
"critical_limit":"9.50 A"
}

## 4.4 POST /api/settings

Updates network parameters and user preferences. Fields include:

- ip, subnet, gateway, dns
- device_name, location
- temp_unit (celsius, fahrenheit, or kelvin)

Changes are saved to EEPROM; the device responds 204 No Content and then reboots.

curl.exe -s -o $null -w "%{http_code}`n" -X POST "http://<pdu-ip>/api/settings" ^ --data "ip=192.168.0.12&gateway=192.168.0.1&subnet=255.255.255.0&dns=8.8.8.8&device_name =ENERGIS&location=Rack1&temp_unit=celsius"

## 4.5 Preset Management

The firmware supports saving, loading, and managing up to 5 relay configuration presets. These presets allow you to quickly recall and apply specific ON/OFF states to all 8 channels and optionally set one preset to be automatically applied at startup.

### 4.5.1 GET /api/config-presets

Purpose:
Retrieve the list of all saved relay presets and the currently selected startup preset (if any).

Response JSON:

{
"presets": [
{ "id": 0, "name": "All Off", "mask": 0 }, { "id": 1, "name": "Servers On", "mask": 3 }
// ... up to 5 total
],
"startup": null // or 0..4 if a startup preset is set }

Each preset object contains:

- id: Preset slot number (0–4)
- name: User-defined name (max 25 characters)
- mask: 8-bit value, each bit representing ON/OFF for channels 1–8 (bit 0 = channel 1, bit 7 = channel 8)

During initial boot or if presets are not yet loaded, the response ma be:

{
"presets": [],
"startup": null,
"pending": true
}

In this case, the HTTP response may also include a Retry-After: 1 header, indicating the client should retry after 1 second.

### 4.5.2 POST /api/config-presets

Purpose:
Create (save) a new preset or delete an existing one.

To save a preset:

- Send a form-encoded POST body with:
- action=save
- id=N (0–4)
- name=<your name> (max 25 chars)
- mask=<0..255> (bitmask for ON/OFF states)
- The field relay_mask is also accepted as an alias for mask.

Example (save a preset):

To delete a preset:

- Send:
- action=delete
- id=N (0–4)

Example (delete a preset):

curl.exe -s -X POST "http://<pdu-ip>/api/config-presets" --data "action= save&id=2&name=Night Mode&mask=1"

curl.exe -s -X POST "http://<pdu-ip>/api/config-presets" --data "action= delete&id=2"

Notes:
- If the name is longer than 25 characters, the request is rejected.
- If required fields are missing or invalid, the server returns 400 Bad Request.
- On EEPROM write failure, the server returns 500 Internal Server Error.
- On success, the response is 200 OK with {"success":true}.

### 4.5.3 POST /api/apply-config

Purpose:
Immediately apply a saved preset to the relay outputs.

How to use:

- Send a form-encoded POST body with:
- id=N (0–4)

Example:

Behaviour:

- The relay states are set according to the preset’s mask.
- If overcurrent lockout is active, the request is rejected with 503 Service Unavailable and a JSON error.
- If the id is missing or invalid, the server returns 400 Bad Request.
- On success, the response is 200 OK with {"success":true}.

### 4.5.4 POST /api/startup-config

Purpose:
Set or clear which preset (if any) should be automatically applied at device startup.

To set a startup preset:

- Send:
- id=N (0–4)

Example:

To clear the startup preset:

- Send:
- action=clear

curl.exe -s -X POST "http://<pdu-ip>/api/apply-config" --data "id=1"

curl.exe -s -X POST "http://<pdu-ip>/api/startup-config" --data "id=1"

Example:

Behaviour:

- Only one startup preset can be set at a time.
- If the request is successful, the response is 200 OK with {"success":true}.
- If parameters are missing or invalid, the server returns 400 Bad Request.
- On EEPROM write failure, the server returns 500 Internal Server Error.

Summary Table

Endpoint | Purpose | Required Fields | Success Response | Error Codes
GET /api/config-presets | List all presets & startup | – | 200 OK (JSON) | –
POST /api/config-presets | Save or delete a preset | action, id, (name, mask) | 200 OK (JSON) | 400, 500
POST /api/apply-config | Apply a preset immediately | id | 200 OK (JSON) | 400, 503, 500
POST /api/startup-config | Set/clear startup preset | id or action=clear | 200 OK (JSON) | 400, 500

curl.exe -s -X POST "http://<pdu-ip>/api/startup-config" --data "action= clear"

# 5. HTML pages

## 5.1 GET /control.html

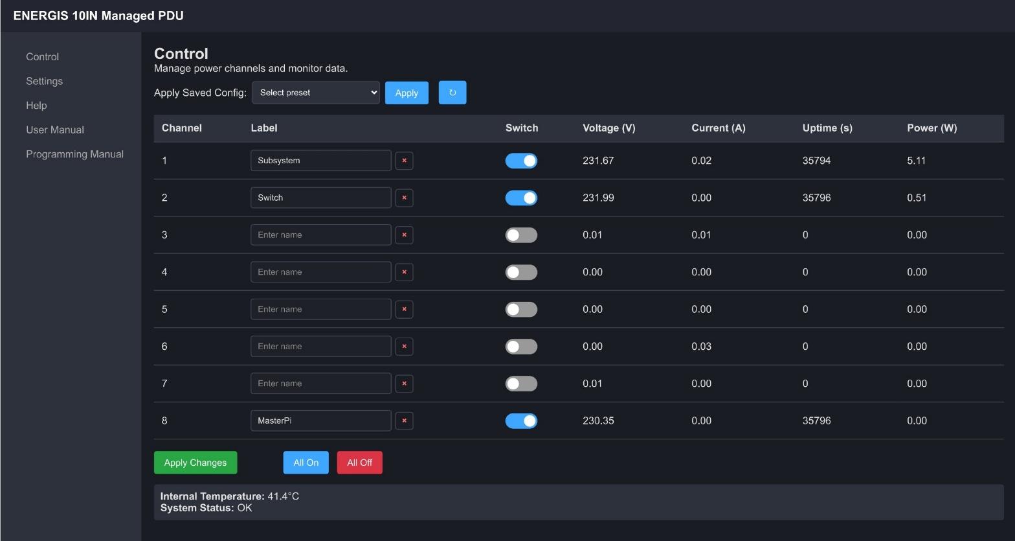
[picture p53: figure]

This is the main control UI.
- It loads in a browser,
- displays the 8 channels,
- and uses /api/status (for live data) and /api/control (for switching/ labels) in the background via JavaScript.

The page is served as HTML (gzipped), with Content-Type: text/html, Cache-Control: no-cache, and the connection is closed after the response.

## 5.2 GET /settings.html

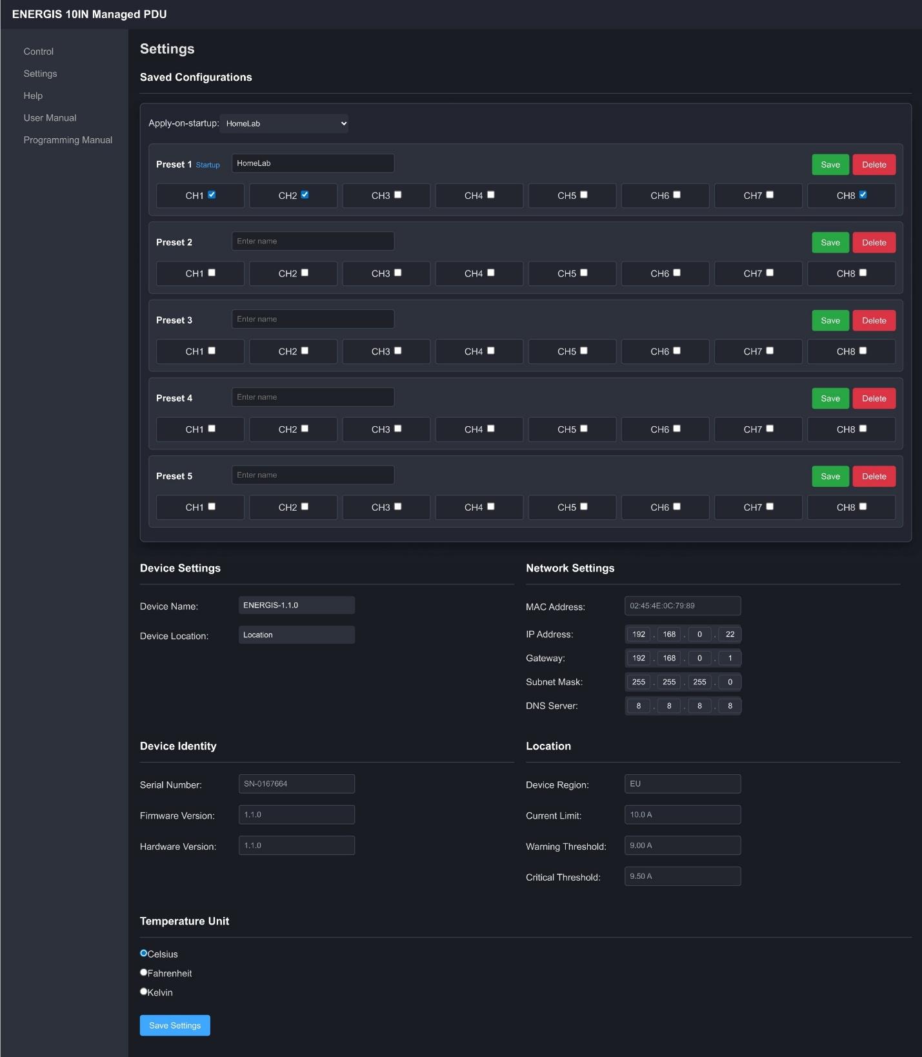
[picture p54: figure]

Serves an HTML settings page for use in a browser. It displays current network values and allows updating them via a form. Posts to /api/settings. Served as gzipped HTML.

5.3 GET /help.html, /user_manual.html,

## /automation_manual.html

These endpoints serve small HTML pages.

- /user_manual.html and /automation_manual.html: simple stubs that link to the PDFs hosted on GitHub Pages:
- User Manual
https://dvidmakesthings.github.io/HW_10-In-Rack_PDU/Manuals/User_Manual.pdf
- Programming & Interfacing Manual https://dvidmakesthings.github.io/HW_10-In-Rack_PDU/Manuals/Automation_Manual.pdf

Internet access is required to load those PDFs.
- /help.html: a fast help page that is served fully from the device. It does not depend on internet access and is meant for quick reference and basic troubleshooting when you’re offline.

HTTP behavior: All three return 200 OK, Content-Type: text/html, Cache-Control: no-cache, and the server closes the connection after sending the body.

What’s on /help.html? (fast help, offline-safe)

- Front panel cheatsheet
- Network quick checks
- Web API short guide
- SNMP sanity
- Offline troubleshooting

Why keep Help?

- It gives operators something usable when the site has no internet.
- It points to the full PDFs when WAN is available.
- It reduces support by solving the common “why doesn’t it switch / where’s my IP / why are values zero” cases directly on the box.

# 6. OpenMetrics / Prometheus endpoint

## 6.1 Overview

The ENERGIS PDU exposes a `/metrics` HTTP endpoint that provides runtime telemetry in OpenMetrics/Prometheus text format (version 0.0.4). This plugs directly into Prometheus, Grafana, and similar tools.

## 6.2 Configuration - Accessing the Endpoint

curl.exe http://<pdu-ip-address>/metrics

## Example response

# HELP energis_up 1 if the metrics handler is healthy.

# TYPE energis_up gauge energis_up 1

# HELP energis_build_info Build and device identifiers.

# TYPE energis_build_info gauge energis_build_info{version="1.1.0",se rial="SN-0167663"} 1

# HELP energis_uptime_seconds_total System uptime in seconds.

# TYPE energis_uptime_seconds_total counter energis_uptime_seconds_to tal 27 ...

# HELP energis_channel_state Relay state (1=ON, 0=OFF).

# TYPE energis_channel_state gauge energis_channel_state{ch="1"} 1

# HELP energis_channel_telemetry_valid 1 if cached telemetry for chan nel is fresh.

# TYPE energis_channel_telemetry_valid gauge energis_channel_telemetr y_valid{ch="1"} 1

# HELP energis_channel_voltage_volts Channel voltage.

# TYPE energis_channel_voltage_volts gauge energis_channel_voltage_vo lts{ch="1"} 0.000

# HELP energis_channel_current_amps Channel current.

# TYPE energis_channel_current_amps gauge energis_channel_current_amp s{ch="1"} 0.000

# HELP energis_channel_power_watts Active power per channel.

# TYPE energis_channel_power_watts gauge energis_channel_power_watts {ch="1"} 0.000

# HELP energis_channel_energy_watt_hours_total Accumulated energy per channel.

# TYPE energis_channel_energy_watt_hours_total counter energis_channe l_energy_watt_hours_total{ch="1"} 0.000

HTTP Response:
- 200 OK on success, with Content-Type: text/plain; version=0.0.4; charset=utf-8
- 503 Service Unavailable if the output would overflow the static buffer (encourages retry)
- 404 Not Found if the metrics feature is disabled at compile time

## 6.3 Available Metrics

### 6.3.1 System

energis_up

Health indicator (gauge; 1 if handler responds)

energis_build_info{version,serial}

Build and device info (gauge; always 1)

energis_uptime_seconds_total

Uptime since boot in seconds (counter)

energis_internal_temperature_celsius

Internal MCU temperature, calibrated (gauge)

energis_temp_calibrated

1 if temperature calibration is applied (gauge)

energis_temp_calibration_mode

Calibration mode (0=none, 1=1pt, 2=2pt) (gauge)

energis_vusb_volts

USB rail voltage (gauge)

energis_vsupply_volts

12 V rail voltage (gauge)

energis_http_requests_total

Total HTTP requests served (counter)

### 6.3.2 Per-Channel

energis_channel_state{ch}

Relay state: 1=ON, 0=OFF (gauge)

energis_channel_telemetry_valid{ch}

1 if cached telemetry for channel is fresh (gauge)

energis_channel_voltage_volts{ch}

Channel voltage [V] (gauge)

energis_channel_current_amps{ch}

Channel current [A] (gauge)

energis_channel_power_watts{ch}

Active power [W] (gauge)

energis_channel_energy_watt_hours_total{ch}

Accumulated energy in watt-hours (counter)

Values are served from cached snapshots owned by MeterTask. No direct sensor I/O in the handler. Temperature uses the active calibration. If no calibration is stored, defaults are used.

### 6.3.3 Overcurrent protection

energis_ocp_state {state}

Overcurrent protection state (0=NORMAL,1=WARNING,2=CRITICAL,3=LOCKOUT)

energis_ocp_switching_allowed {state}

Switching allowed (1=yes,0=no)

energis_ocp_total_current_amps {value}

Total measured current value in Amps (A)

energis_ocp_limit_amps {value}

Configured current limit

- EU Version (IEC/ENEC): 15.0A maximum
- US Version (UL/CSA): 20.0A maximum

energis_ocp_warning_threshold_amps {value}

Warning threshold, Limit - 1A

energis_ocp_critical_threshold_amps {value}

Critical threshold Limit - 0.5A

energis_ocp_recovery_threshold_amps {value}

Recovery threshold Limit – 1.5A

energis_ocp_trip_count_total {cnt}

Overcurrent trips since boot

energis_ocp_last_trip_ms {t}

Timestamp of last trip (ms since boot)

## 6.4 Prometheus Integration

Add to `prometheus.yml`:

scrape_configs:
- job_name: 'energis-pdu'
scrape_interval: 15s
scrape_timeout: 10s
metrics_path: /metrics
static_configs:
- targets: ['192.168.0.22:80'] labels:
location: 'rack-1'
device: 'pdu-main'

Example Alerts

groups:
- name: energis
rules:
- alert: EnergisHighTemp
expr: energis_internal_temperature_celsius > 70 for: 2m
labels: {severity: warning}
annotations:
summary: "ENERGIS MCU hot >70C"
- alert: EnergisVsupplyLow
expr: energis_vsupply_volts < 10.8 for: 1m
labels: {severity: critical} annotations:
summary: "ENERGIS 12V rail low"
- alert: EnergisNoTelemetry
expr: sum(energis_channel_telemetry_valid) < 8 for: 2m
labels: {severity: warning}
annotations:
summary: "ENERGIS channel telemetry not fully valid"

## 6.5 Performance

- Static buffer ~8 KB. No heap allocations.
- Non-blocking, minimal CPU load.
- Typical response time < 50 ms
- If the output would overflow the buffer, the handler returns **503** to encourage a retry instead of serving a partial payload.

## 6.6 Implementation Notes

- Reads from MeterTask_GetTelemetry() and MeterTask_GetSystemTelemetry()
- Uses atomic counters for request accounting.
- OpenMetrics text format compatible with Prometheus 0.0.4.

# 7. SNMP interface

This firmware exposes a compact SNMPv1 agent (community public). A static table binds each OID to a getter (and sometimes a setter). The table itself carries the SNMP type and the maximum response length; the getters in the submodules return the bytes to match that declaration. Identity (MIB-II system) lives alongside a private enterprise subtree at 1.3.6.1.4.1.19865 for

- outlets,
- power telemetry,
- rails/temperature, and
- a read-only mirror of network settings.

No request performs heavy work: outlet writes toggle state immediately; reads return cached or computed values with fixed, short encodings.

Two encoding patterns matter:

- Outlet states are INTEGER (4 bytes):
- GET returns a 32-bit 0 or 1,
- SET treats any non-zero as “on”.
Group controls are also typed as INTEGER.
- Measurements (power, rails, temperature, etc.) and network values are OCTET STRINGs containing ASCII like "230.12" or "192.168.0.50". Parse as text. Buffers are small (≤16 bytes).

## 7.1 Submodules

System & table layer
Owns the SNMP community (public), publishes the MIB-II system group (sysDescr, sysObjectID=enterprise 1.3.6.1.4.1.19865, sysUpTime, sysContact, sysSN, sysLocation, sysServices), and wires all private OIDs to domain getters/setters. It also defines an initial warmStart trap helper under the same enterprise. The table is “dumb”: it declares type/length and calls into the right function; logic lives in the domain modules.

Key OIDs (system):

- 1.3.6.1.2.1.1.1.0 sysDescr (string)
- 1.3.6.1.2.1.1.2.0 sysObjectID = 1.3.6.1.4.1.19865
- 1.3.6.1.2.1.1.3.0 sysUpTime (TimeTicks)
- 1.3.6.1.2.1.1.4.0 sysContact (string)
- 1.3.6.1.2.1.1.5.0 sysSN (string)
- 1.3.6.1.2.1.1.6.0 sysLocation (string)
- 1.3.6.1.2.1.1.7.0 sysServices (INTEGER)

## 7.2 Outlet control (read/write)

Eight independent channels and two group triggers. Per-channel GET returns a 4-byte INTEGER (0/1). Per-channel SET: 0 → off, any non-zero → on. Group triggers apply the action when you write any non-zero, and their GET encodes whether all channels currently match that state. Internally, OID channels are 1..8; drivers use 0..7.

### 7.2.1 Per-channel state (INTEGER):

- Format:

.1.3.6.1.4.1.19865.2.<ch>.0 where <ch>=1..8

GET: int32 0 or 1
SET: i 0 or i 1 (non-zero treated as 1) Example (CH3):

snmpget -v1 -c public -Oqv <pdu-ip> 1.3.6.1.4.1.19865.2.3.0

### 7.2.2 Group controls (INTEGER):

- All OFF (trigger):

.1.3.6.1.4.1.19865.2.9.0

GET: '1' only if every channel is off; SET: non-zero → force all off.

- All ON (trigger):

.1.3.6.1.4.1.19865.2.10.0

GET: '1' only if every channel is on;
SET: non-zero → force all on.

Implementation detail: per-channel GET always returns exactly 4 bytes to match the table’s INTEGER declaration. Group GET encodes '0'/'1' via a one-byte helper but the table still declares INTEGER. Managers will still treat these as INTEGER because the table declares INTEGER, the single-byte helper is an internal optimization.

## 7.3 Power and energy telemetry

Six metrics per channel, all as ASCII strings in OCTET STRINGs, pulled from the cached metering snapshot (no blocking I/O on the SNMP path). If the cache isn’t valid yet, you’ll see zeros by design.

### 7.3.1 Per-channel telemetry:

- Voltage [V]: .1.3.6.1.4.1.19865.5.<ch>.1.0 → "%.2f"
- Current [A]: .1.3.6.1.4.1.19865.5.<ch>.2.0 → "%.3f"
- | Power [W]: | .1.3.6.1.4.1.19865.5.<ch>.3.0 → "%.1f"
- Power factor: .1.3.6.1.4.1.19865.5.<ch>.4.0 → "%.3f"
- Energy [kWh]: .1.3.6.1.4.1.19865.5.<ch>.5.0 → "%.3f"
- | Uptime [s]: | .1.3.6.1.4.1.19865.5.<ch>.6.0 → "12345"
(decimal ASCII)

Quick sense of outputs for channel 1:

snmpget -v1 -c public -Oqv <pdu-ip> 1.3.6.1.4.1.19865.5.1.1.0 | # "230.12"
snmpget -v1 -c public -Oqv <pdu-ip> 1.3.6.1.4.1.19865.5.1.2.0 | # "0.534"
snmpget -v1 -c public -Oqv <pdu-ip> 1.3.6.1.4.1.19865.5.1.3.0 | # "85.3"

Formatting is centralized (ftoa, u32toa) and capped at 16 bytes per response. Precision is uniform across channels and metrics.

## 7.4 Rails and temperature

On-die temperature and board rails, formatted as short ASCII. The module samples Pico ADC for the die sensor (with a tiny low-pass/settle step) and uses HAL helpers for external rails. Everything fits in 16 bytes.

OIDs:

- Die sensor (voltage): .1.3.6.1.4.1.19865.3.1.0 → "%.5f"
- Die temperature [°C]: .1.3.6.1.4.1.19865.3.2.0 → "%.3f"
- | V_SUPPLY [V]: | .1.3.6.1.4.1.19865.3.3.0 → "%.3f"
- | V_USB [V]: | .1.3.6.1.4.1.19865.3.4.0 → "%.3f"
- V_SUPPLY divider tap: .1.3.6.1.4.1.19865.3.5.0
- | V_USB divider tap: | .1.3.6.1.4.1.19865.3.6.0
- | Core VREG [V]: | .1.3.6.1.4.1.19865.3.7.0 → "%.2f"
- | Core VREG status: | .1.3.6.1.4.1.19865.3.8.0 →
"OK" | "Overload" | "Hi-Z" | "Unknown"
- | Bandgap ref: | .1.3.6.1.4.1.19865.3.9.0
- | USB PHY rail: | .1.3.6.1.4.1.19865.3.10.0
- | IO rail: | .1.3.6.1.4.1.19865.3.11.0

## 7.5 Network configuration mirror

Reflects the persisted network config (EEPROM) as dotted-decimal strings. These are not writable via SNMP in this build.

OIDs:

- IP address: .1.3.6.1.4.1.19865.4.1.0 → "A.B.C.D"
- Subnet mask: .1.3.6.1.4.1.19865.4.2.0 → "A.B.C.D"
- | Gateway: | .1.3.6.1.4.1.19865.4.3.0 → "A.B.C.D"
- DNS server: .1.3.6.1.4.1.19865.4.4.0 → "A.B.C.D"

## 7.6 Overcurrent

Overcurrent | protection | status | is | exposed | under | the | enterprise
subtree .1.3.6.1.4.1.19865.6.*.0. It reports the live OCP status snapshot (no blocking I/O on the SNMP path). Integer values use SNMP INTEGER (4 bytes). Floating values are returned as ASCII strings in OCTET STRINGs (fits in 16 bytes). If OCP is not initialized yet, values fall back to safe defaults (typically zeros / NORMAL).

### 7.6.1 OCP status OIDs

- OCP state: .1.3.6.1.4.1.19865.6.1.0 → INTEGER Values:
- 0 = NORMAL
- 1 = WARNING
- 2 = CRITICAL
- 3 = LOCKOUT
- Total current [A]: .1.3.6.1.4.1.19865.6.2.0 → "%.3f" (ASCII)
- Current limit [A]: .1.3.6.1.4.1.19865.6.3.0 → "%.2f" (ASCII)
- Warning threshold [A]: .1.3.6.1.4.1.19865.6.4.0 → "%.2f" (ASCII)
- Critical threshold [A]: .1.3.6.1.4.1.19865.6.5.0 → "%.2f" (ASCII)
- Recovery threshold [A]: .1.3.6.1.4.1.19865.6.6.0 → "%.2f" (ASCII)
- Last tripped channel: .1.3.6.1.4.1.19865.6.7.0 → INTEGER Values:
- 1..8 = outlet index that was switched OFF by OCP
- 0 = not available / fallback action used
- Trip count: .1.3.6.1.4.1.19865.6.8.0 → INTEGER Monotonic counter since boot.
- Last trip time [ms since boot]: .1.3.6.1.4.1.19865.6.9.0 → INTEGER
- Switching allowed: .1.3.6.1.4.1.19865.6.10.0 → INTEGER
Values:
- 0 = switching ON blocked (lockout)
- 1 = switching allowed

### 7.6.2 Manual OCP reset (SNMP SET)

A write-only control is provided to clear OCP lockout:

- | Reset/clear | lockout: | .1.3.6.1.4.1.19865.6.11.0 | → | INTEGER | (SET)
Any non-zero value triggers a lockout clear. Use only after reducing load, otherwise the device may immediately trip again.

## 7.7 Failure modes and things worth knowing

- Type discipline: outlet nodes are 4-byte INTEGERs; telemetry and network are ASCII strings. If your NMS expects numbers everywhere, it will complain on the string nodes. Parse them.
- “All on/off” asymmetry: those two reports aggregate state and execute batch writes on any non-zero input; 0 is ignored. Verify final state with per-channel GETs if you need certainty.
- Small buffers, fixed precision: string responses are capped at 16 bytes, with formats like "%.2f", "%.3f". If you widen precision in firmware, update the table lengths or you’ll truncate.
- Cached telemetry: power data is a snapshot from the MeterTask cache. Immediately after enabling a channel, it may read "0.000" until the next update. This path never blocks waiting for the meter.
- Network fallback: if EEPROM is blank or inaccessible, the network mirror returns compiled defaults. If your reads show defaults, the storage flow didn’t load.
- Table is authoritative: per-channel outlet GET always returns exactly 4 bytes to match the table’s INTEGER definition, even if the internal code path could compute a one-byte value. Keep your client side tolerant.

## 7.8 Summary

One static table, four domains. Outlets are writable INTEGER scalars at .1.3.6.1.4.1.19865.2.<ch>.0, with two INTEGER triggers for “all off/on.”

Power | telemetry | is | six | ASCII | string | metrics | per | channel
at .1.3.6.1.4.1.19865.5.<ch>.<metric>.0, pulled from a non-blocking cache.

Rails/temperature live under .1.3.6.1.4.1.19865.3.*.0 as short strings.

Network | settings | are | read-only, | dotted-decimal | strings
under .1.3.6.1.4.1.19865.4.*.0, with EEPROM-to-default fallback.

Respect types and 16-byte limits, assume cached updates for measurements, and rely on per-channel reads to verify group actions.

# 8. Support

For firmware updates and source code, visit the project’s GitHub repository. For technical support or to report bugs, contact the maintainer listed in the SNMP sysContact field (dvidmakesthings@gmail.com).

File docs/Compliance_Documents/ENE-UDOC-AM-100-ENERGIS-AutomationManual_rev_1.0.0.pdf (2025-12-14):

# Automation Manual

# ENERGIS

# 10IN Managed PDU

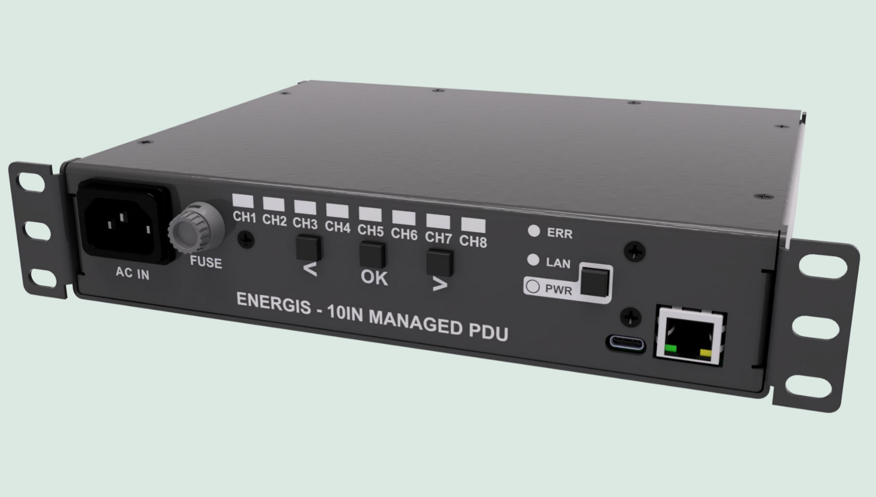
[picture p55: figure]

## Content

# 1. Overview

The ENERGIS managed PDU is a rack‑mount power distribution unit that allows you to switch eight AC outlets individually and monitor voltage, current, power and uptime for each channel. The unit is built around a RP2040 microcontroller running FreeRTOS and communicates over Ethernet and serial. All relays are electromechanical and each channel is designed to handle 16A. HLW8032 power‑metering chips measure the AC lines, individually per channel.

The PDU can be controlled locally via the front panel, remotely via a built‑in HTTP server and SNMP agent, or through a USB serial console. This manual explains how to connect the unit, configure it and use these interfaces to integrate the PDU into any automation system.

## 1.1 Installation and Setup

### 1.1.1 Electrical and Network Connections

1. Mounting and power – Install the PDU into a 10‑inch equipment rack. Connect the supplied AC power cord to the mains and attach your load devices to the eight IEC outlets. Each relay is rated 16A. The PDU inlet is 16A max, so the sum of all channels must not exceed 16A
2. Networking – Plug an Ethernet cable into the RJ‑45 jack. By default, the PDU is programmed to use static IP Address, which can be found on the bottom of the device. The network settings can be read and changed via the web interface or the serial console (see below).
3. USB/serial – The PDU exposes its console over USB‑CDC on the USB‑C port. The serial interface operates at 115 200 baud, 8‑N‑1. Connect the USB‑C port to a host computer and open a terminal program (PuTTY, screen, minicom, etc.); the PDU enumerates as a CDC device without drivers. Note: The internal HLW8032 power meter uses UART0 at 4 800 baud and it is NOT exposed externally.

### 1.1.2 First Boot

On first boot the PDU performs a self‑test, initializes the display and relays and loads configuration from its internal EEPROM. The internal power monitor performs a self-check; this makes the Power LED turns on. The eight outlet LEDs will play a pattern and the network LED will come on once a link is detected.

# 2. Local Operation

## 2.1 Front Panel Buttons and LEDs

When the device is powered, any interaction with any buttons (Left, Set, Right) will start a 10s selection window, in which the currently selected channel is shown by a blinking orange light. After 10 seconds of inactivity the selection times out and no channel is highlighted.

Each channel has two indicators: a green LED showing whether the channel is on or off. An orange LED showing which channel is currently selected. Within the selection window, the user is able to turn on and off any channel.

Status LEDs:

- PWR LED indicates that the PDU is energized, and the internal power is within the expected range.
- ETH LED lights when a link is established on the Ethernet port.
- ERR LED lights if an internal error is detected; clear it with a long press of the Set button.

## 2.2 Button functions:

- Left / Right: Within the selection window, use these buttons to move the selection highlight across the eight channel status LEDs. The highlight wraps around after channel 8.
- Set:
- Outside the selection window, a short press on any button only opens the 10 s window (no step, no toggle).
- Inside the selection window, a short‑press toggles the currently selected channel on/off.
- Anytime, a long press (>1 s) clears the fault LED.
- PWR:
- Long press (>2s) when the device is powered initiates the low power sleep mode. The PWR LED blinks every second. Short press in active mode has no effect.
- Short press, when the device is in sleep mode wakes up the device and puts it back in active mode. Long press in sleep mode has no effect.

# 3. Command‑Line Interface - Serial

A comprehensive serial console is available over the USB‑C port (USB‑CDC). After connecting with a terminal program at 115200 baud basic system health information can be seen, emitted every 60 seconds. Type help to list commands.

## 3.1 Command list

Command | Description | Example
GENERAL COMMANDS
HELP | Show available commands and syntax
SYSINFO | Show system information
GET_TEMP | Show MCU temperature
REBOOT | Reboot the PDU. Changes to network settings take effect after reboot.
BOOTSEL | Put the MCU into boot mode
CLR_ERR | Clears all errors
RFS | Restore Factory Settings
OUTPUT CONTROL AND MEASUREMENT
SET_CH <ch> <STATE> | Set channel (1–8) to (0|1|ON| OFF|ALL) | SET_CH 1 1
GET_CH <ch> | Read current state of channel <ch> (1-8|ALL) | GET_CH 3
OC_STATUS | Show overcurrent protection status
OC_RESET | Manually clear overcurrent lockout
READ_HLW8032 | Read power data for all channels
READ_HLW8032 <ch> | Read power data for (1-8) | READ_HLW8032 2
CALIBRATE <ch> <V> <I> | Start single (1-8) calibration on given voltage and current | CALIBRATE 2 0 0
AUTO_CAL_ZERO | Zero-calibrate all channels.
AUTO_CAL_V <voltage> | Voltage-calibrate all channels. | AUTO_CAL_V 230
AUTO_CAL_I <current> <ch> | C u r r e n t - c a l i b r a t e s i n g l e channel (1–8). Requires known load | AUTO_CAL_I 0.5 2
SHOW_CALIB <ch> | Show calibration data (1-8|ALL) | SHOW_CALIB 5

NETWORK SETTINGS
NETINFO | Display the current IP, subnet m a s k , g a t e w a y a n d D N S addresses.
SET_IP <ip> | S e t a s t a t i c I P a d d r e s s . Requires reboot. | SET_IP 10.10.0.67
SET_SN <mask> | Set the subnet mask. | SET_SN 255.255.255.0
SET_GW <gw> | Set the default gateway. | SET_GW 192.168.1.1
SET_DNS <dns> | Set the DNS server. | SET_DNS 8.8.8.8
CONFIG_NETWORK <ip$sn$gw$dns> | Configure all network settings. | CONFIG_NETWORK 254.176.0.2 $255.255.255.0$254.176.0.1 $1.1.1.1

# 4. HTTP API

The embedded HTTP server listens on port 80 and exposes JSON endpoints under /api/... plus a few HTML pages (*.html) for browsers.

Notes
All API responses use HTTP/1.1 and include Connection: close. Status codes:
- GET /api/status → 200 OK (JSON body)
- GET /api/settings → 200 OK (JSON body)
- POST /api/control → 200 OK (text body OK)
- POST /api/settings → 204 No Content (device reboots).

### 4.1 GET /api/status

Returns a JSON object with:

- channels: array of 8 per-channel objects {voltage, current, uptime, power, state}
- internalTemperature: die temperature
- temperatureUnit: "°C" (or user-selected unit)
- systemStatus: overall status string
- overcurrent: OCP protection status and data

Example:

curl.exe -s http://<pdu-ip>/api/status

Response:

{
"channels": [
{ "voltage": 0, "current": 0, "uptime": 0, "power": 0, "state": false }, { "voltage": 0, "current": 0, "uptime": 0, "power": 0, "state": false }, { "voltage": 0, "current": 0, "uptime": 0, "power": 0, "state": false }, { "voltage": 0, "current": 0, "uptime": 0, "power": 0, "state": false }, { "voltage": 0, "current": 0, "uptime": 0, "power": 0, "state": false }, { "voltage": 0, "current": 0, "uptime": 0, "power": 0, "state": false }, { "voltage": 0, "current": 0, "uptime": 0, "power": 0, "state": false }, { "voltage": 0, "current": 0, "uptime": 0, "power": 0, "state": false } ],
"internalTemperature": 26.97,
"temperatureUnit": "°C",
"systemStatus": "OK",
"overcurrent":{
"state":"NORMAL",
"total_current_a":0.12,
"limit_a":10.0,
"warning_threshold_a":9.00, "critical_threshold_a":9.50, "recovery_threshold_a":8.50, "switching_allowed":true,
"trip_count":0,
"region":"EU"
}
}

## 4.2 POST /api/control

Controls the relays via form-encoded data. Each field name is channelN where N is 1–8:

- set on to turn a relay ON,
- set off to turn it OFF;
- if a channel field is omitted, that channel is forced OFF.

# Turn channel 1 and 3 ON (others OFF)

curl.exe -s -o $null -w "%{http_code}`n" -X POST "http://<pdu-ip>/api/control" --data "channel1=on&channel3=on"

# Turn channel 3 OFF (and leave others OFF by omission)

curl.exe -s -o $null -w "%{http_code}`n" -X POST "http://<pdu-ip>/api/control" --data "channel3="

All unspecified channels are forced off. A successful request returns 200 OK (body OK). Missing or malformed body returns 400 Bad Request.

## 4.3 GET /api/settings

Returns the stored network configuration and user preferences in JSON:

curl.exe -s "http://<pdu-ip>/api/settings"

Example response:

{
"ip":"192.168.0.12",
"gateway":"192.168.0.1",
"subnet":"255.255.255.0",
"dns":"8.8.8.8",
"device_name":"ENERGIS-1.1.0", "location":"Location",
"temp_unit":"celsius",
"temperature":33.35,
"timezone":"",
"time":"00:00:00",
"autologout":5
}

## 4.4 POST /api/settings

Updates | network | parameters | and | user | preferences. | Fields | include:
- ip,
- mask,
- gateway,
- dns,
- deviceName,
- location,
- tempUnit (C, F or K).

Changes are saved to EEPROM; the device responds 204 No Content and then reboots.

curl.exe -s -o $null -w "%{http_code}`n" -X POST "http://<pdu-ip>/api/settings" ^ --data "ip=192.168.0.12&gateway=192.168.0.1&subnet=255.255.255.0&dns=8.8.8.8&device_name =ENERGIS&location=Rack1&temp_unit=celsius"

# 5. HTML pages

## 5.1 GET /control.html

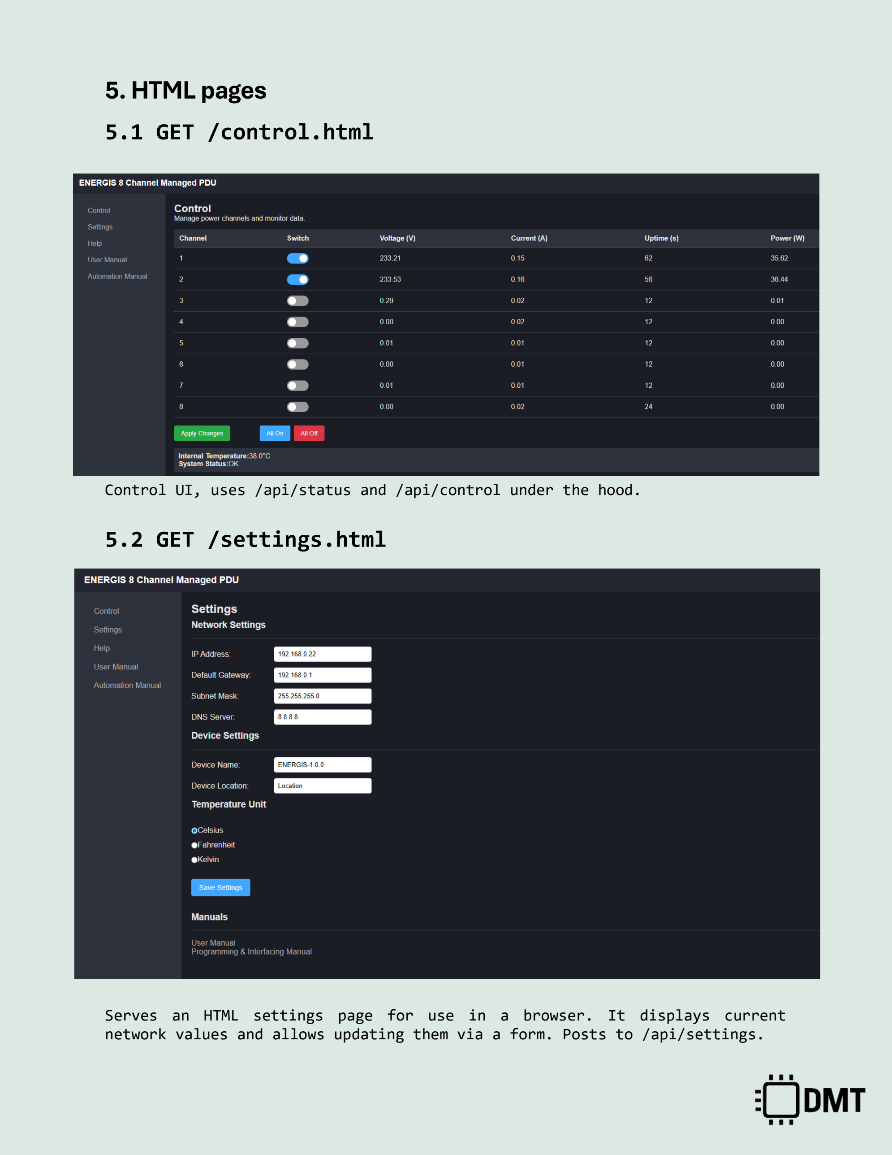
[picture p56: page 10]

Control UI, uses /api/status and /api/control under the hood.

## 5.2 GET /settings.html

Serves an HTML settings page for use in a browser. It displays current network values and allows updating them via a form. Posts to /api/settings.

5.3 GET /help.html, /user_manual.html,

## /programming_manual.html

These endpoints serve small HTML pages.

- /user_manual.html and /programming_manual.html: simple stubs that link to the PDFs hosted on GitHub Pages:
- User Manual
https://dvidmakesthings.github.io/HW_10-In-Rack_PDU/Manuals/User_Manual.pdf
- Programming & Interfacing Manual https://dvidmakesthings.github.io/HW_10-In-Rack_PDU/Manuals/Automation_Manual.pdf

Internet access is required to load those PDFs.
- /help.html: a fast help page that is served fully from the device. It does not depend on internet access and is meant for quick reference and basic troubleshooting when you’re offline.

HTTP behavior: All three return 200 OK, Content-Type: text/html, Cache-Control: no-cache, and the server closes the connection after sending the body.

What’s on /help.html? (fast help, offline-safe)

- Front panel cheatsheet
- Network quick checks
- Web API short guide
- SNMP sanity
- Offline troubleshooting

Why keep Help?

- It gives operators something usable when the site has no internet.
- It points to the full PDFs when WAN is available.
- It reduces support by solving the common “why doesn’t it switch / where’s my IP / why are values zero” cases directly on the box.

# 6. OpenMetrics / Prometheus endpoint

## 6.1 Overview

The ENERGIS PDU exposes a `/metrics` HTTP endpoint that provides runtime telemetry in OpenMetrics/Prometheus text format (version 0.0.4). This plugs directly into Prometheus, Grafana, and similar tools.

## 6.2 Configuration - Accessing the Endpoint

## curl.exe http://<pdu-ip-address>/metrics

## Example response

# HELP energis_up 1 if the metrics handler is healthy. # TYPE energis_up gauge

energis_up 1
# HELP energis_build_info Build and device identifiers.

# TYPE energis_build_info gauge energis_build_info{version="1.0.0",serial="SN-0167663"} 1

# HELP energis_uptime_seconds_total System uptime in seconds. # TYPE energis_uptime_seconds_total counter energis_uptime_seconds_total 27

# HELP energis_channel_state Relay state (1=ON, 0=OFF).

# TYPE energis_channel_state gauge

energis_channel_state{ch="1"} 1
# HELP energis_channel_telemetry_valid 1 if cached telemetry for chan nel is fresh.

# TYPE energis_channel_telemetry_valid gauge energis_channel_telemetry_valid{ch="1"} 1

# HELP energis_channel_voltage_volts Channel voltage. # TYPE energis_channel_voltage_volts gauge energis_channel_voltage_volts{ch="1"} 0.000

# HELP energis_channel_current_amps Channel current.

# TYPE energis_channel_current_amps gauge energis_channel_current_amps{ch="1"} 0.000

# HELP energis_channel_power_watts Active power per channel.

# TYPE energis_channel_power_watts gauge energis_channel_power_watts{ch="1"} 0.000

# HELP energis_channel_energy_watt_hours_total Accumulated energy per channel.

# TYPE energis_channel_energy_watt_hours_total counter energis_channel_energy_watt_hours_total{ch="1"} 0.000

## 6.3 Available Metrics

### 6.3.1 System

energis_up

Health indicator (gauge; 1 if handler responds)

energis_build_info{version,serial}

Build and device info (gauge; always 1)

energis_uptime_seconds_total

Uptime since boot in seconds (counter)

energis_internal_temperature_celsius

Internal MCU temperature, calibrated (gauge)

energis_temp_calibrated

1 if temperature calibration is applied (gauge)

energis_temp_calibration_mode

Calibration mode (0=none, 1=1pt, 2=2pt) (gauge)

energis_vusb_volts

USB rail voltage (gauge)

energis_vsupply_volts

12 V rail voltage (gauge)

energis_http_requests_total

Total HTTP requests served (counter)

### 6.3.2 Per-Channel

energis_channel_state{ch}

Relay state: 1=ON, 0=OFF (gauge)

energis_channel_telemetry_valid{ch}

1 if cached telemetry for channel is fresh (gauge)

energis_channel_voltage_volts{ch}

Channel voltage [V] (gauge)

energis_channel_current_amps{ch}

Channel current [A] (gauge)

energis_channel_power_watts{ch}

Active power [W] (gauge)

energis_channel_energy_watt_hours_total{ch}

Accumulated energy in watt-hours (counter)

Values are served from cached snapshots owned by MeterTask. No direct sensor I/O in the handler. Temperature uses the active calibration. If no calibration is stored, defaults are used.

### 6.3.3 Overcurrent protection

energis_ocp_state {state}

Overcurrent protection state (0=NORMAL,1=WARNING,2=CRITICAL,3=LOCKOUT)

energis_ocp_switching_allowed {state}

Switching allowed (1=yes,0=no)

energis_ocp_total_current_amps {value}

Total measured current value in Amps (A)

energis_ocp_limit_amps {value}

Configured current limit

- EU Version (IEC/ENEC): 10.0A maximum
- US Version (UL/CSA): 15.0A maximum

energis_ocp_warning_threshold_amps {value}

Warning threshold, Limit - 1A

energis_ocp_critical_threshold_amps {value}

Critical threshold Limit - 0.5A

energis_ocp_recovery_threshold_amps {value}

Recovery threshold Limit – 1.5A

energis_ocp_trip_count_total {cnt}

Overcurrent trips since boot

energis_ocp_last_trip_ms {t}

Timestamp of last trip (ms since boot)

## 6.4 Prometheus Integration

Add to `prometheus.yml`:

scrape_configs:
- job_name: 'energis-pdu'
scrape_interval: 15s
scrape_timeout: 10s
metrics_path: /metrics
static_configs:
- targets: ['192.168.0.22:80'] labels:
location: 'rack-1'
device: 'pdu-main'

Example Alerts

groups:
- name: energis
rules:
- alert: EnergisHighTemp
expr: energis_internal_temperature_celsius > 70 for: 2m
labels: {severity: warning}
annotations:
summary: "ENERGIS MCU hot >70C"
- alert: EnergisVsupplyLow
expr: energis_vsupply_volts < 10.8 for: 1m
labels: {severity: critical} annotations:
summary: "ENERGIS 12V rail low"
- alert: EnergisNoTelemetry
expr: sum(energis_channel_telemetry_valid) < 8 for: 2m
labels: {severity: warning}
annotations:
summary: "ENERGIS channel telemetry not fully valid"

## 6.5 Performance

- Static buffer ~4 KB. No heap allocations.
- Non-blocking, minimal CPU load.
- Typical response time < 50 ms
- If the output would overflow the buffer, the handler returns **503** to encourage a retry instead of serving a partial payload.

## 6.6 Implementation Notes

- Reads from MeterTask_GetTelemetry() and MeterTask_GetSystemTelemetry()
- Uses atomic counters for request accounting.
- OpenMetrics text format compatible with Prometheus 0.0.4.

# 7. SNMP interface

This firmware exposes a compact SNMPv1 agent (community public). A static table binds each OID to a getter (and sometimes a setter). The table itself carries the SNMP type and the maximum response length; the getters in the submodules return the bytes to match that declaration. Identity (MIB-II system) lives alongside a private enterprise subtree at 1.3.6.1.4.1.19865 for

- outlets,
- power telemetry,
- rails/temperature, and
- a read-only mirror of network settings.

No request performs heavy work: outlet writes toggle state immediately; reads return cached or computed values with fixed, short encodings.

Two encoding patterns matter:

- Outlet states are INTEGER (4 bytes):
- GET returns a 32-bit 0 or 1,
- SET treats any non-zero as “on”.
Group controls are also typed as INTEGER.
- Measurements (power, rails, temperature, etc.) and network values are OCTET STRINGs containing ASCII like "230.12" or "192.168.0.50". Parse as text. Buffers are small (≤16 bytes).

## 7.1 Submodules

System & table layer
Owns the SNMP community (public), publishes the MIB-II system group (sysDescr, sysObjectID=enterprise 1.3.6.1.4.1.19865, sysUpTime, sysContact, sysSN, sysLocation, sysServices), and wires all private OIDs to domain getters/setters. It also defines an initial warmStart trap helper under the same enterprise. The table is “dumb”: it declares type/length and calls into the right function; logic lives in the domain modules.

Key OIDs (system):

- 1.3.6.1.2.1.1.1.0 sysDescr (string)
- 1.3.6.1.2.1.1.2.0 sysObjectID = 1.3.6.1.4.1.19865
- 1.3.6.1.2.1.1.3.0 sysUpTime (TimeTicks)
- 1.3.6.1.2.1.1.4.0 sysContact (string)
- 1.3.6.1.2.1.1.5.0 sysSN (string)
- 1.3.6.1.2.1.1.6.0 sysLocation (string)
- 1.3.6.1.2.1.1.7.0 sysServices (INTEGER)

## 7.2 Outlet control (read/write)

Eight independent channels and two group triggers. Per-channel GET returns a 4-byte INTEGER (0/1). Per-channel SET: 0 → off, any non-zero → on. Group triggers apply the action when you write any non-zero, and their GET encodes whether all channels currently match that state. Internally, OID channels are 1..8; drivers use 0..7.

### 7.2.1 Per-channel state (INTEGER):

- Format:

.1.3.6.1.4.1.19865.2.<ch>.0 where <ch>=1..8

GET: int32 0 or 1
SET: i 0 or i 1 (non-zero treated as 1) Example (CH3):

snmpget -v1 -c public -Oqv <pdu-ip> 1.3.6.1.4.1.19865.2.3.0

### 7.2.2 Group controls (INTEGER):

- All OFF (trigger):

.1.3.6.1.4.1.19865.2.9.0

GET: '1' only if every channel is off; SET: non-zero → force all off.

- All ON (trigger):

.1.3.6.1.4.1.19865.2.10.0

GET: '1' only if every channel is on;
SET: non-zero → force all on.

Implementation detail: per-channel GET always returns exactly 4 bytes to match the table’s INTEGER declaration. Group GET encodes '0'/'1' via a one-byte helper but the table still declares INTEGER. Managers will still treat these as INTEGER because the table declares INTEGER, the single-byte helper is an internal optimization.

## 7.3 Power and energy telemetry

Six metrics per channel, all as ASCII strings in OCTET STRINGs, pulled from the cached metering snapshot (no blocking I/O on the SNMP path). If the cache isn’t valid yet, you’ll see zeros by design.

### 7.3.1 Per-channel telemetry:

- Voltage [V]: .1.3.6.1.4.1.19865.5.<ch>.1.0 → "%.2f"
- Current [A]: .1.3.6.1.4.1.19865.5.<ch>.2.0 → "%.3f"
- | Power [W]: | .1.3.6.1.4.1.19865.5.<ch>.3.0 → "%.1f"
- Power factor: .1.3.6.1.4.1.19865.5.<ch>.4.0 → "%.3f"
- Energy [kWh]: .1.3.6.1.4.1.19865.5.<ch>.5.0 → "%.3f"
- | Uptime [s]: | .1.3.6.1.4.1.19865.5.<ch>.6.0 → "12345"
(decimal ASCII)

Quick sense of outputs for channel 1:

snmpget -v1 -c public -Oqv <pdu-ip> 1.3.6.1.4.1.19865.5.1.1.0 | # "230.12"
snmpget -v1 -c public -Oqv <pdu-ip> 1.3.6.1.4.1.19865.5.1.2.0 | # "0.534"
snmpget -v1 -c public -Oqv <pdu-ip> 1.3.6.1.4.1.19865.5.1.3.0 | # "85.3"

Formatting is centralized (ftoa, u32toa) and capped at 16 bytes per response. Precision is uniform across channels and metrics.

## 7.4 Rails and temperature

On-die temperature and board rails, formatted as short ASCII. The module samples Pico ADC for the die sensor (with a tiny low-pass/settle step) and uses HAL helpers for external rails. Everything fits in 16 bytes.

OIDs:

- Die sensor (voltage): .1.3.6.1.4.1.19865.3.1.0 → "%.5f"
- Die temperature [°C]: .1.3.6.1.4.1.19865.3.2.0 → "%.3f"
- | V_SUPPLY [V]: | .1.3.6.1.4.1.19865.3.3.0 → "%.3f"
- | V_USB [V]: | .1.3.6.1.4.1.19865.3.4.0 → "%.3f"
- V_SUPPLY divider tap: .1.3.6.1.4.1.19865.3.5.0
- | V_USB divider tap: | .1.3.6.1.4.1.19865.3.6.0
- | Core VREG [V]: | .1.3.6.1.4.1.19865.3.7.0 → "%.2f"
- | Core VREG status: | .1.3.6.1.4.1.19865.3.8.0 →
"OK" | "Overload" | "Hi-Z" | "Unknown"
- | Bandgap ref: | .1.3.6.1.4.1.19865.3.9.0
- | USB PHY rail: | .1.3.6.1.4.1.19865.3.10.0
- | IO rail: | .1.3.6.1.4.1.19865.3.11.0

## 7.5 Network configuration mirror

Reflects the persisted network config (EEPROM) as dotted-decimal strings. These are not writable via SNMP in this build.

OIDs:

- IP address: .1.3.6.1.4.1.19865.4.1.0 → "A.B.C.D"
- Subnet mask: .1.3.6.1.4.1.19865.4.2.0 → "A.B.C.D"
- | Gateway: | .1.3.6.1.4.1.19865.4.3.0 → "A.B.C.D"
- DNS server: .1.3.6.1.4.1.19865.4.4.0 → "A.B.C.D"

## 7.6 Overcurrent

Overcurrent | protection | status | is | exposed | under | the | enterprise
subtree .1.3.6.1.4.1.19865.6.*.0. It reports the live OCP status snapshot (no blocking I/O on the SNMP path). Integer values use SNMP INTEGER (4 bytes). Floating values are returned as ASCII strings in OCTET STRINGs (fits in 16 bytes). If OCP is not initialized yet, values fall back to safe defaults (typically zeros / NORMAL).

### 7.6.1 OCP status OIDs

- OCP state: .1.3.6.1.4.1.19865.6.1.0 → INTEGER Values:
- 0 = NORMAL
- 1 = WARNING
- 2 = CRITICAL
- 3 = LOCKOUT
- Total current [A]: .1.3.6.1.4.1.19865.6.2.0 → "%.3f" (ASCII)
- Current limit [A]: .1.3.6.1.4.1.19865.6.3.0 → "%.2f" (ASCII)
- Warning threshold [A]: .1.3.6.1.4.1.19865.6.4.0 → "%.2f" (ASCII)
- Critical threshold [A]: .1.3.6.1.4.1.19865.6.5.0 → "%.2f" (ASCII)
- Recovery threshold [A]: .1.3.6.1.4.1.19865.6.6.0 → "%.2f" (ASCII)
- Last tripped channel: .1.3.6.1.4.1.19865.6.7.0 → INTEGER Values:
- 1..8 = outlet index that was switched OFF by OCP
- 0 = not available / fallback action used
- Trip count: .1.3.6.1.4.1.19865.6.8.0 → INTEGER Monotonic counter since boot.
- Last trip time [ms since boot]: .1.3.6.1.4.1.19865.6.9.0 → INTEGER
- Switching allowed: .1.3.6.1.4.1.19865.6.10.0 → INTEGER
Values:
- 0 = switching ON blocked (lockout)
- 1 = switching allowed

### 7.6.2 Manual OCP reset (SNMP SET)

A write-only control is provided to clear OCP lockout:

- | Reset/clear | lockout: | .1.3.6.1.4.1.19865.6.11.0 | → | INTEGER | (SET)
Any non-zero value triggers a lockout clear. Use only after reducing load, otherwise the device may immediately trip again.

## 7.7 Failure modes and things worth knowing

- Type discipline: outlet nodes are 4-byte INTEGERs; telemetry and network are ASCII strings. If your NMS expects numbers everywhere, it will complain on the string nodes. Parse them.
- “All on/off” asymmetry: those two reports aggregate state and execute batch writes on any non-zero input; 0 is ignored. Verify final state with per-channel GETs if you need certainty.
- Small buffers, fixed precision: string responses are capped at 16 bytes, with formats like "%.2f", "%.3f". If you widen precision in firmware, update the table lengths or you’ll truncate.
- Cached telemetry: power data is a snapshot from the MeterTask cache. Immediately after enabling a channel, it may read "0.000" until the next update. This path never blocks waiting for the meter.
- Network fallback: if EEPROM is blank or inaccessible, the network mirror returns compiled defaults. If your reads show defaults, the storage flow didn’t load.
- Table is authoritative: per-channel outlet GET always returns exactly 4 bytes to match the table’s INTEGER definition, even if the internal code path could compute a one-byte value. Keep your client side tolerant.

## 7.8 Summary

One static table, four domains. Outlets are writable INTEGER scalars at .1.3.6.1.4.1.19865.2.<ch>.0, with two INTEGER triggers for “all off/on.”

Power | telemetry | is | six | ASCII | string | metrics | per | channel
at .1.3.6.1.4.1.19865.5.<ch>.<metric>.0, pulled from a non-blocking cache.

Rails/temperature live under .1.3.6.1.4.1.19865.3.*.0 as short strings.

Network | settings | are | read-only, | dotted-decimal | strings
under .1.3.6.1.4.1.19865.4.*.0, with EEPROM-to-default fallback.

Respect types and 16-byte limits, assume cached updates for measurements, and rely on per-channel reads to verify group actions.

# 8. Support

For firmware updates and source code, visit the project’s GitHub repository. For technical support or to report bugs, contact the maintainer listed in the SNMP sysContact field (dvidmakesthings@gmail.com).

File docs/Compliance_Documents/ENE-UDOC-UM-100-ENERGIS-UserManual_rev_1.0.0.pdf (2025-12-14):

# USER MANUAL

# ENERGIS

# 10IN Managed PDU

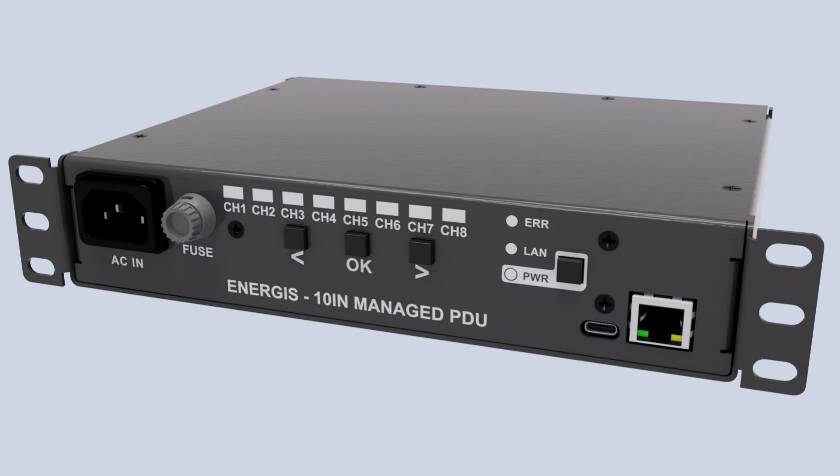
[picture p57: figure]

## Contents

## 1. Introduction

ENERGIS is an 8-channel managed power distribution unit (PDU) designed for small racks, lab environments and test benches where individual control of outlets and basic power monitoring are required. The device provides eight IEC C13 outlets in a compact 10-inch form factor and is intended to sit close to the equipment it supplies.

Each outlet can be switched independently, and the unit measures voltage, current, power and accumulated uptime per channel. This allows the user to power cycle devices remotely, check that loads are within expected limits and verify that equipment is actually drawing power. Status indicators on the front panel show the state of each outlet and the overall health of the device, giving a quick visual overview without the need for additional tools.

ENERGIS can be operated locally from the front panel or remotely over the network. A built-in web interface provides a simple control and monitoring view in any modern browser, without the need to install software on the host computer. Network settings and basic preferences can also be adjusted through the web interface so that the unit can be integrated into existing infrastructure with fixed addressing or custom naming.

For users who need deeper integration with monitoring and automation systems, ENERGIS also exposes a command line interface over USB, a structured HTTP API, an SNMP interface and an OpenMetrics endpoint suitable for Prometheus and similar tools. These programmable interfaces and their exact behavior are documented in detail in the separate Automation Manual. (https://dvidmakesthings.github.io/HW_10-In-Rack_PDU/Manuals/AUTOMATION_MANUAL.pdf)

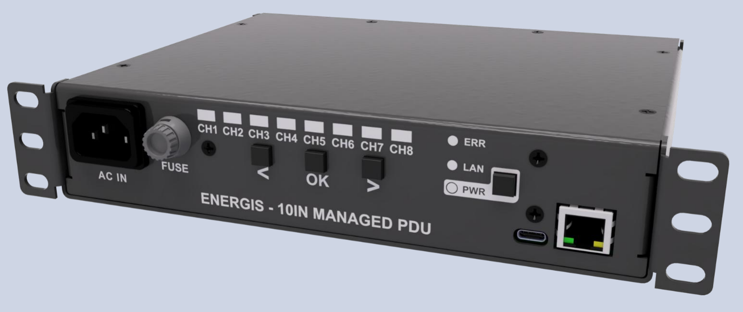
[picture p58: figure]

## 2. Safety and Warnings

This product switches and distributes mains voltage. Incorrect installation or use can lead to electric shock, fire, or damage to connected equipment. Read and follow all instructions in this section before putting ENERGIS into service.

## 2.1 Intended use

ENERGIS is a rack-mount power distribution unit for indoor IT, lab and similar equipment that is compatible with the local mains voltage and IEC C13 outlets. It is not a household extension cord, not a surge protector, and not a safety device. The unit is not designed or approved for life-support, medical, or any application where loss of power could result in injury or significant damage.

## 2.2 Personnel and access

Installation, wiring and servicing must be carried out only by qualified personnel familiar with mains electrical systems and local regulations.
- Do not open the enclosure. There are no user-serviceable parts inside.
- Servicing with the cover removed must only be performed with the unit fully disconnected from the AC supply.
- Do not modify the enclosure, wiring, connectors or protective earth.

## 2.3 Electrical ratings and loading

- AC input: 85-305 VAC
- Maximum input current: IEC/ENEC: 10A (EU), UL/CSA: 15A (US/CA).
- Maximum per-channel current: IEC/ENEC: 10A (EU), UL/CSA: 15A (US/CA).
- The sum of all active outlet currents must not exceed 10A (IEC/ENEC) or 15A (UL/CSA).

Do not daisy-chain multiple PDUs from a single outlet or feed another distribution strip from ENERGIS. Only connect equipment that is rated for the local mains voltage and fitted with suitable IEC C14 inlets or adapters approved for the load current. Exceeding these limits can overheat wiring and relay contacts and may cause fire or permanent damage to the unit.

## 2.4 Grounding and connection

The AC inlet must be connected to a properly grounded (earthed) mains outlet. Do not defeat the protective earth connection. Use only power cords with an approved plug for your region and with a current rating of at least the device rated input current (10 A for EU, 15 A for US/CA). Ensure that the rack and any metalwork are bonded to protective earth in accordance with applicable local electrical codes.

## 2.5 Environment and mounting

Intended for indoor use in dry locations only. Protect the unit from moisture, condensation, corrosive atmospheres and conductive dust. Operate within a range of 0 °C to 50 °C. At higher temperatures, reduce the total load to avoid overheating.

Mount the unit securely in a 10-inch rack or use it on a stable surface so that it cannot tip or fall. Do not cover the enclosure. Ensure adequate airflow around the unit and any other heat-generating equipment in the rack.

## 2.6 Operation and handling

Treat all outlets as live whenever the PWR indicator is on. Outlets may be switched remotely; equipment can become energized without local interaction at the rack. Before connecting, disconnecting or relocating loads, switch the affected outlet off and, if possible, disconnect the main supply.

Do not operate the unit if the enclosure, AC inlet, outlets or front-panel connectors show signs of damage, discoloration or overheating. Disconnect from mains and have the unit inspected by qualified service personnel.

## 2.7 Symbols

Where the following symbols are used on the product or in this manual, they have the meanings:

WARNING | - Risk of electric shock, fire or personal injury if
| instructions are ignored.
CAUTION | - Risk of equipment damage or data loss.

Following these safety instructions is a condition of proper use of the ENERGIS PDU.

## 3. Product Overview

ENERGIS is a compact 10-inch rack-mount PDU with individually switchable outlets and basic power monitoring per channel. It is intended to sit close to the equipment it supplies and to be operated either from the front panel or over the network.

## 3.1 Key features

- 8 individually switchable IEC C13 outlets.
- Per-channel indication of voltage, current, power and accumulated uptime.
- Front-panel status LEDs for outlet state, power status, network link and device health.
- Built-in web and SNMP interface for remote control and basic monitoring.
- Static IP configuration by default, changeable via the web interface or console.
- USB-C serial console for local configuration and diagnostics.

## 3.2 Rear panel

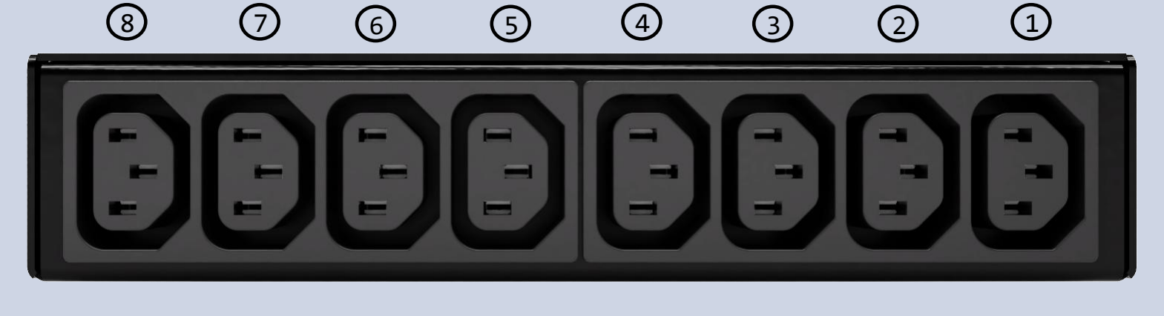
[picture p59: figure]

The rear panel carries the eight load outlets.

- Outlet block (CH1-CH8):
- Eight IEC C13 outlets for powering connected equipment.
- Outlets are numbered from 1 to 8 on the rear panel to match the channel indicators on the front panel.

## 3.3 Front panel

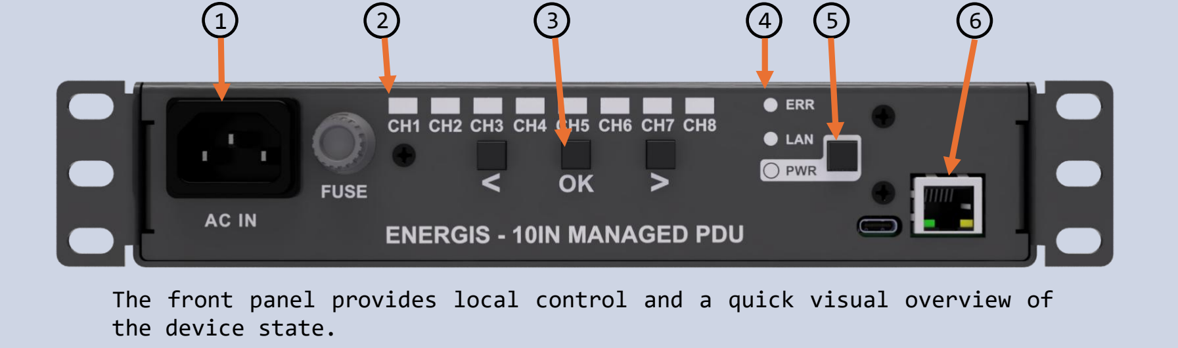
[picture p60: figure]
the device state.

The front panel provides local control and a quick visual overview of

1. AC inlet: IEC appliance inlet for connection to the mains supply. Use a suitable mains lead rated for the specified input current (see Safety and Specifications).
2. Channel indicators (CH1-CH8): One LED pair per outlet.
- Green LED: shows whether the corresponding outlet is switched on or off.
- Orange LED: used as a selection indicator during the 10 s selection window.
3. Navigation buttons
- < and >: move the active selection between channels during the selection window.
- OK: toggles the currently selected outlet on or off with a short press; used for local control as described in the Operation section.
4. Status LEDs
- ERR: lights when the unit has detected an internal fault condition.
- LAN: indicates that an Ethernet link is present.
- PWR: indicates that the internal power supply is within its expected operating range.
5. Power button
- Long press (>2s) when the device is powered initiates the low power sleep mode. The PWR LED blinks every second. Short press in active mode has no effect
- Short press, when the device is in sleep mode wakes up the device and puts it back in active mode.
6. Connectors
- USB-C: exposes the serial console as a USB-CDC device for configuration and diagnostics.
- RJ-45 Ethernet: network interface for the web interface and remote control.
s

## 4. Installation

This section describes how to put ENERGIS into service: mounting it in the rack, connecting the mains supply, attaching loads and bringing the network and optional USB console online. Read the Safety and Warnings chapter first and follow all local electrical regulations during installation.

## 4.1 Mounting

ENERGIS is intended for use in 10-inch racks and small cabinets. The unit should be mechanically secured before any electrical connections are made, and the mounting position should allow cables to be routed without strain and the front panel to remain visible.

Recommended procedure:
- Install ENERGIS in a suitable 10-inch rack or cabinet using the integrated mounting ears and appropriate screws or cage nuts.
- Support the unit during installation so that no mechanical stress is applied to the front panel, connectors or enclosure.
- Provide adequate clearance above, below and behind the unit for cable routing and basic airflow inside the rack.
- Avoid placing the unit directly above equipment that exhausts hot air upwards, unless the rack cooling is planned for this arrangement.
- Position the unit so that the front panel LEDs and buttons are clearly visible and accessible during normal operation and service.

## 4.2 Power connection

WARNING - Risk of electric shock, fire or personal injury if instructions are ignored. All work on the mains supply must be carried out by qualified personnel.

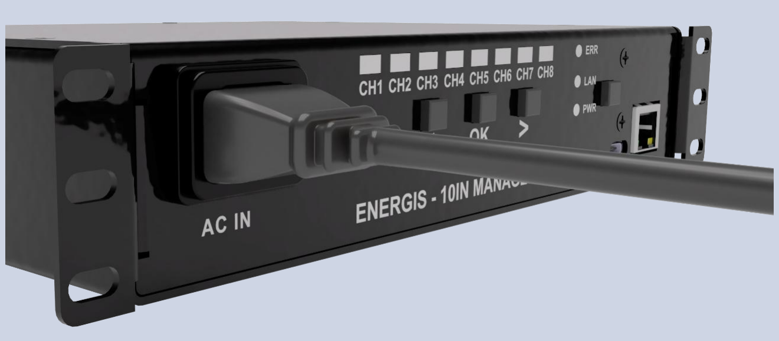
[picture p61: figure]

Before energizing the unit, verify that the local mains voltage matches the rating on the product label. All power connections must be made with the unit mechanically secured in the rack and using cables that are correctly rated for the expected current.

Recommended procedure:
- Verify that the local mains supply matches the voltage indicated on the ENERGIS rating label.
- Connect the AC inlet to a properly grounded mains outlet using a mains lead approved for your region and rated for at least the device rated input current (10A EU, 15A US/CA).
- Ensure that the upstream circuit protection (fuse or breaker) and wiring are suitable for the device rated input current (10A EU, 15A US/CA).
- Observe the overall loading limit: the sum of all active outlet currents must not exceed the device rated input current (10A EU, 15A US/CA).
- After switching on the upstream supply, check that the PWR LED on the front panel lights, indicating that the internal power supply is within its operating range.

## 4.3 Connecting loads

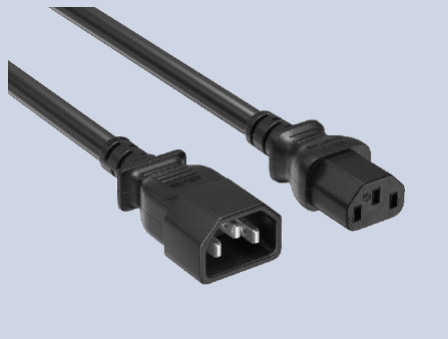
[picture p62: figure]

The rear panel provides eight IEC C13 outlets for the connected equipment. Loads should be distributed so that the total current remains within the specified limit and the rack wiring is not overstressed. It is good practice to document which device is connected to which
channel | to | avoid | confusion | during | remote
operation.

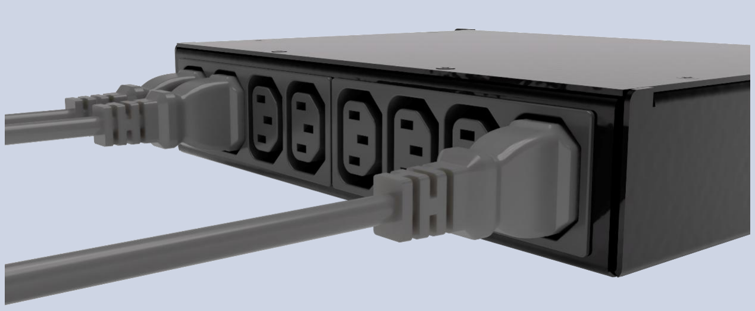
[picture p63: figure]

Recommended procedure:
- Connect equipment to the IEC C13 outlets using IEC C14 cord sets or suitable adapters that are correctly wired and rated for the required current.
- Match the outlet numbering (CH1 to CH8) on the rear panel with your installation documentation so that remote switching commands map to the intended devices.
- Where possible, switch the relevant channel off before plugging in or unplugging a device, to minimize arcing at the connector and avoid unplanned restarts.
- Distribute high-power devices across the outlets in a way that keeps the total current within the inlet rating (10A EU, 15A US/CA) and maintains a reasonable thermal load in the rack.
- Do not daisy chain other PDUs or multi-way extensions from ENERGIS outlets.

WARNING - Risk of electric shock, fire or personal injury if instructions are ignored. All work on the mains supply must be carried out by qualified personnel.

## 4.4 Network connection

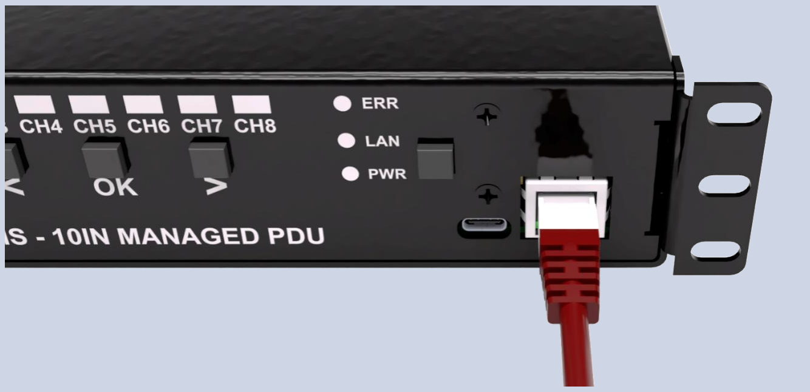
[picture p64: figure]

A network connection is required for access to the web interface and for remote monitoring or integration. ENERGIS ships with a static IP configuration that is printed on the product label so that the unit can be reached on a small dedicated segment immediately after installation.

Recommended procedure:
- Connect the RJ-45 Ethernet port on the front panel to a switch or
router | using | a | standard | twisted-pair | Ethernet | patch | cable
(CAT5/CAT5E).
- Confirm that the LAN LED lights, indicating that a physical link is present.
- Read the default static IP address from the label on the underside of the unit and verify that it is valid and non-conflicting on the intended network segment.
- From a host in the same subnet, open a web browser and enter the device IP to access the web interface.
- If your network requires a different static address or DHCP operation, plan the change and apply it later via the Settings page of the web interface, described in section 6.3.
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

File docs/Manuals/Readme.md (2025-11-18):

# ENERGIS - The Managed PDU Project for 10-Inch Rack - Manuals

## Contents
- Manuals

## Usage
This folder contains documentation and manuals for the 10-Inch_Rack-PDU project.

## License
This project is licensed under the GPL-3.0 License. See the [LICENSE](LICENSE) file for details.

## Contact
For questions or feedback:
- Email: [dvidmakesthings@gmail.com](mailto:dvidmakesthings@gmail.com)
- GitHub: [DvidMakesThings](https://github.com/DvidMakesThings)

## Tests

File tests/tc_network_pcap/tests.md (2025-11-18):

1. **Web-UI control path sanity (live capture → analyze)**
   Capture during a few on/off cycles from `/control` and assert packet counts & timing: filter `http.request.method == "POST" && tcp.port == 80`, expect at least N POSTs, and bound inter-packet gaps to catch stalls. Use `CapturePcap(..., interface="ethX", bpf="tcp port 80", duration_s=10)` then `analyze_PCAP(..., display_filter='http.request.method == "POST"', expect_count_min=3, time_delta_ns={"max": 200_000_000})`. This leans on your capture wrapper (dumpcap/tcpdump) and analyzer’s `expect_count/time_delta` checks.

2. **Status polling cadence**
   While the browser polls `/api/status`, verify the GET rate/jitter with `display_filter='http.request.method == "GET" && tcp.port == 80'` and a `time_delta_ns` window to ensure your HTTP server loop isn’t stuttering under load.&#x20;

3. **HTTP POST body presence guard**
   Hit the device with empty-body POSTs; confirm server replies but no crash/regress (you recently hardened writable body handling). Capture and assert at least one 204 response (`display_filter='http.response.code == 204'`) during the run.&#x20;

4. **ARP/DHCP baseline**
   Cold-boot the PDU, capture for 30 s on the subnet, and assert: ≥1 ARP probe/announce, expected DHCP handshake (if DHCP mode), and no excessive retries. Filters: `arp || (bootp)` with `expect_count_min` per phase.&#x20;

5. **VLAN correctness (generated PCAP → analyze)**
   Generate frames with single and stacked VLAN tags (e.g., 802.1Q and Q-in-Q) via `pcap_create(..., payload_len=46)` and validate `vlan_expect={"stack":[(100,None)]}` and then `[(100,None),(200,None)]`. Confirms analyzer’s VLAN stack parsing.

6. **IPv4 fragmentation handling (generator self-check)**
   Create a PCAP of auto-fragmented IPv4 packets (`ip_auto_fragment_payload_size=400`) and verify exact fragment count, MF flags via display filter (`ip.flags.mf == 1` for all but last), and ordered timestamps (strictly increasing deltas).&#x20;

7. **IFG/serialization timing math**
   Use `pcap_create` with `ifg_bytes` at a defined `link_speed_bps` (“1G”) to emit 100 frames; then assert `time_delta_ns` matches your expected IFG ± tolerance. Good to catch regressions in the link-speed parser.&#x20;

8. **FCS corruption demo (offline)**
   Generate two otherwise-identical frames where one has `fcs_xormask=0xFFFFFFFF`. Analyze both to confirm lengths equal and payloads match (via `contains_hex`), demonstrating how corrupted FCS looks in tools even if NIC would drop it live.&#x20;

9. **MAC & broadcast discipline**
   During “ALL ON/OFF” in the UI, capture and assert that PDU only talks unicast to the browser (no noisy broadcasts except ARP). Filters like `eth.dst == ff:ff:ff:ff:ff:ff` with `expect_count==0` over the control window.&#x20;

10. **Throughput under UI load**
    Start a background fetch loop on `/api/status` while toggling relays; capture and ensure TCP retransmits stay below a threshold: `display_filter='tcp.analysis.retransmission'`, `expect_count==0` (or small). Exercises your HTTP server’s robustness.

11. **Payload pattern checks for correctness**
    For `/settings` posts, validate ASCII form content landed on wire (e.g., `contains_ascii="ip=192.168.0.50"`) to ensure your form helpers/URL decode paths are behaving.

12. **Round-trip latency smoke**
    Trigger a single GET `/api/status`, capture SYN→FIN, and compute min/avg `time_delta_ns` between request and first response packet by filtering to that 5-tuple; use this as a quick firmware latency KPI over builds.&#x20;

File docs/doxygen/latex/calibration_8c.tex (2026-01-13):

\doxysection{src/\+Software/\+ENERGIS\+\_\+\+RTOS/src/tasks/storage\+\_\+submodule/calibration.c File Reference}
\hypertarget{calibration_8c}{}\label{calibration_8c}\index{src/Software/ENERGIS\_RTOS/src/tasks/storage\_submodule/calibration.c@{src/Software/ENERGIS\_RTOS/src/tasks/storage\_submodule/calibration.c}}

Sensor calibration storage for ENERGIS.  

{\ttfamily \#include "{}../../\+CONFIG.\+h"{}}\newline
Include dependency graph for calibration.\+c\+:\nopagebreak
\begin{figure}[H]
\begin{center}
\leavevmode
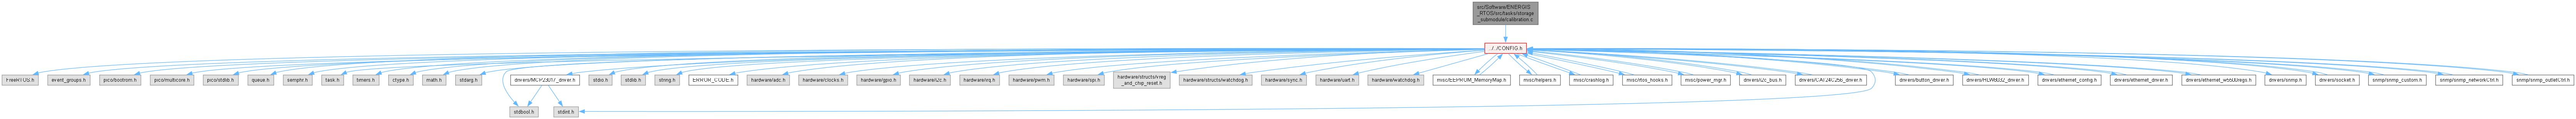
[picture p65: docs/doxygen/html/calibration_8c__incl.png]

\end{center}
\end{figure}
\doxysubsubsection*{Macros}
\begin{DoxyCompactItemize}
\item 
\#define \mbox{\hyperlink{calibration_8c_adac13c17c13978253eee1fe9e356d96e}{ST\+\_\+\+CAL\+\_\+\+TAG}}~"{}\mbox{[}ST-\/CAL\mbox{]}"{}
\end{DoxyCompactItemize}
\doxysubsubsection*{Functions}
\begin{DoxyCompactItemize}
\item 
int \mbox{\hyperlink{group__storage01_ga32076a8416bb992b9406dec24567cf71}{EEPROM\+\_\+\+Write\+Sensor\+Calibration}} (const uint8\+\_\+t \texorpdfstring{$\ast$}{*}data, size\+\_\+t len)
\begin{DoxyCompactList}\small\item\em Write entire HLW8032 sensor calibration block to EEPROM. \end{DoxyCompactList}\item 
int \mbox{\hyperlink{group__storage01_ga7182e6e053685a9aac34eee5097a7416}{EEPROM\+\_\+\+Read\+Sensor\+Calibration}} (uint8\+\_\+t \texorpdfstring{$\ast$}{*}data, size\+\_\+t len)
\begin{DoxyCompactList}\small\item\em Read entire HLW8032 sensor calibration block from EEPROM. \end{DoxyCompactList}\item 
int \mbox{\hyperlink{group__storage01_ga6fba2dcfc28ba004e71997f93c6b3d39}{EEPROM\+\_\+\+Write\+Sensor\+Calibration\+For\+Channel}} (uint8\+\_\+t ch, const \mbox{\hyperlink{structhlw__calib__t}{hlw\+\_\+calib\+\_\+t}} \texorpdfstring{$\ast$}{*}in)
\begin{DoxyCompactList}\small\item\em Write calibration record for single HLW8032 channel. \end{DoxyCompactList}\item 
int \mbox{\hyperlink{group__storage01_gaa3b6f1341ad447d7f7f95d1be802b1e7}{EEPROM\+\_\+\+Read\+Sensor\+Calibration\+For\+Channel}} (uint8\+\_\+t ch, \mbox{\hyperlink{structhlw__calib__t}{hlw\+\_\+calib\+\_\+t}} \texorpdfstring{$\ast$}{*}out)
\begin{DoxyCompactList}\small\item\em Read calibration record for single HLW8032 channel. \end{DoxyCompactList}\item 
static uint32\+\_\+t \mbox{\hyperlink{calibration_8c_ae8658b50ad7475f4740593d8f35c9999}{tempcal\+\_\+crc32}} (const void \texorpdfstring{$\ast$}{*}data, size\+\_\+t len)
\begin{DoxyCompactList}\small\item\em Compute a simple CRC32 (poly 0x\+EDB88320) over a buffer. \end{DoxyCompactList}\item 
static void \mbox{\hyperlink{calibration_8c_ac2a5362a8e4606ad12cb0d6c9941ef6d}{tempcal\+\_\+defaults}} (\mbox{\hyperlink{structtemp__calib__t}{temp\+\_\+calib\+\_\+t}} \texorpdfstring{$\ast$}{*}out)
\begin{DoxyCompactList}\small\item\em Fill \doxylink{structtemp__calib__t}{temp\+\_\+calib\+\_\+t} with safe defaults (no calibration). \end{DoxyCompactList}\item 
static int \mbox{\hyperlink{calibration_8c_abd5621818dd5300de23e2fd5c9106cea}{tempcal\+\_\+is\+\_\+valid}} (const \mbox{\hyperlink{structtemp__calib__t}{temp\+\_\+calib\+\_\+t}} \texorpdfstring{$\ast$}{*}in)
\begin{DoxyCompactList}\small\item\em Validate a temp calibration record (magic/version/ranges/\+CRC). \end{DoxyCompactList}\item 
static void \mbox{\hyperlink{calibration_8c_a94bdbf3b5ab88d4cfad2295e4b32b5c2}{tempcal\+\_\+finalize\+\_\+crc}} (\mbox{\hyperlink{structtemp__calib__t}{temp\+\_\+calib\+\_\+t}} \texorpdfstring{$\ast$}{*}rec)
\begin{DoxyCompactList}\small\item\em Compute and set CRC32 field for a record (over all but crc32). \end{DoxyCompactList}\item 
int \mbox{\hyperlink{group__storage01_gabc289be7b0cdbb53e52f48a0a10701ac}{EEPROM\+\_\+\+Write\+Temp\+Calibration}} (const \mbox{\hyperlink{structtemp__calib__t}{temp\+\_\+calib\+\_\+t}} \texorpdfstring{$\ast$}{*}cal)
\begin{DoxyCompactList}\small\item\em Write RP2040 temperature calibration record to EEPROM. \end{DoxyCompactList}\item 
int \mbox{\hyperlink{group__storage01_gac5ff91b753d7b36b811a2d75068006ed}{EEPROM\+\_\+\+Read\+Temp\+Calibration}} (\mbox{\hyperlink{structtemp__calib__t}{temp\+\_\+calib\+\_\+t}} \texorpdfstring{$\ast$}{*}out)
\begin{DoxyCompactList}\small\item\em Read RP2040 temperature calibration record from EEPROM. \end{DoxyCompactList}\item 
int \mbox{\hyperlink{group__storage01_ga73504452f7a1b317e752b7f668694a3d}{Temp\+Calibration\+\_\+\+Compute\+Single\+Point}} (float ambient\+\_\+c, uint16\+\_\+t raw\+\_\+temp, \mbox{\hyperlink{structtemp__calib__t}{temp\+\_\+calib\+\_\+t}} \texorpdfstring{$\ast$}{*}out)
\begin{DoxyCompactList}\small\item\em Compute single-\/point temperature calibration from reference measurement. \end{DoxyCompactList}\item 
int \mbox{\hyperlink{group__storage01_ga655669ab4b049b7ef9bcf70ea3d06ec6}{Temp\+Calibration\+\_\+\+Compute\+Two\+Point}} (float t1\+\_\+c, uint16\+\_\+t raw1, float t2\+\_\+c, uint16\+\_\+t raw2, \mbox{\hyperlink{structtemp__calib__t}{temp\+\_\+calib\+\_\+t}} \texorpdfstring{$\ast$}{*}out)
\begin{DoxyCompactList}\small\item\em Compute two-\/point temperature calibration from reference measurements. \end{DoxyCompactList}\item 
int \mbox{\hyperlink{group__storage01_ga7796a67e219e367ba5424202cff756ae}{Temp\+Calibration\+\_\+\+Apply\+To\+Meter\+Task}} (const \mbox{\hyperlink{structtemp__calib__t}{temp\+\_\+calib\+\_\+t}} \texorpdfstring{$\ast$}{*}cal)
\begin{DoxyCompactList}\small\item\em Apply temperature calibration to Meter\+Task measurement path. \end{DoxyCompactList}\item 
int \mbox{\hyperlink{group__storage01_ga1a4a0e2917c171c09500b674b6f2911f}{Temp\+Calibration\+\_\+\+Load\+And\+Apply}} (\mbox{\hyperlink{structtemp__calib__t}{temp\+\_\+calib\+\_\+t}} \texorpdfstring{$\ast$}{*}out)
\begin{DoxyCompactList}\small\item\em Load temperature calibration from EEPROM and apply to Meter\+Task. \end{DoxyCompactList}\end{DoxyCompactItemize}

\doxysubsection{Detailed Description}
Sensor calibration storage for ENERGIS. 

\begin{DoxyAuthor}{Author}
Dvid\+Makes\+Things -\/ David Sipos
\end{DoxyAuthor}
\begin{DoxyVersion}{Version}
1.\+2 
\end{DoxyVersion}
\begin{DoxyDate}{Date}
2025-\/11-\/15
\end{DoxyDate}

\begin{DoxyItemize}
\item HLW8032 (per-\/channel) calibration read/write helpers.
\item RP2040 die temperature calibration storage (single-\/point or two-\/point).
\item Application helper to push temp calibration into Meter\+Task.
\end{DoxyItemize}

CRITICAL\+: All EEPROM read/write functions here must be called with eeprom\+Mtx held.

@project ENERGIS -\/ The Managed PDU Project for 10-\/Inch Rack @github \href{https://github.com/DvidMakesThings/HW_10-In-Rack_PDU}{\texttt{https\+://github.\+com/\+Dvid\+Makes\+Things/\+HW\+\_\+10-\/\+In-\/\+Rack\+\_\+\+PDU}} 

\label{doc-define-members}
\Hypertarget{calibration_8c_doc-define-members}
\doxysubsection{Macro Definition Documentation}
\Hypertarget{calibration_8c_adac13c17c13978253eee1fe9e356d96e}\index{calibration.c@{calibration.c}!ST\_CAL\_TAG@{ST\_CAL\_TAG}}
\index{ST\_CAL\_TAG@{ST\_CAL\_TAG}!calibration.c@{calibration.c}}
\doxysubsubsection{\texorpdfstring{ST\_CAL\_TAG}{ST\_CAL\_TAG}}
{\footnotesize\ttfamily \label{calibration_8c_adac13c17c13978253eee1fe9e356d96e} 
\#define ST\+\_\+\+CAL\+\_\+\+TAG~"{}\mbox{[}ST-\/CAL\mbox{]}"{}}

\label{doc-func-members}
\Hypertarget{calibration_8c_doc-func-members}
\doxysubsection{Function Documentation}
\Hypertarget{calibration_8c_ae8658b50ad7475f4740593d8f35c9999}\index{calibration.c@{calibration.c}!tempcal\_crc32@{tempcal\_crc32}}
\index{tempcal\_crc32@{tempcal\_crc32}!calibration.c@{calibration.c}}
\doxysubsubsection{\texorpdfstring{tempcal\_crc32()}{tempcal\_crc32()}}
{\footnotesize\ttfamily \label{calibration_8c_ae8658b50ad7475f4740593d8f35c9999} 
uint32\+\_\+t tempcal\+\_\+crc32 (\begin{DoxyParamCaption}\item[{const void \texorpdfstring{$\ast$}{*}}]{data}{, }\item[{size\+\_\+t}]{len}{}\end{DoxyParamCaption})\hspace{0.3cm}{\ttfamily [static]}}

Compute a simple CRC32 (poly 0x\+EDB88320) over a buffer. 

\begin{DoxyParams}{Parameters}
{\em data} & Pointer to buffer \\
\hline
{\em len} & Length in bytes \\
\hline
\end{DoxyParams}
\begin{DoxyReturn}{Returns}
CRC32 value
\end{DoxyReturn}
\begin{DoxyNote}{Note}
Tiny software CRC32 for integrity. If code size is critical, you can replace with 0 and skip verification (leave crc32=0). 
\end{DoxyNote}
Here is the caller graph for this function\+:\nopagebreak
\begin{figure}[H]
\begin{center}
\leavevmode
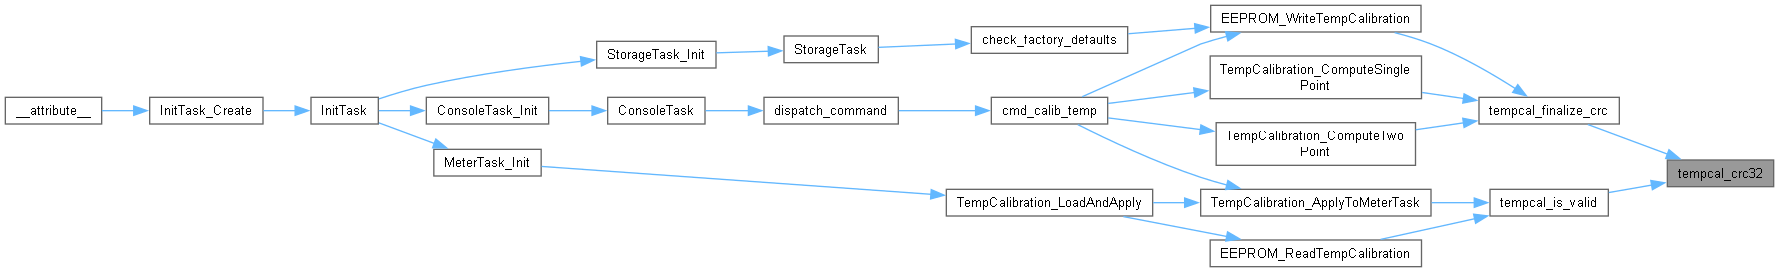
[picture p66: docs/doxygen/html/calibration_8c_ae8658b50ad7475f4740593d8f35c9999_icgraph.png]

\end{center}
\end{figure}
\Hypertarget{calibration_8c_ac2a5362a8e4606ad12cb0d6c9941ef6d}\index{calibration.c@{calibration.c}!tempcal\_defaults@{tempcal\_defaults}}
\index{tempcal\_defaults@{tempcal\_defaults}!calibration.c@{calibration.c}}
\doxysubsubsection{\texorpdfstring{tempcal\_defaults()}{tempcal\_defaults()}}
{\footnotesize\ttfamily \label{calibration_8c_ac2a5362a8e4606ad12cb0d6c9941ef6d} 
void tempcal\+\_\+defaults (\begin{DoxyParamCaption}\item[{\mbox{\hyperlink{structtemp__calib__t}{temp\+\_\+calib\+\_\+t}} \texorpdfstring{$\ast$}{*}}]{out}{}\end{DoxyParamCaption})\hspace{0.3cm}{\ttfamily [static]}}

Fill \doxylink{structtemp__calib__t}{temp\+\_\+calib\+\_\+t} with safe defaults (no calibration). 

\begin{DoxyParams}{Parameters}
{\em out} & Pointer to structure to initialize \\
\hline
\end{DoxyParams}
\begin{DoxyReturn}{Returns}
None 
\end{DoxyReturn}
Here is the caller graph for this function\+:\nopagebreak
\begin{figure}[H]
\begin{center}
\leavevmode

\end{center}
\end{figure}
\Hypertarget{calibration_8c_a94bdbf3b5ab88d4cfad2295e4b32b5c2}\index{calibration.c@{calibration.c}!tempcal\_finalize\_crc@{tempcal\_finalize\_crc}}
\index{tempcal\_finalize\_crc@{tempcal\_finalize\_crc}!calibration.c@{calibration.c}}
\doxysubsubsection{\texorpdfstring{tempcal\_finalize\_crc()}{tempcal\_finalize\_crc()}}
{\footnotesize\ttfamily \label{calibration_8c_a94bdbf3b5ab88d4cfad2295e4b32b5c2} 
void tempcal\+\_\+finalize\+\_\+crc (\begin{DoxyParamCaption}\item[{\mbox{\hyperlink{structtemp__calib__t}{temp\+\_\+calib\+\_\+t}} \texorpdfstring{$\ast$}{*}}]{rec}{}\end{DoxyParamCaption})\hspace{0.3cm}{\ttfamily [static]}}

Compute and set CRC32 field for a record (over all but crc32). 

\begin{DoxyParams}{Parameters}
{\em rec} & Pointer to record to update \\
\hline
\end{DoxyParams}
\begin{DoxyReturn}{Returns}
None 
\end{DoxyReturn}
Here is the call graph for this function\+:\nopagebreak
\begin{figure}[H]
\begin{center}
\leavevmode

\end{center}
\end{figure}
Here is the caller graph for this function\+:\nopagebreak
\begin{figure}[H]
\begin{center}
\leavevmode

\end{center}
\end{figure}
\Hypertarget{calibration_8c_abd5621818dd5300de23e2fd5c9106cea}\index{calibration.c@{calibration.c}!tempcal\_is\_valid@{tempcal\_is\_valid}}
\index{tempcal\_is\_valid@{tempcal\_is\_valid}!calibration.c@{calibration.c}}
\doxysubsubsection{\texorpdfstring{tempcal\_is\_valid()}{tempcal\_is\_valid()}}
{\footnotesize\ttfamily \label{calibration_8c_abd5621818dd5300de23e2fd5c9106cea} 
int tempcal\+\_\+is\+\_\+valid (\begin{DoxyParamCaption}\item[{const \mbox{\hyperlink{structtemp__calib__t}{temp\+\_\+calib\+\_\+t}} \texorpdfstring{$\ast$}{*}}]{in}{}\end{DoxyParamCaption})\hspace{0.3cm}{\ttfamily [static]}}

Validate a temp calibration record (magic/version/ranges/\+CRC). 

\begin{DoxyParams}{Parameters}
{\em in} & Pointer to record to validate \\
\hline
\end{DoxyParams}
\begin{DoxyReturn}{Returns}
1 if valid, 0 otherwise 
\end{DoxyReturn}
Here is the call graph for this function\+:\nopagebreak
\begin{figure}[H]
\begin{center}
\leavevmode

\end{center}
\end{figure}
Here is the caller graph for this function\+:\nopagebreak
\begin{figure}[H]
\begin{center}
\leavevmode

\end{center}
\end{figure}

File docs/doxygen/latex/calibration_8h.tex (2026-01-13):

\doxysection{src/\+Software/\+ENERGIS\+\_\+\+RTOS/src/tasks/storage\+\_\+submodule/calibration.h File Reference}
\hypertarget{calibration_8h}{}\label{calibration_8h}\index{src/Software/ENERGIS\_RTOS/src/tasks/storage\_submodule/calibration.h@{src/Software/ENERGIS\_RTOS/src/tasks/storage\_submodule/calibration.h}}
{\ttfamily \#include "{}../../\+CONFIG.\+h"{}}\newline
Include dependency graph for calibration.\+h\+:\nopagebreak
\begin{figure}[H]
\begin{center}
\leavevmode
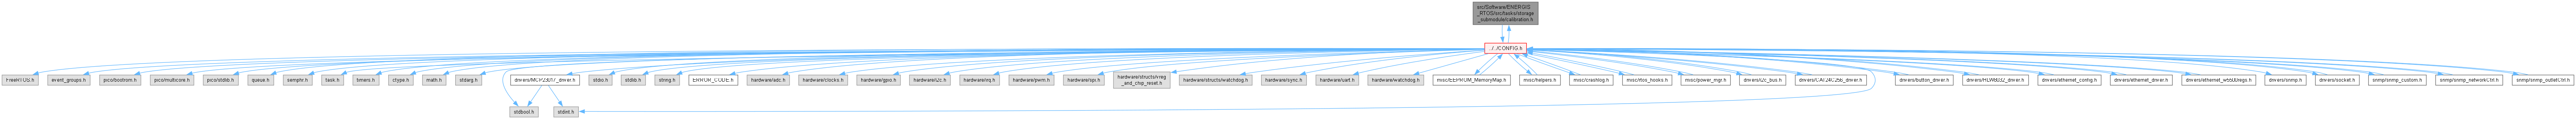
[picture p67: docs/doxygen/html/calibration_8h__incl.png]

\end{center}
\end{figure}
This graph shows which files directly or indirectly include this file\+:\nopagebreak
\begin{figure}[H]
\begin{center}
\leavevmode
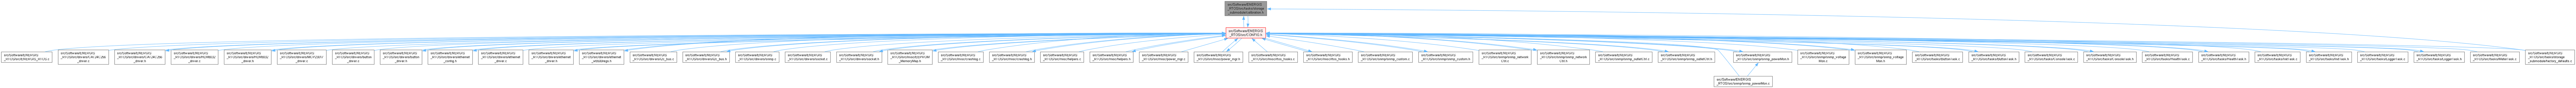
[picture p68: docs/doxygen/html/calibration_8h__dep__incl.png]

\end{center}
\end{figure}
\doxysubsubsection*{Classes}
\begin{DoxyCompactItemize}
\item 
struct \mbox{\hyperlink{structtemp__calib__t}{temp\+\_\+calib\+\_\+t}}
\begin{DoxyCompactList}\small\item\em Persistent temperature calibration record. \end{DoxyCompactList}\end{DoxyCompactItemize}
\doxysubsubsection*{Macros}
\begin{DoxyCompactItemize}
\item 
\#define \mbox{\hyperlink{group__storage01_ga4a6ecc46bafd36de50a097f2c1fd4e13}{TEMP\+\_\+\+CAL\+\_\+\+MAGIC}}~((uint16\+\_\+t)((\textquotesingle{}T\textquotesingle{} $<$$<$ 8) \texorpdfstring{$\vert$}{|} \textquotesingle{}C\textquotesingle{}))
\begin{DoxyCompactList}\small\item\em Magic value stored in calibration record. \end{DoxyCompactList}\item 
\#define \mbox{\hyperlink{group__storage01_gaa51b50a0f7206b13a9f06906d666a804}{TEMP\+\_\+\+CAL\+\_\+\+VERSION}}~(0x0001u)
\begin{DoxyCompactList}\small\item\em Calibration record version. \end{DoxyCompactList}\end{DoxyCompactItemize}
\doxysubsubsection*{Enumerations}
\begin{DoxyCompactItemize}
\item 
enum \{ \mbox{\hyperlink{group__storage01_gga545df4a8b3ff70d5c24352e94595aef2ad83450dfec571e919836cb1c5b7cf347}{TEMP\+\_\+\+CAL\+\_\+\+FLAG\+\_\+\+VALID}} = 1u \texorpdfstring{$<$}{<}\texorpdfstring{$<$}{<} 0
, \mbox{\hyperlink{group__storage01_gga545df4a8b3ff70d5c24352e94595aef2a96e7d3210cdf212589ee3ed109387eb8}{TEMP\+\_\+\+CAL\+\_\+\+FLAG\+\_\+\+TWO\+\_\+\+PT}} = 1u \texorpdfstring{$<$}{<}\texorpdfstring{$<$}{<} 1
 \}
\begin{DoxyCompactList}\small\item\em Calibration flags. \end{DoxyCompactList}\item 
enum \mbox{\hyperlink{group__storage01_ga8c6878800e86fa5968286d14291c03c9}{temp\+\_\+cal\+\_\+mode\+\_\+t}} \{ \mbox{\hyperlink{group__storage01_gga8c6878800e86fa5968286d14291c03c9afaafc760636677bdccbd75a0ade4e868}{TEMP\+\_\+\+CAL\+\_\+\+MODE\+\_\+\+NONE}} = 0
, \mbox{\hyperlink{group__storage01_gga8c6878800e86fa5968286d14291c03c9a9e5eeeb58b780130e9ba647f850eac35}{TEMP\+\_\+\+CAL\+\_\+\+MODE\+\_\+1\+PT}} = 1
, \mbox{\hyperlink{group__storage01_gga8c6878800e86fa5968286d14291c03c9abf1d6d146c10f96025ffbc33f464152e}{TEMP\+\_\+\+CAL\+\_\+\+MODE\+\_\+2\+PT}} = 2
 \}
\end{DoxyCompactItemize}
\doxysubsubsection*{Functions}
\begin{DoxyCompactItemize}
\item 
int \mbox{\hyperlink{group__storage01_ga32076a8416bb992b9406dec24567cf71}{EEPROM\+\_\+\+Write\+Sensor\+Calibration}} (const uint8\+\_\+t \texorpdfstring{$\ast$}{*}data, size\+\_\+t len)
\begin{DoxyCompactList}\small\item\em Write entire HLW8032 sensor calibration block to EEPROM. \end{DoxyCompactList}\item 
int \mbox{\hyperlink{group__storage01_ga7182e6e053685a9aac34eee5097a7416}{EEPROM\+\_\+\+Read\+Sensor\+Calibration}} (uint8\+\_\+t \texorpdfstring{$\ast$}{*}data, size\+\_\+t len)
\begin{DoxyCompactList}\small\item\em Read entire HLW8032 sensor calibration block from EEPROM. \end{DoxyCompactList}\item 
int \mbox{\hyperlink{group__storage01_ga6fba2dcfc28ba004e71997f93c6b3d39}{EEPROM\+\_\+\+Write\+Sensor\+Calibration\+For\+Channel}} (uint8\+\_\+t ch, const \mbox{\hyperlink{structhlw__calib__t}{hlw\+\_\+calib\+\_\+t}} \texorpdfstring{$\ast$}{*}in)
\begin{DoxyCompactList}\small\item\em Write calibration record for single HLW8032 channel. \end{DoxyCompactList}\item 
int \mbox{\hyperlink{group__storage01_gaa3b6f1341ad447d7f7f95d1be802b1e7}{EEPROM\+\_\+\+Read\+Sensor\+Calibration\+For\+Channel}} (uint8\+\_\+t ch, \mbox{\hyperlink{structhlw__calib__t}{hlw\+\_\+calib\+\_\+t}} \texorpdfstring{$\ast$}{*}out)
\begin{DoxyCompactList}\small\item\em Read calibration record for single HLW8032 channel. \end{DoxyCompactList}\item 
int \mbox{\hyperlink{group__storage01_gabc289be7b0cdbb53e52f48a0a10701ac}{EEPROM\+\_\+\+Write\+Temp\+Calibration}} (const \mbox{\hyperlink{structtemp__calib__t}{temp\+\_\+calib\+\_\+t}} \texorpdfstring{$\ast$}{*}cal)
\begin{DoxyCompactList}\small\item\em Write RP2040 temperature calibration record to EEPROM. \end{DoxyCompactList}\item 
int \mbox{\hyperlink{group__storage01_gac5ff91b753d7b36b811a2d75068006ed}{EEPROM\+\_\+\+Read\+Temp\+Calibration}} (\mbox{\hyperlink{structtemp__calib__t}{temp\+\_\+calib\+\_\+t}} \texorpdfstring{$\ast$}{*}out)
\begin{DoxyCompactList}\small\item\em Read RP2040 temperature calibration record from EEPROM. \end{DoxyCompactList}\item 
int \mbox{\hyperlink{group__storage01_ga73504452f7a1b317e752b7f668694a3d}{Temp\+Calibration\+\_\+\+Compute\+Single\+Point}} (float ambient\+\_\+c, uint16\+\_\+t raw\+\_\+temp, \mbox{\hyperlink{structtemp__calib__t}{temp\+\_\+calib\+\_\+t}} \texorpdfstring{$\ast$}{*}out)
\begin{DoxyCompactList}\small\item\em Compute single-\/point temperature calibration from reference measurement. \end{DoxyCompactList}\item 
int \mbox{\hyperlink{group__storage01_ga655669ab4b049b7ef9bcf70ea3d06ec6}{Temp\+Calibration\+\_\+\+Compute\+Two\+Point}} (float t1\+\_\+c, uint16\+\_\+t raw1, float t2\+\_\+c, uint16\+\_\+t raw2, \mbox{\hyperlink{structtemp__calib__t}{temp\+\_\+calib\+\_\+t}} \texorpdfstring{$\ast$}{*}out)
\begin{DoxyCompactList}\small\item\em Compute two-\/point temperature calibration from reference measurements. \end{DoxyCompactList}\item 
int \mbox{\hyperlink{group__storage01_ga7796a67e219e367ba5424202cff756ae}{Temp\+Calibration\+\_\+\+Apply\+To\+Meter\+Task}} (const \mbox{\hyperlink{structtemp__calib__t}{temp\+\_\+calib\+\_\+t}} \texorpdfstring{$\ast$}{*}cal)
\begin{DoxyCompactList}\small\item\em Apply temperature calibration to Meter\+Task measurement path. \end{DoxyCompactList}\item 
int \mbox{\hyperlink{group__storage01_ga1a4a0e2917c171c09500b674b6f2911f}{Temp\+Calibration\+\_\+\+Load\+And\+Apply}} (\mbox{\hyperlink{structtemp__calib__t}{temp\+\_\+calib\+\_\+t}} \texorpdfstring{$\ast$}{*}out)
\begin{DoxyCompactList}\small\item\em Load temperature calibration from EEPROM and apply to Meter\+Task. \end{DoxyCompactList}\end{DoxyCompactItemize}

\doxysubsection{Detailed Description}
\begin{DoxyAuthor}{Author}
Dvid\+Makes\+Things -\/ David Sipos 
\end{DoxyAuthor}

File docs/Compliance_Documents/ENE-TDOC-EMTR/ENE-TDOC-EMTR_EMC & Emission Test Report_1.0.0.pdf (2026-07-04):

Sunday, 29th March 2026 | page: 1/23

INDES EMC e.U.
TEL +43677/63061029 | MAIL. office@indes-emc.at ADR. Zetschegasse 3/004, 1230-W
| www.indes-emc.at
TEST REPORT Doc. | EMC-VRP-ENERGIS-10IN-MPDU

Manufacturers Verification Report for Electro Magnetic Compatibility, according to The EMC Directive 2014/30/EU, Annex II, Module A, 2. Electromagnetic compatibility assessment in regards of radiated emission, excluding immunity tests. (EMC screening)

Report Information | Details
Report Title: | EMC Test Report according to EN IEC 61000-6-3
Product Under Test (PUT): | ENERGIS-10IN-MPDU
Applied Standard: | EN 61000-6-3:2007 + A1:2011 (IEC 61000-6-3:2006 + A1:2010)
Test Category: | Managed distributed power delivery unity
Report Revision/STATE: | 1
Date of Issue: | 29.03.2026
Organization Information | Details
Manufacturer: | Private person – David Sipos
Applicant: | David Sipos
Test Laboratory: | INDES EMC e.U. Zetschegasse 3, 1230 Wien, Austria
Test Date(s): | 29.03.2026
Harmonized Standard | Final Verdict | Categorization | Reference
EN 61000-6-3 | PASS | N/A | 3.1

## History of Changes

Date | Author | Revision | Modification
29.03.2026 | Aleksandar Sindrak/ INDES EMC | 1 | Initial Version

## Signature Page

Authorized Person(obligatory):

N/A___________________________ (Not applicable for pre- Verification report)

Name, Surname, Title

Test Conductor(obligatory):

N/A ___________________________ (Not applicable for pre- Verification report)

Name, Surname, Title

Test Service Partner (optional):

N/A ___________________________ (Not applicable for pre- Verification report) Ing. Aleksandar Sindrak

## Table of Contents

## 1.General Information

## 1.1 Equipment under test (EUT)

EUT: | ENERGIS – 10IN MANAGED PDU
Product Identification: | N/A
Product Revision: | Revision 1
Product Fitting Variant: | Representative functional prototype
Serial number/s: | 0167665
Date of manufacturing: | Q4/2025
Manufacturer: | David Sipos
Address: | N/A
Description of the EUT: | The 10IN MANAGED PDU is a power distribution device that delivers from an AC inlet power to 8 output sockects. It is intended to be used in light industrial/residual environments and is rack mounted.

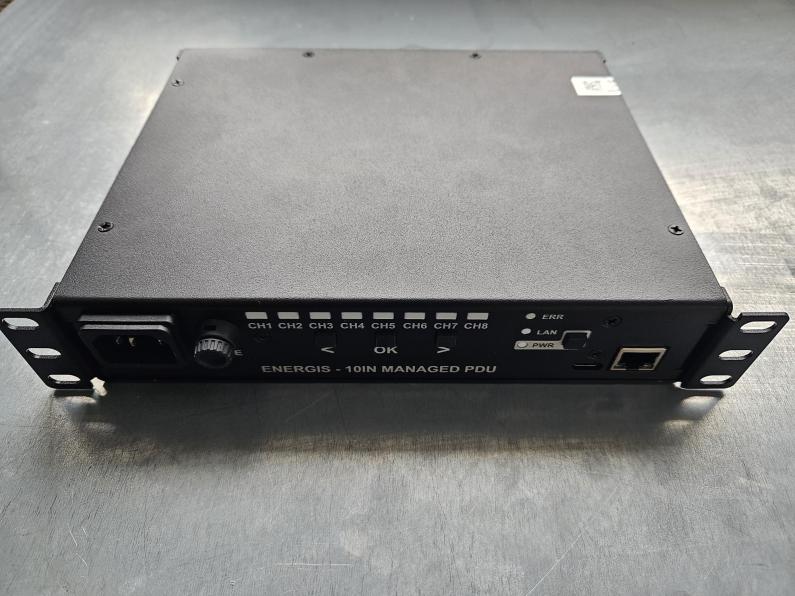
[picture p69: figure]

Figure 1: ENERGIS 10IN MANAGED PDU

## 1.2 Test Setup Configurations

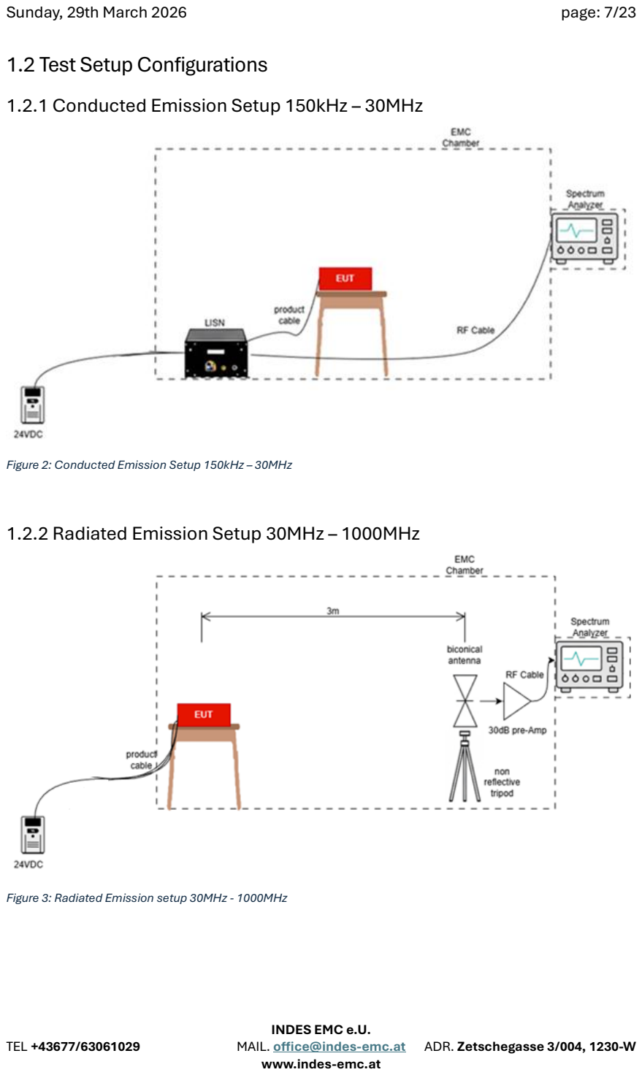
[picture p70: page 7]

1.2.1 Conducted Emission Setup 150kHz – 30MHz

Figure 2: Conducted Emission Setup 150kHz – 30MHz

1.2.2 Radiated Emission Setup 30MHz – 1000MHz

Figure 3: Radiated Emission setup 30MHz - 1000MHz

## 2. Test Plan

## 2.1 Applicable emission limits according to IEC 61000-6-3

2.1.1 Conducted emission Limits

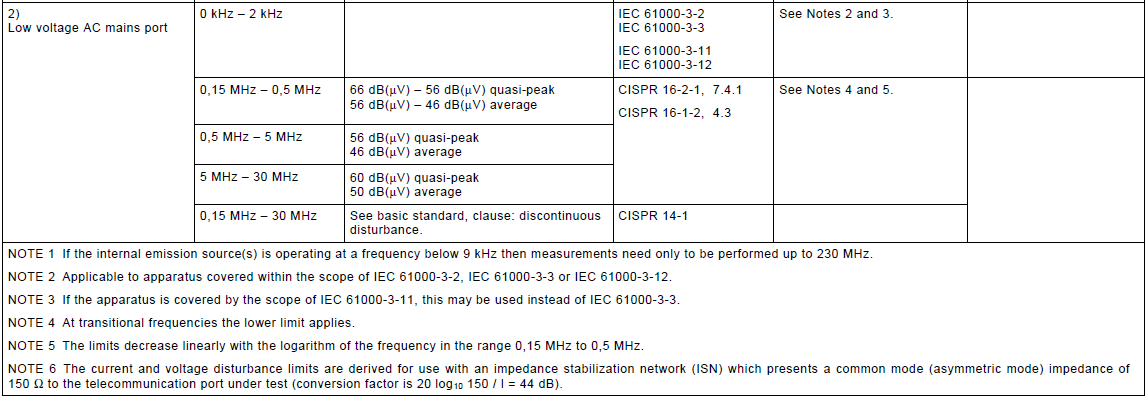
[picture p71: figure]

Figure 4: Extract IEC 61000-6-3, Table 1

2.1.2 Radiated emission Limits

Figure 5: Extract IEC 61000-6-3, Table (continued)

## 2.2 Pre assessment Test plan for the EUT in accordance of IEC 61000-6-3

Test Index | Definition | Limit/Severity | Performance Criterion
CE1 | Conducted emission of an AC power port | 0,15 MHz – 0,5 MHz 66 dB(μV) – 56 dB(μV) quasi-peak 56 dB(μV) – 46 dB(μV) average 0,5 MHz – 5 MHz 56 dB(μV) quasi-peak 46 dB(μV) average 5 MHz – 30 MHz 60 dB(μV) quasi-peak 50 dB(μV) average | N/A
RE1 | Radiated emission of EUT acc. IEC 61000-6-3 at 3m distance to Antenna | 30 – 230 MHz: 40dB(µV/m) QP 230 – 1000 MHz: 47dB(µV/m) QP | N/A

Table 1: Test Plan for the EUT

## 3. Test Results

## 3.1 Test Results overview

Test Index | Definition | Reference | Performance Criterion | Verdict
CE1 | Conducted emission of an AC power port | 3.2.1 | N/A | PASSED
RE1 | Radiated emission of EUT acc. IEC 61000-6-3 at 3m distance to Antenna | 3.2.2 | N/A | PASSED

Table 2: Test Result overview for the EUT

## 3.2 Detailed Test Results

3.2.1 CE1 – Conducted Emission
3.2.1.1 Test Setup
See 1.2.1 Conducted Emission Setup 150kHz – 30MHz for test setup arrangement.
3.2.1.2 | Test Level
Test Method | Level
Conducted emission over LISN | 0,15 MHz – 0,5 MHz 66 dB(μV) – 56 dB(μV) quasi-peak 56 dB(μV) – 46 dB(μV) average 0,5 MHz – 5 MHz 56 dB(μV) quasi-peak 46 dB(μV) average 5 MHz – 30 MHz 60 dB(μV) quasi-peak 50 dB(μV) average
3.2.1.3 | Test Procedure
The test equipment was placed on a wooden table, and 40cm away from the conductive chamber wall. The EUT was brought into operational mode in a stimulated scenario which favours high emissions (no load, high smps du/dt).Under these operational conditions the AC inlet power port was measured for conducted emissions.
3.2.1.4 Test Verdict
PASSED
3.2.1.5 | Used Equipment
Equipment | Make | Model | Calibration
LISN | TEKBOX | TBL5008-2C | 2026-MAR
Spectrum Analyzer | SIGLENT | SSA3032X | 2024
High pass filter | Tekbox | TBHPF1-150kHz | N/A
HSAR Chamber | INDES EMC | 3,5m/2m/1,1m | N/A
EMC Software | Tekbox | EMCVIEW V10.02 | N/A

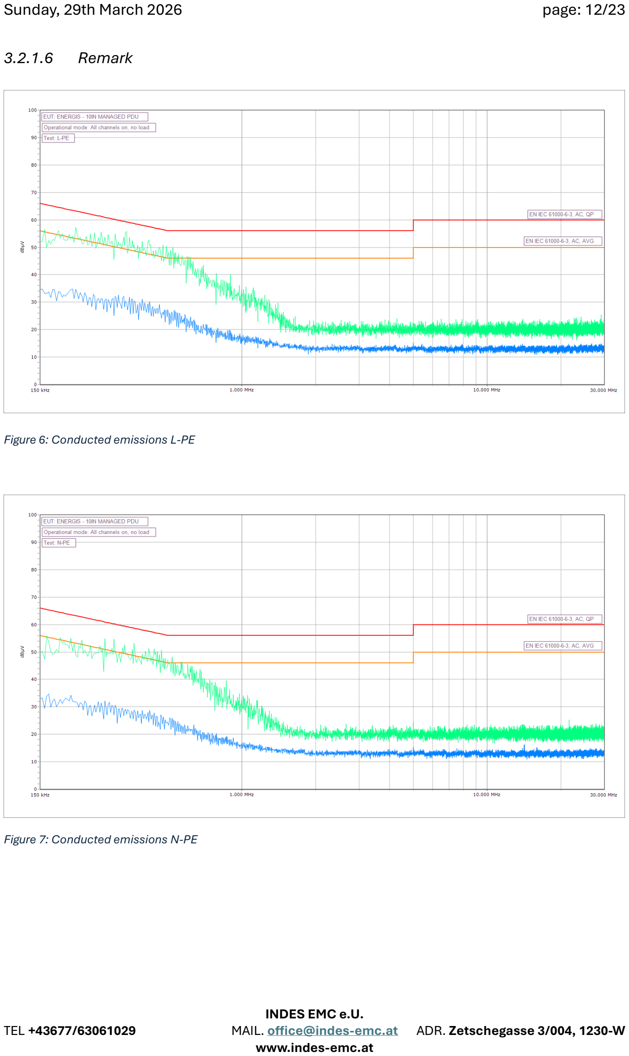
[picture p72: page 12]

3.2.1.6 Remark

Figure 6: Conducted emissions L-PE

Figure 7: Conducted emissions N-PE

3.2.2 RE1 – Radiated Emissions
3.2.2.1 Test Setup
See 1.2.2 Radiated Emission Setup 30MHz – 1000MHz for test setup arrangement.
3.2.2.2 | Test Level
Test Method | Level
Radiated emission over antenna, 3m distance in chamber | 30 – 230 MHz: 40dB(µV/m) QP 230 – 1000 MHz: 47dB(µV/m) QP
3.2.2.3 | Test Procedure
The test equipment was placed on a wooden table, and 3m away from the measurement antenna. The EUT was brought into operational mode in a stimulus scenario which according favors high emissions.
Under these operational conditions the EUT was measured for radiated emissions.

3.2.2.4 Test Verdict
PASSED
3.2.2.5 | Used Equipment
Equipment | Make | Model | Calibration
Spectrum Analyzer | SIGLENT | SSA3032X | 2024
High pass filter | Tekbox | TBHPF1-150kHz | N/A
HSAR Chamber | INDES EMC | 3,5m/2m/1,1m | N/A
Power supply 24V | Delta Elektronika | SM6020 | N/A
Power supply 60V | Delta Elektronika | SM6020 | N/A
Biconical Antenna | Tekbox | TBMA1B | 2025
EMC Software | Tekbox | EMCVIEW V10.02 | N/A

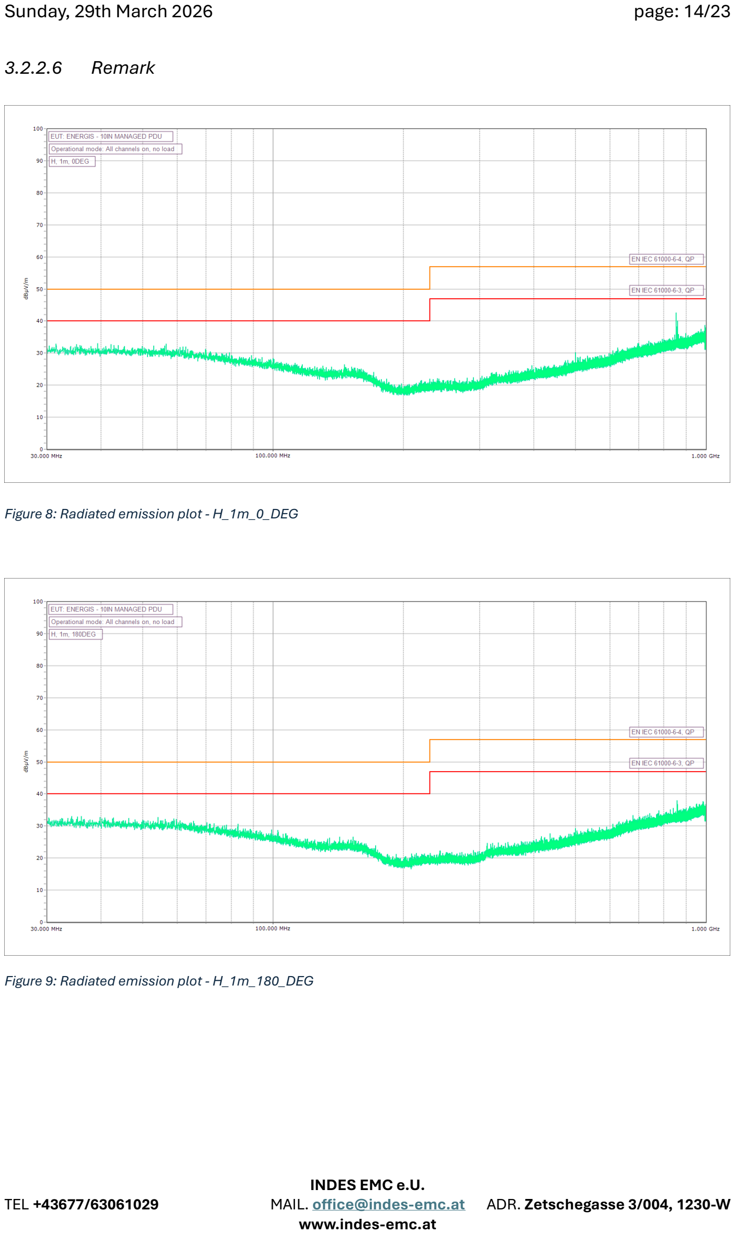
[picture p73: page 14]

3.2.2.6 Remark

Figure 8: Radiated emission plot - H_1m_0_DEG

Figure 9: Radiated emission plot - H_1m_180_DEG

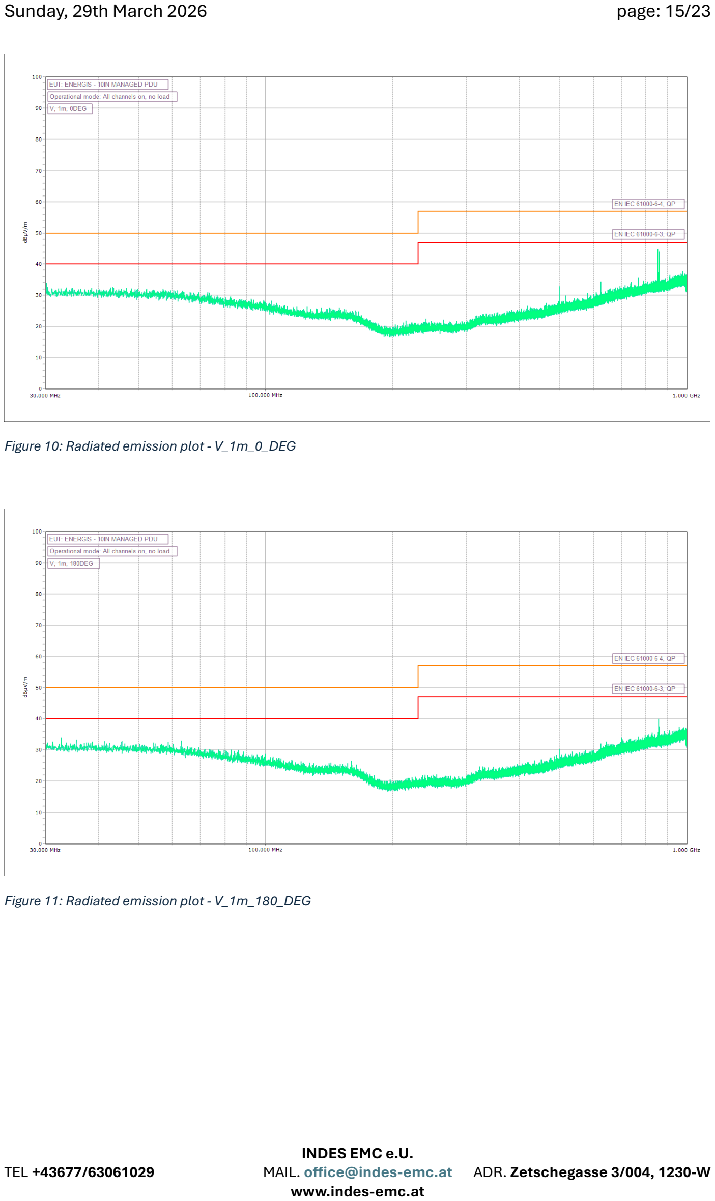
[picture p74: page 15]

Figure 10: Radiated emission plot - V_1m_0_DEG

Figure 11: Radiated emission plot - V_1m_180_DEG

## 4. Test conditions

## 4.1 Environmental conditions

The tests were carried out under the following climatic conditions: Temeprature: 23° +/-3°
Relative humidity: 27% +/-5%
Athmospheric pressure: 1013.6 hPa

## 4.2 Auxilliary Test Equipment configuration

Monitoring and Test host device: N/A

## 4.3 Auxilliary Test Software and stimulus configuration

Test software: N/A
Test software version: N/A

## 4.4 EUT Firmware version and application code revision

EUT FW identification: N/A
EUT FW revision: N/A
EUT app identification: N/A EUT app revision: N/A

## 5.References

[1] EMC Directive 2014/30/EU
Directive of the European Parliament and of the Council on the harmonisation of the laws of the Member States relating to electromagnetic compatibility.
[2] Commission Notice on the Application of the EMC Directive 2014/30/EU
Official guidance document outlining manufacturer obligations, conformity assessment, and technical documentation requirements.
[3] IEC 61000-6-3
Electromagnetic compatibility (EMC) – Part 6-3: Generic standards – Emission standard for residential, commercial and light-industrial environments

## 6. Tables and pictures

Table 1: Test Plan for the EUT | 9
Table 2: Test Result overview for the EUT | 10
Figure 1: ENERGIS 10IN MANAGED PDU | 6
Figure 2: Conducted Emission Setup 150kHz – 30MHz | 7
Figure 3: Radiated Emission setup 30MHz - 1000MHz | 7
Figure 4: Extract IEC 61000-6-3, Table 1 | 8
Figure 5: Extract IEC 61000-6-3, Table (continued) | 8
Figure 6: Conducted emissions L-PE | 12
Figure 7: Conducted emissions N-PE | 12
Figure 8: Radiated emission plot - H_1m_0_DEG | 14
Figure 9: Radiated emission plot - H_1m_180_DEG | 14
Figure 10: Radiated emission plot - V_1m_0_DEG | 15
Figure 11: Radiated emission plot - V_1m_180_DEG | 15


ANNEX I – Foto Documentation


## ANNEX II – EMC Chamber statement

EMC Directive 2014/30/EU – Annex II Self-Assessment Justification Company: INDES EMC e.U.
Address: Zetschegasse 3, 1230 Vienna, Austria
Owner/CEO: Ing. Aleksandar Sindrak

Test Environment Description
Radiated emission measurements were conducted in a shielded enclosure constructed from grounded aluminum panels and conductive fabric layers. The enclosure includes RF absorbers (such as graphene loaded foam), yet without deploying ferrite tiles, resulting in a highly reflective internal environment for frequencies below 200MHz. Impact on Measurement Conditions
The absence of ferrite absorbers increases internal reflections, which can lead to constructive interference and standing waves. This effect typically elevates the measured radiated emission levels compared to a standard absorber-lined chamber. Therefore, the test environment represents a conservative condition, as emissions are more likely to appear higher than in a compliant chamber.
Rationale for Compliance Assessment
Since the device under test (DUT) meets the applicable radiated emission limits under these worst-case reflective conditions, it is reasonable to conclude that the DUT would also comply in a standard EMC chamber equipped with ferrite tile absorbers, where reflections and resonances are significantly reduced.
Conclusion
Testing in a highly reflective environment without absorbers provides a stringent assessment. Passing under these conditions demonstrates compliance with the EMC Directive requirements and ensures that performance in a fully equipped chamber would not exceed the specified limits.

## ANNEX III – Legal Disclaimer for EMC verification support

Disclaimer:
The services provided by INDES EMC e.U. in relation to Electromagnetic Compatibility (EMC) are limited to technical verification, testing assistance, documentation support, and general guidance intended to help manufacturers fulfill their obligations under the EMC Directive 2014/30/EU. These services are not a substitute for a manufacturer’s own legal responsibilities.
Under EMC Directive 2014/30/EU, manufacturers may perform a self-assessment procedure to demonstrate conformity, provided they compile technical documentation and ensure their equipment meets the essential protection requirements defined in Annex I. The directive allows manufacturers to use external test laboratories, consultants, or technical experts to carry out measurements, verifications, or analysis in support of this process. However, the manufacturer retains full legal responsibility for ensuring conformity, preparing the technical file, issuing the EU Declaration of Conformity, and affixing the CE marking.
Accordingly, INDES EMC e.U. provides support that is strictly technical and advisory in nature. All verification activities, measurement data, or technical opinions supplied by INDES EMC e.U. are intended solely to assist the manufacturer in performing their own conformity assessment under the applicable modules of the EMC Directive. No service provided constitutes certification, approval, or a legally binding conformity assessment decision. INDES EMC e.U. does not assume or accept any responsibility for final compliance of the product, nor for any decisions taken by the manufacturer regarding CE marking, declarations, or market placement.
Manufacturers using these services acknowledge that they remain solely responsible for:
- Ensuring overall conformity of their equipment with EMC Directive 2014/30/EU;
- Completing and maintaining the technical documentation as specified in Annex II;
- Determining the appropriateness of any test results or verification data; and
- Issuing the EU Declaration of Conformity.
By engaging INDES EMC e.U. , the manufacturer agrees that any information, recommendations, or support provided are advisory and that ultimate compliance decisions rest exclusively with the manufacturer.

## END OF REPORT

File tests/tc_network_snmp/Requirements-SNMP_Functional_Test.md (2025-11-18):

# ENERGIS SNMP Functional Test

## Purpose
To verify the correct operation of ENERGIS device SNMP commands, including system info,  
network configuration and output control ensuring all features work as  
expected and persist across reboots.

## Summary
This test suite connects to the ENERGIS device via 100 Base ethernet  
and executes a sequence of commands to validate help output, system information, network  
settings (with reboot and verification) and relay output control.  
It checks device responses against a pass-file for correctness and expected behavior.

## Notes
1. Each steps that requires reset by the software shall have 15 secods timeout. The DUT  
   shall open its ports inside the timeout period. The test script shall reconnect to  
   the DUT through serial port and wait for the SYSTEM READY string to continue the tests.
2. Each test step must connect to the serial port within the timeout, and after the test  
   is done, disconnect is needed.

## Test Steps
1. Test Walk the enterprise subtree by calling  
   `snmpwalk -v1 -c public -Ci -Cc 192.168.0.11 1.3.6.1.4.1.19865`
2. Test MIB-II “system” group and verify that the substeps from Step 1 are available  
   individually, by sening  
   2.1 `snmpget -v1 -c public 192.168.0.11 1.3.6.1.2.1.1.1.0`  
   2.2 `snmpget -v1 -c public 192.168.0.11 1.3.6.1.2.1.1.2.0`  
   2.3 `snmpget -v1 -c public 192.168.0.11 1.3.6.0.2.1.1.3.0`  
   2.4 `snmpget -v1 -c public 192.168.0.11 1.3.6.1.2.1.1.4.0`  
   2.5 `snmpget -v1 -c public 192.168.0.11 1.3.6.1.2.1.1.5.0`  
   2.6 `snmpget -v1 -c public 192.168.0.11 1.3.6.1.2.1.1.6.0`  
   2.7 `snmpget -v1 -c public 192.168.0.11 1.3.6.1.2.1.1.7.0`
3. Verify the “Long-length” test entries by sending  
   3.1 `snmpget -v1 -c public 192.168.0.11 1.3.6.1.4.1.19865.1.0`  
   3.2 `snmpget -v1 -c public 192.168.0.11 1.3.6.1.4.1.19865.2.0`
4. Verify network configuration by sending  
   4.1 `snmpget -v1 -c public 192.168.0.11 1.3.6.1.4.1.19865.4.1.0`  
   4.2 `snmpget -v1 -c public 192.168.0.11 1.3.6.1.4.1.19865.4.2.0`  
   4.3 `snmpget -v1 -c public 192.168.0.11 1.3.6.1.4.1.19865.4.3.0`  
   4.4 `snmpget -v1 -c public 192.168.0.11 1.3.6.1.4.1.19865.4.4.0`
5. Verify each and every output (N) by:  
   5.1 Checking the status of channel 1 by `snmpget -v1 -c public 192.168.0.11 1.3.6.1.4.1.19865.2.1.0`  
   5.2 Turning on channel 1 by `snmpset -v1 -c public 192.168.0.11 1.3.6.1.4.1.19865.2.1.0 i 1`  
       Verify the status through serial communication by calling `GET_CH 1`  
   5.3 Turning off the channel 1 by `snmpset -v1 -c public 192.168.0.11 1.3.6.1.4.1.19865.2.1.0 i 0`  
       Verify the status through serial communication by calling `GET_CH 1`  
   5.4 Checking the status of channel 2 by `snmpget -v1 -c public 192.168.0.11 1.3.6.1.4.1.19865.2.2.0`  
   5.5 Turning on channel 2 by `snmpset -v1 -c public 192.168.0.11 1.3.6.1.4.1.19865.2.2.0 i 1`  
       Verify the status through serial communication by calling `GET_CH 2`  
   5.6 Turning off the channel 2 by `snmpset -v1 -c public 192.168.0.11 1.3.6.1.4.1.19865.2.2.0 i 0`  
       Verify the status through serial communication by calling `GET_CH 2`  
   5.7 Checking the status of channel 3 by `snmpget -v1 -c public 192.168.0.11 1.3.6.1.4.1.19865.2.3.0`  
   5.8 Turning on channel 3 by `snmpset -v1 -c public 192.168.0.11 1.3.6.1.4.1.19865.2.3.0 i 1`  
       Verify the status through serial communication by calling `GET_CH 3`  
   5.9 Turning off the channel 3 by `snmpset -v1 -c public 192.168.0.11 1.3.6.1.4.1.19865.2.3.0 i 0`  
       Verify the status through serial communication by calling `GET_CH 3`  
   5.10 Checking the status of channel 4 by `snmpget -v1 -c public 192.168.0.11 1.3.6.1.4.1.19865.2.4.0`  
   5.11 Turning on channel 4 by `snmpset -v1 -c public 192.168.0.11 1.3.6.1.4.1.19865.2.4.0 i 1`  
       Verify the status through serial communication by calling `GET_CH 4`  
   5.12 Turning off the channel 4 by `snmpset -v1 -c public 192.168.0.11 1.3.6.1.4.1.19865.2.4.0 i 0`  
       Verify the status through serial communication by calling `GET_CH 4`  
   5.13 Checking the status of channel 5 by `snmpget -v1 -c public 192.168.0.11 1.3.6.1.4.1.19865.2.5.0`  
   5.14 Turning on channel 5 by `snmpset -v1 -c public 192.168.0.11 1.3.6.1.4.1.19865.2.5.0 i 1`  
       Verify the status through serial communication by calling `GET_CH 5`  
   5.15 Turning off the channel 5 by `snmpset -v1 -c public 192.168.0.11 1.3.6.1.4.1.19865.2.5.0 i 0`  
       Verify the status through serial communication by calling `GET_CH 5`  
   5.16 Checking the status of channel 6 by `snmpget -v1 -c public 192.168.0.11 1.3.6.1.4.1.19865.2.6.0`  
   5.17 Turning on channel 6 by `snmpset -v1 -c public 192.168.0.11 1.3.6.1.4.1.19865.2.6.0 i 1`  
       Verify the status through serial communication by calling `GET_CH 6`  
   5.18 Turning off the channel 6 by `snmpset -v1 -c public 192.168.0.11 1.3.6.1.4.1.19865.2.6.0 i 0`  
       Verify the status through serial communication by calling `GET_CH 6`  
   5.19 Checking the status of channel 7 by `snmpget -v1 -c public 192.168.0.11 1.3.6.1.4.1.19865.2.7.0`  
   5.20 Turning on channel 7 by `snmpset -v1 -c public 192.168.0.11 1.3.6.1.4.1.19865.2.7.0 i 1`  
       Verify the status through serial communication by calling `GET_CH 7`  
   5.21 Turning off the channel 7 by `snmpset -v1 -c public 192.168.0.11 1.3.6.1.4.1.19865.2.7.0 i 0`  
       Verify the status through serial communication by calling `GET_CH 7`  
   5.22 Checking the status of channel 8 by `snmpget -v1 -c public 192.168.0.11 1.3.6.1.4.1.19865.2.8.0`  
   5.23 Turning on channel 8 by `snmpset -v1 -c public 192.168.0.11 1.3.6.1.4.1.19865.2.8.0 i 1`  
       Verify the status through serial communication by calling `GET_CH 8`  
   5.24 Turning off the channel 8 by `snmpset -v1 -c public 192.168.0.11 1.3.6.1.4.1.19865.2.8.0 i 0`  
       Verify the status through serial communication by calling `GET_CH 8`  
   5.25 Turning on ALL channels by `snmpset -v1 -c public 192.168.0.11 1.3.6.1.4.1.19865.2.10.0 i 1`  
       Verify the ON status through serial communication by loop reading `GET_CH x`  
   5.26 Turning off ALL channels by `snmpset -v1 -c public 192.168.0.11 1.3.6.1.4.1.19865.2.9.0 i 1`  
       Verify the OFF status through serial communication by loop reading `GET_CH x`

## Expected Results
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

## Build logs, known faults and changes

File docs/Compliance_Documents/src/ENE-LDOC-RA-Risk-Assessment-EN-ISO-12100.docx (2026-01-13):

ENERGIS 10IN Managed PDU

Risk Assessment (EN ISO 12100)

Author David Sipos

Document number: ENE-LDOC-RA

Document name: ENE-LDOC-RA-Risk-Assessment-EN-ISO-12100

Revision: 1.0.0

Status: Released

Date: 13.12.2025

Document status: Internal - CE Technical File

Revision History

A revision is a new edition of the document and affects all sections of this document.

Version | Date | Responsible | Modification
1.0.0 | 12.12.2025 | David Sipos | Initial creation of the document

# 1. Introduction and Scope

This document provides the risk assessment for the ENERGIS 10IN Managed PDU, Hardware Revision 1.1.0. The scope of this assessment is limited to hazards arising from the intended use, reasonably foreseeable misuse, and normal operation of the product as described in the accompanying documentation. This risk assessment is performed to support conformity with applicable EU directives and does not claim compliance with functional safety standards.

# 2. Applicable Documents

The following documents are applicable to this risk assessment and define requirements or constraints for the ENERGIS product.

ID | Document Identifier | Title | Version
LDOC-001 | ENE-LDOC-DOC | EU Declaration of Conformity | 1.0.0
LDOC-002 | ENE-LDOC-RA | Risk Assessment (EN ISO 12100) | 1.0.0
UDOC-001 | ENE-UDOC-UM | User Manual ENERGIS 10IN Managed PDU | 1.0.0

# 3. Reference Documents

The following documents were used as reference material during the preparation of this risk assessment.

ID | Document Identifier | Title | Version
TDOC-001 | ENE-TDOC-Schematics | Electrical schematics - HW Rev 1.1.0 | 1.1.0
TDOC-004 | ENE-TDOC-EMTR | EMC & Emission Test Report | 1.0.0
TDOC-005 | ENE-TDOC-RHSC | RoHS Compliance Evidence (PCB & BOM based) | 1.0.0

# 4. Product Description

ENERGIS 10IN Managed PDUis a rack-mounted, microcontroller-controlled AC power distribution unit. It provides eight independently switchable AC output channels with integrated voltage, current, power, and energy monitoring.

The device is controlled via:

- Front-panel buttons
- Ethernet (HTTP API, SNMP)
- USB serial console

The product operates from 230 V AC mains power and is intended for fixed indoor installation.

# 5. Intended Use

- Distribution, switching, and monitoring of AC mains power
- Installation in technical racks, laboratories, and test environments
- Operation by technically competent persons

# 6. Reasonably Foreseeable Misuse

- Operation outdoors or in damp environments
- Exceeding rated current or voltage limits
- Removal of protective earth
- Opening the enclosure while connected to mains
- Use by untrained or unauthorized persons

# 7. Hazard Identification and Risk Reduction

## 7.1 Electrical Shock Hazard

Hazard: Contact with hazardous mains voltage.

Initial risk level: High

Risk reduction measures:

- Fully enclosed conductive metal housing
- Protective earth connection bonded to enclosure
- Insulated internal wiring and creepage distances compliant with EN 62368-1
- No accessible live parts during normal operation
- Mechanical fixation requiring tools for enclosure access
- Warning information in documentation

Residual risk: Low

## 7.2 Overcurrent and Fire Hazard

Hazard: Excessive current draw leading to overheating or fire.

Initial risk level: High

Risk reduction measures:

- Firmware-enforced global current limit
- Per-channel current measurement
- Automatic relay shutdown in overcurrent conditions
- Visual fault indication on the front panel
- Default-safe state on reset or fault

Residual risk: Medium (dependent on connected external loads)

## 7.3 Thermal Hazard

Hazard: Elevated surface or internal temperatures during sustained high load.

Initial risk level: Medium

Risk reduction measures:

- Internal temperature monitoring
- Power dissipation within component ratings
- Passive heat dissipation via enclosure
- Defined operating temperature limits in documentation

Residual risk: Low

## 7.4 Mechanical Hazard

Hazard: Injury from sharp edges or mechanical failure during installation.

Initial risk level: Low

Risk reduction measures:

- Deburred enclosure edges
- No moving mechanical parts
- Rack-mount installation with standard fasteners

Residual risk: Low

## 7.5 Electromagnetic Disturbance

Hazard: Emission or susceptibility causing malfunction of nearby equipment.

Initial risk level: Medium

Risk reduction measures:

- Shielded metal enclosure
- Filtered mains input
- EMC-conscious PCB layout
- Compliance testing according to EN 55032 and EN 55035

Residual risk: Low (final verification pending completion of EMC testing)

## 7.6 Software and Control Failure

Hazard: Unexpected switching behavior due to firmware malfunction.

Initial risk level: Medium

Risk reduction measures:

- Deterministic firmware architecture
- Watchdog supervision
- Defined startup and reset states
- Manual local control available

Residual risk: Low. Software functions contribute to risk reduction but are not the sole means of ensuring electrical safety.

# 8. Information for Use

- Installation, operation, and safety instructions are provided in the User Manual
- Electrical ratings and limitations are clearly documented
- Warning against enclosure opening is stated

# 9. Residual Risks

All residual risks are considered acceptable when the device is used according to its intended purpose and documentation.

# 10. Overall Conclusion

Based on the performed risk analysis, the ENERGIS 10IN Managed PDU does not present unacceptable risks. All identified hazards have been reduced to an acceptable level through design measures, protective features, and user information.

TTTECH - Internal

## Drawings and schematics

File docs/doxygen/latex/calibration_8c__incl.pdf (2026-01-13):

src/Software/ENERGIS
_RTOS/src/tasks/storage
_submodule/calibration.c

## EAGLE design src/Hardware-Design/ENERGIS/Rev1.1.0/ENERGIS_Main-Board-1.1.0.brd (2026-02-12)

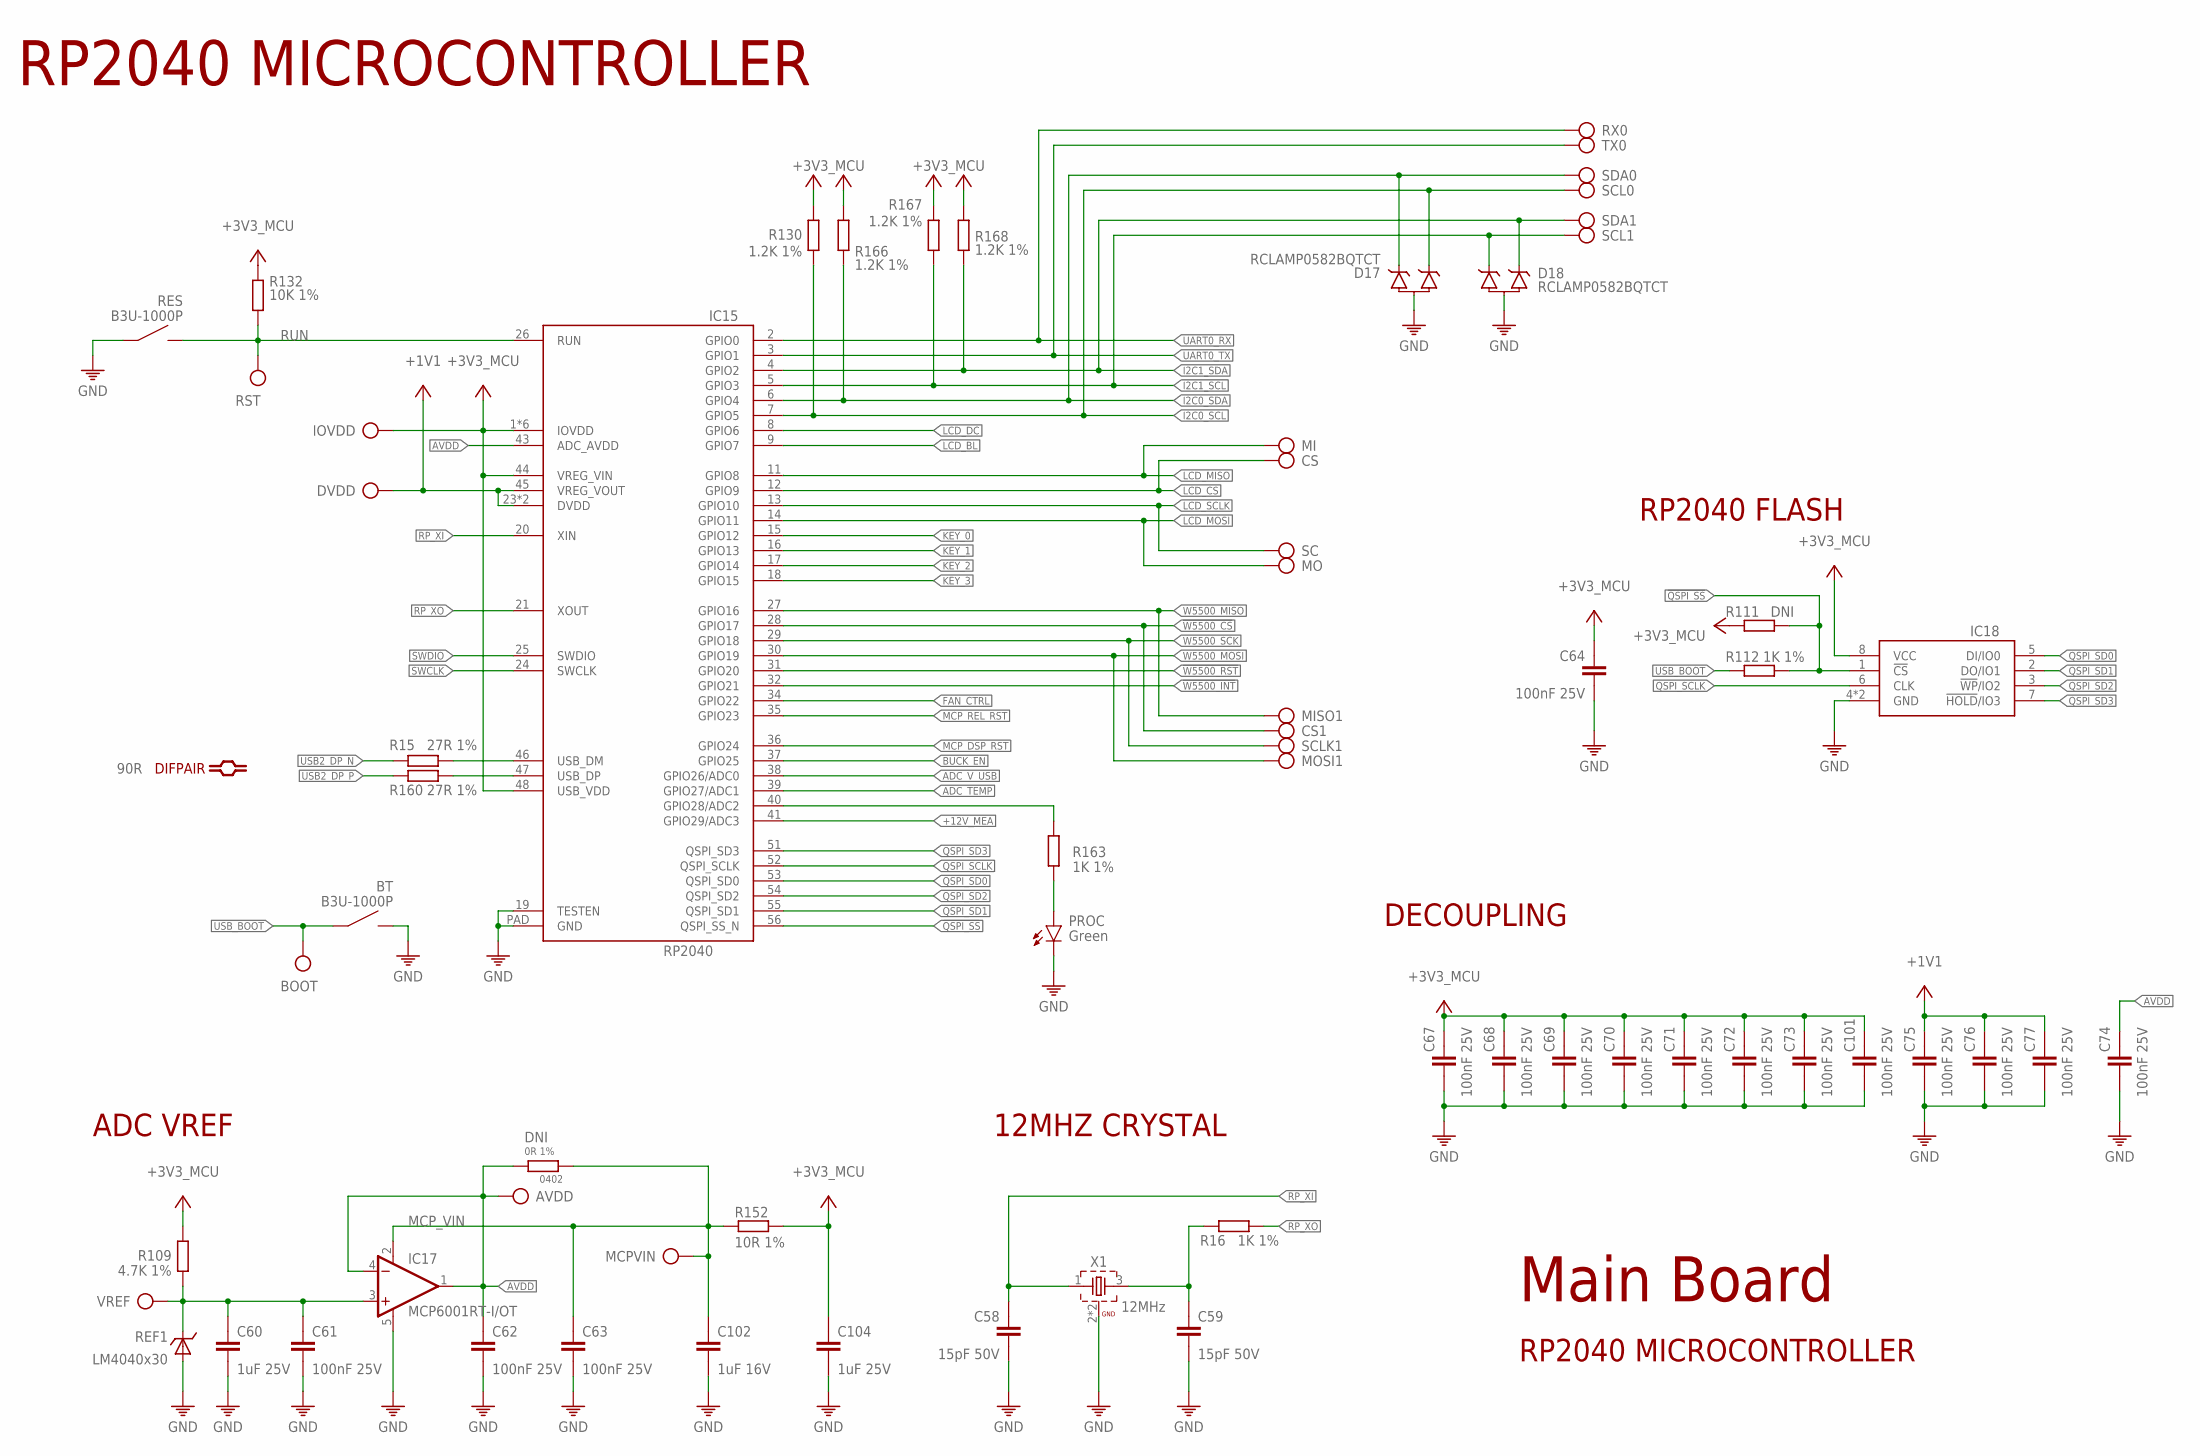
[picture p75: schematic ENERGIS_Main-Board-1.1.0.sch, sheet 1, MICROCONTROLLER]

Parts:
AVDD: DNI; TP-ROUND
BOOT: DNI; TP-ROUND
BT: B3U-1000P
C58, C59: 15pF 50V; 0201
C60, C104: 1uF 25V; 0402
C61, C62, C63, C64, C67, C68, C69, C70, C71, C72, C73, C74, C75, C76, C77, C101: 100nF 25V; 0201
C102: 1uF 16V; 0201
CS, CS1: DNI; TP-ROUND
D17, D18: RCLAMP0582BQTCT; SC75
DNI: 0R 1%; 0402
DVDD: DNI; TP-ROUND
IC15: RP2040; QFN56
IC17: MCP6001RT-I/OT; SOT23-5
IC18: W25Q128JVPIQ; SON127P600X500X75-8N
IOVDD: DNI; TP-ROUND
MCPVIN: DNI; TP-ROUND
MI: DNI; TP-ROUND
MISO1: DNI; TP-ROUND
MO: DNI; TP-ROUND
MOSI1: DNI; TP-ROUND
PROC: Green; LED-0603
R15, R160: 27R 1%; 0201
R16: 1K 1%; 0201
R109: 4.7K 1%; 0201
R111: DNI; R0201
R112, R163: 1K 1%; 0402
R130, R166, R167, R168: 1.2K 1%; 0402
R132: 10K 1%; 0402
R152: 10R 1%; 0201
REF1: LM4040x30; SOT23
RES: B3U-1000P
RST: DNI; TP-ROUND
RX0: DNI; TP-ROUND
SC: DNI; TP-ROUND
SCL0, SCL1: DNI; TP-ROUND
SCLK1: DNI; TP-ROUND
SDA0, SDA1: DNI; TP-ROUND
TX0: DNI; TP-ROUND
VREF: DNI; TP-ROUND
X1: 12MHz; WE-XTAL_CFPX-180

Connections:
!QSPI_SS: IC15.56 (QSPI_SS_N), IC18.1 (!CS), R111.1, R112.2
!W5500_CS: CS1.TP, IC15.28 (GPIO17); also elsewhere on the board
!W5500_INT: IC15.32 (GPIO21); also elsewhere on the board
!W5500_RST: IC15.31 (GPIO20); also elsewhere on the board
+1V1: C75.1, C76.1, C77.1, DVDD.TP, IC15.23 (DVDD), IC15.45 (VREG_VOUT), IC15.50 (DVDD)
+3V3_MCU: C64.1, C67.1, C68.1, C69.1, C70.1, C71.1, C72.1, C73.1, C101.1, C104.1, IC15.1 (IOVDD), IC15.10 (IOVDD), IC15.22 (IOVDD), IC15.33 (IOVDD), IC15.42 (IOVDD), IC15.44 (VREG_VIN), IC15.48 (USB_VDD), IC15.49 (IOVDD), IC18.8 (VCC), IOVDD.TP, R109.2, R111.2, R130.1, R132.1, R152.1, R166.1, R167.1, R168.1; also elsewhere on the board
+12V_MEA: IC15.41 (GPIO29/ADC3); also elsewhere on the board
ADC_TEMP: IC15.39 (GPIO27/ADC1); also elsewhere on the board
ADC_V_USB: IC15.38 (GPIO26/ADC0); also elsewhere on the board
AVDD: AVDD.TP, C62.1, C74.1, DNI.1, IC15.43 (ADC_AVDD), IC17.1 (OUT), IC17.4 (-IN)
BUCK_EN: IC15.37 (GPIO25); also elsewhere on the board
FAN_CTRL: IC15.34 (GPIO22); also elsewhere on the board
GND: BT.2, C58.2, C59.2, C60.2, C61.2, C62.2, C63.2, C64.2, C67.2, C68.2, C69.2, C70.2, C71.2, C72.2, C73.2, C74.2, C75.2, C76.2, C77.2, C101.2, C102.2, C104.2, D17.3, D18.3, IC15.19 (TESTEN), IC15.PAD (GND), IC17.5 (V-), IC18.4 (GND), IC18.PAD (GND), PROC.C, REF1.2 (A), REF1.3 (A), RES.1, X1.2 (GND), X1.4 (GND); also elsewhere on the board
I2C0_SCL: D17.1, IC15.7 (GPIO5), R130.2, SCL0.TP; also elsewhere on the board
I2C0_SDA: D17.2, IC15.6 (GPIO4), R166.2, SDA0.TP; also elsewhere on the board
I2C1_SCL: D18.2, IC15.5 (GPIO3), R167.2, SCL1.TP; also elsewhere on the board
I2C1_SDA: D18.1, IC15.4 (GPIO2), R168.2, SDA1.TP; also elsewhere on the board
KEY_0: IC15.15 (GPIO12); also elsewhere on the board
KEY_1: IC15.16 (GPIO13); also elsewhere on the board
KEY_2: IC15.17 (GPIO14); also elsewhere on the board
KEY_3: IC15.18 (GPIO15); also elsewhere on the board
LCD_BL: IC15.9 (GPIO7); also elsewhere on the board
LCD_CS: CS.TP, IC15.12 (GPIO9); also elsewhere on the board
LCD_DC: IC15.8 (GPIO6); also elsewhere on the board
LCD_MISO: IC15.11 (GPIO8), MI.TP; also elsewhere on the board
LCD_MOSI: IC15.14 (GPIO11), MO.TP; also elsewhere on the board
LCD_SCLK: IC15.13 (GPIO10), SC.TP; also elsewhere on the board
MCP_DSP_RST: IC15.36 (GPIO24); also elsewhere on the board
MCP_REL_RST: IC15.35 (GPIO23); also elsewhere on the board
MCP_VIN: C63.1, C102.1, DNI.2, IC17.2 (V+), MCPVIN.TP, R152.2
unnamed: IC15.40 (GPIO28/ADC2), R163.2
unnamed: PROC.A, R163.1
unnamed: C59.1, R16.1, X1.3 (2)
QSPI_SCLK: IC15.52 (QSPI_SCLK), IC18.6 (CLK)
QSPI_SD0: IC15.53 (QSPI_SD0), IC18.5 (DI/IO0)
QSPI_SD1: IC15.55 (QSPI_SD1), IC18.2 (DO/IO1)
QSPI_SD2: IC15.54 (QSPI_SD2), IC18.3 (!WP!/IO2)
QSPI_SD3: IC15.51 (QSPI_SD3), IC18.7 (!HOLD!/IO3)
RP_DP_N: IC15.46 (USB_DM), R15.2
RP_DP_P: IC15.47 (USB_DP), R160.2
RP_XI: C58.1, IC15.20 (XIN), X1.1
RP_XO: IC15.21 (XOUT), R16.2
RUN: IC15.26 (RUN), R132.2, RES.2, RST.TP; also elsewhere on the board
SWCLK: IC15.24 (SWCLK); also elsewhere on the board
SWDIO: IC15.25 (SWDIO); also elsewhere on the board
UART0_RX: IC15.2 (GPIO0), RX0.TP; also elsewhere on the board
UART0_TX: IC15.3 (GPIO1), TX0.TP; also elsewhere on the board
USB2_DP_N: R15.1; also elsewhere on the board
USB2_DP_P: R160.1; also elsewhere on the board
USB_BOOT: BOOT.TP, BT.1, R112.1
VREF: C60.1, C61.1, IC17.3 (+IN), R109.1, REF1.1 (C), VREF.TP
W5500_MISO: IC15.27 (GPIO16), MISO1.TP; also elsewhere on the board
W5500_MOSI: IC15.30 (GPIO19), MOSI1.TP; also elsewhere on the board
W5500_SCK: IC15.29 (GPIO18), SCLK1.TP; also elsewhere on the board

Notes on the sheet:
DECOUPLING
RP2040 MICROCONTROLLER
Main Board
RP2040 FLASH
12MHZ CRYSTAL
ADC VREF

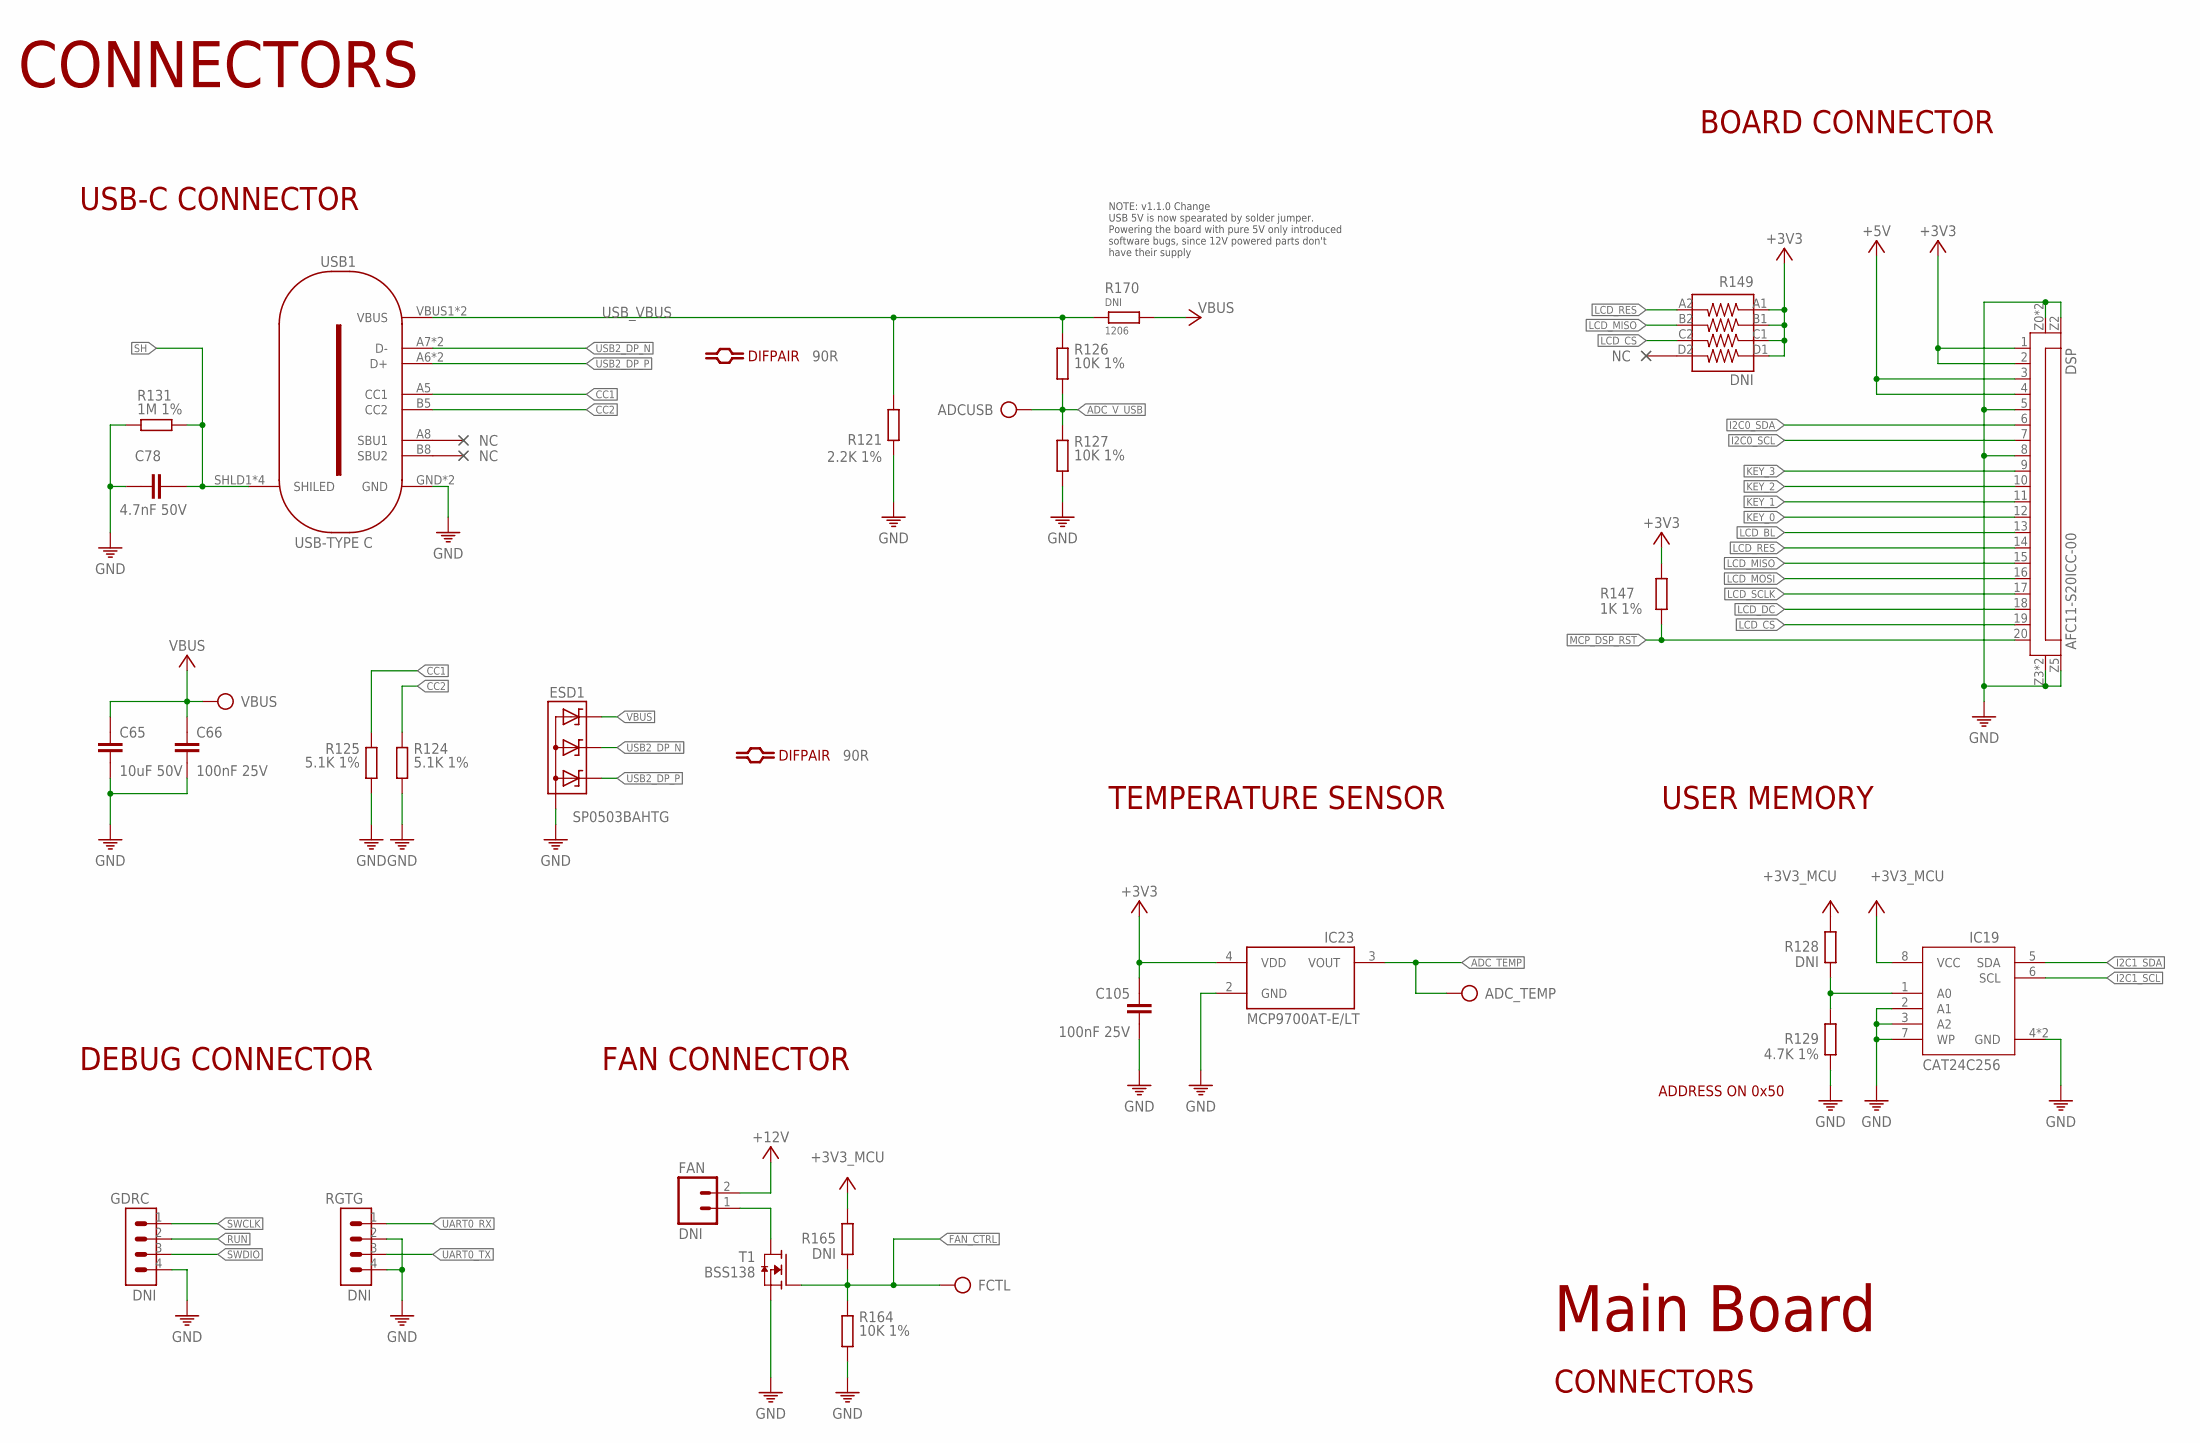
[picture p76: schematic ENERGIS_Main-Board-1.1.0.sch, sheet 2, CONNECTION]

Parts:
ADCUSB: DNI; TP-ROUND
ADC_TEMP: DNI; TP-ROUND
C65: 10uF 50V; 0805
C66: 100nF 25V; 0402
C78: 4.7nF 50V; 0402
C105: 100nF 25V; 0201
DSP: AFC11-S20ICC-00; FPC20
ESD1: SP0503BAHTG; SOT143
FAN: DNI; 02P
FCTL: DNI; TP-ROUND
GDRC: DNI; 1X4
IC19: CAT24C256HU4IGT3; SON50P300X200X50-9T130X140N
IC23: MCP9700AT-E/LT; SC70-5
R121: 2.2K 1%; 0201
R124, R125: 5.1K 1%; 0201
R126, R127: 10K 1%; 0201
R128, R165: DNI; R0201
R129: 4.7K 1%; 0201
R131: 1M 1%; 0402
R147: 1K 1%; 0402
R149: DNI; _0603X4-1206
R164: 10K 1%; 0402
R170: DNI; 1206
RGTG: DNI; 1X4
T1: BSS138; SOT23
USB1: USB-TYPE-C-018; USB-C
VBUS: DNI; TP-ROUND

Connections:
+3V3: C105.1, DSP.1, DSP.2, IC23.4 (VDD), R147.2, R149.A1 (1), R149.B1 (2), R149.C1 (3), R149.D1 (4); also elsewhere on the board
+3V3_MCU: IC19.8 (VCC), R128.2, R165.2; also elsewhere on the board
+5V: DSP.3, DSP.4; also elsewhere on the board
+12V: FAN.2; also elsewhere on the board
ADC_TEMP: ADC_TEMP.TP, IC23.3 (VOUT); also elsewhere on the board
ADC_V_USB: ADCUSB.TP, R126.2, R127.1; also elsewhere on the board
CC1: R125.1, USB1.A5 (CC1)
CC2: R124.1, USB1.B5 (CC2)
FAN_CTRL: FCTL.TP, R164.1, R165.1, T1.1 (G); also elsewhere on the board
GND: C65.2, C66.2, C78.2, C105.2, DSP.5, DSP.8, DSP.Z0 (Z1), DSP.Z1, DSP.Z2, DSP.Z3, DSP.Z4 (Z3), DSP.Z5 (Z4), ESD1.1 (A), GDRC.4, IC19.2 (A1), IC19.3 (A2), IC19.4 (GND), IC19.7 (WP), IC19.9 (GND), IC23.2 (GND), R121.2, R124.2, R125.2, R127.2, R129.1, R131.2, R164.2, RGTG.2, RGTG.4, T1.2 (S), USB1.GND, USB1.GND2 (GND); also elsewhere on the board
I2C0_SCL: DSP.7; also elsewhere on the board
I2C0_SDA: DSP.6; also elsewhere on the board
I2C1_SCL: IC19.6 (SCL); also elsewhere on the board
I2C1_SDA: IC19.5 (SDA); also elsewhere on the board
KEY_0: DSP.12; also elsewhere on the board
KEY_1: DSP.11; also elsewhere on the board
KEY_2: DSP.10; also elsewhere on the board
KEY_3: DSP.9; also elsewhere on the board
LCD_BL: DSP.13; also elsewhere on the board
LCD_CS: DSP.19, R149.C2 (6); also elsewhere on the board
LCD_DC: DSP.18; also elsewhere on the board
LCD_MISO: DSP.15, R149.B2 (7); also elsewhere on the board
LCD_MOSI: DSP.16; also elsewhere on the board
LCD_RES: DSP.14, R149.A2 (8)
LCD_SCLK: DSP.17; also elsewhere on the board
MCP_DSP_RST: DSP.20, R147.1; also elsewhere on the board
unnamed: FAN.1, T1.3 (D)
unnamed: IC19.1 (A0), R128.1, R129.2
RUN: GDRC.2; also elsewhere on the board
SH: C78.1, R131.1, USB1.SHLD1 (SHILED), USB1.SHLD2 (SHILED), USB1.SHLD3 (SHILED), USB1.SHLD4 (SHILED); also elsewhere on the board
SWCLK: GDRC.1; also elsewhere on the board
SWDIO: GDRC.3; also elsewhere on the board
UART0_RX: RGTG.1; also elsewhere on the board
UART0_TX: RGTG.3; also elsewhere on the board
USB2_DP_N: ESD1.3 (C2), USB1.A7 (D-), USB1.B7 (D-); also elsewhere on the board
USB2_DP_P: ESD1.2 (C1), USB1.A6 (D+), USB1.B6 (D+); also elsewhere on the board
USB_VBUS: R121.1, R126.1, R170.1, USB1.VBUS1 (VBUS), USB1.VBUS2 (VBUS)
VBUS: C65.1, C66.1, ESD1.4 (C3), R170.2, VBUS.TP; also elsewhere on the board

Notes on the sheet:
USB-C CONNECTOR
BOARD CONNECTOR
DEBUG CONNECTOR
FAN CONNECTOR
CONNECTORS
Main Board
NOTE: v1.1.0 Change USB 5V is now spearated by solder jumper. Powering the board with pure 5V only introduced software bugs, since 12V powered parts don't have their supply
USER MEMORY
TEMPERATURE SENSOR
ADDRESS ON 0x50

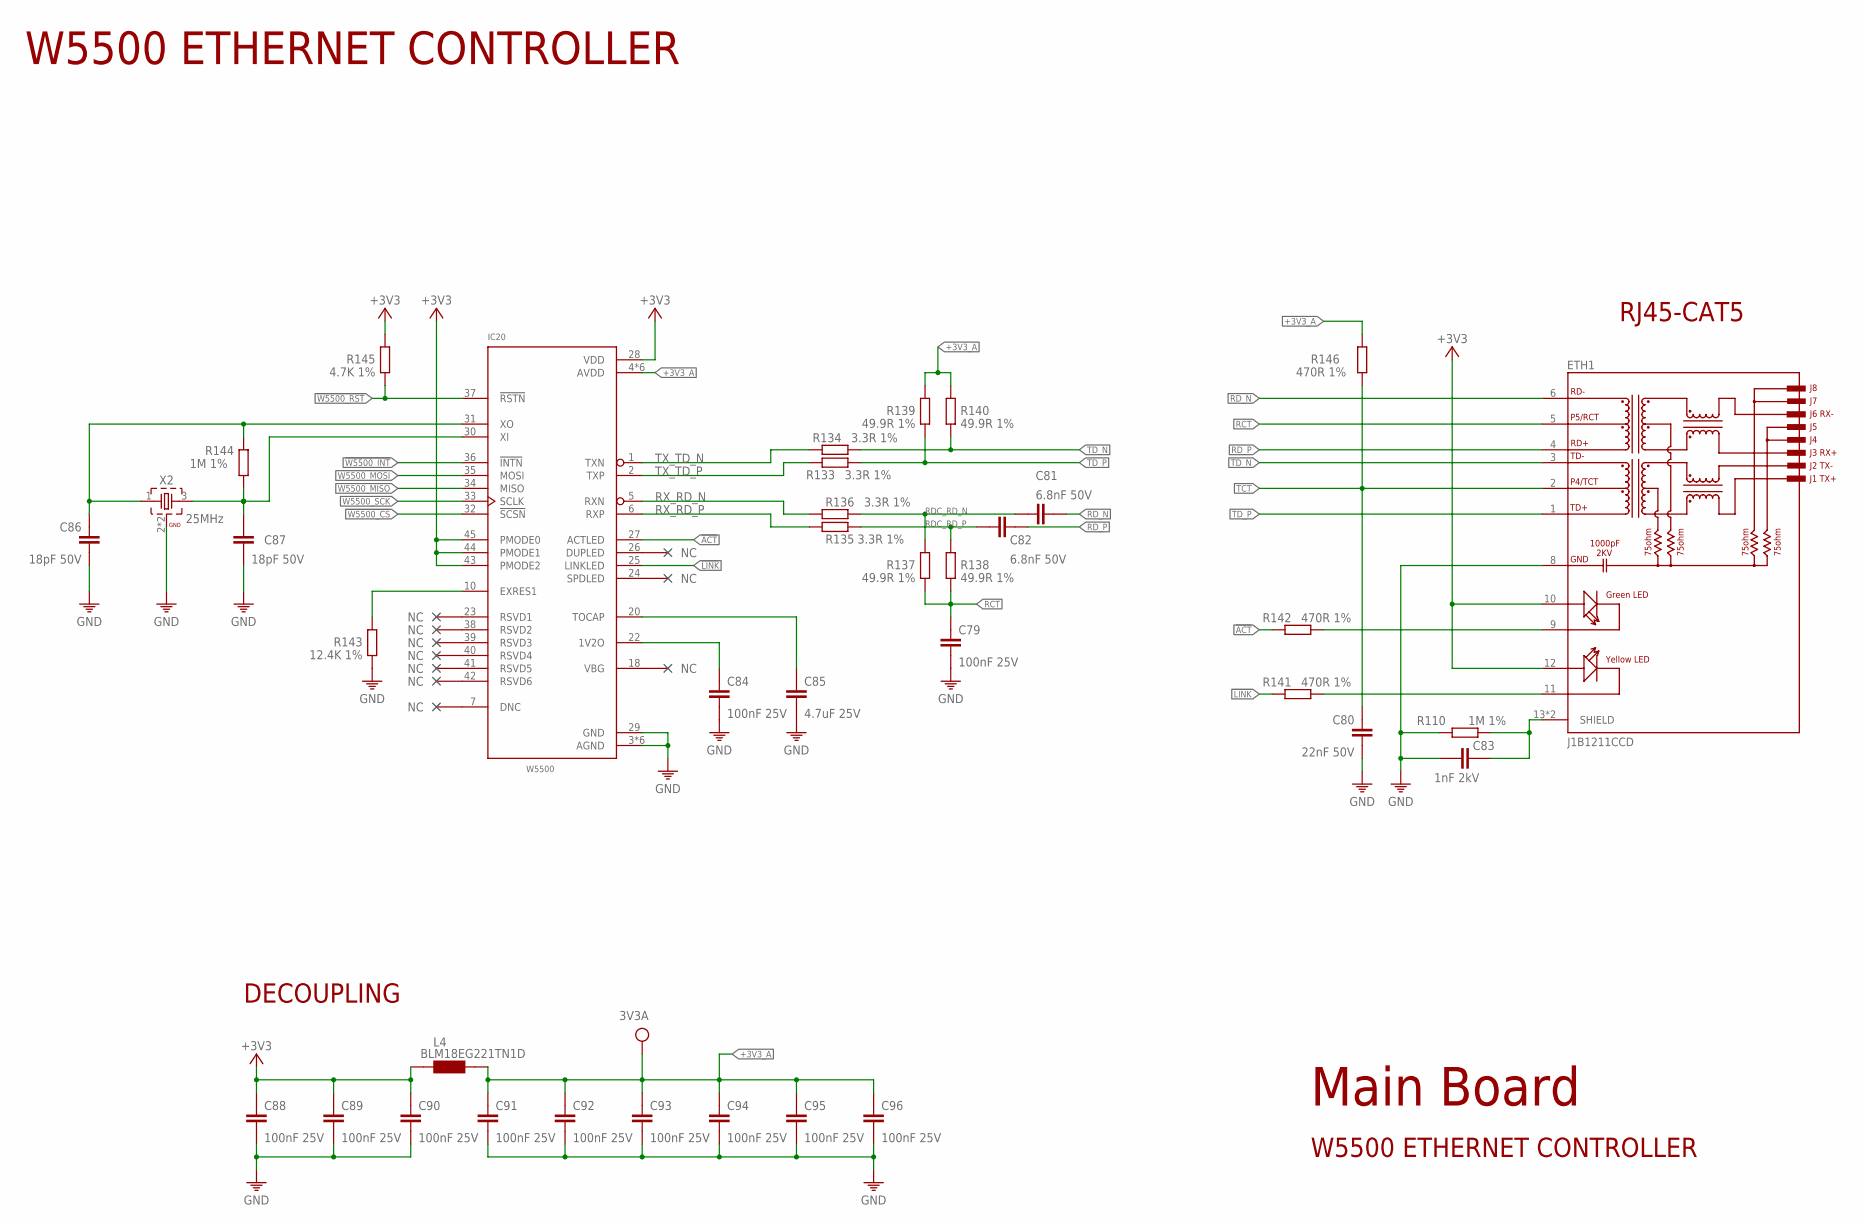
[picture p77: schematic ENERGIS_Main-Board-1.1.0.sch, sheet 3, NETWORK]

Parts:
3V3A: DNI; TP-ROUND
C79: 100nF 25V; 0402
C80: 22nF 50V; 0402
C81, C82: 6.8nF 50V; 0201
C83: 1nF 2kV; 1206
C84, C88, C89, C90, C91, C92, C93, C94, C95, C96: 100nF 25V; 0201
C85: 4.7uF 25V; 0402
C86, C87: 18pF 50V; 0201
ETH1: J1B1211CCD
IC20: W5500; LQFP48
L4: BLM18EG221TN1D; 0603
R110: 1M 1%; 1206
R133, R134, R135, R136: 3.3R 1%; 0201
R137, R138, R139, R140: 49.9R 1%; 0201
R141, R142, R146: 470R 1%; 0402
R143: 12.4K 1%; 0201
R144: 1M 1%; 0201
R145: 4.7K 1%; 0201
X2: 25MHz; WE-XTAL_CFPX-180

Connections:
!ACT: IC20.27 (ACTLED), R142.1
!LINK: IC20.25 (LINKLED), R141.1
!W5500_CS: IC20.32 (!SCSN); also elsewhere on the board
!W5500_INT: IC20.36 (!INTN); also elsewhere on the board
!W5500_RST: IC20.37 (!RSTN), R145.1; also elsewhere on the board
+3V3: C88.1, C89.1, C90.1, ETH1.10 (GREEN+), ETH1.12 (YELLOW+), IC20.28 (VDD), IC20.43 (PMODE2), IC20.44 (PMODE1), IC20.45 (PMODE0), L4.1, R145.2; also elsewhere on the board
+3V3_A: 3V3A.TP, C91.1, C92.1, C93.1, C94.1, C95.1, C96.1, IC20.4 (AVDD), IC20.8 (AVDD), IC20.11 (AVDD), IC20.15 (AVDD), IC20.17 (AVDD), IC20.21 (AVDD), L4.2, R139.2, R140.2, R146.2
GND: C79.2, C80.2, C83.1, C84.2, C85.2, C86.2, C87.2, C88.2, C89.2, C90.2, C91.2, C92.2, C93.2, C94.2, C95.2, C96.2, ETH1.8 (GND), IC20.3 (AGND), IC20.9 (AGND), IC20.14 (AGND), IC20.16 (AGND), IC20.19 (AGND), IC20.29 (GND), IC20.48 (AGND), R110.1, R143.1, X2.2 (GND), X2.4 (GND); also elsewhere on the board
unnamed: ETH1.11 (YELLOW-), R141.2
unnamed: ETH1.9 (GREEN-), R142.2
unnamed: IC20.10 (EXRES1), R143.2
unnamed: C84.1, IC20.22 (1V2O)
unnamed: C85.1, IC20.20 (TOCAP)
unnamed: C87.1, IC20.30 (XI), R144.1, X2.3 (2)
RCT: C79.1, ETH1.5 (P5/RCT), R137.1, R138.1
RDC_RD_N: C81.1, R136.2, R137.2
RDC_RD_P: C82.1, R135.2, R138.2
RD_N: C81.2, ETH1.6 (RD-)
RD_P: C82.2, ETH1.4 (RD+)
RX_RD_N: IC20.5 (RXN), R136.1
RX_RD_P: IC20.6 (RXP), R135.1
SH: C83.2, ETH1.13 (SHIELD), ETH1.14 (SHIELD), R110.2; also elsewhere on the board
TCT: C80.1, ETH1.2 (P4/TCT), R146.1
TD_N: ETH1.3 (TD-), R134.2, R140.1
TD_P: ETH1.1 (TD+), R133.2, R139.1
TX_TD_N: IC20.1 (TXN), R134.1
TX_TD_P: IC20.2 (TXP), R133.1
W5500_MISO: IC20.34 (MISO); also elsewhere on the board
W5500_MOSI: IC20.35 (MOSI); also elsewhere on the board
W5500_SCK: IC20.33 (SCLK); also elsewhere on the board
XO: C86.1, IC20.31 (XO), R144.2, X2.1

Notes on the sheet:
W5500 ETHERNET CONTROLLER
RJ45-CAT5
DECOUPLING
Main Board

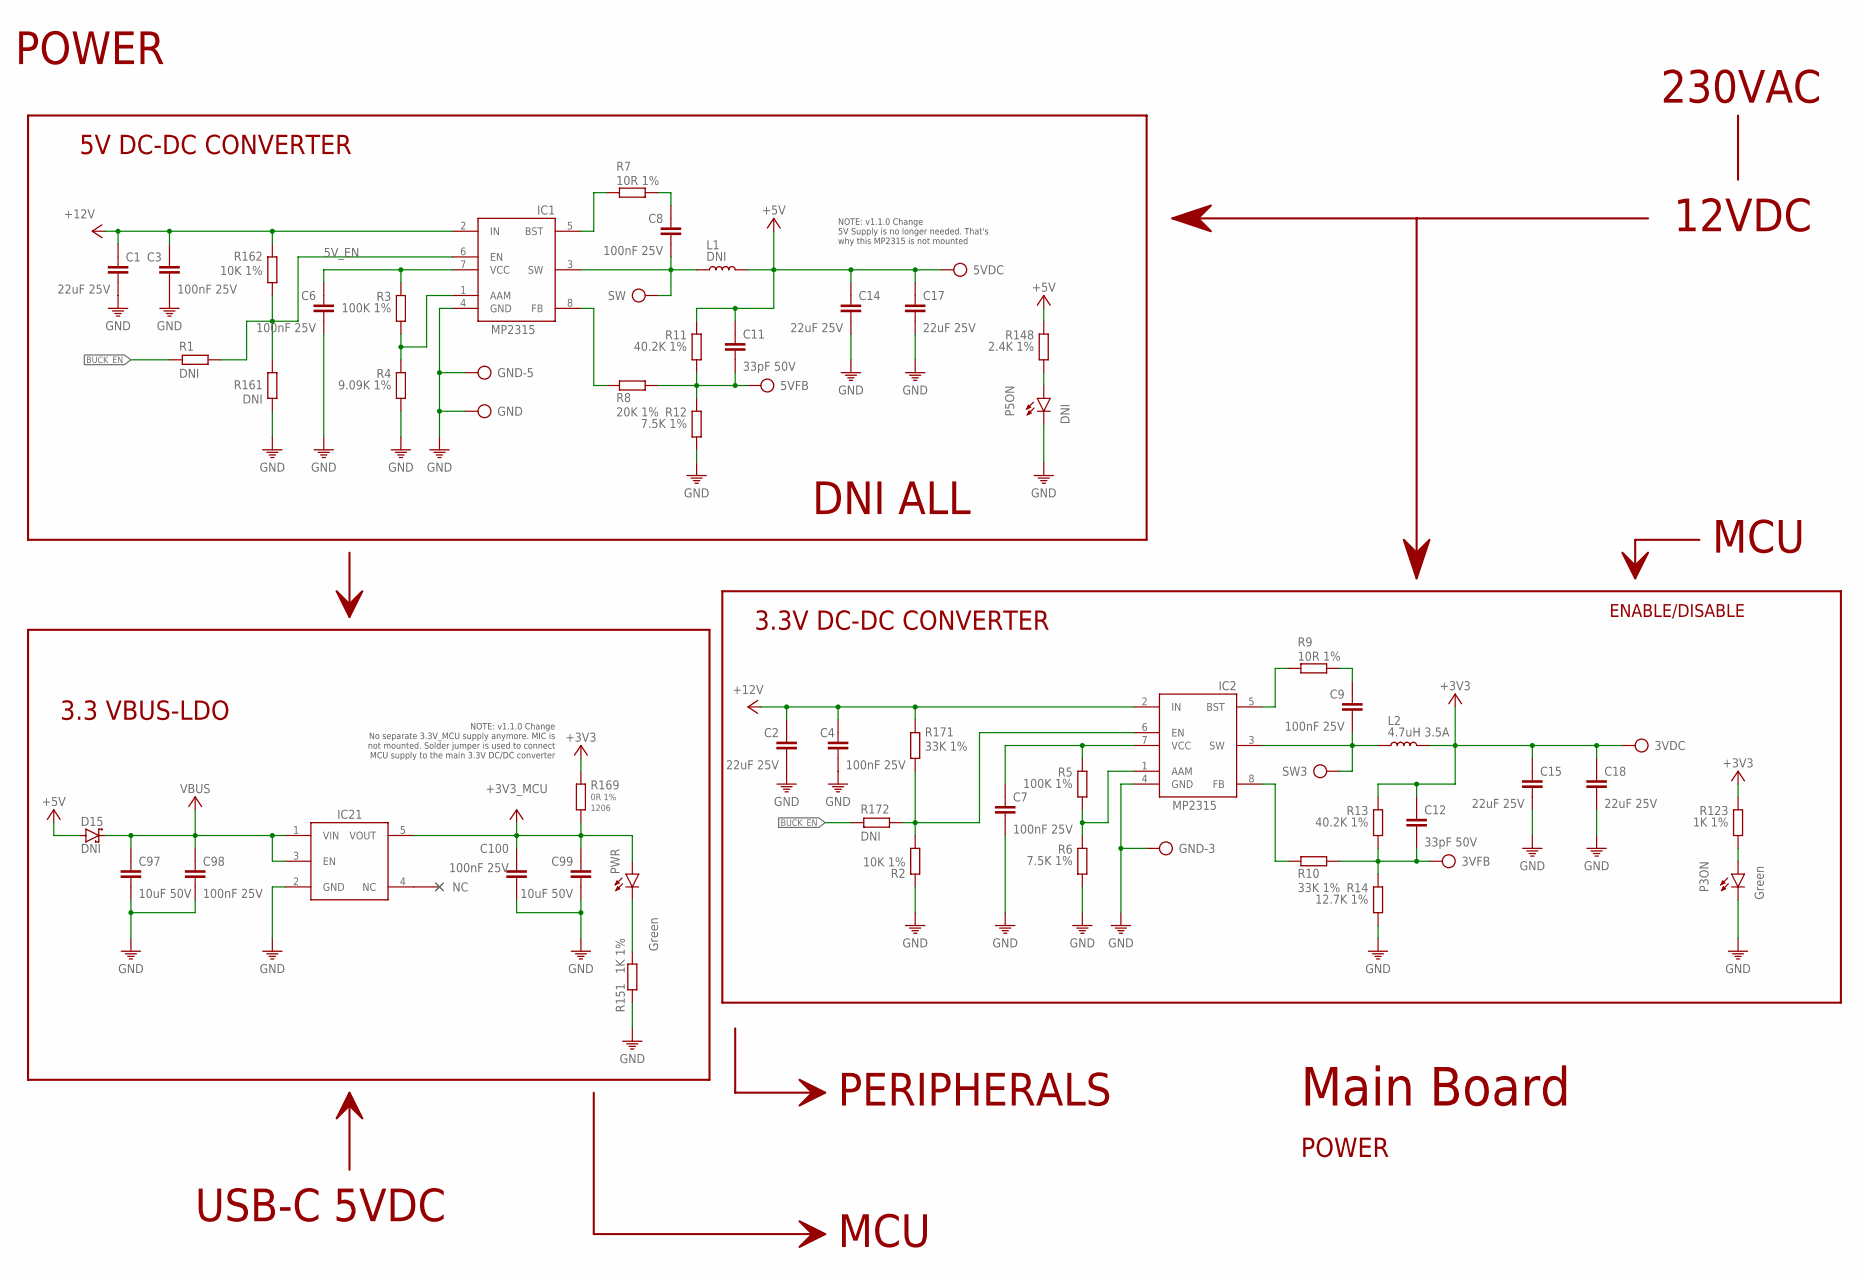
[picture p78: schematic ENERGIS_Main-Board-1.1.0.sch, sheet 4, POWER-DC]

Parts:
3VDC, 3VFB, 5VDC, 5VFB: DNI; TP-ROUND
C1, C2, C14, C15, C17, C18: 22uF 25V; 1206
C3, C4, C6, C7, C8, C9: 100nF 25V; 0402
C11, C12: 33pF 50V; 0402
C97, C99: 10uF 50V; 0805
C98, C100: 100nF 25V; 0201
D15: DNI; SMA/DO-214AC
GND: DNI; TP-ROUND
GND-3, GND-5: DNI; TP-ROUND
IC1: DNI; SOT65P280X110-8N
IC2: MP2315GJ-Z; SOT65P280X110-8N
IC21: MIC5504-3.3YM5; SOT23-5
L1: DNI; SRR5228A
L2: 4.7uH 3.5A; SRR5228A
P3ON: Green; LED-0603
P5ON: DNI; LED-0603
PWR: Green; LED-0603
R1, R161, R172: DNI; 0402
R2, R162: 10K 1%; 0402
R3, R5: 100K 1%; 0402
R4: 9.09K 1%; 0402
R6, R12: 7.5K 1%; 0402
R7, R9: 10R 1%; 0402
R8: 20K 1%; 0402
R10, R171: 33K 1%; 0402
R11, R13: 40.2K 1%; 0402
R14: 12.7K 1%; 0402
R123, R151: 1K 1%; 0402
R148: 2.4K 1%; 0402
R169: 0R 1%; 1206
SW, SW3: DNI; TP-ROUND

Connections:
3V3_EN: IC2.6 (EN), R2.2, R171.1, R172.1
3VFB: 3VFB.TP, C12.2, R10.2, R13.2, R14.1
5VFB: 5VFB.TP, C11.2, R8.2, R11.2, R12.1
5V_EN: IC1.6 (EN), R1.1, R161.2, R162.1
+3V3: 3VDC.TP, C12.1, C15.1, C18.1, L2.2, R13.1, R123.1, R169.1; also elsewhere on the board
+3V3_MCU: C99.1, C100.1, IC21.5 (VOUT), PWR.A, R169.2; also elsewhere on the board
+5V: 5VDC.TP, C11.1, C14.1, C17.1, D15.A, L1.2, R11.1, R148.1; also elsewhere on the board
+12V: C1.1, C2.1, C3.1, C4.1, IC1.2 (IN), IC2.2 (IN), R162.2, R171.2; also elsewhere on the board
BUCK_EN: R1.2, R172.2; also elsewhere on the board
GND: C1.2, C2.2, C3.2, C4.2, C6.2, C7.2, C14.2, C15.2, C17.2, C18.2, C97.2, C98.2, C99.2, C100.2, GND.TP, GND-3.TP, GND-5.TP, IC1.4 (GND), IC2.4 (GND), IC21.2 (GND), P3ON.C, P5ON.C, R2.1, R4.2, R6.2, R12.2, R14.2, R151.1, R161.1; also elsewhere on the board
unnamed: P3ON.A, R123.2
unnamed: P5ON.A, R148.2
unnamed: IC1.5 (BST), R7.2
unnamed: IC1.8 (FB), R8.1
unnamed: C8.1, R7.1
unnamed: C6.1, IC1.7 (VCC), R3.1
unnamed: IC2.5 (BST), R9.2
unnamed: IC2.8 (FB), R10.1
unnamed: C9.1, R9.1
unnamed: C7.1, IC2.7 (VCC), R5.1
unnamed: IC1.1 (AAM), R3.2, R4.1
unnamed: IC2.1 (AAM), R5.2, R6.1
unnamed: PWR.C, R151.2
SW3: C9.2, IC2.3 (SW), L2.1, SW3.TP
SW5: C8.2, IC1.3 (SW), L1.1, SW.TP
VBUS: C97.1, C98.1, D15.C, IC21.1 (VIN), IC21.3 (EN); also elsewhere on the board

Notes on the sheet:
5V DC-DC CONVERTER
3.3V DC-DC CONVERTER
3.3 VBUS-LDO
230VAC
12VDC
USB-C 5VDC
PERIPHERALS
MCU
ENABLE/DISABLE
Main Board
POWER
NOTE: v1.1.0 Change 5V Supply is no longer needed. That's why this MP2315 is not mounted
NOTE: v1.1.0 Change No separate 3.3V_MCU supply anymore. MIC is not mounted. Solder jumper is used to connect MCU supply to the main 3.3V DC/DC converter
DNI ALL

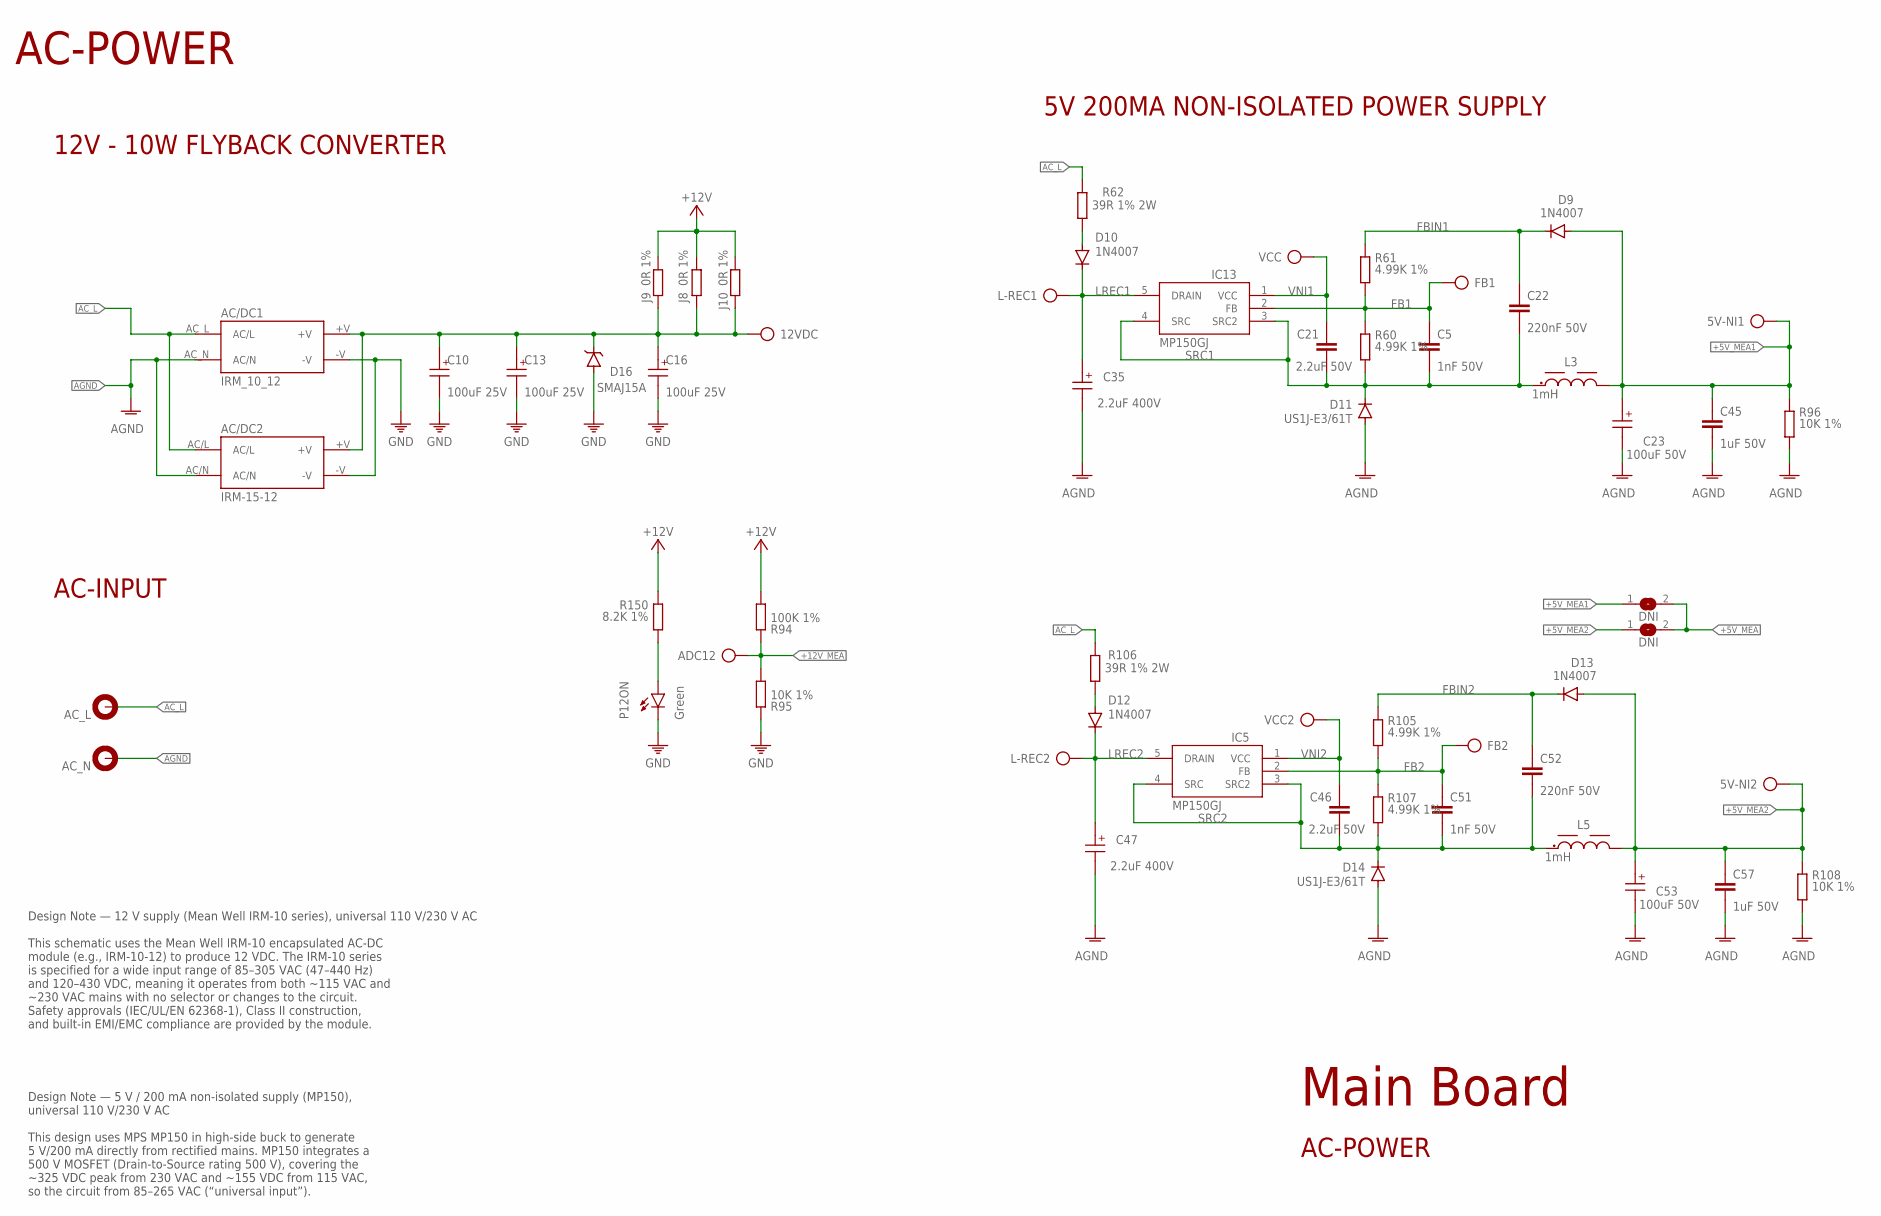
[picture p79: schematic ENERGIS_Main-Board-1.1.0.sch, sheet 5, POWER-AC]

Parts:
5V-NI1, 5V-NI2, 12VDC: DNI; TP-ROUND
AC/DC1: IRM_10_12
AC/DC2: IRM-15-12; IRM_15_12
AC_L: FASTON-1217861-1; 1217861-1
AC_N: FASTON-1217861-1; 1217861-1
ADC12: DNI; TP-ROUND
C5, C51: 1nF 50V; 0603
C10, C13, C16: 100uF 25V; 6.3X7.7(DXL)
C21, C46: 2.2uF 50V; 0603
C22, C52: 220nF 50V; 0805
C23, C53: 100uF 50V; 6.3X7.7(DXL)
C35, C47: 2.2uF 400V; 6.3X7.7(DXL)
C45, C57: 1uF 50V; 0805
D9, D10, D12, D13: 1N4007; SMA/DO-214AC
D11, D14: US1J-E3/61T; SMA/DO-214AC
D16: SMAJ15A; SMA/DO-214AC
FB1, FB2: DNI; TP-ROUND
IC5, IC13: MP150GJ; SOT23-5
J2, J7: DNI; SJ
J8, J9, J10: 0R 1%; 0805
L3, L5: 1mH; L-6.6X6.6
L-REC1, L-REC2: DNI; TP-ROUND
P12ON: Green; LED-0603
R60, R61, R105, R107: 4.99K 1%; 0603
R62, R106: 39R 1% 2W; 2512
R94: 100K 1%; 0402
R95: 10K 1%; 0402
R96, R108: 10K 1%; 0805
R150: 8.2K 1%; 0402
VCC, VCC2: DNI; TP-ROUND

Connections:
12VRAW: 12VDC.TP, AC/DC1.+V, AC/DC2.+V, C10.1 (+), C13.1 (+), C16.1 (+), D16.C, J8.2, J9.2, J10.2
+5V_MEA: J2.2, J7.2; also elsewhere on the board
+5V_MEA1: 5V-NI1.TP, C23.1 (+), C45.2, D9.A, J2.1, L3.2, R96.1
+5V_MEA2: 5V-NI2.TP, C53.1 (+), C57.2, D13.A, J7.1, L5.2, R108.1
+12V: J8.1, J9.1, J10.1, R94.2, R150.1; also elsewhere on the board
+12V_MEA: ADC12.TP, R94.1, R95.2; also elsewhere on the board
AC_L: AC/DC1.AC_L (AC/L), AC/DC2.AC/L, AC_L.1, AC_L.2, R62.1, R106.1; also elsewhere on the board
AGND: AC/DC1.AC_N (AC/N), AC/DC2.AC/N, AC_N.1, AC_N.2, C23.2 (-), C35.2 (-), C45.1, C47.2 (-), C53.2 (-), C57.1, D11.A, D14.A, R96.2, R108.2; also elsewhere on the board
FB1: C5.2, FB1.TP, IC13.2 (FB), R60.1, R61.2
FB2: C51.2, FB2.TP, IC5.2 (FB), R105.2, R107.1
FBIN1: C22.2, D9.C, R61.1
FBIN2: C52.2, D13.C, R105.1
GND: AC/DC1.-V, AC/DC2.-V, C10.2 (-), C13.2 (-), C16.2 (-), D16.A, P12ON.C, R95.1; also elsewhere on the board
LREC1: C35.1 (+), D10.C, IC13.5 (DRAIN), L-REC1.TP
LREC2: C47.1 (+), D12.C, IC5.5 (DRAIN), L-REC2.TP
unnamed: D10.A, R62.2
unnamed: P12ON.A, R150.2
unnamed: D12.A, R106.2
SRC1: C5.1, C21.1, C22.1, D11.C, IC13.3 (SRC2), IC13.4 (SRC), L3.1, R60.2
SRC2: C46.1, C51.1, C52.1, D14.C, IC5.3 (SRC2), IC5.4 (SRC), L5.1, R107.2
VNI1: C21.2, IC13.1 (VCC), VCC.TP
VNI2: C46.2, IC5.1 (VCC), VCC2.TP

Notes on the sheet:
AC-POWER
5V 200MA NON-ISOLATED POWER SUPPLY
AC-INPUT
Design Note — 5 V / 200 mA non-isolated supply (MP150), universal 110 V/230 V AC This design uses MPS MP150 in high-side buck to generate 5 V/200 mA directly from rectified mains. MP150 integrates a 500 V MOSFET (Drain-to-Source rating 500 V), covering the ~325 VDC peak from 230 VAC and ~155 VDC fr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
Design Note — 12 V supply (Mean Well IRM-10 series), universal 110 V/230 V AC This schematic uses the Mean Well IRM-10 encapsulated AC-DC module (e.g., IRM-10-12) to produce 12 VDC. The IRM-10 series is specified for a wide input range of 85–305 VAC (47–440 Hz) and 120–430 VDC, meaning it operates 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
Main Board
12V - 10W FLYBACK CONVERTER

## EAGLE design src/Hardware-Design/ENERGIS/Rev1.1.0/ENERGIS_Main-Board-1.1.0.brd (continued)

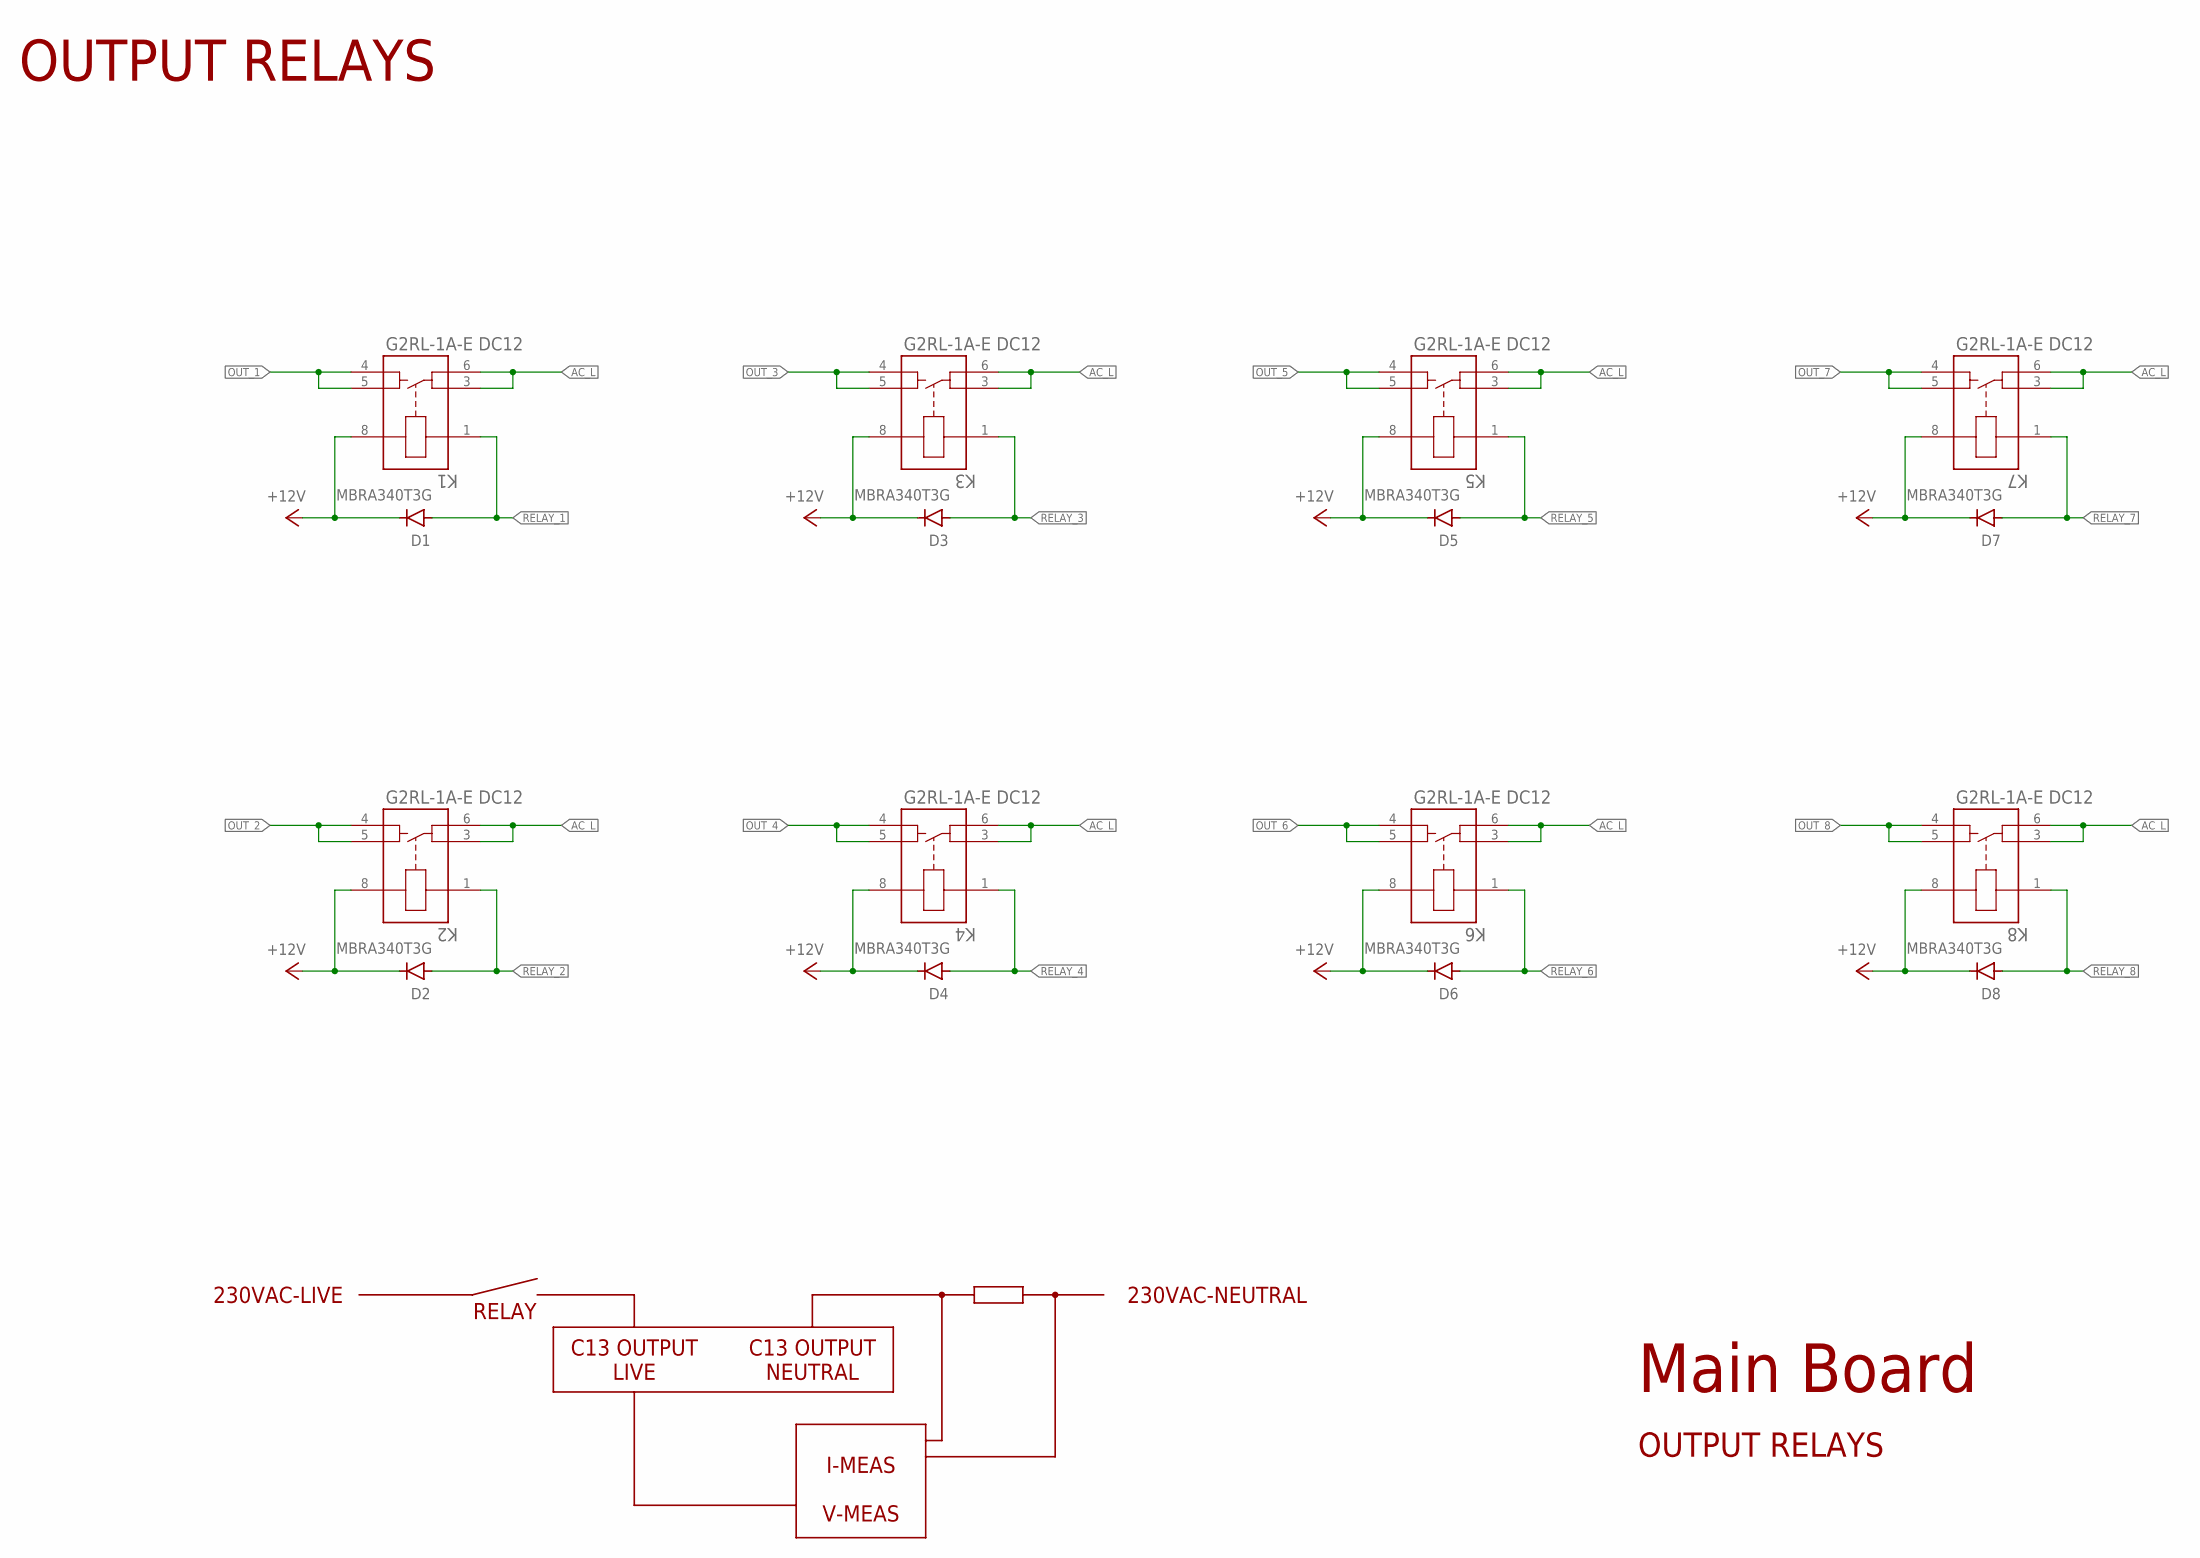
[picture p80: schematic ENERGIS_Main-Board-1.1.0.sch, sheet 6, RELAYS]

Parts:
D1, D2, D3, D4, D5, D6, D7, D8: MBRA340T3G; SMA/DO-214AC
K1, K2, K3, K4, K5, K6, K7, K8: G2RL-1A-E DC12; RELAY_G2RL-1A-E_DC5_OMR

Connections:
+12V: D1.C, D2.C, D3.C, D4.C, D5.C, D6.C, D7.C, D8.C, K1.8, K2.8, K3.8, K4.8, K5.8, K6.8, K7.8, K8.8; also elsewhere on the board
AC_L: K1.3, K1.6, K2.3, K2.6, K3.3, K3.6, K4.3, K4.6, K5.3, K5.6, K6.3, K6.6, K7.3, K7.6, K8.3, K8.6; also elsewhere on the board
OUT_1: K1.4, K1.5; also elsewhere on the board
OUT_2: K2.4, K2.5; also elsewhere on the board
OUT_3: K3.4, K3.5; also elsewhere on the board
OUT_4: K4.4, K4.5; also elsewhere on the board
OUT_5: K5.4, K5.5; also elsewhere on the board
OUT_6: K6.4, K6.5; also elsewhere on the board
OUT_7: K7.4, K7.5; also elsewhere on the board
OUT_8: K8.4, K8.5; also elsewhere on the board
RELAY_1: D1.A, K1.1; also elsewhere on the board
RELAY_2: D2.A, K2.1; also elsewhere on the board
RELAY_3: D3.A, K3.1; also elsewhere on the board
RELAY_4: D4.A, K4.1; also elsewhere on the board
RELAY_5: D5.A, K5.1; also elsewhere on the board
RELAY_6: D6.A, K6.1; also elsewhere on the board
RELAY_7: D7.A, K7.1; also elsewhere on the board
RELAY_8: D8.A, K8.1; also elsewhere on the board

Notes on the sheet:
OUTPUT RELAYS
230VAC-LIVE
C13 OUTPUT NEUTRAL
C13 OUTPUT LIVE
RELAY
230VAC-NEUTRAL
I-MEAS V-MEAS
Main Board

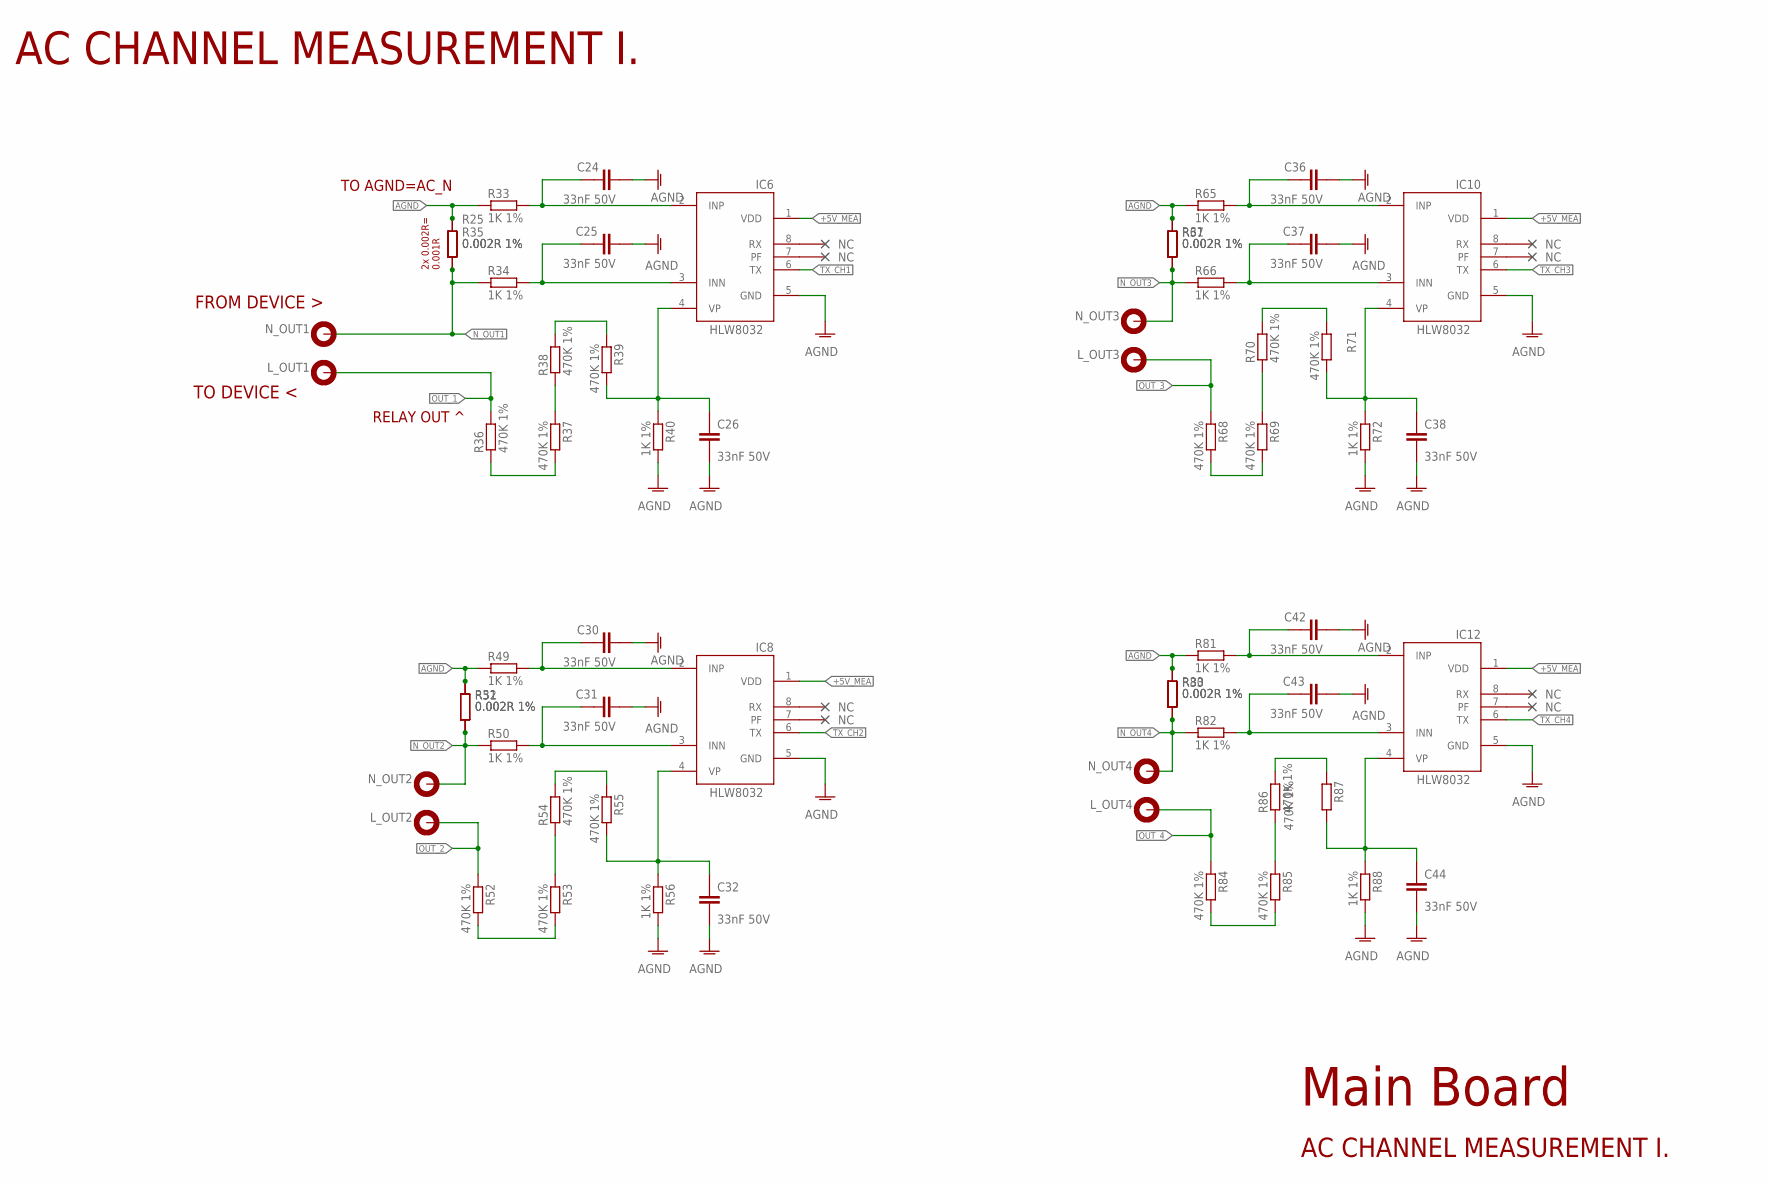
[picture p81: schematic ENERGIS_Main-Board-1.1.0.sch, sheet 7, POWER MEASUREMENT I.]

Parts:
C24, C25, C26, C30, C31, C32, C36, C37, C38, C42, C43, C44: 33nF 50V; 0805
IC6, IC8, IC10, IC12: HLW8032; SO8
L_OUT1, L_OUT2, L_OUT3, L_OUT4: FASTON-1217861-1; 1217861-1
N_OUT1, N_OUT2, N_OUT3, N_OUT4: FASTON-1217861-1; 1217861-1
R25, R30, R31, R32, R35, R51, R67, R83: 0.002R 1%; 2512
R33, R34, R40, R49, R50, R56, R65, R66, R72, R81, R82, R88: 1K 1%; 0805
R36, R37, R38, R39, R52, R53, R54, R55, R68, R69, R70, R71, R84, R85, R86, R87: 470K 1%; 0805

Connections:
+5V_MEA: IC6.1 (VDD), IC8.1 (VDD), IC10.1 (VDD), IC12.1 (VDD); also elsewhere on the board
AGND: C24.2, C25.2, C26.2, C30.2, C31.2, C32.2, C36.2, C37.2, C38.2, C42.2, C43.2, C44.2, IC6.5 (GND), IC8.5 (GND), IC10.5 (GND), IC12.5 (GND), R25.2, R30.2, R31.2, R32.2, R33.1, R35.2, R40.2, R49.1, R51.2, R56.2, R65.1, R67.2, R72.2, R81.1, R83.2, R88.2; also elsewhere on the board
unnamed: C24.1, IC6.2 (INP), R33.2
unnamed: C25.1, IC6.3 (INN), R34.2
unnamed: R38.2, R39.1
unnamed: R52.2, R53.2
unnamed: R37.1, R38.1
unnamed: C26.1, IC6.4 (VP), R39.2, R40.1
unnamed: R53.1, R54.1
unnamed: R54.2, R55.1
unnamed: R68.2, R69.2
unnamed: C30.1, IC8.2 (INP), R49.2
unnamed: C31.1, IC8.3 (INN), R50.2
unnamed: R69.1, R70.1
unnamed: R70.2, R71.1
unnamed: R84.2, R85.2
unnamed: C32.1, IC8.4 (VP), R55.2, R56.1
unnamed: C36.1, IC10.2 (INP), R65.2
unnamed: C37.1, IC10.3 (INN), R66.2
unnamed: R85.1, R86.1
unnamed: R86.2, R87.1
unnamed: C38.1, IC10.4 (VP), R71.2, R72.1
unnamed: C42.1, IC12.2 (INP), R81.2
unnamed: C43.1, IC12.3 (INN), R82.2
unnamed: C44.1, IC12.4 (VP), R87.2, R88.1
unnamed: R36.1, R37.2
N_OUT1: N_OUT1.1, N_OUT1.2, R25.1, R34.1, R35.1
N_OUT2: N_OUT2.1, N_OUT2.2, R32.1, R50.1, R51.1
N_OUT3: N_OUT3.1, N_OUT3.2, R31.1, R66.1, R67.1
N_OUT4: N_OUT4.1, N_OUT4.2, R30.1, R82.1, R83.1
OUT_1: L_OUT1.1, L_OUT1.2, R36.2; also elsewhere on the board
OUT_2: L_OUT2.1, L_OUT2.2, R52.1; also elsewhere on the board
OUT_3: L_OUT3.1, L_OUT3.2, R68.1; also elsewhere on the board
OUT_4: L_OUT4.1, L_OUT4.2, R84.1; also elsewhere on the board
TX_CH1: IC6.6 (TX); also elsewhere on the board
TX_CH2: IC8.6 (TX); also elsewhere on the board
TX_CH3: IC10.6 (TX); also elsewhere on the board
TX_CH4: IC12.6 (TX); also elsewhere on the board

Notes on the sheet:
AC CHANNEL MEASUREMENT I.
TO DEVICE <
FROM DEVICE >
2x 0.002R= 0.001R
TO AGND=AC_N
RELAY OUT ^
Main Board

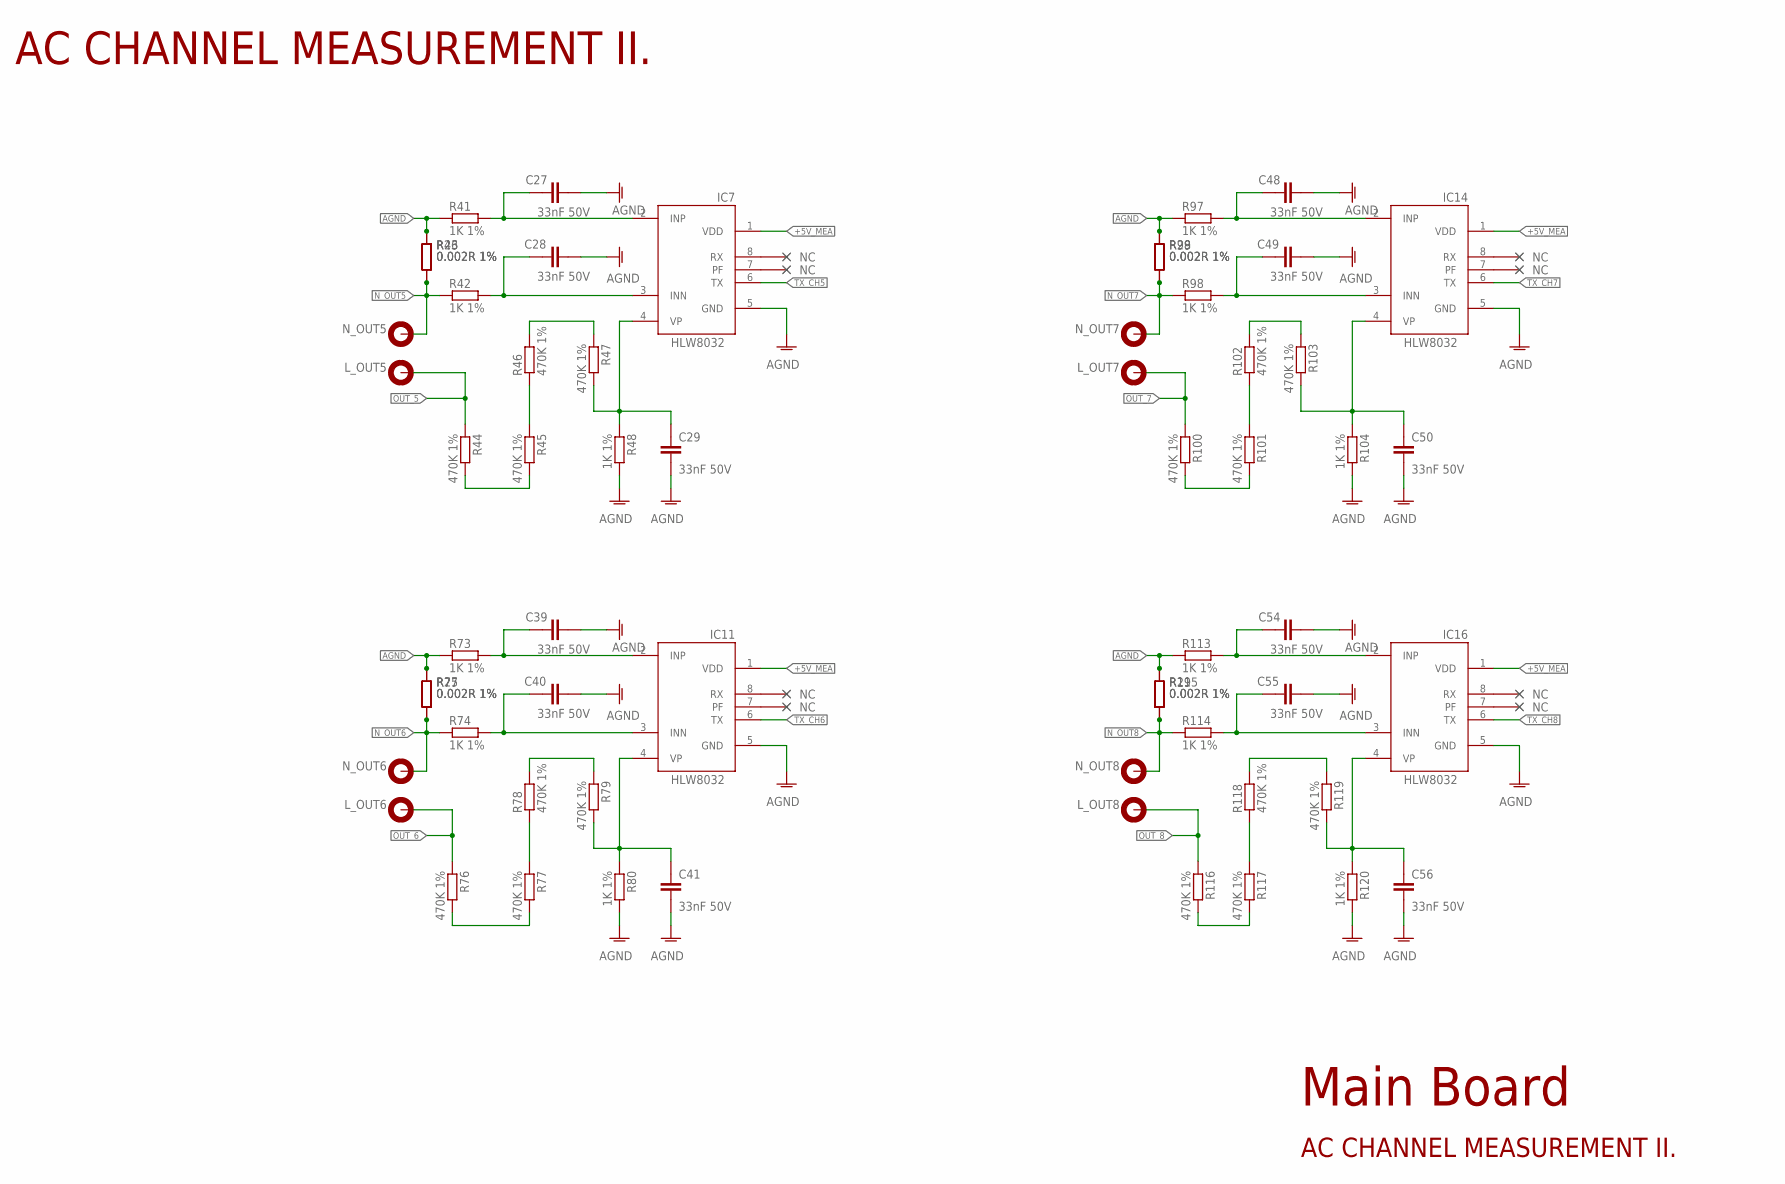
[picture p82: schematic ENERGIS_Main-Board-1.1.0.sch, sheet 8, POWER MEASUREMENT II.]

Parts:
C27, C28, C29, C39, C40, C41, C48, C49, C50, C54, C55, C56: 33nF 50V; 0805
IC7, IC11, IC14, IC16: HLW8032; SO8
L_OUT5, L_OUT6, L_OUT7, L_OUT8: FASTON-1217861-1; 1217861-1
N_OUT5, N_OUT6, N_OUT7, N_OUT8: FASTON-1217861-1; 1217861-1
R26, R27, R28, R29, R43, R75, R99, R115: 0.002R 1%; 2512
R41, R42, R48, R73, R74, R80, R97, R98, R104, R113, R114, R120: 1K 1%; 0805
R44, R45, R46, R47, R76, R77, R78, R79, R100, R101, R102, R103, R116, R117, R118, R119: 470K 1%; 0805

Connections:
+5V_MEA: IC7.1 (VDD), IC11.1 (VDD), IC14.1 (VDD), IC16.1 (VDD); also elsewhere on the board
AGND: C27.2, C28.2, C29.2, C39.2, C40.2, C41.2, C48.2, C49.2, C50.2, C54.2, C55.2, C56.2, IC7.5 (GND), IC11.5 (GND), IC14.5 (GND), IC16.5 (GND), R26.2, R27.2, R28.2, R29.2, R41.1, R43.2, R48.2, R73.1, R75.2, R80.2, R97.1, R99.2, R104.2, R113.1, R115.2, R120.2; also elsewhere on the board
unnamed: C27.1, IC7.2 (INP), R41.2
unnamed: C28.1, IC7.3 (INN), R42.2
unnamed: C29.1, IC7.4 (VP), R47.2, R48.1
unnamed: R44.2, R45.2
unnamed: C39.1, IC11.2 (INP), R73.2
unnamed: C40.1, IC11.3 (INN), R74.2
unnamed: R45.1, R46.1
unnamed: R46.2, R47.1
unnamed: R76.2, R77.2
unnamed: C41.1, IC11.4 (VP), R79.2, R80.1
unnamed: R77.1, R78.1
unnamed: R78.2, R79.1
unnamed: R100.2, R101.2
unnamed: C48.1, IC14.2 (INP), R97.2
unnamed: C49.1, IC14.3 (INN), R98.2
unnamed: R101.1, R102.1
unnamed: R102.2, R103.1
unnamed: R116.2, R117.2
unnamed: C50.1, IC14.4 (VP), R103.2, R104.1
unnamed: C54.1, IC16.2 (INP), R113.2
unnamed: C55.1, IC16.3 (INN), R114.2
unnamed: R117.1, R118.1
unnamed: R118.2, R119.1
unnamed: C56.1, IC16.4 (VP), R119.2, R120.1
N_OUT5: N_OUT5.1, N_OUT5.2, R26.1, R42.1, R43.1
N_OUT6: N_OUT6.1, N_OUT6.2, R27.1, R74.1, R75.1
N_OUT7: N_OUT7.1, N_OUT7.2, R28.1, R98.1, R99.1
N_OUT8: N_OUT8.1, N_OUT8.2, R29.1, R114.1, R115.1
OUT_5: L_OUT5.1, L_OUT5.2, R44.1; also elsewhere on the board
OUT_6: L_OUT6.1, L_OUT6.2, R76.1; also elsewhere on the board
OUT_7: L_OUT7.1, L_OUT7.2, R100.1; also elsewhere on the board
OUT_8: L_OUT8.1, L_OUT8.2, R116.1; also elsewhere on the board
TX_CH5: IC7.6 (TX); also elsewhere on the board
TX_CH6: IC11.6 (TX); also elsewhere on the board
TX_CH7: IC14.6 (TX); also elsewhere on the board
TX_CH8: IC16.6 (TX); also elsewhere on the board

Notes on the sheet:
AC CHANNEL MEASUREMENT II.
Main Board

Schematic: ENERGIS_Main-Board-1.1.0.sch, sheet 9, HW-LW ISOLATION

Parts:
C106, C107, C108, C109, C110, C111, C112, C113: 1nF 25V; 0201
OPT1, OPT2: ACPL-247-500E; SO16
R59, R153, R154, R155, R156, R157, R158, R159: 1K 1%; 0201
R63, R64: 1K 1%; _0603X4-1206
R89, R90: 10K 1%; _0603X4-1206

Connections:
+3V3: R89.A2 (8), R89.B2 (7), R89.C2 (6), R89.D2 (5), R90.A2 (8), R90.B2 (7), R90.C2 (6), R90.D2 (5); also elsewhere on the board
+5V_MEA: R63.A1 (1), R63.B1 (2), R63.C1 (3), R63.D1 (4), R64.A1 (1), R64.B1 (2), R64.C1 (3), R64.D1 (4); also elsewhere on the board
AGND: C106.2, C107.2, C108.2, C109.2, C110.2, C111.2, C112.2, C113.2; also elsewhere on the board
GND: OPT1.9, OPT1.11, OPT1.13, OPT1.15, OPT2.9, OPT2.11, OPT2.13, OPT2.15; also elsewhere on the board
TX1_LP: C109.1, OPT1.8, R155.2
TX1_PU: OPT1.7, R63.D2 (5)
TX2_LP: C108.1, OPT1.6, R154.2
TX2_PU: OPT1.5, R63.C2 (6)
TX3_LP: C107.1, OPT1.4, R153.2
TX3_PU: OPT1.3, R63.B2 (7)
TX4_LP: C106.1, OPT1.2, R59.2
TX4_PU: OPT1.1, R63.A2 (8)
TX5_LP: C110.1, OPT2.2, R156.2
TX5_PU: OPT2.1, R64.A2 (8)
TX6_LP: C111.1, OPT2.4, R157.2
TX6_PU: OPT2.3, R64.B2 (7)
TX7_LP: C112.1, OPT2.6, R158.2
TX7_PU: OPT2.5, R64.C2 (6)
TX8_LP: C113.1, OPT2.8, R159.2
TX8_PU: OPT2.7, R64.D2 (5)
TX_CH1: R155.1; also elsewhere on the board
TX_CH2: R154.1; also elsewhere on the board
TX_CH3: R153.1; also elsewhere on the board
TX_CH4: R59.1; also elsewhere on the board
TX_CH5: R159.1; also elsewhere on the board
TX_CH6: R158.1; also elsewhere on the board
TX_CH7: R157.1; also elsewhere on the board
TX_CH8: R156.1; also elsewhere on the board
TX_MUX1: OPT1.10, R89.D1 (4); also elsewhere on the board
TX_MUX2: OPT1.12, R89.C1 (3); also elsewhere on the board
TX_MUX3: OPT1.14, R89.B1 (2); also elsewhere on the board
TX_MUX4: OPT1.16, R89.A1 (1); also elsewhere on the board
TX_MUX5: OPT2.10, R90.A1 (1); also elsewhere on the board
TX_MUX6: OPT2.12, R90.B1 (2); also elsewhere on the board
TX_MUX7: OPT2.14, R90.C1 (3); also elsewhere on the board
TX_MUX8: OPT2.16, R90.D1 (4); also elsewhere on the board

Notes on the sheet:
SERIAL OPTOISOLATOR
Main Board
NOTE: v1.1.0 Change TX_MUX5:8 was switched in 1.0.0. Due to software correction, it had no impact. Correct wiring order is now implemented from 1.1.0

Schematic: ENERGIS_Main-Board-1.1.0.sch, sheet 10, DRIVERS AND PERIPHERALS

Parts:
C19, C20, C33, C34: 100nF 25V; 0402
C103: 100nF 25V; 0201
DAT: Blue; LED-0603
IC3: ULN2803AFWG; SO18
IC4: MCP23017T-E/ML; QFN28[6X6]ML
IC9: SN74HC151PWR; TSSOP16
IC22: MCP6001RT-I/OT; SOT23-5
R17, R18, R19, R20, R21, R22, R23, R24: 0R 1%; 2512
R57, R91: 0R 1%; 0402
R58, R92: DNI; 0402
R93: 10K 1%; _0603X4-1206
R122: 1K 1%; 0402
REL0, REL1, REL2, REL3, REL4, REL5, REL6, REL7: DNI; TP-ROUND
RN1, RN2: 100K 1%; _0603X4-1206
UTX: DNI; TP-ROUND

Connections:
!TX_OUT: IC9.6 (!Y), IC22.3 (+IN), R92.1
+3V3: C19.1, C20.1, C33.1, C34.1, C103.1, IC4.5 (VDD), IC9.16 (VCC), IC22.2 (V+); also elsewhere on the board
+12V: IC3.10 (COM); also elsewhere on the board
GND: C19.2, C20.2, C33.2, C34.2, C103.2, DAT.C, IC3.9 (GND), IC4.6 (VSS), IC4.11 (A0), IC4.12 (A1), IC4.13 (A2), IC4.PAD (VSS), IC9.8 (GND), IC22.5 (V-), R93.A2 (8), R93.B2 (7), R93.C2 (6), R93.D2 (5), RN1.A1 (1), RN1.B1 (1), RN1.C1 (1), RN1.D1 (1), RN2.A1 (1), RN2.B1 (1), RN2.C1 (1), RN2.D1 (1); also elsewhere on the board
I2C1_SCL: IC4.8 (SCL); also elsewhere on the board
I2C1_SDA: IC4.9 (SDA); also elsewhere on the board
MCP_REL_RST: IC4.14 (!RESET); also elsewhere on the board
MUX_A: IC4.25 (IO2.0), IC9.11 (A), R93.D1 (4)
MUX_B: IC4.26 (IO2.1), IC9.10 (B), R93.C1 (3)
MUX_C: IC4.27 (IO2.2), IC9.9 (C), R93.B1 (2)
MUX_EN: IC4.28 (IO2.3), IC9.7 (!EN), R93.A1 (1)
unnamed: DAT.A, R122.2
unnamed: IC3.14 (5C), R21.1
unnamed: IC3.11 (8C), R24.1
unnamed: IC3.12 (7C), R23.1
unnamed: IC3.13 (6C), R22.1
unnamed: IC3.15 (4C), R20.1
unnamed: IC3.16 (3C), R19.1
unnamed: IC3.17 (2C), R18.1
unnamed: IC3.18 (1C), R17.1
RELAY_1: R24.2; also elsewhere on the board
RELAY_2: R23.2; also elsewhere on the board
RELAY_3: R22.2; also elsewhere on the board
RELAY_4: R21.2; also elsewhere on the board
RELAY_5: R20.2; also elsewhere on the board
RELAY_6: R19.2; also elsewhere on the board
RELAY_7: R18.2; also elsewhere on the board
RELAY_8: R17.2; also elsewhere on the board
REL_0: IC3.8 (8B), IC4.17 (IO1.0), REL0.TP, RN1.A2 (2)
REL_1: IC3.7 (7B), IC4.18 (IO1.1), REL1.TP, RN1.B2 (2)
REL_2: IC3.6 (6B), IC4.19 (IO1.2), REL2.TP, RN1.C2 (2)
REL_3: IC3.5 (5B), IC4.20 (IO1.3), REL3.TP, RN1.D2 (2)
REL_4: IC3.4 (4B), IC4.21 (IO1.4), REL4.TP, RN2.A2 (2)
REL_5: IC3.3 (3B), IC4.22 (IO1.5), REL5.TP, RN2.B2 (2)
REL_6: IC3.2 (2B), IC4.23 (IO1.6), REL6.TP, RN2.C2 (2)
REL_7: IC3.1 (1B), IC4.24 (IO1.7), REL7.TP, RN2.D2 (2)
TX_FB: IC22.1 (OUT), IC22.4 (-IN), R122.1
TX_MUX1: IC9.4 (D0); also elsewhere on the board
TX_MUX2: IC9.3 (D1); also elsewhere on the board
TX_MUX3: IC9.2 (D2); also elsewhere on the board
TX_MUX4: IC9.1 (D3); also elsewhere on the board
TX_MUX5: IC9.15 (D4); also elsewhere on the board
TX_MUX6: IC9.14 (D5); also elsewhere on the board
TX_MUX7: IC9.13 (D6); also elsewhere on the board
TX_MUX8: IC9.12 (D7); also elsewhere on the board
TX_OUT: IC9.5 (Y), R91.1
TX_OUTSEL: R57.1, R58.1, R91.2, R92.2, UTX.TP
UART0_RX: R58.2; also elsewhere on the board
UART0_TX: R57.2; also elsewhere on the board

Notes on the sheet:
ULN2803 RELAY DRIVER
IO DRIVER
SERIAL MUX
TX1 TX2 TX3 ...
OPTO
IN1 M IN2 U IN3 X ...
SELECTOR
SEL A/B/C
OUT
MCU RX
RELAY1
RELAY2
RELAY3 ...
DRIVER
AC-MEASUREMENT SIGNAL PATH
Main Board

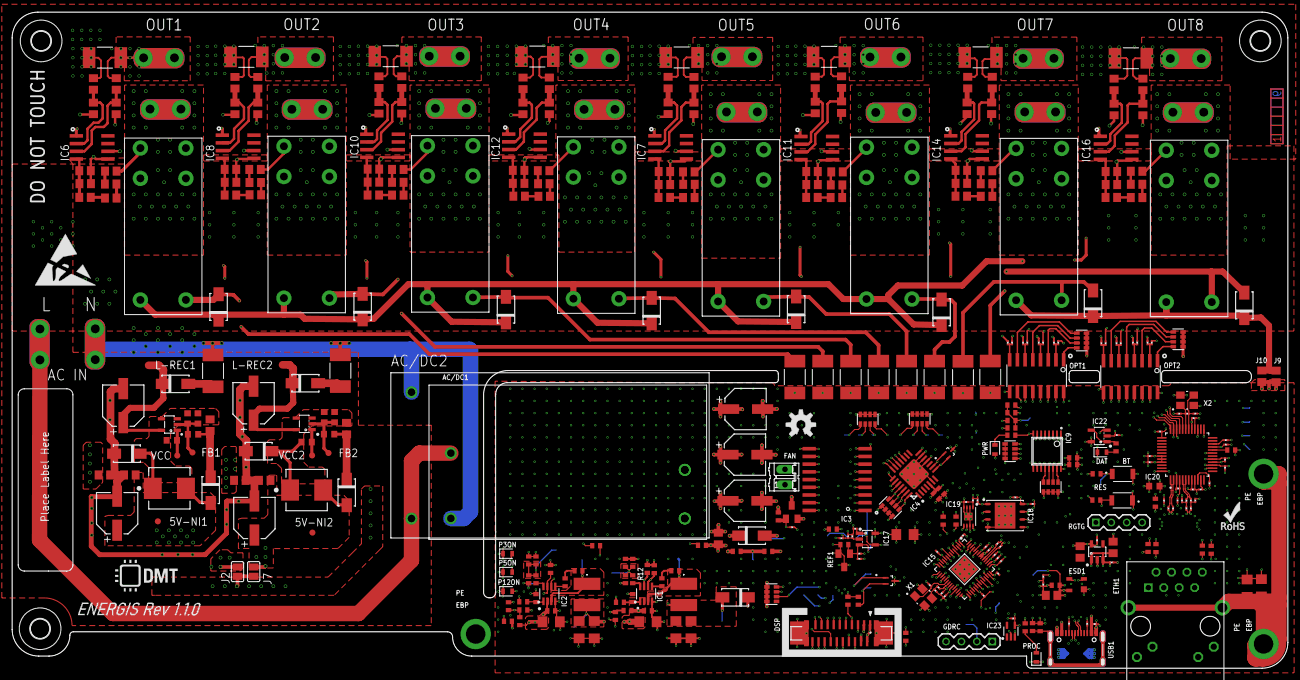
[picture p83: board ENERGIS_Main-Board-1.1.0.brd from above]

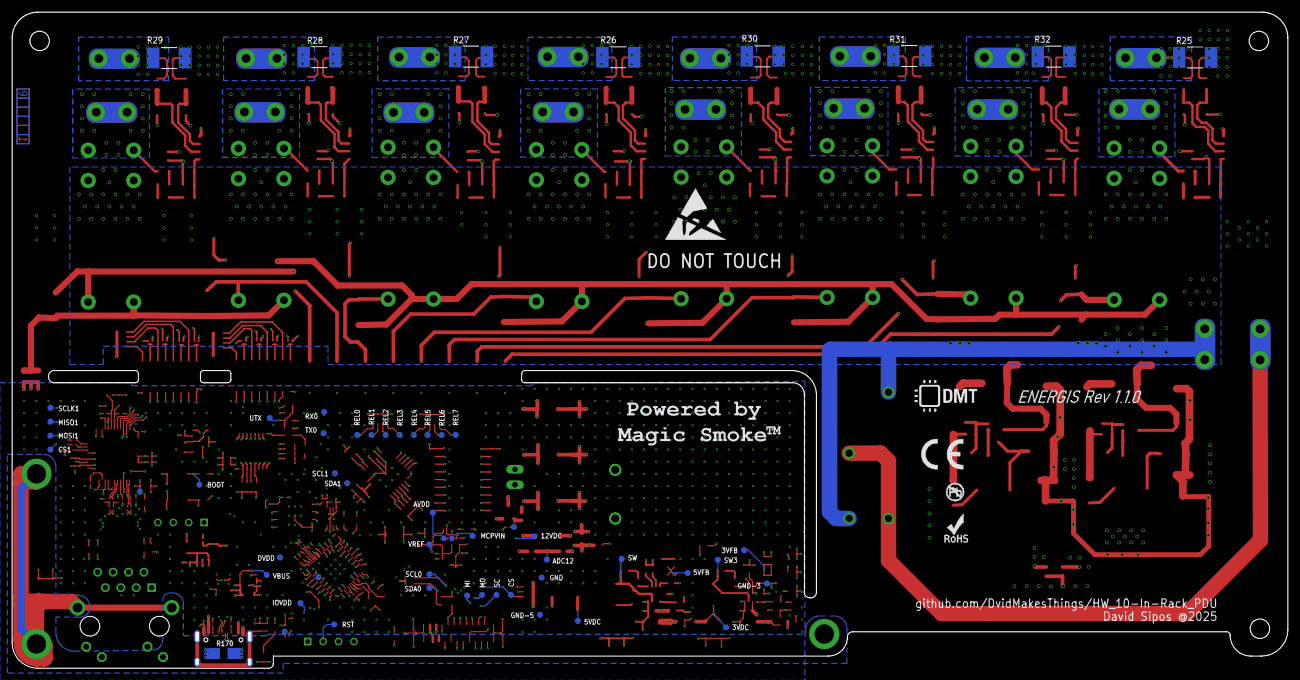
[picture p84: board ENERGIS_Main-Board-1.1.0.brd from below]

Board: 6 copper layers, 210.0 x 108.0 mm, 455 parts (62 on the bottom side), 254 nets.

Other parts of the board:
U$1, U$2: DNI; ESD_10.00
U$3, U$4, U$6: DNI; 3,2
U$5, U$7: DNI; DMT
U$10: DNI; OSHW-LOGO-M
U$11, U$14: DNI; ROHS_LOGO_0.18_IN
U$12: DNI; CE_5MM
U$13: DNI; NO_PB_LOGO_0.120
U$15: DNI; SMOKE

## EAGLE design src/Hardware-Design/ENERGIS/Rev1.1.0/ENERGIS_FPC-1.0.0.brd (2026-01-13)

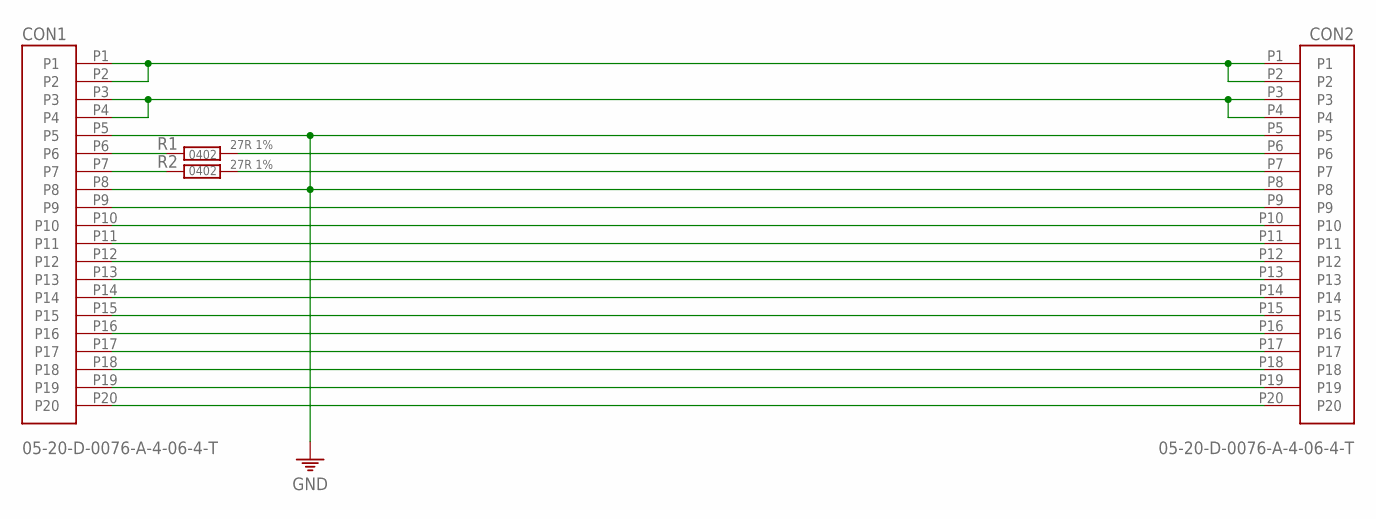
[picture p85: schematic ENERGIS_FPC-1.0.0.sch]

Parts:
CON1, CON2: 05-20-D-0076-A-4-06-4-T
R1, R2: 27R 1%; 0402

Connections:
GND: CON1.P5, CON1.P8, CON2.P5, CON2.P8
unnamed: CON1.P1, CON1.P2, CON2.P1, CON2.P2
unnamed: CON1.P3, CON1.P4, CON2.P3, CON2.P4
unnamed: CON1.P6, R1.1
unnamed: CON1.P7, R2.1
unnamed: CON1.P9, CON2.P9
unnamed: CON1.P10, CON2.P10
unnamed: CON1.P11, CON2.P11
unnamed: CON1.P12, CON2.P12
unnamed: CON1.P13, CON2.P13
unnamed: CON1.P14, CON2.P14
unnamed: CON1.P15, CON2.P15
unnamed: CON1.P16, CON2.P16
unnamed: CON1.P17, CON2.P17
unnamed: CON1.P18, CON2.P18
unnamed: CON1.P19, CON2.P19
unnamed: CON1.P20, CON2.P20
unnamed: CON2.P6, R1.2
unnamed: CON2.P7, R2.2

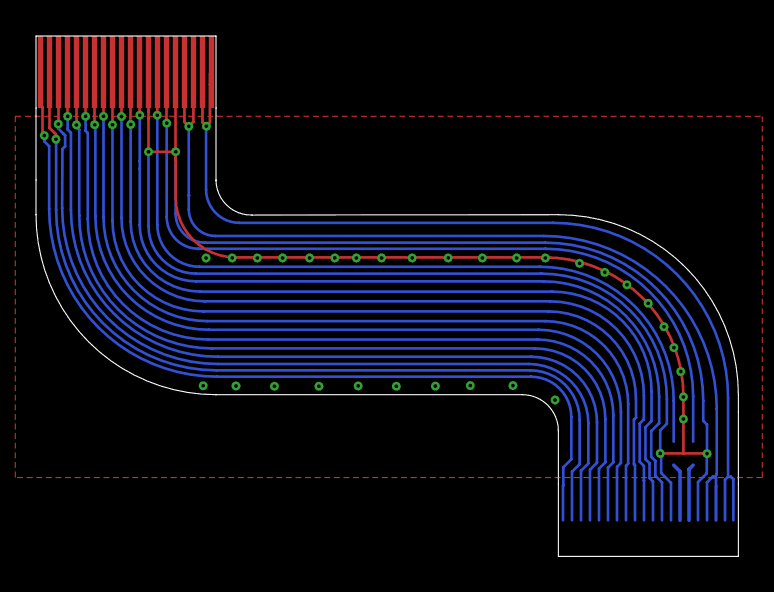
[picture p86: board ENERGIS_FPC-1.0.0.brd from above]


Board: 2 copper layers, 39.0 x 28.9 mm, 4 parts (3 on the bottom side), 19 nets.

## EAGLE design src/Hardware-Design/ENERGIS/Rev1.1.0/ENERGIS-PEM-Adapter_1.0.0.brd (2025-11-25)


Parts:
L1, L2, L3, L4: FASTON-1217861-1; 1217861-1
N1, N2, N3, N4: FASTON-1217861-1; 1217861-1
PE1, PE2: FASTON-1217861-1; 1217861-1
PEM1: 3-104-370

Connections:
AGND: PE1.1, PE1.2, PE2.1, PE2.2, PEM1.A2 (PE), PEM1.B2 (PE), PEM1.C2 (PE), PEM1.D2 (PE)
L1: L1.1, L1.2, PEM1.A3 (L)
L2: L2.1, L2.2, PEM1.B3 (L)
L3: L4.1, L4.2, PEM1.C3 (L)
L4: L3.1, L3.2, PEM1.D3 (L)
N1: N1.1, N1.2, PEM1.A1 (N)
N2: N2.1, N2.2, PEM1.B1 (N)
N3: N3.1, N3.2, PEM1.C1 (N)
N4: N4.1, N4.2, PEM1.D1 (N)

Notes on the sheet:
PEM-Adapter Board
PEM-Adapter
4X IEC C13 POWER ENTRY MODULE

Board: 2 copper layers, 15 parts (12 on the bottom side), 9 nets, no tracks yet.

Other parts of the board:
U$1, U$2: DNI; DMT
U$3, U$4: DNI; ROHS_LOGO_0.18_IN

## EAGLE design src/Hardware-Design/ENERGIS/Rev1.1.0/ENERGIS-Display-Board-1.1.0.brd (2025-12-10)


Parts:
C5, C6, C11, C12: 100nF 25V; 0402
CH1, CH2, CH3, CH4, CH5, CH6, CH7, CH8: Green; LED-0805
IC1, IC2: MCP23017T-E/ML; QFN28[6X6]ML
LED1: GREEN; LED3MM
LED2: BLUE; LED3MM
LED3: RED; LED3MM
R7, R10, R11: 1K 1%; 0402
R8, R9, R14, R15: 1K 1%; _0603X4-1206
SEL1, SEL2, SEL3, SEL4, SEL5, SEL6, SEL7, SEL8: Orange; LED-0805

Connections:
+3V3: C5.1, C6.1, C11.1, C12.1, IC1.5 (VDD), IC1.11 (A0), IC2.5 (VDD), IC2.11 (A0), IC2.12 (A1); also elsewhere on the board
GND: C5.2, C6.2, C11.2, C12.2, CH1.C, CH2.C, CH3.C, CH4.C, CH5.C, CH6.C, CH7.C, CH8.C, IC1.6 (VSS), IC1.12 (A1), IC1.13 (A2), IC1.PAD (VSS), IC2.6 (VSS), IC2.13 (A2), IC2.PAD (VSS), LED1.K (C), LED2.K (C), LED3.K (C), SEL1.C, SEL2.C, SEL3.C, SEL4.C, SEL5.C, SEL6.C, SEL7.C, SEL8.C; also elsewhere on the board
I2C0_SCL: IC1.8 (SCL), IC2.8 (SCL); also elsewhere on the board
I2C0_SDA: IC1.9 (SDA), IC2.9 (SDA); also elsewhere on the board
MCP_LCD_RST: IC1.14 (!RESET), IC2.14 (!RESET); also elsewhere on the board
unnamed: IC2.17 (IO1.0), R14.D1 (4)
unnamed: IC2.18 (IO1.1), R14.C1 (3)
unnamed: IC2.19 (IO1.2), R14.B1 (2)
unnamed: IC2.20 (IO1.3), R14.A1 (1)
unnamed: IC2.21 (IO1.4), R15.D1 (4)
unnamed: IC2.22 (IO1.5), R15.C1 (3)
unnamed: IC2.23 (IO1.6), R15.B1 (2)
unnamed: IC2.24 (IO1.7), R15.A1 (1)
unnamed: R14.D2 (5), SEL1.A
unnamed: R14.C2 (6), SEL2.A
unnamed: R14.B2 (7), SEL3.A
unnamed: R14.A2 (8), SEL4.A
unnamed: R15.D2 (5), SEL5.A
unnamed: R15.C2 (6), SEL6.A
unnamed: R15.B2 (7), SEL7.A
unnamed: R15.A2 (8), SEL8.A
unnamed: IC1.26 (IO2.1), R10.1
unnamed: IC1.27 (IO2.2), R7.1
unnamed: IC1.25 (IO2.0), R11.1
unnamed: IC1.17 (IO1.0), R8.D1 (4)
unnamed: IC1.18 (IO1.1), R8.C1 (3)
unnamed: IC1.19 (IO1.2), R8.B1 (2)
unnamed: IC1.20 (IO1.3), R8.A1 (1)
unnamed: IC1.21 (IO1.4), R9.D1 (4)
unnamed: IC1.22 (IO1.5), R9.C1 (3)
unnamed: IC1.23 (IO1.6), R9.B1 (2)
unnamed: IC1.24 (IO1.7), R9.A1 (1)
unnamed: CH1.A, R8.D2 (5)
unnamed: CH2.A, R8.C2 (6)
unnamed: CH3.A, R8.B2 (7)
unnamed: CH4.A, R8.A2 (8)
unnamed: CH5.A, R9.D2 (5)
unnamed: CH6.A, R9.C2 (6)
unnamed: CH7.A, R9.B2 (7)
unnamed: CH8.A, R9.A2 (8)
unnamed: LED3.A, R11.2
unnamed: LED2.A, R10.2
unnamed: LED1.A, R7.2

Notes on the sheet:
DISPLAY LEDS
SELECTION LEDS
IO DRIVERS
DISPLAY BOARD


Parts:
3V3, 5V: DNI; TP-ROUND
BL: DNI; TP-ROUND
C1, C2, C3, C4: DNI; C0402
CON1: DNI; FPC40_3.5TFT
CON2: AFC11-S20ICC-00; FPC20
CS: DNI; TP-ROUND
D5: RCLAMP0582BQTCT; SC75
DSP: DNI; 1X4
GND: DNI; TP-ROUND
H1, H2, H3: DNI; 3,2-PAD
MISO: DNI; TP-ROUND
MOSI: DNI; TP-ROUND
R1, R2, R3, R4: DNI; 0402
SCK: DNI; TP-ROUND
SCL0: DNI; TP-ROUND
SDA0: DNI; TP-ROUND
T1: DNI; SOT23

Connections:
+3V3: 3V3.TP, C1.1, C2.1, C3.1, C4.1, CON1.6, CON1.7, CON1.12, CON1.38, CON1.39, CON1.40, CON2.1, CON2.2, DSP.2; also elsewhere on the board
+5V: 5V.TP, CON1.33, CON2.3, CON2.4
GND: C1.2, C2.2, C3.2, C4.2, CON1.5, CON1.16, CON1.17, CON1.18, CON1.19, CON1.20, CON1.21, CON1.22, CON1.23, CON1.24, CON1.25, CON1.26, CON1.27, CON1.28, CON1.29, CON1.30, CON1.31, CON1.32, CON1.37, CON1.Z1, CON1.Z2, CON2.5, CON2.8, CON2.Z0 (Z1), CON2.Z1, CON2.Z2, CON2.Z3, CON2.Z4 (Z3), CON2.Z5 (Z4), D5.3, DSP.1, GND.TP, H1.B3,2, H2.B3,2, H3.B3,2, R4.2, T1.2 (S); also elsewhere on the board
I2C0_SCL: CON2.7, D5.1, DSP.3, SCL0.TP; also elsewhere on the board
I2C0_SDA: CON2.6, D5.2, DSP.4, SDA0.TP; also elsewhere on the board
KEY_0: CON2.12; also elsewhere on the board
KEY_1: CON2.11; also elsewhere on the board
KEY_2: CON2.10; also elsewhere on the board
KEY_3: CON2.9; also elsewhere on the board
LCD_BL: BL.TP, CON2.13, R4.1, T1.1 (G)
LCD_CS: CON1.9, CON2.19, CS.TP
LCD_DC: CON1.10, CON2.18
LCD_MISO: CON1.14, CON2.15, MISO.TP
LCD_MOSI: CON1.13, CON2.16, MOSI.TP
LCD_RES: CON1.15, CON2.14
LCD_SCLK: CON1.11, CON2.17, SCK.TP
MCP_LCD_RST: CON2.20; also elsewhere on the board
unnamed: CON1.35, R2.2
unnamed: CON1.36, R3.2
unnamed: R1.1, R2.1, R3.1, T1.3 (D)
unnamed: CON1.34, R1.2

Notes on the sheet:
3.5-IN LCD
BOARD CONNECTOR
I2C DISPLAY
TESTPOINTS
BSS138
10K
CONNECTORS
DISPLAY BOARD


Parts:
<: TS-1002S-04326C; PUSHBUTTON-6X6
>: TS-1002S-04326C; PUSHBUTTON-6X6
C7, C8, C9, C10: 100nF 25V; 0402
D1, D2, D3, D4: PTVS3V3S1UR,115; SOD-123
O: TS-1002S-04326C; PUSHBUTTON-6X6
PWR: TS-1002S-04326C; PUSHBUTTON-6X6
R5, R6, R12, R13: 10K 1%; 0402
R16, R17, R18, R19: 0R 1%; 0402

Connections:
+3V3: R5.1, R6.1, R12.1, R13.1; also elsewhere on the board
GND: <.1, <.2, >.1, >.2, C7.2, C8.2, C9.2, C10.2, D1.A, D2.A, D3.A, D4.A, O.1, O.2, PWR.1, PWR.2; also elsewhere on the board
KEY_0: C7.1, R5.2, R16.2; also elsewhere on the board
KEY_1: C8.1, R6.2, R17.2; also elsewhere on the board
KEY_2: C9.1, R12.2, R18.2; also elsewhere on the board
KEY_3: C10.1, R13.2, R19.2; also elsewhere on the board
unnamed: <.3, <.4, D2.C, R16.1
unnamed: D3.C, O.3, O.4, R18.1
unnamed: D4.C, PWR.3, PWR.4, R19.1
unnamed: >.3, >.4, D1.C, R17.1

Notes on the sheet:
PUSHBUTTONS
DISPLAY BOARD



Board: 4 copper layers, 124.0 x 28.0 mm, 83 parts (32 on the bottom side), 63 nets.

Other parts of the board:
U$1, U$5: DNI; DMT
U$8: DNI; CE-4MM
U$9: DNI; ROHS_LOGO_0.18_IN
U$10: DNI; NO_PB_LOGO_0.120

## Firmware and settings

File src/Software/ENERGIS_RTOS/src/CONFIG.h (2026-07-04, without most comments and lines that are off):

#define CONFIG_H
#include "FreeRTOS.h"
#include "event_groups.h"
#include "pico/bootrom.h"
#include "pico/multicore.h"
#include "pico/stdlib.h"
#include "queue.h"
#include "semphr.h"
#include "task.h"
#include "timers.h"
#include <ctype.h>
#include <math.h>
#include <stdarg.h>
#include <stdbool.h>
#include <stdint.h>
#include <stdio.h>
#include <stdlib.h>
#include <string.h>
#include "ERROR_CODE.h"
#include "hardware/adc.h"
#include "hardware/clocks.h"
#include "hardware/gpio.h"
#include "hardware/i2c.h"
#include "hardware/irq.h"
#include "hardware/pwm.h"
#include "hardware/spi.h"
#include "hardware/structs/vreg_and_chip_reset.h"
#include "hardware/structs/watchdog.h"
#include "hardware/sync.h"
#include "hardware/uart.h"
#include "hardware/watchdog.h"
#include "misc/EEPROM_MemoryMap.h"
#include "misc/helpers.h"
#include "misc/crashlog.h"
#include "misc/rtos_hooks.h"
#include "misc/power_mgr.h"
#include "drivers/i2c_bus.h"
#include "drivers/CAT24C256_driver.h"
#include "drivers/MCP23017_driver.h"
#include "drivers/button_driver.h"
#include "drivers/HLW8032_driver.h"
#include "drivers/ethernet_config.h"
#include "drivers/ethernet_driver.h"
#include "drivers/ethernet_w5500regs.h"
#include "drivers/snmp.h"
#include "drivers/socket.h"
#include "snmp/snmp_custom.h"
#include "snmp/snmp_networkCtrl.h"
#include "snmp/snmp_outletCtrl.h"
#include "snmp/snmp_powerMon.h"
#include "snmp/snmp_voltageMon.h"
#include "tasks/storage_submodule/calibration.h"
#include "tasks/storage_submodule/channel_labels.h"
#include "tasks/storage_submodule/device_identity.h"
#include "tasks/storage_submodule/energy_monitor.h"
#include "tasks/storage_submodule/event_log.h"
#include "tasks/storage_submodule/factory_defaults.h"
#include "tasks/storage_submodule/network.h"
#include "tasks/storage_submodule/storage_common.h"
#include "tasks/storage_submodule/user_output.h"
#include "tasks/storage_submodule/user_prefs.h"
#include "tasks/storage_submodule/auth_store.h"
#include "tasks/provisioning_commands.h"
#include "tasks/OCP.h"
#include "tasks/SwitchTask.h"
#include "tasks/ConsoleTask.h"
#include "tasks/ButtonTask.h"
#include "tasks/LoggerTask.h"
#include "tasks/NetTask.h"
#include "tasks/StorageTask.h"
#include "tasks/MeterTask.h"
#include "tasks/InitTask.h"
#include "tasks/HealthTask.h"
#include "web_handlers/control_handler.h"
#include "web_handlers/http_server.h"
#include "web_handlers/page_content.h"
#include "web_handlers/preset_handler.h"
#include "web_handlers/settings_handler.h"
#include "web_handlers/status_handler.h"
#include "web_handlers/metrics_handler.h"
#include "web_handlers/auth.h"
extern w5500_NetConfig eth_netcfg;
#define LONGPRESS_DT 2500
#define DEBOUNCE_MS 100u
#define POST_GUARD_MS (DEBOUNCE_MS + 10u)
#define CFG_ENABLE_METRICS 1
#define SWITCH_DISPLAY_STRICT 1
#define ENERGIS_DEFAULT_IP {192, 168, 0, 22}
#define ENERGIS_DEFAULT_SN {255, 255, 255, 0}
#define ENERGIS_DEFAULT_GW {192, 168, 0, 1}
#define ENERGIS_DEFAULT_DNS {8, 8, 8, 8}
#define HARDWARE_VERSION "1.1.0"
#define HARDWARE_VERSION_LITERAL 110
#define FIRMWARE_VERSION "1.1.0"
#define FIRMWARE_VERSION_LITERAL 110
#define ENERGIS_VARIANT_19IN
#define CURRENT_LIMIT_EU_A 15.0f
#define CURRENT_LIMIT_US_A 20.0f
#define CURRENT_LIMIT_DEFAULT_A 15.0f
#define ENERGIS_CURRENT_SAFETY_MARGIN_A 0.5f
#define ENERGIS_CURRENT_WARNING_OFFSET_A 1.0f
#define ENERGIS_CURRENT_RECOVERY_OFFSET_A 1.5f
#define SWVERSION FIRMWARE_VERSION
#define SW_REV FIRMWARE_VERSION_LITERAL
#define HW_REV HARDWARE_VERSION_LITERAL
#define DEFAULT_NAME "ENERGIS-" FIRMWARE_VERSION
#define DEFAULT_LOCATION "Location"
#define EEPROM_SIZE 0x8000
#define LOGGER_STACK_SIZE 1024
#define LOGGER_QUEUE_LEN 64
#define LOGGER_MSG_MAX 128
#define NOMINAL_SHUNT 0.002f
#define NOMINAL_R1 1880000.0f
#define NOMINAL_R2 1000.0f
#define ENERGIS_DEFAULT_DHCP EEPROM_NETINFO_STATIC
#define ENERGIS_MAC_PREFIX0 0x02
#define ENERGIS_MAC_PREFIX1 0x45
#define ENERGIS_MAC_PREFIX2 0x4E
#define DEBUG 1
#define DEBUG_HEALTH 0
#define INFO 1
#define INFO_HEALTH 0
#define PLOT_EN 0
#define NETLOG 0
#define UART_IFACE 1
#define ERROR 1
#define WARNING 1
#if DEBUG
#define DEBUG_PRINT(...) log_printf("\t[DEBUG] " __VA_ARGS__)
#else
#define DEBUG_PRINT(...) ((void)0)
#endif
#if DEBUG_HEALTH
#define DEBUG_PRINT_HEALTH(...) log_printf("\t[HEALTH] " __VA_ARGS__)
#else
#define DEBUG_PRINT_HEALTH(...) ((void)0)
#endif
#if INFO_HEALTH
#define HEALTH_INFO(...) log_printf("[INFO] " __VA_ARGS__)
#else
#define HEALTH_INFO(...) ((void)0)
#endif
#if INFO
#define INFO_PRINT(...) log_printf("[INFO] " __VA_ARGS__)
#else
#define INFO_PRINT(...) ((void)0)
#endif
#if ERROR
#define ERROR_PRINT(...) (Switch_SetFaultLed(true, 10), log_printf_force("[ERROR] " __VA_ARGS__))
#else
#define ERROR_PRINT(...) ((void)0)
#endif
#if ERROR && DEBUG
#define ERROR_PRINT_DEBUG(...) log_printf("[ERROR] " __VA_ARGS__)
#else
#define ERROR_PRINT_DEBUG(...) ((void)0)
#endif
#if WARNING
#define WARNING_PRINT(...) log_printf_force("[WARNING] " __VA_ARGS__)
#else
#define WARNING_PRINT(...) ((void)0)
#endif
#if PLOT_EN
#define PLOT(...) log_printf("\t[PLOT] " __VA_ARGS__)
#else
#define PLOT(...) ((void)0)
#endif
#if NETLOG
#define NETLOG_PRINT(...) log_printf("[NETLOG] " __VA_ARGS__)
#else
#define NETLOG_PRINT(...) ((void)0)
#endif
#if UART_IFACE
#define ECHO(...) log_printf("\t[ECHO] " __VA_ARGS__)
#else
#define ECHO(...) ((void)0)
#endif
#define I2C0_SPEED 400000                           // 400 kHz fast mode
#define I2C1_SPEED 400000                           // 400 kHz fast mode
#define EEPROM_I2C i2c1                             // Using I2C1 for EEPROM communication
#define MCP23017_RELAY_I2C i2c1                     // Using I2C1 for Relay Board MCP23017
#define MCP23017_DISPLAY_I2C i2c0                   // Using I2C0 for Display Board MCP23017
#define MCP23017_SELECTION_I2C MCP23017_DISPLAY_I2C // Using I2C0 for Selection Row MCP23017
#define SPI_SPEED_W5500 40000000 // 40 MHz
#define W5500_SPI_INSTANCE spi0  // SPI0 for Ethernet
#define UART_ID uart1
#define BAUD_RATE 115200
#define UART_CMD_BUF_LEN 1024
#define UART_MAX_LINES 4
#define HLW8032_UART_ID uart0
#define HLW8032_BAUDRATE 4800
#define HLW8032_FRAME_LENGTH 24
#define NUM_CHANNELS 8
#define POLL_INTERVAL_MS 6000u
#define TX_CH1 0
#define TX_CH2 1
#define TX_CH3 2
#define TX_CH4 3
#define TX_CH5 4
#define TX_CH6 5
#define TX_CH7 6
#define TX_CH8 7
#define VREG_BASE 0x40064000
#define VREG_VSEL_MASK 0x7
#define UART0_RX 0
#define UART0_TX 1
#define I2C1_SDA 2
#define I2C1_SCL 3
#define I2C0_SDA 4
#define I2C0_SCL 5
#define GPIO6 6   // Not used anymore
#define GPIO7 7   // Not used anymore
#define GPIO8 8   // Not used anymore
#define GPIO9 9   // Not used anymore
#define GPIO10 10 // Not used anymore
#define GPIO11 11 // Not used anymore
#define KEY_0 12
#define KEY_1 13
#define KEY_2 14
#define KEY_3 15
#define BUT_PLUS KEY_1
#define BUT_MINUS KEY_0
#define BUT_SET KEY_2
#define BUT_PWR KEY_3
#define W5500_MISO 16
#define W5500_CS 17
#define W5500_SCK 18
#define W5500_MOSI 19
#define W5500_RESET 20
#define W5500_INT 21
#define FAN_CTRL 22 // Fan control (not used)
#define MCP_MB_RST 23
#define MCP_DP_RST 24
#define VREG_EN 25
#define ADC_VUSB 26
#define NC 27 // ADC Temp sensor (not used)
#define PROC_LED 28
#define ADC_12V_MEA 29
#define ADC_VREF 3.0f
#define ADC_MAX 4096.0f
#define ADC_TOL 1.005f // +0.5% correction factor
#define V_USB 0
#define V_SUPPLY 3
#define TEMP_SENSOR 4
#define VBUS_DIVIDER 2.0f
#define SUPPLY_DIVIDER 11.0f
#define MCP_RELAY_ADDR 0x20 // 0b0100000
#define REL_0 0
#define REL_1 1
#define REL_2 2
#define REL_3 3
#define REL_4 4
#define REL_5 5
#define REL_6 6
#define REL_7 7
#define MUX_A 8
#define MUX_B 9
#define MUX_C 10
#define MUX_EN 11
#define MCP_DISPLAY_ADDR 0x21 // 0b0100001
#define OUT_1 0
#define OUT_2 1
#define OUT_3 2
#define OUT_4 3
#define OUT_5 4
#define OUT_6 5
#define OUT_7 6
#define OUT_8 7
#define FAULT_LED 8
#define ETH_LED 9
#define PWR_LED 10
#define MCP_SELECTION_ADDR 0x23
#define SEL_1 0
#define SEL_2 1
#define SEL_3 2
#define SEL_4 3
#define SEL_5 4
#define SEL_6 5
#define SEL_7 6
#define SEL_8 7

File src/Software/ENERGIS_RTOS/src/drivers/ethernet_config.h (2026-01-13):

/**
 * @file drivers/ethernet_config.h
 * @author DvidMakesThings - David Sipos
 *
 * @defgroup config02 2. W5500 Ethernet Configuration
 * @ingroup config
 * @brief Centralized configuration parameters for W5500 Ethernet controller.
 * @{
 *
 * @version 1.0.0
 * @date 2025-11-06
 *
 * @details
 * This file centralizes all configuration for the W5500 Ethernet controller used in
 * the ENERGIS PDU. Configuration includes:
 * - Hardware pin assignments and SPI settings
 * - Socket memory buffer allocation (16KB TX + 16KB RX total)
 * - Network parameters (IP, MAC, gateway, subnet)
 * - Protocol support flags (TCP, UDP, SNMP, ICMP)
 * - RTOS task and synchronization parameters
 * - Advanced TCP/IP tuning parameters
 *
 * Socket Buffer Strategy:
 * The W5500 provides 16KB each for TX and RX buffers, distributed across 8 sockets.
 * Current allocation prioritizes HTTP server (Socket 0) and SNMP (Socket 1).
 *
 * Configuration Philosophy:
 * - All hardware-specific values come from CONFIG.h
 * - Runtime-changeable parameters (IP, MAC) have defaults
 * - Compile-time validation prevents buffer overallocation
 *
 * @project ENERGIS - The Managed PDU Project for 10-Inch Rack
 * @github https://github.com/DvidMakesThings/HW_10-In-Rack_PDU
 */

#ifndef W5500_CONFIG_H
#define W5500_CONFIG_H

#include "../CONFIG.h"

/**
 * @defgroup W5500_HW Hardware Pin Configuration
 * @brief SPI peripheral and GPIO pin assignments from CONFIG.h
 * @{
 */

/** @name Hardware Pins
 *  Constants for SPI and GPIO assignments.
 *  @{ */

/** SPI peripheral instance used for W5500 communication */
#define W5500_SPI W5500_SPI_INSTANCE

/** SPI clock frequency in Hz (typically 10-33 MHz) */
#define W5500_SPI_CLOCK SPI_SPEED_W5500

/** SPI MOSI (Master Out Slave In) GPIO pin */
#define W5500_PIN_MOSI W5500_MOSI

/** SPI MISO (Master In Slave Out) GPIO pin */
#define W5500_PIN_MISO W5500_MISO

/** SPI SCK (Serial Clock) GPIO pin */
#define W5500_PIN_SCK W5500_SCK

/** SPI CS (Chip Select, active low) GPIO pin */
#define W5500_PIN_CS W5500_CS

/** Hardware reset GPIO pin (active low) */
#define W5500_PIN_RST W5500_RESET

/** Interrupt GPIO pin (active low, optional) */
#define W5500_PIN_INT W5500_INT

/** @} */

/** @} */

/**
 * @defgroup W5500_MEM Socket Memory Allocation
 * @brief TX/RX buffer sizes for each socket (total 16KB per direction)
 * @{
 */

/** @name Socket Memory Sizes
 *  Per-socket TX/RX buffer allocations (KB).
 *  @{ */

/**
 * @brief Number of hardware sockets available
 */
#define W5500_SOCKET_COUNT 8

/** Socket 0 TX buffer size in KB (HTTP server, primary) */
#define W5500_TX_SIZE_S0 8

/** Socket 1 TX buffer size in KB (SNMP) */
#define W5500_TX_SIZE_S1 8

/** Socket 2 TX buffer size in KB (unused) */
#define W5500_TX_SIZE_S2 0

/** Socket 3 TX buffer size in KB (unused) */
#define W5500_TX_SIZE_S3 0

/** Socket 4 TX buffer size in KB (unused) */
#define W5500_TX_SIZE_S4 0

/** Socket 5 TX buffer size in KB (unused) */
#define W5500_TX_SIZE_S5 0

/** Socket 6 TX buffer size in KB (unused) */
#define W5500_TX_SIZE_S6 0

/** Socket 7 TX buffer size in KB (unused) */
#define W5500_TX_SIZE_S7 0

/** Socket 0 RX buffer size in KB (HTTP server, primary) */
#define W5500_RX_SIZE_S0 8

/** Socket 1 RX buffer size in KB (SNMP) */
#define W5500_RX_SIZE_S1 8

/** Socket 2 RX buffer size in KB (unused) */
#define W5500_RX_SIZE_S2 0

/** Socket 3 RX buffer size in KB (unused) */
#define W5500_RX_SIZE_S3 0

/** Socket 4 RX buffer size in KB (unused) */
#define W5500_RX_SIZE_S4 0

/** Socket 5 RX buffer size in KB (unused) */
#define W5500_RX_SIZE_S5 0

/** Socket 6 RX buffer size in KB (unused) */
#define W5500_RX_SIZE_S6 0

/** Socket 7 RX buffer size in KB (unused) */
#define W5500_RX_SIZE_S7 0

/** @} */

/** @} */

/**
 * @defgroup W5500_NET Network Configuration Defaults
 * @brief Default network parameters (overrideable at runtime)
 * @{
 */

/** @name Network Defaults
 *  Default MAC/IP/subnet/gateway/DNS settings.
 *  @{ */

/** Default MAC address (Locally Administered) */
#define W5500_DEFAULT_MAC {0x02, 0x00, 0x00, 0x12, 0x34, 0x56}

/** Default static IP address */
#define W5500_DEFAULT_IP {192, 168, 0, 12}

/** Default subnet mask */
#define W5500_DEFAULT_SUBNET {255, 255, 255, 0}

/** Default gateway address */
#define W5500_DEFAULT_GATEWAY {192, 168, 0, 1}

/** Default DNS server address (Google DNS) */
static const uint8_t W5500_DEFAULT_DNS[4] = {8, 8, 8, 8};

/** Enable DHCP (0=static IP, 1=DHCP) */
#define W5500_USE_DHCP 0

/** @} */

/** @} */

/**
 * @defgroup W5500_PROTO Protocol Support Flags
 * @brief Enable/disable protocol features
 * @{
 */

/** @name Protocol Flags
 *  Enable/disable supported protocols.
 *  @{ */

/** Enable TCP protocol support */
#define W5500_ENABLE_TCP 1

/** Enable UDP protocol support */
#define W5500_ENABLE_UDP 1

/** Enable SNMP protocol support */
#define W5500_ENABLE_SNMP 1

/** Enable ICMP (ping) support */
#define W5500_ENABLE_ICMP 1
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

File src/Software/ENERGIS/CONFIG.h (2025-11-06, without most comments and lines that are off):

#define CONFIG_H
#define USBD_MANUFACTURER "DvidMakesThings"
#define USBD_PRODUCT "ENERGIS"
#define USBD_SERIALNUMBER SERIAL_NUMBER
#define USBD_STR_CDC_NAME "ENERGIS USB Serial"
#include "hardware/adc.h"
#include "hardware/address_mapped.h"
#include "hardware/clocks.h"
#include "hardware/gpio.h"
#include "hardware/irq.h"
#include "hardware/resets.h"
#include "hardware/spi.h"
#include "hardware/watchdog.h"
#include "misc/uart_command_handler.h"
#include "network/snmp_custom.h"
#include "pico/bootrom.h"
#include "pico/multicore.h"
#include "pico/stdlib.h"
#include "pico/time.h"
#include <stdbool.h>
#include <stdint.h>
#include <stdio.h>
#include <string.h>
#include "ENERGIS_core1_task.h"
#include "network/socket.h"
#include "network/w5x00_spi.h"
#include "network/wizchip_conf.h"
#include "serial_number.h"
#include "ENERGIS_startup.h"
#include "drivers/CAT24C512_driver.h"
#include "drivers/HLW8032_driver.h"
#include "drivers/MCP23017_display_driver.h"
#include "drivers/MCP23017_dual_driver.h"
#include "drivers/MCP23017_relay_driver.h"
#include "drivers/MCP23017_selection_driver.h"
#include "drivers/button_driver.h"
#include "utils/EEPROM_MemoryMap.h"
#include "utils/helper_functions.h"
#include "web_handlers/form_helpers.h"
#define HAS_SCREEN 0
#define LONGPRESS_DT 2500
#define DEBOUNCE_MS 100u
#define POST_GUARD_MS (DEBOUNCE_MS + 10u)
#define BTN_LOG_ENABLE 1
#define DUAL_GUARD_INTERVAL_MS 50u
#define DUAL_GUARD_MASK 0x00FFu
#define DUAL_GUARD_AUTOHEAL 1
#define DEFAULT_SN SERIAL_NUMBER
#define SWVERSION FIRMWARE_VERSION
#define SW_REV FIRMWARE_VERSION_LITERAL
#define DEFAULT_NAME "ENERGIS-" FIRMWARE_VERSION
#define DEFAULT_LOCATION "Location"
#pragma once
#define DEBUG 0
#define INFO 1
#define ERROR 1
#define WARNING 1
#define PLOT_EN 0
#define NETLOG 0
#define UART_IFACE 1
#if DEBUG
#define DEBUG_PRINT(...) printf("\t[DEBUG] " __VA_ARGS__)
#else
#define DEBUG_PRINT(...) ((void)0)
#endif
#if INFO
#define INFO_PRINT(...) printf("[INFO] " __VA_ARGS__)
#else
#define INFO_PRINT(...) ((void)0)
#endif
#if ERROR
#define ERROR_PRINT(...) printf("[ERROR] " __VA_ARGS__)
#else
#define ERROR_PRINT(...) ((void)0)
#endif
#if WARNING
#define WARNING_PRINT(...) printf("[WARNING] " __VA_ARGS__)
#else
#define WARNING_PRINT(...) ((void)0)
#endif
#if PLOT_EN
#define PLOT(...) printf("\t[PLOT] " __VA_ARGS__)
#else
#define PLOT(...) ((void)0)
#endif
#if NETLOG
#define NETLOG_PRINT(...) printf("[NETLOG] " __VA_ARGS__)
#else
#define NETLOG_PRINT(...) ((void)0)
#endif
#if UART_IFACE
#define ECHO(...) printf("\t[ECHO] " __VA_ARGS__)
#else
#define ECHO(...) ((void)0)
#endif
#define I2C_SPEED 100000                            ///< 100 kHz standard mode
#define EEPROM_I2C i2c1                             ///< Using I2C1 for EEPROM communication
#define MCP23017_RELAY_I2C i2c1                     ///< Using I2C0 for Relay Board MCP23017
#define MCP23017_DISPLAY_I2C i2c0                   ///< Using I2C0 for Display Board MCP23017
#define MCP23017_SELECTION_I2C MCP23017_DISPLAY_I2C ///< Using I2C0 for Selection Row MCP23017
#define SPI_SPEED_W5500 40000000  // 40MHz
#define ILI9488_SPI_INSTANCE spi1 ///< SPI1 for ILI9488 Display
#define W5500_SPI_INSTANCE spi0   ///< SPI0 for W5500 Ethernet Modul
#define UART_ID uart1
#define BAUD_RATE 115200
#define UART_CMD_BUF_LEN 1024
#define UART_MAX_LINES 4
#define HLW8032_UART_ID uart0
#define HLW8032_BAUDRATE 4800
#define HLW8032_FRAME_LENGTH 24
#define NUM_CHANNELS 8
#define POLL_INTERVAL_MS 6000u
#define VREG_BASE 0x40064000
#define VREG_VSEL_MASK 0x7
#define UART0_RX 0
#define UART0_TX 1
#define I2C1_SDA 2
#define I2C1_SCL 3
#define I2C0_SDA 4
#define I2C0_SCL 5
#define LCD_DC 6
#define LCD_BL 7
#define LCD_MISO 8  // spi1 rx
#define LCD_CS 9    // spi1 csn
#define LCD_SCLK 10 // spi1 sck
#define LCD_MOSI 11 // spi1 tx
#define KEY_0 12
#define KEY_1 13
#define KEY_2 14
#define KEY_3 15
#define BUT_PLUS KEY_1
#define BUT_MINUS KEY_0
#define BUT_SET KEY_2
#define BUT_PWR KEY_3
#define W5500_MISO 16
#define W5500_CS 17
#define W5500_SCK 18
#define W5500_MOSI 19
#define W5500_RESET 20
#define W5500_INT 21
#define LCD_RESET 22
#define MCP_REL_RST 23
#define MCP_LCD_RST 24
#define VREG_EN 25
#define ADC_VUSB 26
#define NC 27
#define PROC_LED 28
#define ADC_12V_MEA 29
#define ADC_VREF 3.00f
#define ADC_MAX 4096.0f
#define ADC_TOL 1.005f // +0.5% correction factor
#define V_USB 0
#define V_SUPPLY 3
#define TEMP_SENSOR 4
#define MCP_RELAY_ADDR 0x20 // 0b0100000
#define REL_0 0
#define REL_1 1
#define REL_2 2
#define REL_3 3
#define REL_4 4
#define REL_5 5
#define REL_6 6
#define REL_7 7
#define MUX_A 8
#define MUX_B 9
#define MUX_C 10
#define MUX_EN 11
#define MCP_DISPLAY_ADDR 0x21 // 0b0100001
#define OUT_1 0
#define OUT_2 1
#define OUT_3 2
#define OUT_4 3
#define OUT_5 4
#define OUT_6 5
#define OUT_7 6
#define OUT_8 7
#define FAULT_LED 8
#define ETH_LED 9
#define PWR_LED 10
#define MCP_SELECTION_ADDR 0x23
#define MCP_SEL_RST MCP_LCD_RST
#define SEL_1 0
#define SEL_2 1
#define SEL_3 2
#define SEL_4 3
#define SEL_5 4
#define SEL_6 5
#define SEL_7 6
#define SEL_8 7
#define TX_MUX_1 0
#define TX_MUX_2 1
#define TX_MUX_3 2
#define TX_MUX_4 3
#define TX_MUX_5 4
#define TX_MUX_6 5
#define TX_MUX_7 6
#define TX_MUX_8 7
#define UART_MUX_Y UART0_TX
#define MUX_SELECT_A MUX_A
#define MUX_SELECT_B MUX_B
#define MUX_SELECT_C MUX_C
#define MUX_ENABLE MUX_EN
#define TX_CH1 0
#define TX_CH2 1
#define TX_CH3 2
#define TX_CH4 3
#define TX_CH5 4
#define TX_CH6 5
#define TX_CH7 6
#define TX_CH8 7
#if HAS_SCREEN
#define ILI9488_CMD_SLEEP_OUT 0x11
#define ILI9488_CMD_DISPLAY_ON 0x29
#define ILI9488_CMD_COLUMN_ADDR 0x2A
#define ILI9488_CMD_PAGE_ADDR 0x2B
#define ILI9488_CMD_MEMORY_WRITE 0x2C
#define ILI9488_WIDTH 480  ///< Display width in pixels
#define ILI9488_HEIGHT 320 ///< Display height in pixels
#define COLOR_BLUE 0x0000FC    // (0, 0, 252)
#define COLOR_CYAN 0x00FCFC    // (0, 252, 252)
#define COLOR_GREEN 0x00FC00   // (0, 252, 0)
#define COLOR_YELLOW 0xFCFC00  // (252, 252, 0)
#define COLOR_ORANGE 0xFC8000  // (252, 128, 0)
#define COLOR_RED 0xFC0000     // (252, 0, 0)
#define COLOR_MAGENTA 0xFC00FC // (252, 0, 252)
#define COLOR_PURPLE 0x8000FC  // (128, 0, 252)
#define COLOR_BLACK 0x000000   // (0, 0, 0)
#define COLOR_WHITE 0xFCFCFC   // (252, 252, 252)
#define COLOR_DARK_BLUE 0x000066
#define COLOR_DARK_GRAY 0x050505  // Converted to 24-bit (48, 48, 48)
#define COLOR_LIGHT_GRAY 0x303030 // Converted to 24-bit (128, 128, 128)
#define COLOR_BG_PRIMARY COLOR_DARK_GRAY
#define COLOR_BG_SECONDARY COLOR_BLACK
#define COLOR_TEXT_PRIMARY COLOR_WHITE
#define COLOR_TEXT_SECONDARY COLOR_LIGHT_GRAY
#define COLOR_HIGHLIGHT COLOR_BLUE
#define COLOR_WARNING COLOR_YELLOW
#define COLOR_ERROR COLOR_RED
#endif
#define MCP23017_IODIRA 0x00   // I/O Direction Register A
#define MCP23017_IODIRB 0x01   // I/O Direction Register B
#define MCP23017_IPOLA 0x02    // Input Polarity Register A
#define MCP23017_IPOLB 0x03    // Input Polarity Register B
#define MCP23017_GPINTENA 0x04 // Interrupt-on-Change Control Register A
#define MCP23017_GPINTENB 0x05 // Interrupt-on-Change Control Register B
#define MCP23017_DEFVALA 0x06  // Default Compare Register A
#define MCP23017_DEFVALB 0x07  // Default Compare Register B
#define MCP23017_INTCONA 0x08  // Interrupt Control Register A
#define MCP23017_INTCONB 0x09  // Interrupt Control Register B
#define MCP23017_IOCON 0x0A    // Configuration Register (Bank=0)
#define MCP23017_IOCONB 0x0B   // Configuration Register (Bank=1)
#define MCP23017_GPPUA 0x0C    // Pull-up Resistor Config Register A
#define MCP23017_GPPUB 0x0D    // Pull-up Resistor Config Register B
#define MCP23017_INTFA 0x0E    // Interrupt Flag Register A
#define MCP23017_INTFB 0x0F    // Interrupt Flag Register B
#define MCP23017_INTCAPA 0x10  // Interrupt Captured Value Register A
#define MCP23017_INTCAPB 0x11  // Interrupt Captured Value Register B
#define MCP23017_GPIOA 0x12    // GPIO Register A
#define MCP23017_GPIOB 0x13    // GPIO Register B
#define MCP23017_OLATA 0x14    // Output Latch Register A
#define MCP23017_OLATB 0x15    // Output Latch Register B
#define CAT24C512_I2C_ADDR 0x50 ///< 7-bit I2C address of the EEPROM
#define EEPROM_SIZE 65536       ///< Total EEPROM size in bytes
#define CAT24C512_PAGE_SIZE 128 ///< EEPROM page write limit
extern volatile uint8_t selected_row;
extern volatile bool bootsel_requested;
extern volatile bool dump_eeprom_pending;

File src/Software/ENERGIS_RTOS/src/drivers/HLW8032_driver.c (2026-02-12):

/**
 * @file HLW8032_driver.c
 * @author DvidMakesThings - David Sipos
 *
 * @version 1.0.4
 * @date 2025-12-10
 *
 * @details RTOS-safe driver providing power measurement via HLW8032 ICs.
 *
 * Features:
 * - Thread-safe UART access via FreeRTOS mutex
 * - Hardware v1.0.0 pin swap compensation
 * - Per-channel calibration from EEPROM
 * - Cached measurements with uptime tracking
 * - Queue-based logging (no direct UART printf)
 *
 * Architecture:
 * - MeterTask is the sole owner of this driver
 * - All blocking operations use vTaskDelay() for RTOS cooperation
 * - Multiplexer control delegates to MCP23017 driver
 * - No ISRs - pure task-based polling
 *
 * @project ENERGIS - The Managed PDU Project for 10-Inch Rack
 * @github https://github.com/DvidMakesThings/HW_10-In-Rack_PDU
 */

#include "../CONFIG.h"

#define HLW8032_TAG "[HLW8032]"

/* =====================  RTOS Mutex Handle  =============================== */
SemaphoreHandle_t uartHlwMtx = NULL;

/* =====================  Frame & Bookkeeping  ============================= */
static uint8_t frame[HLW8032_FRAME_LENGTH];
static uint8_t rx_buf[MAX_RX_BYTES];
static uint32_t channel_uptime[8] = {0};
static absolute_time_t channel_last_on[8];

/* =====================  Per-Channel Calibration  ========================= */
static hlw_calib_t channel_calib[8];

/* =====================  Last Raw Registers  ============================== */
static uint32_t VolPar, VolData;
static uint32_t CurPar, CurData;
static uint32_t PowPar, PowData;
static uint16_t PF;
static uint32_t PF_Count = 1;
static uint8_t last_channel_read = 0xFF;
static uint8_t last_state_reg = 0x55; /* Track overflow flags */

/* =====================  Last Scaled Readings  ============================ */
static float last_voltage = 0.0f;
static float last_current = 0.0f;
static float last_power = 0.0f;

/* =====================  Cached Measurements  ============================= */
static float cached_voltage[8];
static float cached_current[8];
static float cached_power[8];
static uint32_t cached_uptime[8];
static bool cached_state[8];

/* =====================  Polling Helper  ================================== */
static uint8_t poll_channel = 0;

/* =====================  Total Current Sum (for Overcurrent Protection)  ===== */
static volatile float s_total_current_sum = 0.0f;
static volatile bool s_cycle_complete_flag = false;

/* ===================================================================== */
/*                        Internal Helpers (Static)                      */
/* ===================================================================== */

/* =====================  Async Calibration Forward  ======================= */

/**
 * @brief Feed one fresh HLW8032 sample into the async calibration engine.
 *
 * @param ch Channel index [0..7] that has just been read successfully.
 */
static void hlw8032_calibration_consume_sample(uint8_t ch);

/**
 * @brief Helper to query if calibration is running and fetch active channel.
 *
 * @param out_ch Pointer to receive current channel if running (optional)
 * @return true if a calibration is running, false otherwise
 */
static bool hlw8032_calibration_get_active_channel(uint8_t *out_ch);

/**
 * @brief Select HLW8032 channel via multiplexer.
 *
 * @details
 * - Disables MUX (EN=1) during transition
 * - Sets A/B/C select lines via SwitchTask -> MCP23017 Port B
 * - Hardware v1.0.0: XORs A and B bits when C=1 (upper 4 channels)
 * - Enables MUX (EN=0)
 * - Uses cooperative vTaskDelay() for settling to prevent watchdog starvation
 *
 * @param ch Logical channel index [0..7]
 */
static void mux_select(uint8_t ch) {
    ch &= 0x07;

    uint8_t a = (ch >> 0) & 1u;
    uint8_t b = (ch >> 1) & 1u;
    uint8_t c = (ch >> 2) & 1u;

#if defined(HW_REV) && (HW_REV == 100)
    /* Hardware v1.0.0: XOR A and B bits when C=1 (upper channels 4-7) */
    if (c) {
        a ^= 1u;
        b ^= 1u;
    }
#endif

    /* MUX lines are on Port B bits 0-3 */
    const uint8_t MUX_MASK = 0x0Fu;

    /* Step 1: Disable MUX (EN=1) and set address lines in ONE logical write */
    uint8_t value = (1u << 3) | /* MUX_EN = 1 (disabled, active-low) */
                    (a << 0) |  /* MUX_A */
                    (b << 1) |  /* MUX_B */
                    (c << 2);   /* MUX_C */

    if (!Switch_SetRelayPortBMasked(MUX_MASK, value, 10u)) {
#if ERRORLOGGER
        uint16_t err_code = ERR_MAKE_CODE(ERR_MOD_METER, ERR_SEV_ERROR, ERR_FID_HLW8032, 0x0);
        ERROR_PRINT_CODE(err_code, "%s Switch_SetRelayPortBMasked failed (EN=1)\r\n", HLW8032_TAG);
        Storage_EnqueueErrorCode(err_code);
#endif
        return;
    }

    /* Allow MUX lines to settle before enabling */
    vTaskDelay(pdMS_TO_TICKS(1));

    /* Step 2: Enable MUX (EN=0), keep A/B/C as-is */
    value &= (uint8_t)~(1u << 3); /* clear EN bit -> enable */

    if (!Switch_SetRelayPortBMasked(MUX_MASK, value, 10u)) {
#if ERRORLOGGER
        uint16_t err_code = ERR_MAKE_CODE(ERR_MOD_METER, ERR_SEV_ERROR, ERR_FID_HLW8032, 0x1);
        ERROR_PRINT_CODE(err_code, "%s Switch_SetRelayPortBMasked failed (EN=0)\r\n", HLW8032_TAG);
        Storage_EnqueueErrorCode(err_code);
#endif
        return;
    }

    vTaskDelay(pdMS_TO_TICKS(1));
}

/**
 * @brief Validate HLW8032 frame checksum.
 *
 * @details Checksum = sum of bytes [2..22] (inclusive).
 * Expected to match byte [23].
 *
 * @param f Pointer to 24-byte frame buffer
 * @return true if checksum valid
 */
static bool checksum_ok(const uint8_t *f) {
    uint8_t sum = 0;
    for (int i = 2; i <= 22; i++)
        sum += f[i];
    return sum == f[23];
}

/**
 * @brief Check if HLW8032 State REG indicates a valid frame.
 *
 * @details Per HLW8032 datasheet (page 12):
 * - 0x55: Normal operation, all registers valid, no overflow
 * - 0xFx (0xF0-0xFF): Normal operation, some registers overflow (value approaches 0)
 * - 0xAA: Chip error correction failed, parameters unusable
 *
 * @param state State REG value (byte 0 of frame)
 * @return true if State REG indicates valid data
 */
static bool state_reg_valid(uint8_t state) {
    /* 0x55 = all normal, 0xFx = normal with overflow flags */
    if (state == 0x55)
        return true;
    if ((state & 0xF0) == 0xF0)
        return true;
    /* 0xAA = error correction failure - reject */
    return false;
}

/**
 * @brief Safely extract uint24_t (big-endian) from frame.
 *
 * @param f Pointer to first byte
 * @return uint32_t 24-bit value as 32-bit integer
 */
static inline uint32_t extract_u24(const uint8_t *f) {
    return ((uint32_t)f[0] << 16) | ((uint32_t)f[1] << 8) | f[2];
}

/**
 * @brief Safely extract uint16_t (big-endian) from frame.
 *
 * @param f Pointer to first byte
 * @return uint16_t 16-bit value
 */
static inline uint16_t extract_u16(const uint8_t *f) { return ((uint16_t)f[0] << 8) | f[1]; }
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

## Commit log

2025-01-28 add datasheets
    [10-Inch_Rack-PDU.sch]
2025-01-29 upload PCB design
    [G2RL_1A_E.step, W5500.step]
2025-01-30 start Relay board design
    [10-Inch_Rack-PDU.sch, Controller-Board_Rack-PDU.brd, Controller-Board_Rack-PDU.sch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]
2025-01-31 add SMPS to relay board
    [Relay-Board_Rack-PDU.brd, Relay-Board_Rack-PDU.sch]
2025-01-31 finish relay board design
    [Controller-Board_Rack-PDU.brd, Controller-Board_Rack-PDU.sch, Display-Board_Rack-PDU.brd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]
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2025-01-31 first order send to JLCPCB
    [Controller-Board_DigiKey.csv, Controller-Board_Rack-PDU.brd, Controller-Board_Rack-PDU.sch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]
2025-01-31 Calculate costs, add Farnell, DigiKey BOM for missing parts
    [DisplayBoard_Farnell.csv, DisplayBoard_Farnell_Order.xlsx, RelayBoard_Farnell.csv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]
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2025-02-02 change X1, X2 because of shortage
    [Controller-Board_Rack-PDU.brd, Controller-Board_Rack-PDU.sch, Relay-Board_Rack-PDU.brd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]
2025-02-02 Update README.md - Changed number of relays on the relay board
    If I'm not completely wrong I see 8 instead of 6 relays on the relay board.
2025-02-02 Update README.md - Corrected the name of the link of the relay board 3D view
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2025-02-02 changed track with at relay output. Handles 15A max now
    [Relay-Board_Rack-PDU.brd]
2025-02-03 add enclosure design to src
    [Buttons-Elastic.3mf, Buttons-Insert.3mf, Enclosure-Body.3mf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]
2025-02-03 correct wrong divider resistor values
    [Controller-Board_Rack-PDU.brd, Controller-Board_Rack-PDU.sch]
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2025-02-04 add 3D model for for bambu printer
    [Button_base-v2.3mf, Button_insert-v2.3mf, Enclosure-BambuLab-ABS.3mf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]
2025-02-10 add DiffPairCheck to repo. Update Controller-boart to rev1.1
    [Controller-Board_Rack-PDU.brd, Controller-Board_Rack-PDU.sch, Enclosure-BambuLab-ABS.3mf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]
2025-02-16 start working on rev2.0
    [Controller-Board_Rack-PDU_1.0.brd, Controller-Board_Rack-PDU_1.0.sch, Controller-Board_Rack-PDU_top_bom.csv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]
2025-02-18 start Displayboard rev 2
    [Display-Board_Rack-PDU.brd, Display-Board_Rack-PDU.sch]
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2025-02-22 finished with design update for 2.0
    [Controller-Board_Rack-PDU_2.0.brd, Controller-Board_Rack-PDU_2.0.sch, Display-Board_Rack-PDU_2.0.brd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]
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2025-02-23 add datasheets for Rev2.0
    [Relay-Board_Rack-PDU_2.0.brd, Relay-Board_Rack-PDU_2.0.sch]
2025-02-24 update repo to Rev2.0
    [Controller-Board_Rack-PDU_2.0.brd, Controller-Board_Rack-PDU_2.0.sch, Controller-Board_Rack-PDU_2.0_top_bom.csv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]
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2025-03-04 source code - pre version. Never RP2040 or any RP series ever. Copiling to this is nightmare
    [Controller-Board_Rack-PDU_2.0.brd, Controller-Board_Rack-PDU_2.0.sch, Display-Board_Rack-PDU_2.0.brd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]
2025-03-06 correct findings
    [Controller-Board_Rack-PDU_2.0.brd, Controller-Board_Rack-PDU_2.0.sch, Display-Board_Rack-PDU_2.0.brd]
2025-03-07 I2C, SPI-DMA, EEPROM driver ready
    [Controller-Board_Rack-PDU_2.0.brd, Controller-Board_Rack-PDU_2.0.sch, Display-Board_Rack-PDU_2.0.brd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]
2025-03-09 update Relay-board to v2.1
    [Controller-Board_Rack-PDU_1.0.brd, Controller-Board_Rack-PDU_1.0.sch, Controller-Board_Rack-PDU_2.0.brd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]
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2025-03-16 add button driver and core task files; remove dummy EEPROM and update configurations
    [eeprom_dump.txt]
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2025-03-18 Creating HW release version ENERGIS Rev1.0.0 from CB1.0.21, DB1.0.30, RB1.0.21
    [Controller-Board_Rack-PDU_2.1.brd, Controller-Board_Rack-PDU_2.1.sch, Controller-Board_Rack-PDU_2.1_top_bom.csv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]
2025-05-14 Major PCB update: - Relay board combined with Controller board - SW update not possible via software-boot mode due to CDC-UART conflict: Added FT232 with USB multiplexer: Auto USB path selector - Upd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
    [Controller-Board_Rack-PDU_1.0.brd, Controller-Board_Rack-PDU_1.0.sch, Controller-Board_Rack-PDU_2.0.brd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]
2025-05-17 Add UART commands and imlement SNMP functionality
    [ENERGIS_Rack-PDU_1.0.0.brd]
2025-05-18 pico system crashed, new programming method to upload. Added overclock to 200MHz@1.15V
    [CONFIG.h, uart_command_handler.c]
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2025-05-24 fix HLW8032 driver
2025-05-24 bugfix for CH1 readings issue. Add screen update
    [CONFIG.h, HLW8032_driver.c, uart_command_handler.c]
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2025-06-10 update design to final state
    [ENERGIS_Rack-PDU_1.0.0.brd, ENERGIS_Rack-PDU_1.0.0.sch, ENERGIS_Rack-PDU_1.0.0_bom.csv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]
2025-06-23 update readme with 3D render
    [ENERGIS_Rack-PDU_1.0.0.brd, ENERGIS_Rack-PDU_1.0.0.sch]
2025-08-21 update software, bugfix
    [1.5U_ENERGIS_DispBrd_Rack-PDU_1.0.3_top_bom.csv, 1U_ENERGIS_DispBrd_Rack-PDU_1.0.3_top_bom.csv, ENERGIS_DispBrd_Rack-PDU_1.0.3.brd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]
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2025-09-05 Baseline commit. Device is functioning as expected, software is working
    [Bambulab_Enclosure.3mf, Button_base-v2.3mf, Button_insert-v2.3mf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]
2025-09-06 update files, schematics, images etc
    [Bambulab_Enclosure.3mf, Button_small.3mf, Buttons.3mf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]
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2025-09-14 Add software ESD protection to button control and port expanders. Design sheet metal shielding around electronics. Add ethernet test
    [Bambulab_Enclosure-ABS.3mf, Bambulab_Enclosure.3mf, Button_small.3mf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]
2025-09-19 add pcap tests. Small fixes
    [ENERGIS_DispBrd_Rack-PDU_1.1.0.brd, ENERGIS_DispBrd_Rack-PDU_1.1.0.sch, ENERGIS_DispBrd_Rack-PDU_1.1.0_bom.csv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]
2025-09-20 adapt design to NextPCB dru
    [ENERGIS_DispBrd_Rack-PDU_1.1.0.brd, ENERGIS_DispBrd_Rack-PDU_1.1.0.sch, ENERGIS_Rack-PDU_1.1.0.brd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]
2025-09-22 update version to 1.1.0
    [ENERGIS_DispBrd_Rack-PDU_1.1.0.brd, ENERGIS_DispBrd_Rack-PDU_1.1.0_bom.csv, ENERGIS_Rack-PDU_1.0.1_bom.csv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]
2025-09-24 update component library to NextPCB
    [ENERGIS_Rack-PDU_1.1.0.brd, ENERGIS_Rack-PDU_1.1.0.sch, ENERGIS_Rack-PDU_1.1.0_bom.csv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]
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2025-11-06 general update for the repo
    [DisplayBoard_Shielding.3mf, ENERGIS- Sheetmetal Enclosure-Bottom-Unfolded.step, ENERGIS- Sheetmetal Enclosure-Bottom.step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]
2025-11-09 Major update - RTOS migration
    [ENERGIS_DispBrd_Rack-PDU_1.1.0.brd, ENERGIS_DispBrd_Rack-PDU_1.1.0.sch, ENERGIS_DispBrd_Rack-PDU_1.1.0_bom.csv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]
2025-11-10 bugfix for RTOS tasks
    [CONFIG.h, socket.h]
2025-11-10 first fully functional bugfree??? build yeey
    [CONFIG.h, ethernet_config.h]
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2025-11-16 fix watchdog reset during EE dump
    [CAT24C256_driver.c, CONFIG.h]
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2025-11-17 Fiexed: EEPROM dump causes WDT reset: using pointer arithmetic instead of strncat Added: Power down mode now supported
    [CAT24C256_driver.c, CONFIG.h, MCP23017_driver.c]
2025-11-18 prepare for adding error logger
    [CONFIG.h]
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2025-11-25 major pre-release update on project files and documentation
    [Bottom-FlatPattern.dxf, Bottom_Engrave.dxf, ENERGIS - Bottom Sheetmetal Enclosure.step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]
2025-12-01 correct BOM
    [Bottom_Engrave.dxf, ENERGIS - Bottom Sheetmetal Enclosure.step, ENERGIS_Rack-PDU_1.1.0.brd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]
2025-12-10 clear documentation, software bugfix
    [ENERGIS_DispBrd_Rack-PDU_1.0.3.brd, ENERGIS_DispBrd_Rack-PDU_1.0.3.sch, ENERGIS_DispBrd_Rack-PDU_1.1.0.brd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]
2025-12-17 add documentation, implement provisioning
    [Bambulab_Enclosure-ABS.3mf, Bambulab_Enclosure.3mf, Enclosure.3mf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]
2026-01-01 code update and bugfix
    [CONFIG.h, MCP23017_driver.c, i2c_bus.c]
2026-01-02 add preset feature, add apply-on-startup feature, minor fixes
    [CONFIG.h]
2026-01-02 sleep mode bugfix: NIC not initialized after power down, when the network link is down
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2026-01-18 update readme, minor bugfix
    [CONFIG.h]
2026-07-04 Software: Add password protection, CE cert
    [Controller-Board_Rack-PDU_1.0.brd, Controller-Board_Rack-PDU_1.0.sch, Controller-Board_Rack-PDU_2.0.brd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]
2026-07-14 UI session timer bugfix

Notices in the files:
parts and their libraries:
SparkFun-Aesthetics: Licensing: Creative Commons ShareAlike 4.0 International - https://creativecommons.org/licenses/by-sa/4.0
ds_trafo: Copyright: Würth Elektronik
